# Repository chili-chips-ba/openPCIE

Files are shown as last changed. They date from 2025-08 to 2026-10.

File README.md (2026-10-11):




Computing is about communicating. Some would also say about networking. Digital independence tags along on the wave of _"Recommendations and Roadmap for European Sovereignty in open source HW, SW and RISC-V Technologies (2021)"_, calling for the development of critical open source IP blocks, such as **`PCIE Root Complex (RC)`**. This is the first step in that direction. And, if you are looking for an opensource, soft PCIE EndPoint (EP) core, please check our [other](https://github.com/chili-chips-ba/openCologne-PCIE) repo.

<p align="center" width="100%">
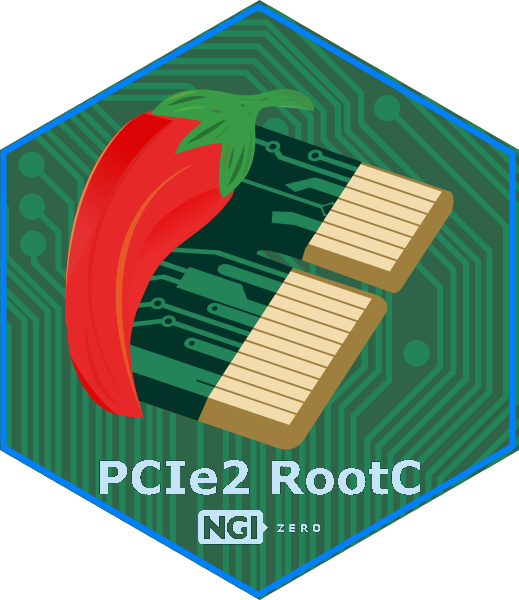
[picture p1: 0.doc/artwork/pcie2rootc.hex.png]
openPCIE Root Complex project logo
  
</p>

This project looks to open Artix7 PCIE Gen2 RC IP blocks for use outside of proprietary tool flows. While still reliant on Xilinx Series7 Hard Macros (HMs), it will surround them with open-source soft logic for PIO accesses — The **`RTL`** and, even more importantly, the layered **`software Driver with Demo App`**. 

All that with **`full HW/SW opensource co-sim`**. Augmented with a rock-solid **`openBackplane`** in the basement of our hardware solution, the geek community will thus get all it takes for building their own, end-to-end _openCompute_ systems.

> The project‘s immediate goal is to empower the makers with ability to drive PCIE-based peripherals from their own soft RISC-V SOCs.

Given that the PCIE End-Point (EP) with DMA is already available in opensource, the opensource PCIE peripherals do exist for Artix7. Except that they are always, without exception, controlled by the proprietary RC on the motherboard side, typically in the form of RaspberryPi ASIC, or x86 PC. This project intends to change that status quo.

Our long-term goal is to set the stage for the development of full opensource PCIE stack, gradually phasing out Xilinx HMs from the solution. That’s a long, ambitious track, esp. when it comes to mixed-signal SerDes and high-quality PLLs. We therefore anticipate a series of follow on projects that would build on the foundations we hereby set.

This first phase is about implementing an open source PCIE Root Complex (RC) for Artix7 FPGA, utilizing Xilinx Series7 PCIE HM and GTP IP blocks, along with their low-jitter PLL.

#### References
- [PCIE Primer](http://www.anita-simulators.org.uk/wyvernsemi/articles/pci_express.pdf) by Simon Southwell ✔

--------------------

# Project Status

#### `PART 1. Mini PCIE Backplane PCB`

Almost all consumer PCIE installations have the RC chip soldered down on the motherboard, typically embodied in the CPU or "North Bridge" ASIC, where PCIE connectors are used solely for the EP cards. Similarly, all FPGA boards on the market are designed for EP applications. As such, they expect clock, reset and a few other signals from the infrastructure. It is only the professional and military-grade electronics that may have both RC and EP functions on add-on cards, with a backplane or mid-plane connecting them (see VPX chassis, or VITA 46.4).

This dev activity is about creating the minimal PCIE infrastructure necessary for using a plethora of ready-made FPGA EP cards as a Root Complex. This infrastructure takes the physical form of a mini backplane that provides the necessary PCIE context similarly to what a typical motherboard would give, but without a soldered-down RC chip that would be conflicting with our own FPGA RC node.

Such approach is less work and less risk than to design our own PCIE motherboard, with a large FPGA on it. But, it is also a task that we did not appreciate from the get-go. In a bit of a surprise, half-way through planning, we've realized that a suitable, ready-made backplane was not available on the market. This initial disappointment then turned into excitement knowing that this new outcome would make the project even more attractive / more valuable for the community... esp. when **[Envox.eu](https://www.envox.eu)** has agreed to step in and help. They will take on the PCIE backplane PCB development activity.

 - [x] ✔ Create requirements document.
 - [x] ✔ Select components. Schematic and PCB layout design.
 - [x] ✔ Review and iterate design to ensure robust operation at 5 GT/s (PCIE Gen2), using openEMS for simulation of high-speed traces.
 - [x] ✔ Manufacture prototype. Debug and bringup, using AMD-proprietary on-chip IBERT IP core to assess Signal Integrity.
 - [x] ✔ Produce second batch that includes all improvements. Distribute it, and release design files with full documentation.

#### `PART 2. Project setup and preparatory activities`
 - [x] ✔ Procure FPGA development boards and PCIE accessories.
 - [x] ✔ Put together a prototype system. Bring it up using proprietary RTL IP, proprietary SW Driver, TestApp and Vivado toolchain.
 
#### `PART 3. Initial HW/SW implementation`
 - [x] ✔ HW development of opensource RTL that mimics the functionality of PCIE RC proprietary solution.
 - [x] ✔ SW development of opensource driver for the PCIE RC HW function. It runs bare-metal on the RISC-V SOC, without Linux - see [SW Architecture](#sw-architecture).
 - [x] ✔ Design SOC based on RISC-V CPU with PCIE RC as its main peripheral.

#### `PART 4. HW/SW co-simulation using full PCIE EP model`

This dev activity is significantly beefed up compared to our original plan, which was to use a much simpler PCIE EP BFM, and non-SOC sim framework. While that would have reduced the time and effort spent on the sim, prompted by NLnet astute questions, we're happy to announce that **[wyvernSemi](https://github.com/wyvernSemi/pcievhost)** is now also onboard!

Their VProc can be used not only to faithfully model the RISC-V CPU and SW interactions with HW, but it also comes with an implementation of the PCIE model. The PCIE model has some EP capabilities with a configurable configuration space, which can be paired in sim with our RC RTL design. Moreover, the existence of both RC and EP models paves the way for future plug-and-play, pick-and-choose opensource sims of the entire PCIE subsystem.

With the full end-to-end simulation thus in place, we hope that the need for hardware debugging, using ChipScope, expensive test equipment and PCIE protocol analyzers would be alleviated.

 - [x] ✔ Extension of the existing PCIE RC model for some additional configurability of the EP capabilities.
 - [x] ✔ Testbench development and build up. Execution and debug of sim testcases.
 - [x] ✔ Documentation of EP model, TB and sim environment, with objectives to make it all simple enough to pickup, adapt and deploy in other projects.
 
#### `PART 5. Integration, testing and iterative design refinements`
 - [x] ✔ One-by-one replace proprietary design elements of the PART 2 prototype system with our opensource versions (except for Vivado and TestApp). Test it along the way, fixing problems as they occur.
 
#### `PART 6. Prepare Demo and port it to openXC7`

 - [x] ✔ Develop our opensource PIO TestApp software and representative Demo.
 - [x] ✔ Build design with _openXC7_, reporting issues and working with developers to fix them, possibly also trying _ScalePNR_ flow.

Given that PCIE is an advanced, high-speed design, in the light of _nextpnr-xilinx_ and openXC7 shortcomings when it comes to timing constraints and timing closure, we expect to run into showstoppers, and have therefore planned to experiment with WIP _ScalePNR_. In turned out that, with some corrections, the _nextpnr-xilinx_ was good enough -- The bitstream built with it brings the link up at **Gen2** speeds on hardware, the same as Vivado does. Getting there took six fixes - one latent bug in our RTL and five workarounds for openXC7 defects - all documented in [4.build/hw_build.openXC7](4.build/hw_build.openXC7/README.md), along with the issues we filed against openXC7.

The design has also been ported to, and tested with [_openXC7_ 1.0.0 edition](https://lnkd.in/p/gsDArjSt), which was a major step forward and essentially what "ScalePNR" idea eventually had evolved into. It brought to the forefront Yosys0.69 with integrated **Slang, nextpnr-himbaechel** (instead of _nextpnr-xilinx_) and _fpga-as_. With that, the earlier SV2V standalone preparatory step for our SystemVerilog design sources proved to be unnecessary, which greatly simplifies the build.

--------------------

# HW Architecture

The project relies on a modular hardware ecosystem that combines our custom-designed openPCIE Backplane with SQRL Acorn CLE-215+ FPGA modules and various PCIE adapters to create a flexible testing platform.

<p align="center">
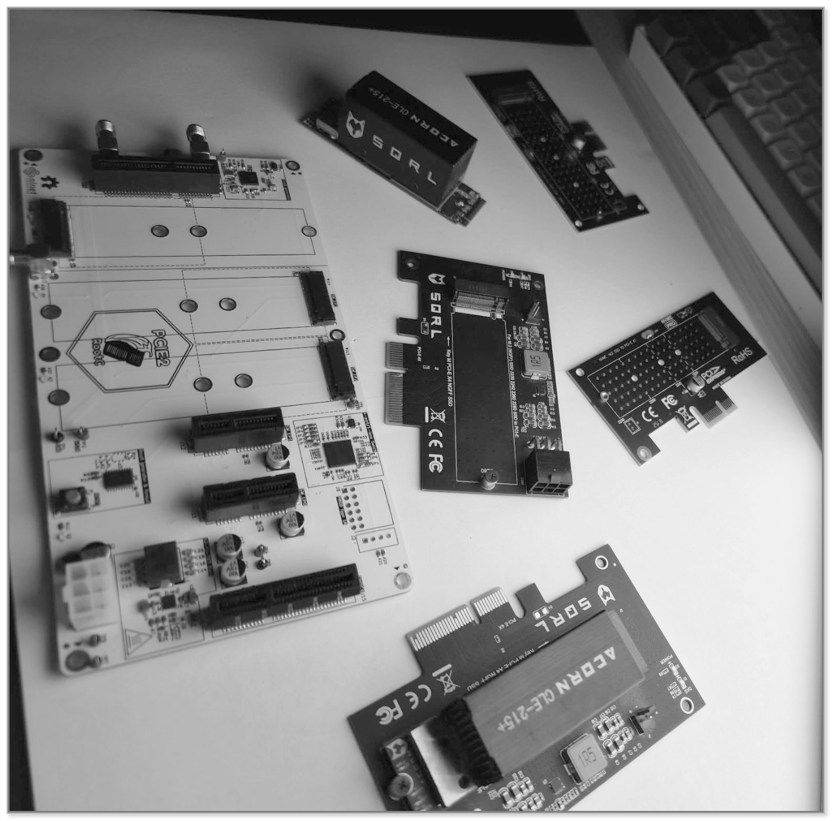
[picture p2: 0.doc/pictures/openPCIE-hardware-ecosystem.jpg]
openPCIE hardware ecosystem
 
</p>

#### References:
- [Basic PCIE EP for LiteFury](https://github.com/hdlguy/litefury_pcie)
- [Regymm PCIE](https://github.com/regymm/pcie_7x)
- [LiteX PCIE EP](https://github.com/enjoy-digital/litepcie)
- [PCIE EP DMA - Wupper](https://gitlab.nikhef.nl/franss/wupper)
- [Xilinx UG477 - 7Series Integrated Block PCIe](https://docs.xilinx.com/v/u/en-US/ug477_7Series_IntBlock_PCIe)
- [Xilinx DS821 - 7series_PCIE Datasheet](https://docs.xilinx.com/v/u/en-US/ds821_7series_pcie)
- [Xapp1052 - BusMaster DMA for EP](https://docs.xilinx.com/v/u/en-US/xapp1052)

## FPGA hardware platform

#### References:
- [Acorn-CLE215+ QuickStart](https://github.com/SMB784/SQRL_quickstart)
- [NiteFury](https://github.com/RHSResearchLLC/NiteFury-and-LiteFury/tree/master)
- [fpgas.online-test-designs](https://github.com/fpgas-online/fpgas.online-test-designs/tree/main/designs/pcie-enumeration) PCIE ENUMERATION by RPI, for Acorn-CLE215+ EP
  
The hardware platform for this project is the **SQRL Acorn CLE-215+**, a versatile FPGA development board. Although originally designed as a crypto-accelerator, its powerful Artix-7 FPGA and modular design make it an excellent choice for general-purpose PCIE development.

The system consists of two main components:

*  **M.2 FPGA Module (Acorn CLE-215+):** This is the core of the system, a compact board in an M.2 form factor. It houses the **Xilinx Artix-7 XC7A200T FPGA** and is designed to be plugged into a standard M.2 M-key slot.

<table align="center" style="border: none; border-collapse: collapse;">
  <tr style="border: none;">
    <td align="center" style="border: none;">
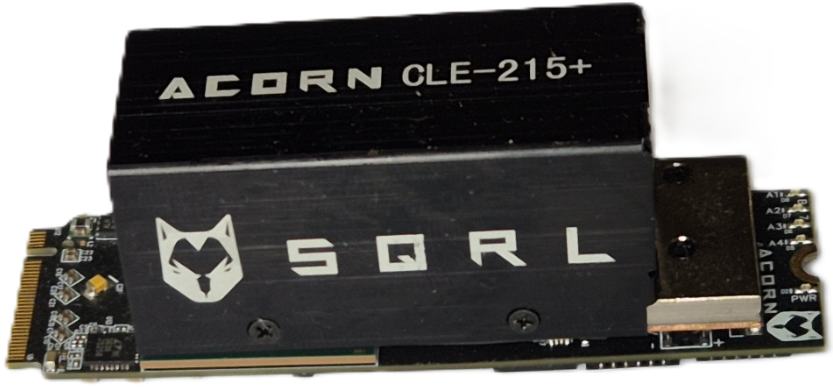
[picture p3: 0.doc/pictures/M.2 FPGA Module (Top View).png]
M.2 FPGA module, top view
      
    </td>
    <td align="center" style="border: none;">
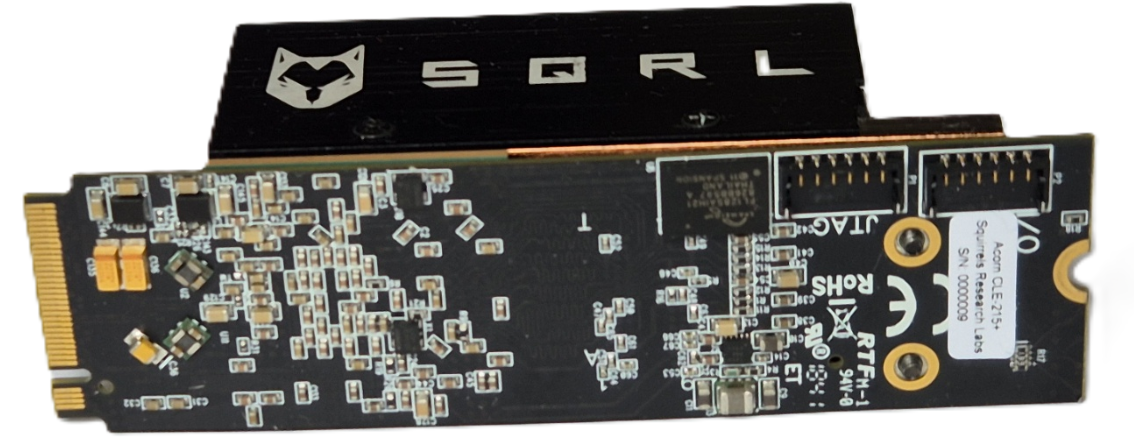
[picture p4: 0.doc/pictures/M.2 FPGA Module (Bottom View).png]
M.2 FPGA module, bottom view
      
    </td>
  </tr>
  <tr style="border: none;">
    <td align="center" style="border: none;"><b>M.2 FPGA Module (Top View)</b></td>
    <td align="center" style="border: none;"><b>M.2 FPGA Module (Bottom View)</b></td>
  </tr>
</table>

*  **PCIE Adapter Board (Acorn Baseboard Mini):** A carrier board that holds the M.2 FPGA module. Its primary function is to adapt the M.2 interface to a standard **PCIE x4 edge connector**, allowing the entire assembly to be installed and tested in a regular PC motherboard slot.

<table align="center" style="border: none; border-collapse: collapse;">
  <tr style="border: none;">
    <td align="center" style="border: none;">
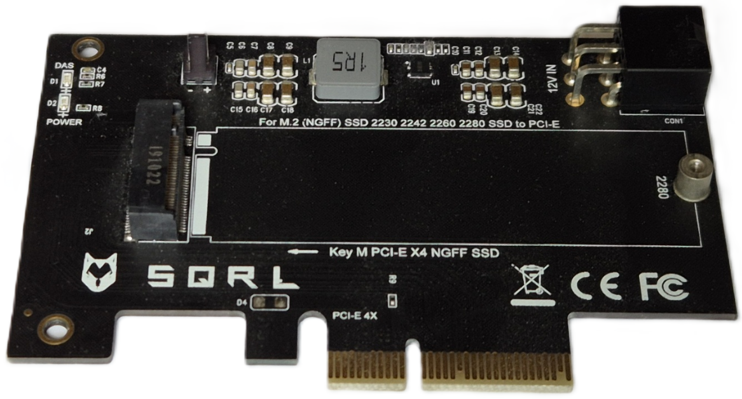
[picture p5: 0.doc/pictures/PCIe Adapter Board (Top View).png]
PCIE adapter board, top view
      
    </td>
    <td align="center" style="border: none;">
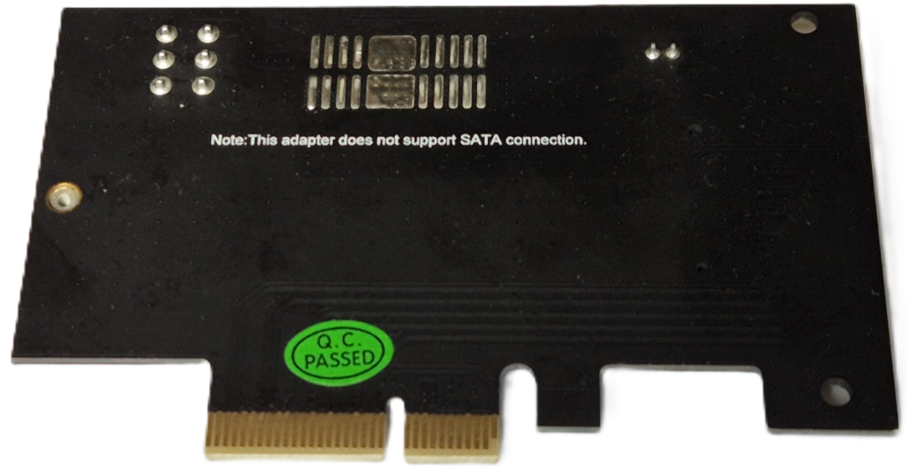
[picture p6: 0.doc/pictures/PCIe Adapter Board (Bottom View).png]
PCIE adapter board, bottom view
      
    </td>
  </tr>
  <tr style="border: none;">
    <td align="center" style="border: none;"><b>PCIE Adapter Board (Top View)</b></td>
    <td align="center" style="border: none;"><b>PCIE Adapter Board (Bottom View)</b></td>
  </tr>
</table>

<p align="center">
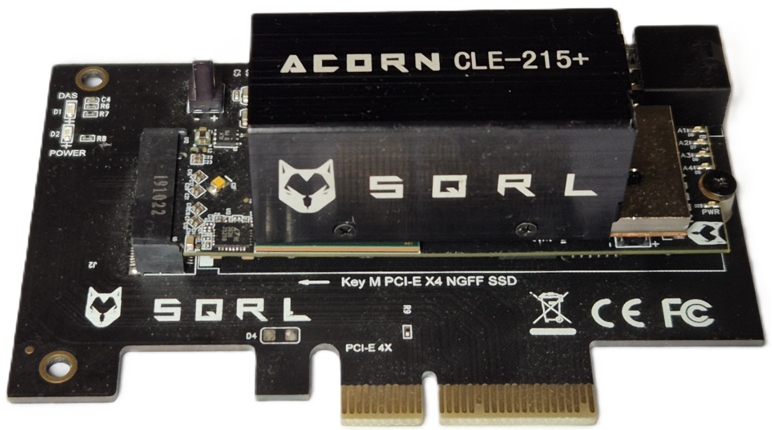
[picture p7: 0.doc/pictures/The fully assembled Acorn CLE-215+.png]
Fully assembled Acorn CLE-215+
  
  <br>
  <b>The fully assembled Acorn CLE-215+ development board, ready for use in a PCIE slot.</b>
</p>

It is important to note that the Acorn CLE-215+ is functionally identical to the more widely known NiteFury board, with the primary difference being the amount of onboard memory. The Acorn model features 1 GB of DDR3 RAM, while the standard NiteFury has 512 MB. Therefore, the [NiteFury schematic](https://github.com/chili-chips-ba/openPCIE/blob/main/0.doc/Reference-SCH/Schematic.FPGA-NiteFury.pdf) serves as a direct and accurate reference for the board's hardware layout.

The central component of the SQRL Acorn CLE-215+ system is the **Xilinx Artix-7 XC7A200T-FBG484** chip. This FPGA is crucial for implementing the PCIE Root Complex - and, on the other card, the Endpoint - possessing a range of features that make it highly suitable for this purpose.

The key specifications are summarized below:

<div align="center">
<table>
<thead>
<tr>
<th>Specification</th>
<th>Value</th>
</tr>
</thead>
<tbody>
<tr>
<td>Family</td>
<td>Xilinx Artix-7</td>
</tr>
<tr>
<td>Speed Grade</td>
<td>-3</td>
</tr>
<tr>
<td>Logic Cells (LUT4-Equivalent)¹</td>
<td>215,360</td>
</tr>
<tr>
<td>LUT6</td>
<td>134,600</td>
</tr>
<tr>
<td>Flip-Flops</td>
<td>269,200</td>
</tr>
<tr>
<td>Block RAM</td>
<td>13 Mbit</td>
</tr>
<tr>
<td>DSP Slices</td>
<td>740</td>
</tr>
<tr>
<td>GTP Transceivers</td>
<td>4 (up to 6.6 Gbit/s)</td>
</tr>
<tr>
<td>DDR3 SDRAM (Board)</td>
<td>1 GB, 16-bit</td>
</tr>
<tr>
<td>QSPI Flash (Board)</td>
<td>32 MB</td>
</tr>
<tr>
<td>User LEDs</td>
<td>4</td>
</tr>
<tr>
<td>General Purpose IOs</td>
<td>4</td>
</tr>
<tr>
<td>LVDS Pairs</td>
<td>4</td>
</tr>
</tbody>
</table>
<p><small>¹ The 'Logic Cells' count is a Xilinx metric derived from the physical 6-input LUTs to provide an estimated equivalent in simpler 4-input LUTs for comparison purposes. The number of physical LUTs and other resources are the exact counts for the XC7A200T chip.</small></p>
</div>

### FPGA Board Setup

Properly programming and operating the Artix-7 FPGA on the SQRL board required two key hardware modifications.

#### 1. Custom JTAG Cable

The JTAG connector on the Acorn CLE-215+ is non-standard and not directly compatible with the standard 14-pin connector on the Xilinx Platform Cable. A custom adapter cable is therefore required.

<table align="center" style="border: none; border-collapse: collapse; width="60%">
  <tr style="border: none;">
    <td align="center" style="border: none;" width="60%">
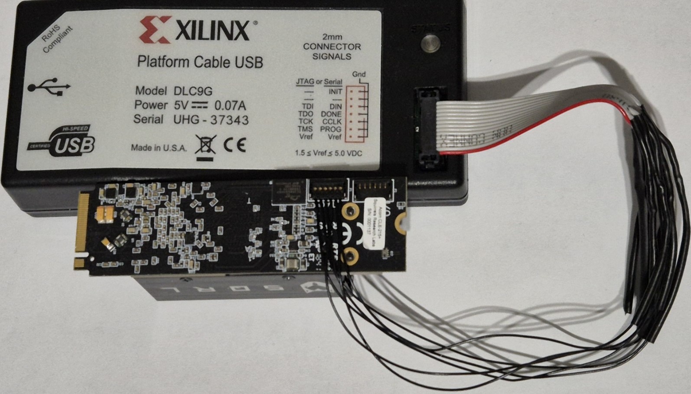
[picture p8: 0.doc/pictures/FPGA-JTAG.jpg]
FPGA JTAG connection
      
    </td>
    <td align="center" style="border: none;" width="30%">
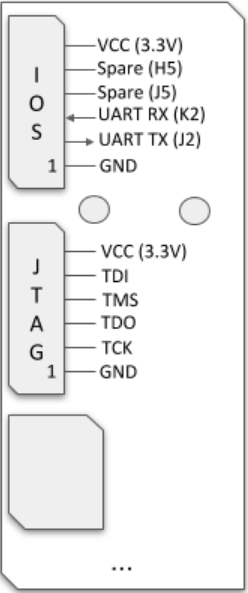
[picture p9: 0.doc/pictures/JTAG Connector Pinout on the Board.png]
JTAG connector pinout on the board
      
    </td>
  </tr>
  <tr style="border: none;">
    <td align="center" style="border: none;"><b>Custom JTAG Cable connecting the Xilinx Programmer to the board</b></td>
    <td align="center" style="border: none;"><b>JTAG Connector Pinout on the Board</b></td>
  </tr>
</table>

The connector on the board is a **Molex Pico-Lock 1.50mm pitch male header**. This is not a standard 2.54mm or 2.00mm header, so standard DuPont-style cables will not fit.

To simplify making the cable, we highly recommend purchasing a pre-assembled cable with the correct female connector.

*   **Recommended Part:** **[Molex 0369200603 on Digi-Key](https://www.digikey.com/en/products/detail/molex/0369200603/10233020)**

This cable has the correct female connector on both ends. The easiest method is to **cut the cable in half**, which gives you two connector cables with open ends. You can then splice one of these cable ends onto the wires of your Xilinx programmer cable, matching the signals according to the following wiring diagram.

<p align="center">
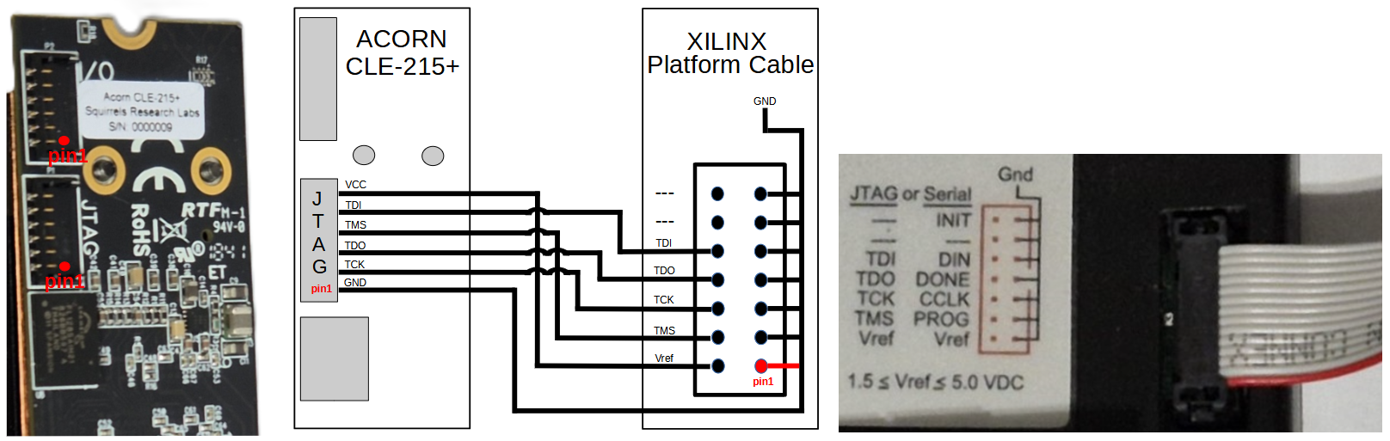
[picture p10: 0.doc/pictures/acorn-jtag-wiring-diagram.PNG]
Acorn JTAG wiring diagram
  
  <br><em>JTAG Connection Guide: Physical Pinout and Wiring Diagram.</em>
</p>

#### 2. External 12V Power Supply

The board cannot be programmed or operated solely from the PCIE/M.2 slot power. It requires an external 12V supply to function correctly, especially when complex designs and high-speed transceivers are active. Power is provided via a standard 6-pin PCIE power connector from an ATX power supply.

<p align="center">
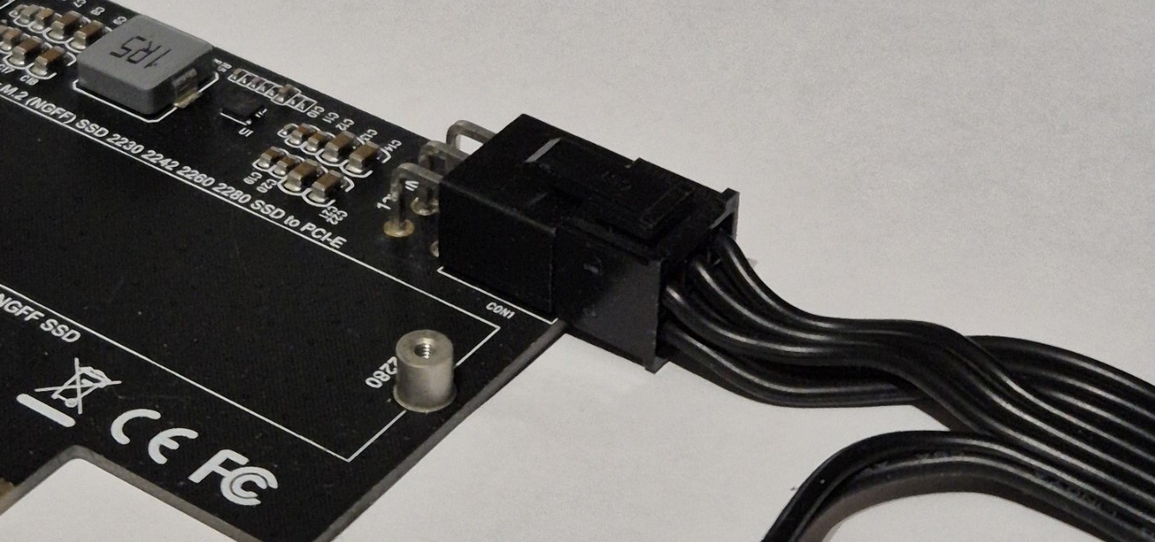
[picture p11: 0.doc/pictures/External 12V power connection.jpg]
External 12 V power connection
  
  <br><em>External 12V power connection.</em>
</p>

#### 3. Final Assembly

The complete system, including the custom cabling, is mounted in a test PC chassis for verification.

<p align="center">
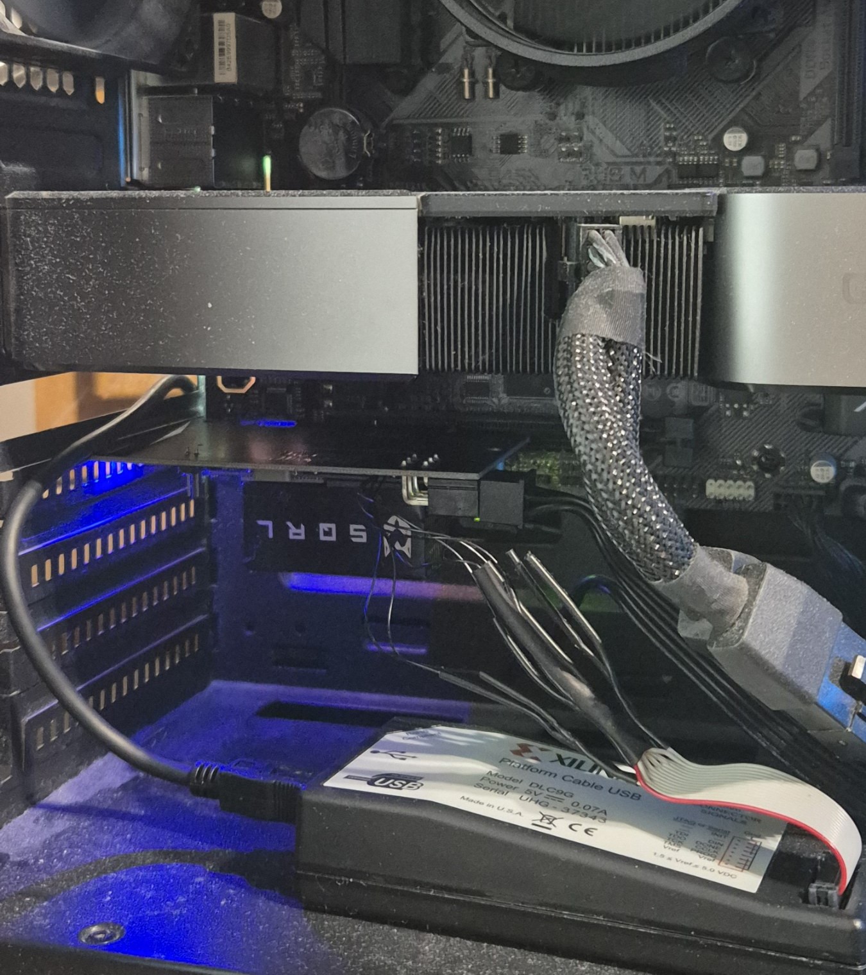
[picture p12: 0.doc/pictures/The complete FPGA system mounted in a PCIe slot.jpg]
Complete FPGA system mounted in a PCIE slot
  
  <br><em>The complete FPGA system mounted in a PCIE slot.</em>
</p>

#### 4. Connection Verification

After the hardware was prepared, the connection was verified using the **Vivado Hardware Manager**. As shown below, the tool successfully detected the JTAG programmer and identified the `xc7a200t_0` FPGA chip. This confirms that the physical connections are correct and the board is ready for programming.

<p align="center">
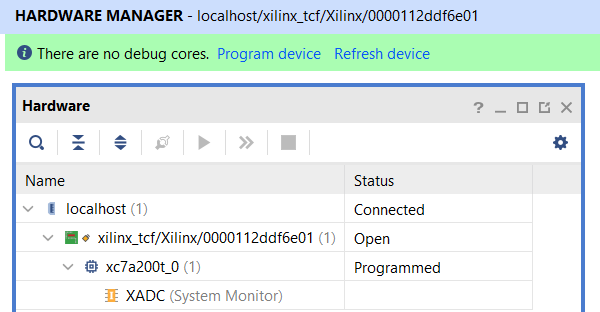
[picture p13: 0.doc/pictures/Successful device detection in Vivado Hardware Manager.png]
Successful device detection in Vivado Hardware Manager
  
  <br><em>Successful device detection in Vivado Hardware Manager.</em>
</p>

--------------------
### openBackplane PCB

<p align="center" width="100%">
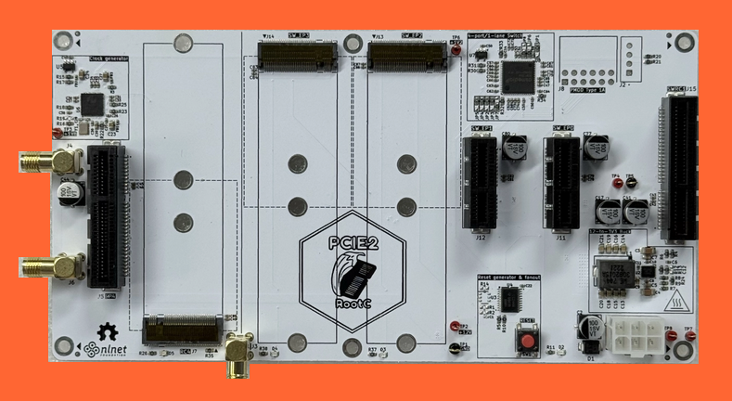
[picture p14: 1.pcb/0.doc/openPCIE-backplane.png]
openPCIE backplane
    
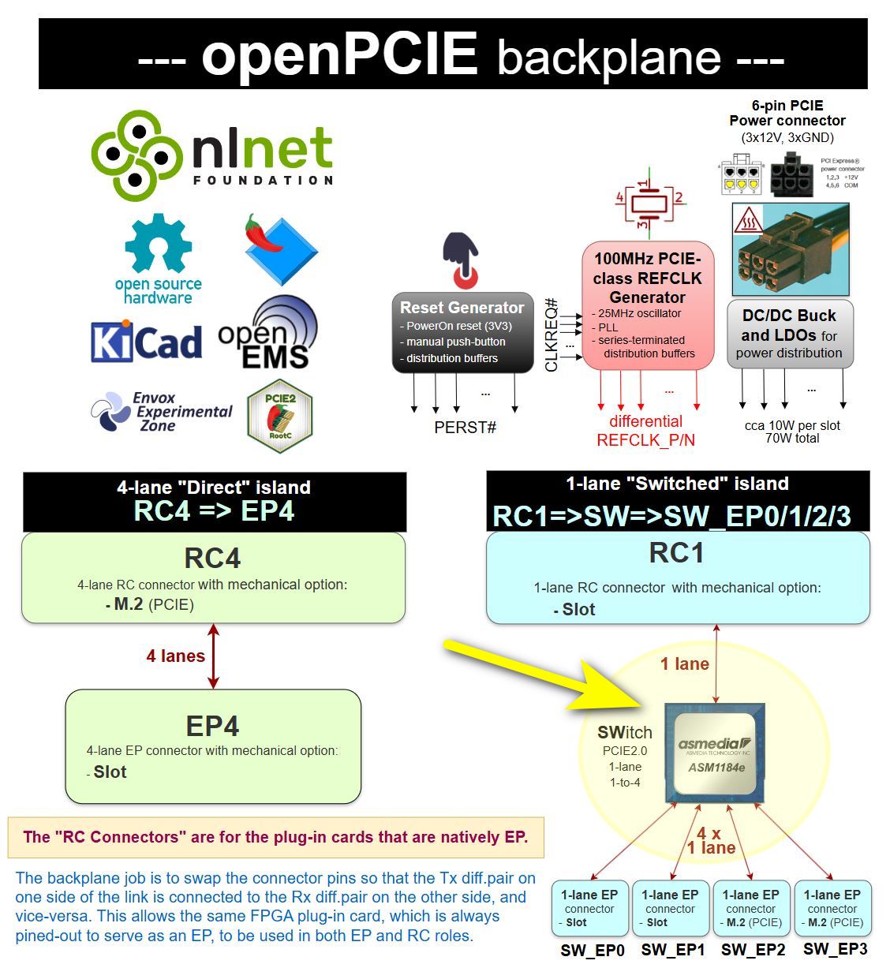
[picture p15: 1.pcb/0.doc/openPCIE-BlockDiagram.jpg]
openPCIE backplane block diagram
    
</p>

Please, refer to [1.pcb](1.pcb) for additional detail.

--------------------

# TB/Sim Architecture

## Simulation Test Bench

The [openPCIE test bench](5.sim/README.md) aims to have a flexible approach to simulation which allows a common test environment to be used whilst selecting between alternative CPU components, one of which uses the [_VProc_ virtual processor](https://github.com/wyvernSemi/vproc) co-simulation element. This allows simulations to be fully HDL, with the picorv32 RISC-V RTL core that goes into the bitstream, or to co-simulate software using the virtual processor, with a significant speed up in simulation times. The test bench has the following features:

* A [_VProc_](https://github.com/wyvernSemi/vproc) virtual processor based [`soc_cpu.VPROC.picorv32`](5.sim/models/README.md#soc_cpuvprocpicorv32) component
  * [Selectable](5.sim/README.md#the-three-cpu-options) between this or the RTL picorv32, with `make CPU=rtl|vproc|iss`
  * Can run natively compiled test code
  * Can run the application compiled natively with the [auto-generated co-sim HAL](4.build/README.md#csr-hal-compilation)
  * Can run RISC-V compiled code using the [rv32 RISC-V ISS model](5.sim/models/rv32/README.md)
  * All three have been [built and measured](5.sim/README.md#what-they-cost); each reaches the same result over the same PCIE link
* The [_pcieVHost VIP_](https://github.com/wyvernSemi/pcievhost) is used to drive the logic's PCIE link
* Uses a C [sparse memory model](https://github.com/wyvernSemi/mem_model)
  * An [HDL component](5.sim/models/cosim/README.md) instantiated in logic gives logic access to this memory
  * An API is provided to _VProc_ running code for direct access from the _pcieVHost_ software, which implements this sparse memory C model.

The figure below shows an overview block diagram of the test bench HDL.

<p align="center">
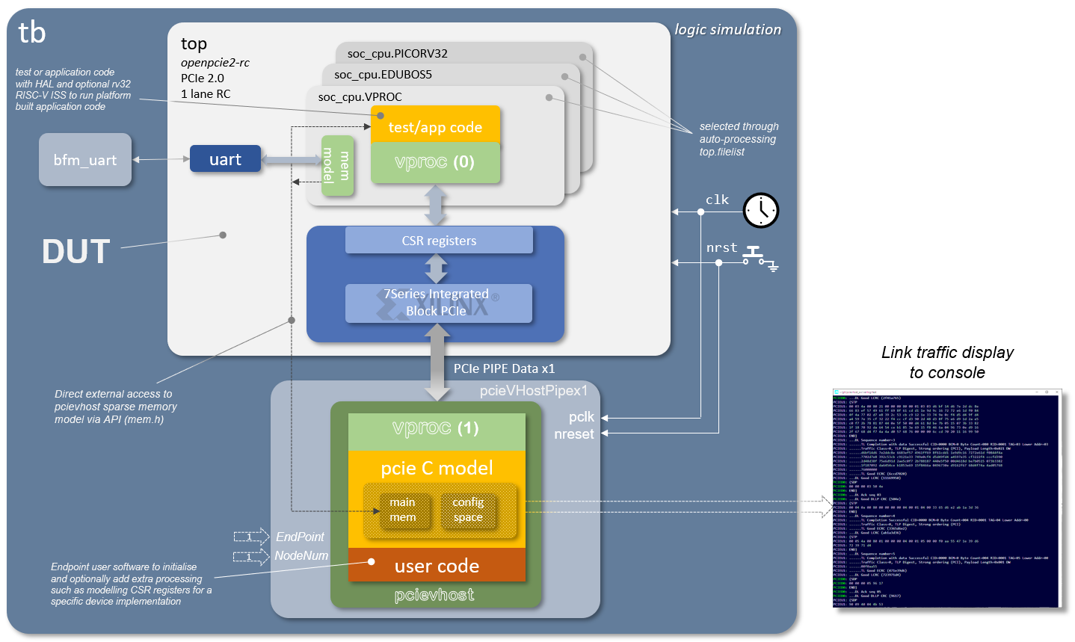
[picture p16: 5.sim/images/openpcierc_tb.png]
openPCIE Root Complex test bench structure

</p>

More details on the architecture and usage of the openPCIE test bench can be found in the [README.md](5.sim/README.md) in the `5.sim` directory.

The co-simulation can also be followed at TLP level in the [WaveCrux](https://wavecrux.app) waveform viewer, with an [open-source PCIE TLP decoder plugin](5.sim/tools/wavecrux-pcie-tlp/README.md) and a ready-made session -- here the firmware sizing BAR0 by readback and placing it at `0x80000000` ([more](5.sim/README.md#viewing-the-tlps-in-wavecrux)):

<p align="center">
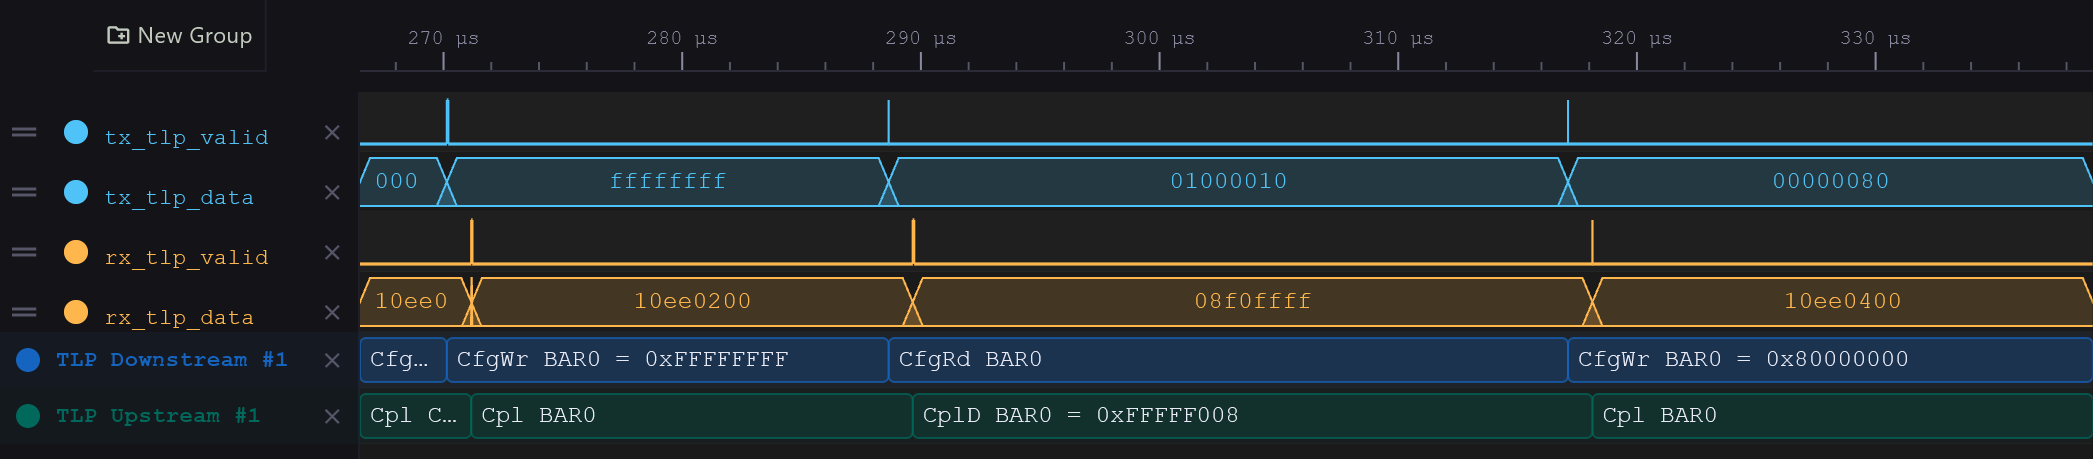
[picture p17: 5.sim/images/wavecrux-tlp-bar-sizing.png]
WaveCrux TLP view: firmware sizing BAR0

</p>

One level down, Ferrite's [PCIe PIPE and Data Link Layer decoders](https://github.com/Ferrite-Engineering/wavecrux-decoders) show the same link on the wire: link training, flow-control credits, and every TLP with its sequence number and Ack ([more](5.sim/README.md#viewing-the-pipe-in-wavecrux)). With all three layers in one view, you can also see how long a TLP spends inside the hard macro: about 0.4 µs each way ([more](5.sim/README.md#how-long-a-tlp-spends-in-the-hard-macro)).

## Co-simulation HAL

The openPCIE control and status register hardware abstraction layer (HAL) software is [auto-generated](4.build/README.md#csr-hal-compilation), as is the CSR RTL, using [`peakrdl`](https://peakrdl-cheader.readthedocs.io/en/latest/). A single SystemRDL specification, [`4.build/csr_build/csr.rdl`](4.build/csr_build/csr.rdl), describes the TLP transmit/receive window the RISC-V firmware drives, and everything else is derived from it: the register block RTL (`csr.sv`, `csr_pkg.sv`), which [`soc_csr.sv`](2.rtl/0.common.opensource/src/soc_csr.sv) bridges to the picorv32 memory bus, and the software header. For co-simulation purposes an additional layer is auto-generated from the same SystemRDL specification using [`systemrdl-compiler`](https://systemrdl-compiler.readthedocs.io/en/stable/) that accompanies the `peakrdl` tools. This produces two header files that define a common API to the application layer for both the RISC-V platform and the *VProc* based co-simulation verification environment. The details of the HAL generation can be found in the [README.md](./4.build/README.md#csr-hal-compilation) in the `4.build/` directory.

The hand-written register block that came first is kept alongside it, behind `` `ifdef SOC_CSR_LEGACY `` in `riscv_pcie_soc.sv`, and every build flow can pick either one. The two describe the same map down to the byte offset.

More details of the test bench, the _pcievhost_ component and its usage can be found in the [5.sim/README.md](5.sim/README.md) file.
  
#### References
- [pcieVHost](https://github.com/wyvernSemi/pcievhost/blob/master/doc/pcieVHost.pdf)
- [WaveCrux](https://wavecrux.app) waveform viewer, [decoder plugin interface](https://github.com/Ferrite-Engineering/wavecrux/blob/main/include/wavecrux_decoder.h)
- [wavecrux-decoders](https://github.com/Ferrite-Engineering/wavecrux-decoders): Ferrite's open-source PCIE PIPE and Data Link Layer decoders for WaveCrux

--------------------

# SW Architecture

The software stack is designed to run **bare-metal** on the soft RISC-V SoC embedded within the FPGA. In a standard PC, the Operating System (Linux/Windows) manages PCIE enumeration automatically in the background, hiding the complexity from the developer. In this project, our **open-source driver** takes full control, manually performing every step of the enumeration process to act as the PCIE Host.

The architecture follows a layered approach:

1.  **Application Layer (The "User" Logic)**: 
    - The final stage of the program that executes the high-level task.
    - It performs **Memory Write** operations to send a data payload to the Endpoint and uses **Memory Read** to verify the integrity of the data path.

2.  **PCIE Driver (Enumeration & Setup)**:
    - Responsible for the **initialization sequence** required to perform enumeration and establish a functional connection (link).
    - It manually performs device discovery, sizes the BARs by readback, assigns aligned memory addresses, checks the completion status of every request, and configures the **Command Register** to enable the device for communication.
      
3.  **HAL (Hardware Abstraction Layer)**:
    - Low-level helper functions that interact with the hardware by reading and writing data to **specific memory addresses**.

> **Note:** This structure allows developers to treat PCIE devices just like any other local peripheral, abstracting away the complexities of the physical link.

--------------------

# Implementation Workflow

The openPCIE implementation workflow is organized into several stages, covering the complete process from setting up the development environment to verifying the design on physical hardware.

## Prerequisites

Before building the project, install and configure the required development tools. These include an FPGA toolchain such as **AMD Vivado** or **openXC7**, a bare-metal **RISC-V cross-compilation toolchain**, Python, and the project-specific dependencies listed in the corresponding directories.

## Simulation (Hardware/Software Co-Simulation)

Before deploying the design to physical hardware, run the available simulation environment to verify the interaction between the PCIE hardware design and the software components.

The co-simulation flow is used to test essential operations such as device initialization, register access, PCIE link behavior, and data exchange between the Root Complex (RC) and Endpoint (EP). This stage helps identify hardware and software integration issues before synthesis and hardware deployment.

## Software Build

Compile the bare-metal RISC-V driver and test application using the configured cross-compilation toolchain.

The software is responsible for initializing the required hardware components, configuring the PCIE communication flow, and transferring test payloads between the RC and EP. The generated executable can be used during simulation or deployed together with the FPGA design for hardware verification.

## Hardware Synthesis and Bitstream Generation

The FPGA design can be synthesized and implemented using either the commercial **AMD Vivado** toolchain or the open-source **openXC7** toolchain. Depending on the selected flow, the process includes design elaboration, synthesis, placement, routing, timing analysis, and final bitstream generation.

The resulting `.bit` file contains the complete hardware configuration for the selected FPGA board. The appropriate board-specific constraints, build configuration, and target design must be selected depending on whether the board operates as the Root Complex (RC) or Endpoint (EP).

Detailed build instructions for both the Vivado and openXC7 flows are provided in the corresponding project directories.

## Flashing and Deployment

Program the RC and EP FPGA boards with their corresponding bitstreams. After both designs have been loaded, start the software application and allow the boards to initialize the PCIE connection.

The deployed system can then be verified by checking the PCIE link-status indicators and comparing the transmitted payload with the data displayed or received on the Endpoint.

Detailed commands, configuration options, supported boards, and stage-specific instructions are provided in the corresponding project directories.

--------------------

# Debug, Bringup, Testing

### Hardware Infrastructure
- **PCB:** **openPCIE Backplane** (see [1.pcb](1.pcb/))  which provides slots for the RC, EP, and the Switch.
- **FPGA Boards:** Two **SQRL Acorn CLE-215+** (Artix-7) boards.
- **JTAG Programmers:** Two **Xilinx Platform Cable USB** units are used, each equipped with a **custom adapter cable**.
    
### The "Dual-PC" Debugging Approach 
We used a **two-PC** setup to streamline development:
-  **PC 1:** Connected to the **Root Complex (RC)** FPGA via JTAG.
-  **PC 2:** Connected to the **EndPoint (EP)** FPGA via JTAG.
   
**Why this setup?**
- **Speed and Efficiency:** This setup avoids the repetitive task of manually swapping the JTAG cable between boards and eliminates the time-consuming process of flashing onboard memory for every test iteration.
- **Simultaneous Debugging:** This allows us to run two instances of **Vivado Hardware Manager** (ILA - Integrated Logic Analyzer) at the same time. We can trigger on the RC and EP simultaneously to view the transaction from both sides of the link.

### Testing Procedure

To bring up the system and verify the PCIE link, follow these steps:

*   **Hardware Assembly:** Insert the FPGA cards into their designated slots on the **openPCIE Backplane** (RC and EP) and connect the external **12V power supply**.
*   **Bitstream Programming:** Program both FPGAs using Vivado Hardware Manager. **PC 1** is used to program the Root Complex, while **PC 2** programs the EndPoint.
*   **Manual Reset:** Once both devices are programmed, press the **manual reset button** on the backplane.
*   **Enumeration:** Upon releasing the reset button, the Root Complex initiates the **enumeration process** and establishes the link with the EndPoint.
*   **Re-Initialization:** Every subsequent press of the reset button triggers a full re-initialization of the PCIE connection, allowing for repeated testing and debugging without the need to re-program the FPGAs.

### Objective
The goal of this test is to verify that the Root Complex can successfully enumerate the link and perform both **Memory Write** and **Memory Read** transactions.
1. **Write:** The RC sends a data payload to the EP.
2. **Transfer:** The EP receives the TLP and writes it into its internal Block RAM (BRAM).
3. **Read:** The RC requests to read the data back from the EP memory.

---

# Functional Verification: 

### Verification Environment

Before diving into the results, here is the complete hardware validation setup used for the Direct (Point-to-Point) connection scenario. It features the **openPCIE Backplane** powered by an external 12V supply, populated with two **Acorn CLE-215+** FPGA modules (one configured as RC, the other as EP).

Dual **Xilinx Platform Cable USB** units are connected via custom adapters to allow simultaneous debugging and bitstream loading from two separate host workstations.

<p align="center">
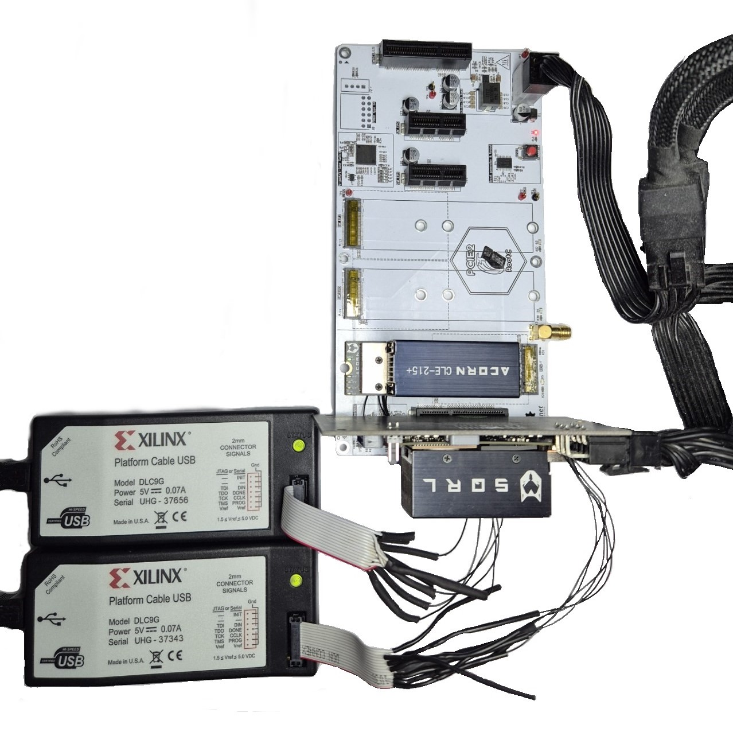
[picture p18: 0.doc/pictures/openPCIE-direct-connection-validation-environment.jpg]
Validation environment for the direct connection
  
  <br>
  <em>The complete hardware validation environment for the Direct connection test.</em>
</p>

### Verification Methods

**1. Visual Verification (LEDs)**
Visual feedback is provided via the **4 user LEDs** on both FPGA boards:
- **RC Board:** The LEDs indicate the **Link Status**, confirming that the physical connection is established and the devices are ready to communicate.
- **EP Board:** The LEDs display the data received by the EP.

**2. Internal Signal Monitoring (ILA)**
Using the Vivado Integrated Logic Analyzer (ILA) on both PCs enables detailed monitoring of internal signals to see exactly what data was sent and received, its precise timing, and the low-level transaction details.

### Verification Results

The implementation was verified on physical hardware by checking both PCIE link establishment and successful payload transfer between the Root Complex (RC) and Endpoint (EP).

On the RC board, LED **A3** indicates the PCIE link status. When this LED is illuminated, the PCIE link has been successfully established. As shown in the verification setup, LED A3 is active, confirming that the link between the RC and EP is up.

On the EP board, the LEDs display the received data payload. The RC transmitted the decimal value **6**, represented in binary as **`0110`**. The LED pattern on the EP matches this value, confirming that the payload was transferred and received correctly.

These results confirm that PCIE link initialization and RC-to-EP data transfer operate successfully on physical hardware.

<table align="center" style="border: none; border-collapse: collapse;">
  <tr style="border: none;">
    <td align="center" style="border: none;">
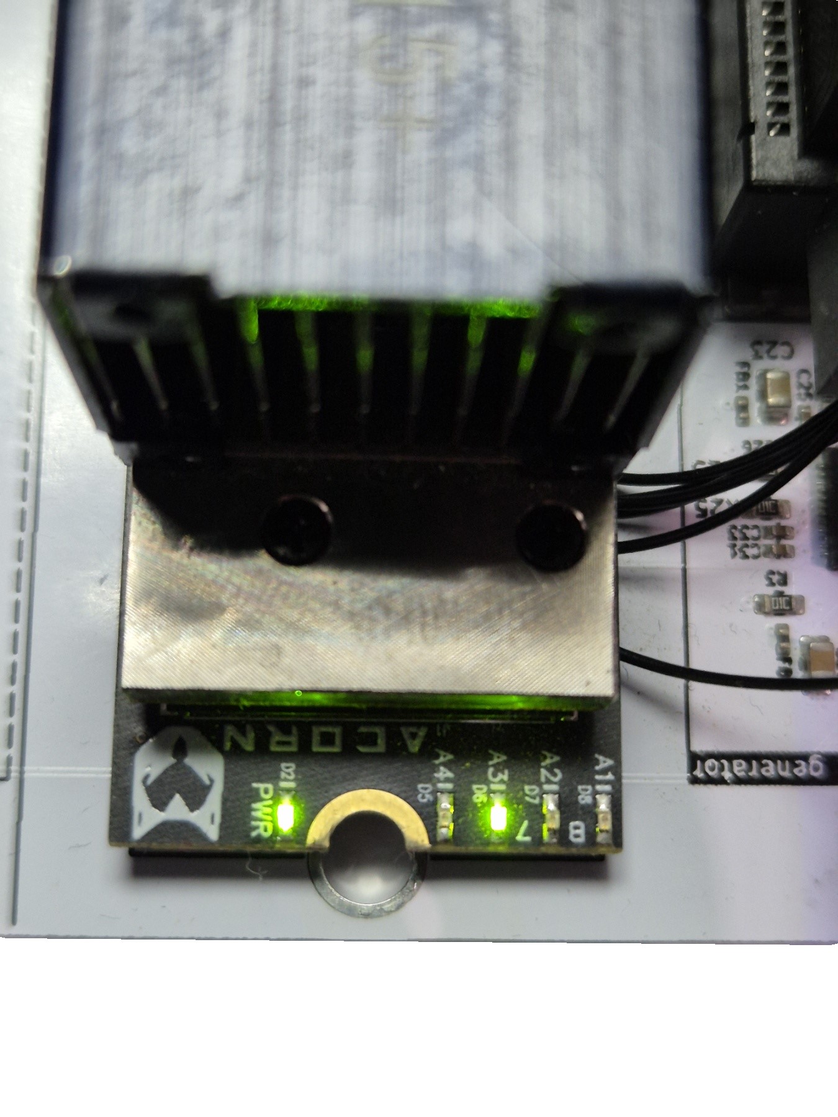
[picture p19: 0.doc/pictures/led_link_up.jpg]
LEDs showing link up
       
    </td>
    <td align="center" style="border: none;">
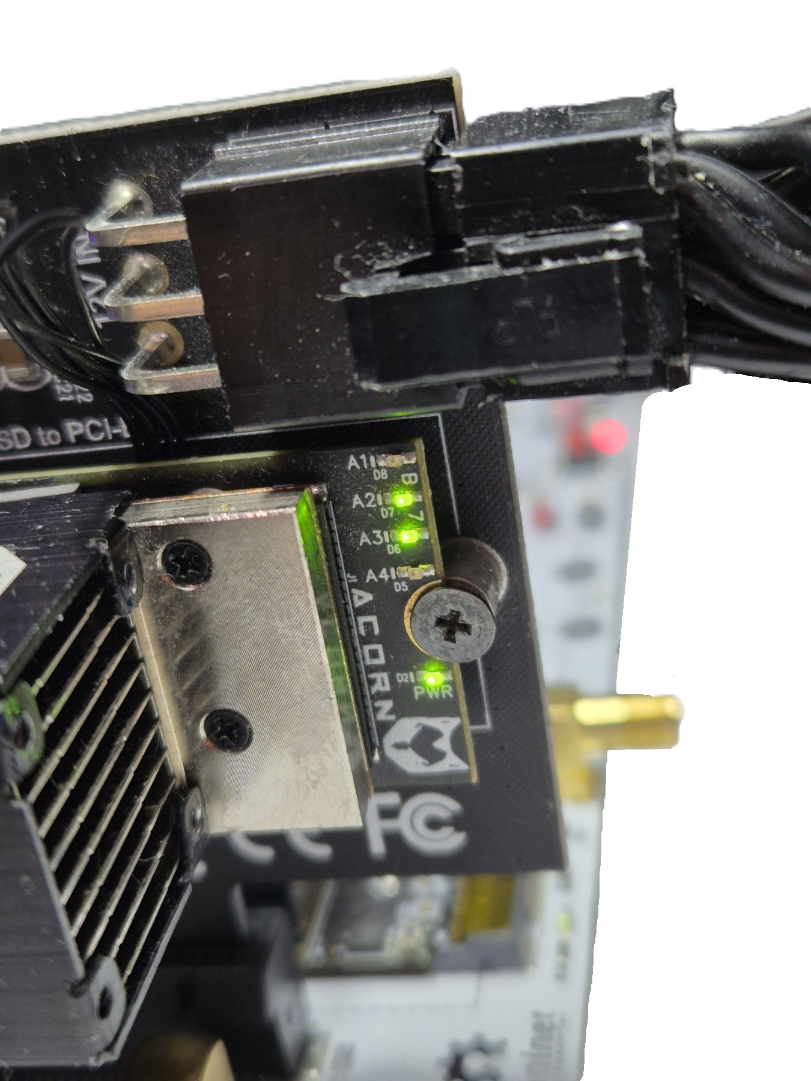
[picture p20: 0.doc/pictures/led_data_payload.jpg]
LEDs showing the data payload
       
    </td>
  </tr>
  <tr style="border: none;">
    <td align="center" style="border: none;"><b>RC-LED-Link-Up</b></td>
    <td align="center" style="border: none;"><b>EP-LED-Data-Payload</b></td>
  </tr>
</table>

#### References
- [PCIE Utils](https://mj.ucw.cz/sw/pciutils)
- [Debug PCIE issues using 'lspci' and 'setpci'](https://adaptivesupport.amd.com/s/article/1148199?language=en_US)
- Using [busybox (devmem)](0.doc/using-busybox-devmem-for-reg-access.txt) for register access 

--------------------

# PCIE Protocol Analyzer

#### References
- [PCIE Sniffing](https://ctf.re/pcie/experiment/linux/keysight/protocol-analyzer/2024/03/26/pcie-experiment-1)
- [Stark 75T Card](https://www.ebay.com/itm/396313189094?var=664969332633)
- [ngscopeclient](http://www.ngscopeclient.org/protocol-analysis)
- [PCI Leech](https://github.com/ufrisk/pcileech)
- [PCI Leech/ZDMA](https://github.com/ufrisk/pcileech-fpga/tree/master/ZDMA)
- [LiteX PCIE Screamer](https://github.com/enjoy-digital/pcie_screamer)
- [LiteX PCIE Analyzer](https://github.com/enjoy-digital/pcie_analyzer)
- [Wireshark PCIe Dissector](https://github.com/antmicro/wireshark-pcie-dissector)
- [PCIe Tool Hunt](https://scolton.blogspot.com/2023/05/pcie-deep-dive-part-1-tool-hunt.html)
- [PCIe network simulator](https://github.com/antmicro/warp-pipe)
- [An interesting PCIE tidbit: Peer-to-Peer communication](https://xilinx.github.io/XRT/2025.1/html/p2p.html). Also see [this](https://xillybus.com/tutorials/pci-express-tlp-pcie-primer-tutorial-guide-1)
- [NetTLP - An invasive method for intercepting PCIE TLPs](https://haeena.dev/nettlp)
- [PCIe on STM32MP257 with ngscopeclient](https://www.youtube.com/watch?v=qxdK3mjHNBM)
- [opensource PCIE Controller](https://www.mdpi.com/2076-3417/16/7/3409)

--------------------

### Academic Outreach
openPCIE has served as the basis for a number of Master's theses at the Faculty of Electrical Engineering, University of Sarajevo (ETF Sarajevo). Among them are the theses of Anes Vrce and [Aladin Brdar](https://www.linkedin.com/posts/abrdar1_proud-to-share-that-i-have-successfully-share-7512945056492904448-Ugtq/), the latter shown here presenting his work on the openPCIE platform, tapping into its hardware, software and simulation facets.

<p align="center">
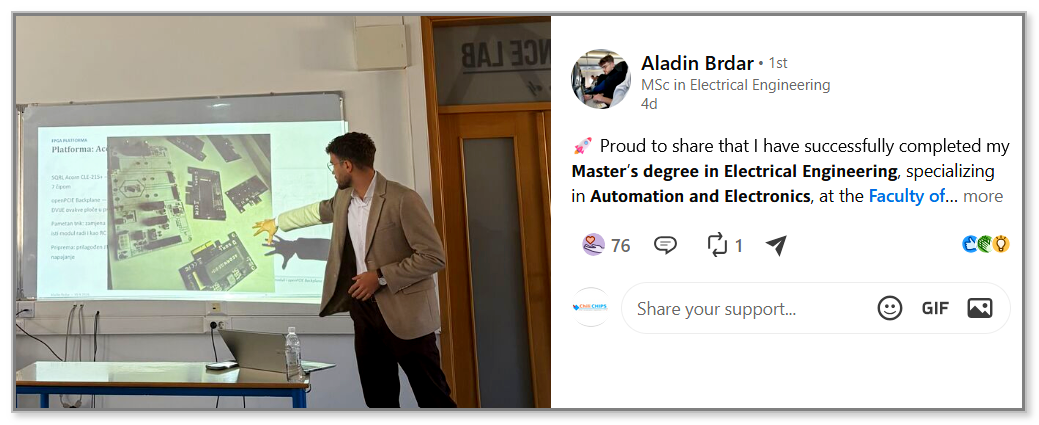
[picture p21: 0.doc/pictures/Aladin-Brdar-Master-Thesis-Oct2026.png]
Aladin Brdar presenting his work on the openPCIE platform at ETF Sarajevo
 
</p>

--------------------

### Acknowledgements
We are grateful to **NLnet Foundation** for their sponsorship of this development activity.

<p align="center">
   <a href="https://nlnet.nl/project/openPCIe2-RootComplex">NLnet logo</a>
   <a href="https://nlnet.nl/core">NGI Zero, Next Gen Internet</a>
</p>

This project was funded through the NGI0 Core Fund, a fund established by NLnet with financial support from the European Commission's Next Generation Internet programme, under the aegis of DG Communications Networks, Content and Technology under grant agreement No 101092990.

The **wyvernSemi**'s wisdom and contribution made a great deal of difference -- Thank you, we are honored to have you on the project.

<p align="center">
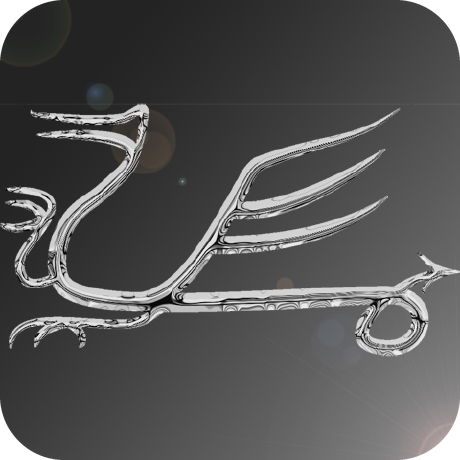
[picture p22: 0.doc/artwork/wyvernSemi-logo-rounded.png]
wyvernSemi-Logo
 
</p>

The **Envox**, our next-door buddy, is responsible for the birth of our backplane, which we like to call BB (not to be mistaken for their gorgeous blue beauty [BB3](https://www.envox.eu/eez-bb3))

<p align="center">
  <a href="https://www.envox.eu">EEZ / Envox logo</a>
</p>

### Crowd Supply Campaign
 - [Info Page](https://www.chili-chips.xyz/openpcie-backplane-put-your-fpga-in-control), [Intro Video](https://www.canva.com/design/DAHXSTcjxEc/odZj_VbgU20EEeZ1zuJlJA/watch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)
 - [Hackster](https://www.hackster.io/chili-chips-ba/openpcie-backplane-76fdb0)
 - [Elecrow](https://www.hackster.io/ElecrowOfficial/projects)

<p align="center">
  <a href="https://www.crowdsupply.com">Crowd Supply logo</a>
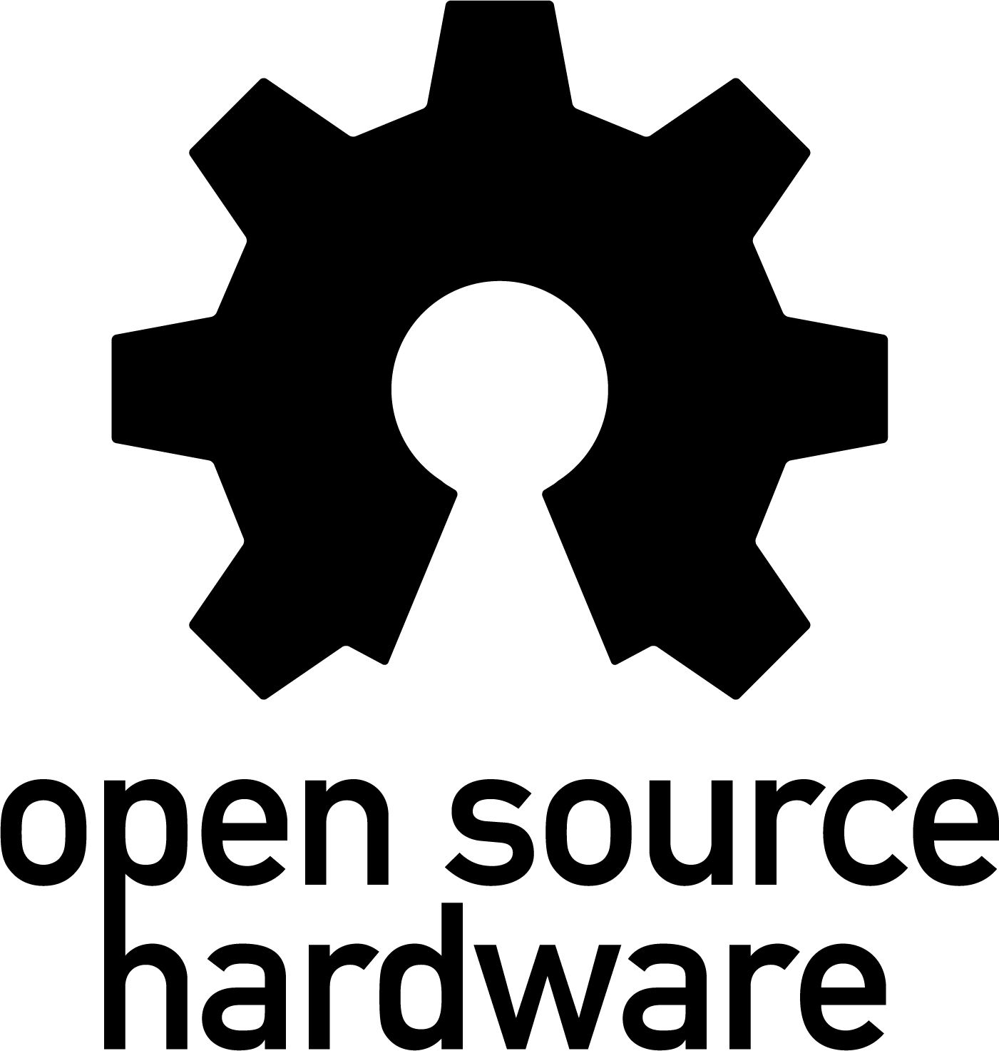
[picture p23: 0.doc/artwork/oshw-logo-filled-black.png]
Open Source Hardware logo
  
</p>  

<p align="center">
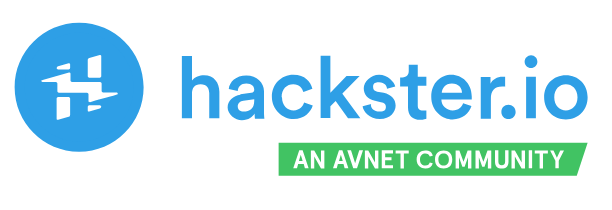
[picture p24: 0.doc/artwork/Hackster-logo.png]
Hackster logo
  
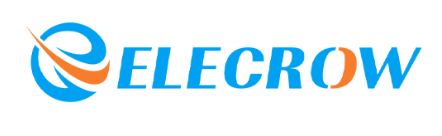
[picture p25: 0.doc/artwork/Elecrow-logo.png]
Elecrow logo
  
  <a href="https://www.kickstarter.com">Kickstarter logo</a>
</p> 

<p align="center">
  <a href="https://www.symbioticeda.com">Symbiotic EDA logo</a>
  <a href="https://github.com/openXC7">openXC7 logo</a>
</p>   

<p align="center">
  <a href="https://www.kicad.org">KiCad logo</a>
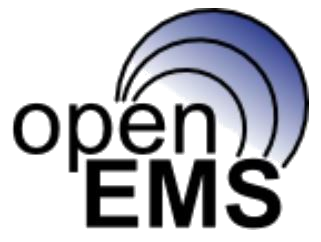
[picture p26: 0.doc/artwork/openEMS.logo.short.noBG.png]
openEMS logo
  
</p>

<p align="center">
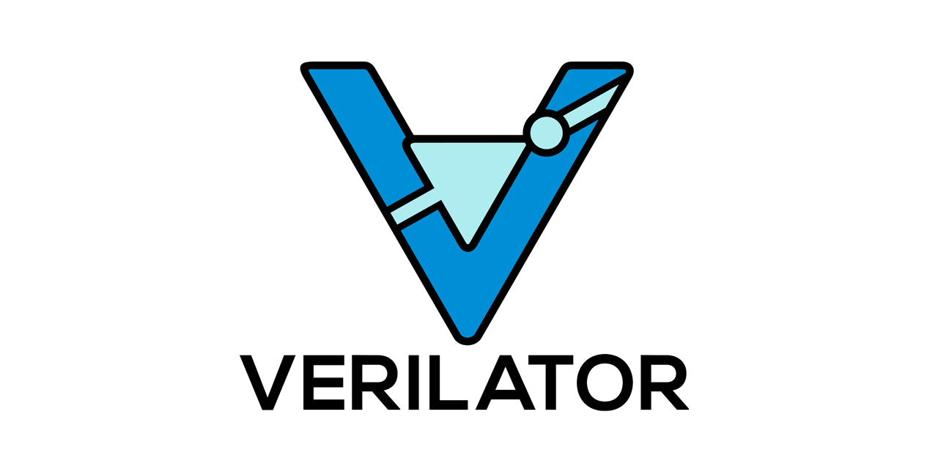
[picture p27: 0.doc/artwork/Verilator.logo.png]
Verilator logo
  
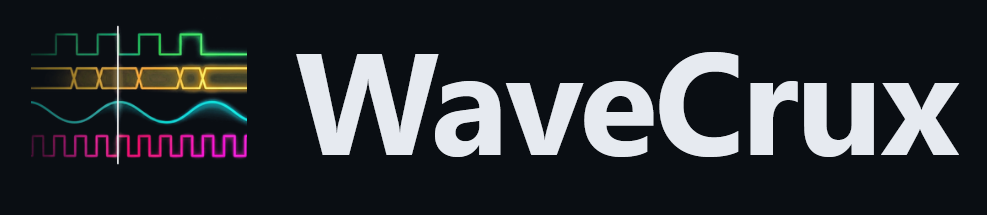
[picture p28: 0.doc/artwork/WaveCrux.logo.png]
WaveCrux logo
  
</p>

### Public posts:
- [2026-10-10](https://www.linkedin.com/feed/update/urn:li:activity:7509048253993242624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)
- [2026-10-05](https://lnkd.in/p/gVDkcKni)
- [2026-09-15](https://www.linkedin.com/posts/chili-chips_opensource-pcie-activity-7505034443674251264-eed-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)
- [2026-06-23](https://www.linkedin.com/posts/andrew-e-wilson_its-fun-bringing-all-the-fpga-vendors-together-share-7475267075234607104-j50-)
- [2026-01-26](https://www.linkedin.com/posts/chili-chips_fpga-pcie-riscv-activity-7421756737285734400-Lzlv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)
- [2025-12-19](https://www.linkedin.com/posts/chili-chips_opensource-fpga-gatemate-activity-7407180369269223424-laCE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)
- [2025-08-17](https://www.linkedin.com/pulse/pcie-model-c-simon-southwell-m2fve/?trackingId=CA4nW3if5DVRR%2BXN%2FIkQoQ%3D%3D)
- [2025-07-22](https://www.linkedin.com/posts/simon-southwell-7684482_pcie-vhdl-nvc-activity-7354160318052220929-K0Ku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)
- [2025-04-03](https://www.linkedin.com/feed/update/urn:li:activity:7313386031125303296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)

--------------------
#### End of Document

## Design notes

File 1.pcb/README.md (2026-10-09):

# openPCIE Backplane PCB

The board is designed for flexible PCIE system development and testing, featuring two distinct logical *islands*:  
- **(1-to-1) 4-lane Direct connection**
- **(1-to-4) 1-lane Switched connection**.

<p align="center" width="100%">
    openPCIE backplane block diagram
</p>

####  Key Features

- Modular Design:
  - Two independent “islands” for different PCIE topologies.  
- Flexible Connectivity:
  - Supports standard PCIE Slots and M.2 (M-key, PCIE) connectors.  
- Power, Clock and Reset generation:
  - Single 6-pin PCIE power connector supplies the entire board (up to 70 W total).  
  - Integrated 100 MHz REFCLK generator and reset (PERST#) distribution circuits.  
- Innovative RC Connector Design:
  - Allows natively EndPoint cards to function as a RootComplex without hardware modification.

Designed with **KiCad 10.0.6**, from schematic entry to layout. For the full schematic PDF, click [here](openpci2-backplane/openpci2-backplane.pdf).

### Production Files

The ready-to-order package (BOM with MPNs, interactive BOM, pick-and-place, Gerbers + drill, Gerber PDF, STEP model) is in [openpci2-backplane/production](openpci2-backplane/production). All symbols, footprints and 3D models come from the in-repo [KiCad-library](KiCad-library), so nothing needs to be installed besides KiCad. To regenerate everything with [KiBot](https://github.com/INTI-CMNB/KiBot):

```bash
cd openpci2-backplane
kibot -c openpci2-backplane.kibot.yaml -d production
```

### Common Resources

#### Power Delivery
- Powered by a standard **6-pin PCIE power connector** (3 × **+12V**, 3 × **GND**).  
- The **+12V** input goes straight to the four PCIE slots. A 30 A **DC-DC** buck (TPS54KC23) makes **+3.3V** for the slots, the M.2 connectors and the board; a second, small buck makes the ASM1184e switch's core supply, and an **LDO** makes the **+1.8V** for the clock generator.  
- Total power budget: **~70W**, with a guideline of **10W per slot**.

#### Clock Distribution
- On-board **100MHz PCIE-approved REFCLK Generator** provides the reference clock.
- The clock is distributed to all slots via differential buffers (**REFCLK+ / REFCLK-**).
- The **REFCLK** is only distributed to a slot (both RC and EP) after a device has been inserted and asserts the **CLKREQ#** signal (by driving it to logic low). This feature ensures that clocks are only active when and where needed, thus reducing the power and EMI.

#### Reset Logic
The system-wide PERST# reset signal is distributed to all slots and can be triggered by two sources:

- **Automatic**: Triggers a reset whenever a supply voltage is outside its specified range.
- **Manual**: A push-button for user-initiated resets.

##  Functional Blocks

### 4-lane “Direct” Island (RC4 ⇔ EP4)

Provides a direct, point-to-point, 4-lane PCIE link between two connectors.

**RC4 (Root Complex)**  
- 4-lane connector intended for a card acting as the Root Complex.  
- Mechanical option: *M.2 (M-key, PCIE)*.

**EP4 (Endpoint)**  
- 4-lane connector for a standard Endpoint card.  
- Mechanical option: *Standard PCIE slot*.

---
### 1-lane “Switched” Island (RC1 ⇔ SW ⇔ SW_EP0/1/2/3)

Uses a PCIE switch to branch a single upstream lane into four downstream lanes.

**RC1 (Root Complex)**  
- 1-lane connector for the upstream Root Complex card.  
- Mechanical option: *Standard PCIE Slot*.

**PCIE Switch**  
- Device: **Asmedia ASM1184e** (PCIE 2.0 switch).  
- Configuration: **1 × Upstream → 4 × Downstream** (1-to-4).

**SW_EP0 – SW_EP3 (Endpoints)**  
- Four 1-lane connectors for downstream Endpoint cards.  
- Mechanical options: *Standard PCIE Slot* or *M.2 (M-key, PCIE)*.

#### Note on “RC Connectors”

A key design feature of this backplane is the implementation of the **RC (Root Complex)** connectors.

Most FPGA development boards or other plug-in cards are natively designed with an **Endpoint (EP) pinout**.  
The backplane swaps the connector pins on the RC slots so that:

- The **Transmit (Tx)** differential pairs from the plug-in card connect to the **Receive (Rx)** pairs on the opposite side, and  
- The **Receive (Rx)** pairs connect to the **Transmit (Tx)** pairs on the other side.

This pin-swapping allows the same physical FPGA plug-in card—always pinned as an Endpoint—to operate in either **EP** or **RC** role.

---
## PCB Views

<p align="center" width="100%">
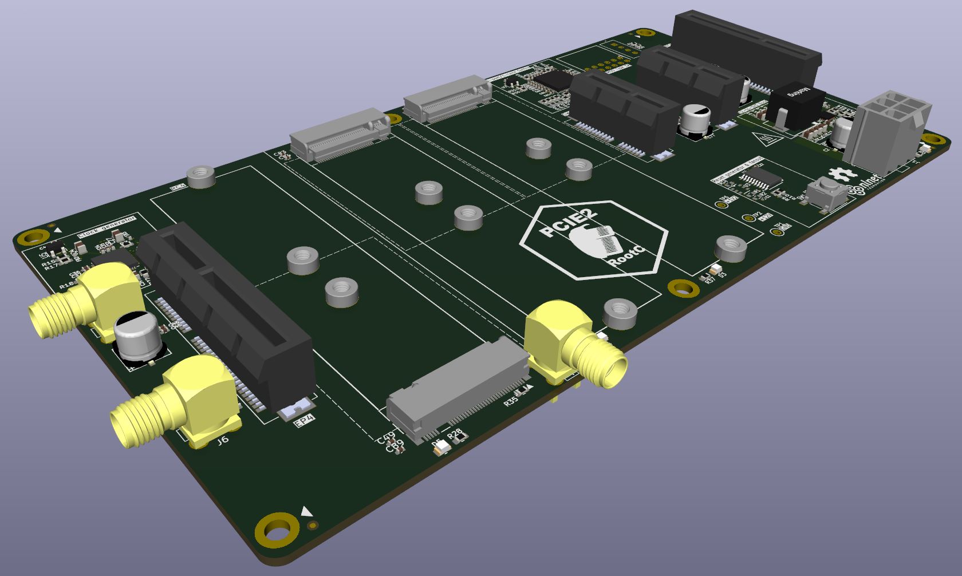
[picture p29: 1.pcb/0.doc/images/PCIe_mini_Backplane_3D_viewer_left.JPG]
Backplane 3D view, from the left
    
</p>

<p align="center" width="100%">
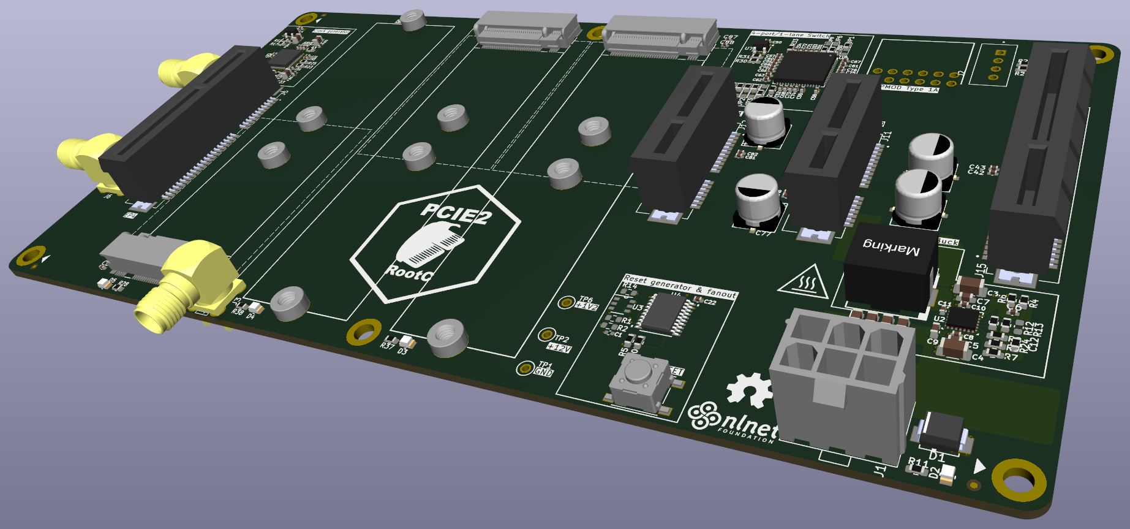
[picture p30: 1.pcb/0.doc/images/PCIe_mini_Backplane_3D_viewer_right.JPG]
Backplane 3D view, from the right
    
</p>

<p align="center" width="100%">
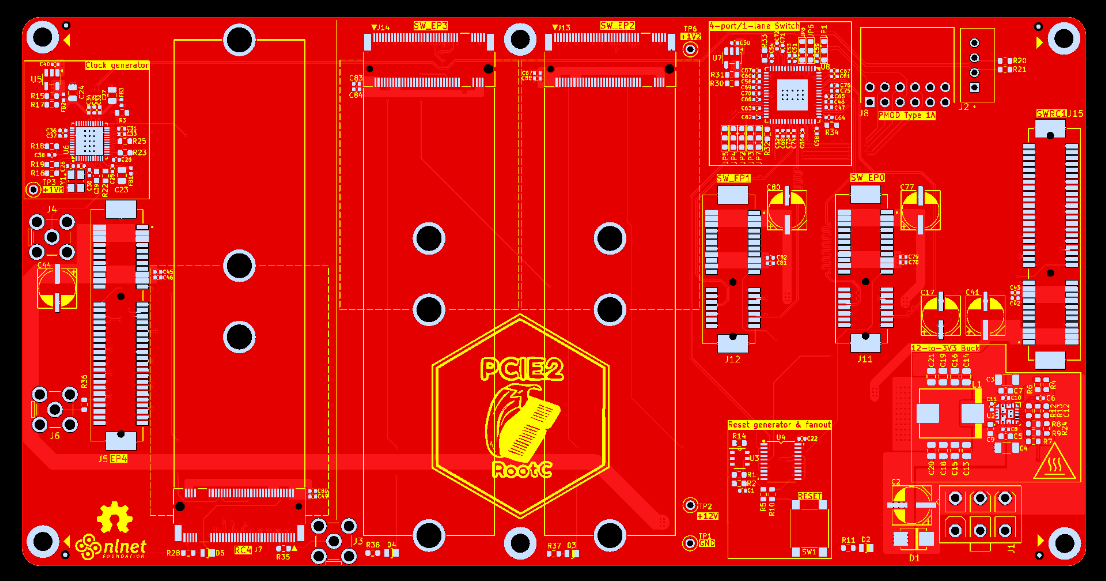
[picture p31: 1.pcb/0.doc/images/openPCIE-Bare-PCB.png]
Bare backplane PCB
    
</p>

Impedance-controlled traces:

<p align="center" width="100%">
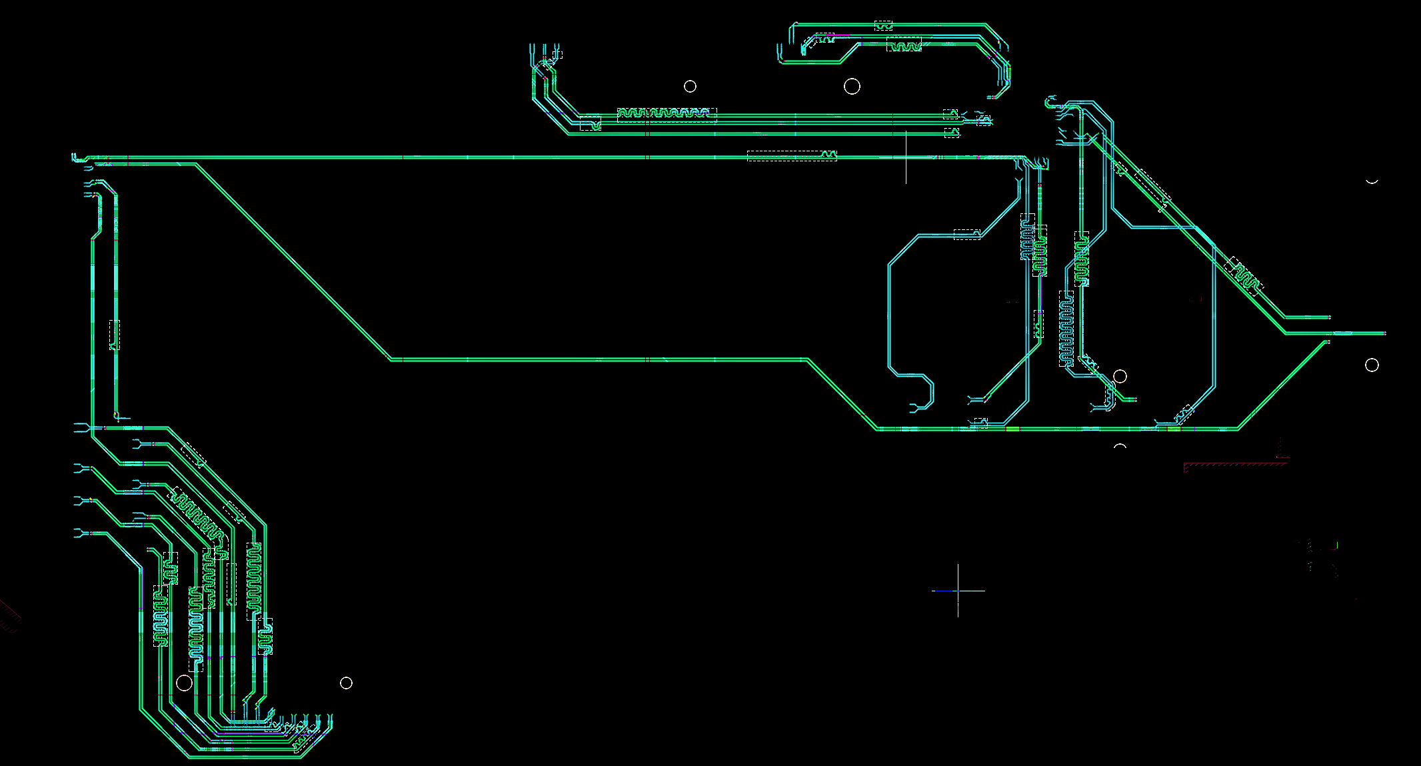
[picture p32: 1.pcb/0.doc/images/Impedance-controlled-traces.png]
Impedance-controlled traces on the backplane
    
</p>

---
## Usage scenarios

### Usecase 1: Direct FPGA_RC to FPGA_EP (Gen2 x1)

<p align="center" width="100%">
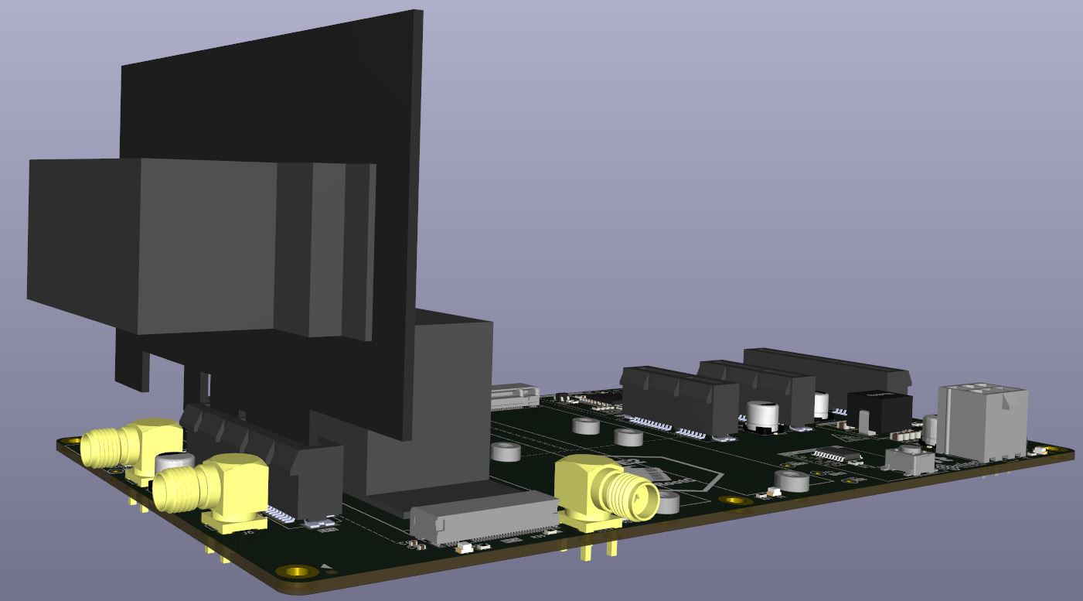
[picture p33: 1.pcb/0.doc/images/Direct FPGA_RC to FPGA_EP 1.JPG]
Direct FPGA RC to FPGA EP setup, view 1
    
</p>

<p align="center" width="100%">
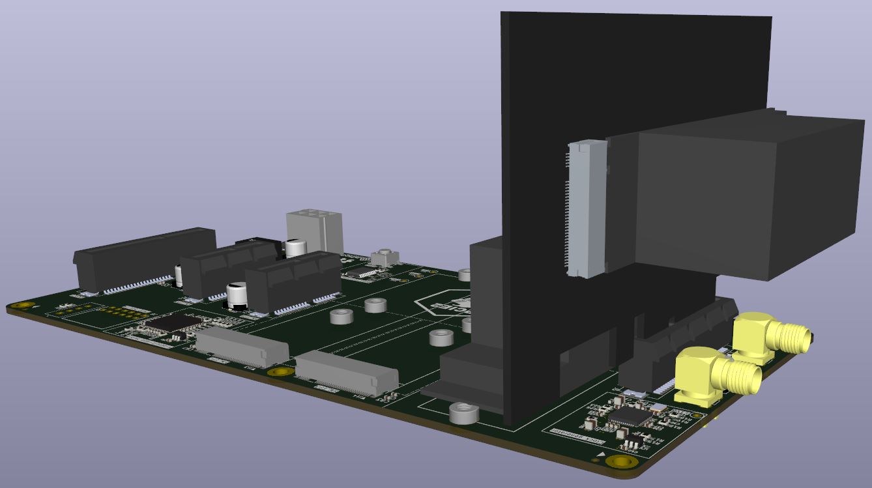
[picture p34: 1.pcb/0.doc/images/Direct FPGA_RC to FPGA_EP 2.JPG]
Direct FPGA RC to FPGA EP setup, view 2
    
</p>

<table align="center" style="border: none; border-collapse: collapse;">
  <tr style="border: none;">
    <td align="center" style="border: none;">
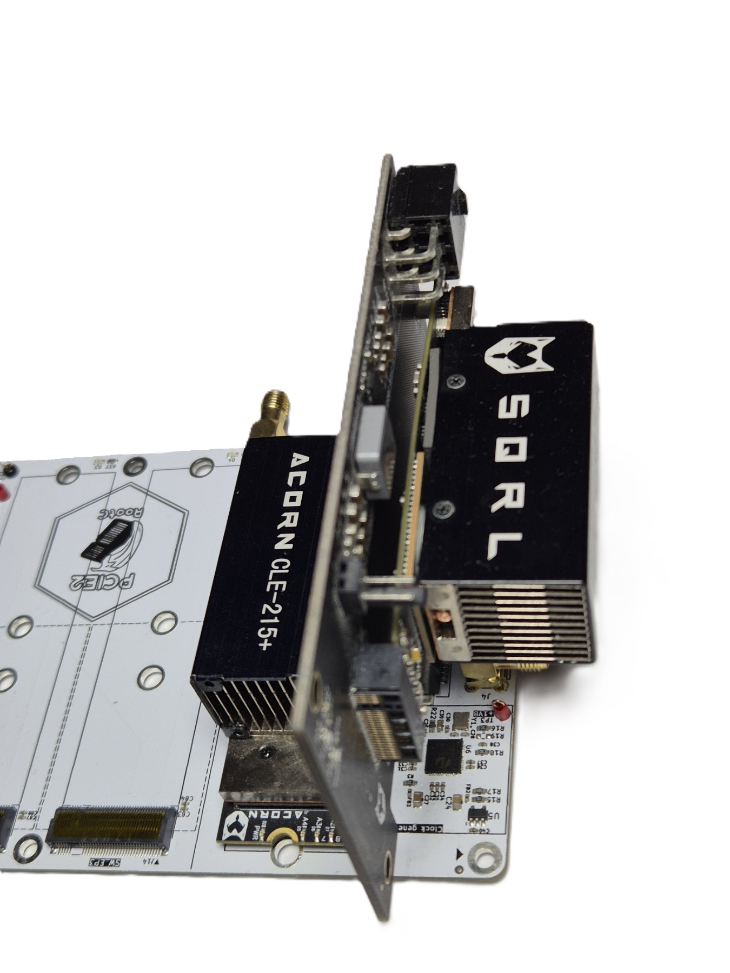
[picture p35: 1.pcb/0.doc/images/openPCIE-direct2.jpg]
Direct connection on the backplane, view 2
      
    </td>
    <td align="center" style="border: none;">
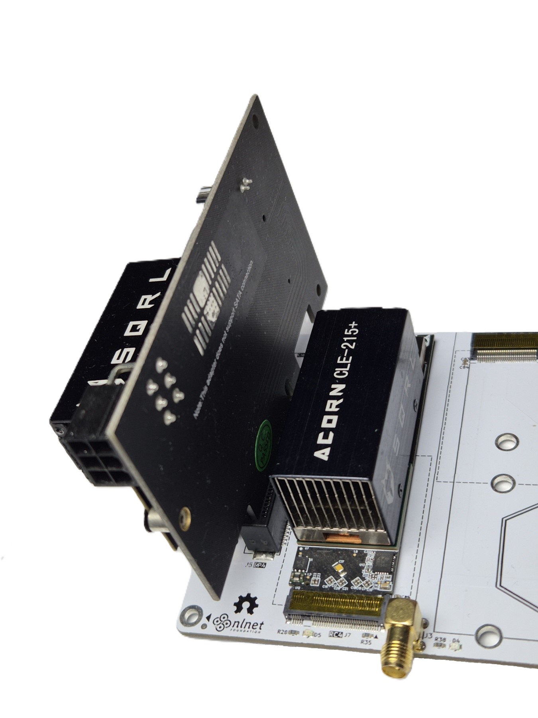
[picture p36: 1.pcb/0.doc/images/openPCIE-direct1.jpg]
Direct connection on the backplane, view 1
      
    </td>
  </tr>
</table>

This scenario is the bread-and-butter, the meat of this project. That's what it is about. Our Artix-7 RootComplex has been tested in this setup and trains a **Gen2 x1** link to the EndPoint.

> **Note:** As a bonus, the direct connection has also been tested in **Gen2 x4** mode, using all four lanes of the RC4 ⇔ EP4 island, with both the opensource and the AMD RC designs. The checked-in designs stay at **x1**, the committed deliverable.

This same scenario is also envisioned for testing the interoperability of our [openCologne-PCIE](https://github.com/chili-chips-ba/openCologne-PCIE) EndPoint with Xilinx Artix-7 RootComplex.

### Usecase 2: Switched FPGA_RC to FPGA_EP (Gen2 x1)

<p align="center" width="100%">
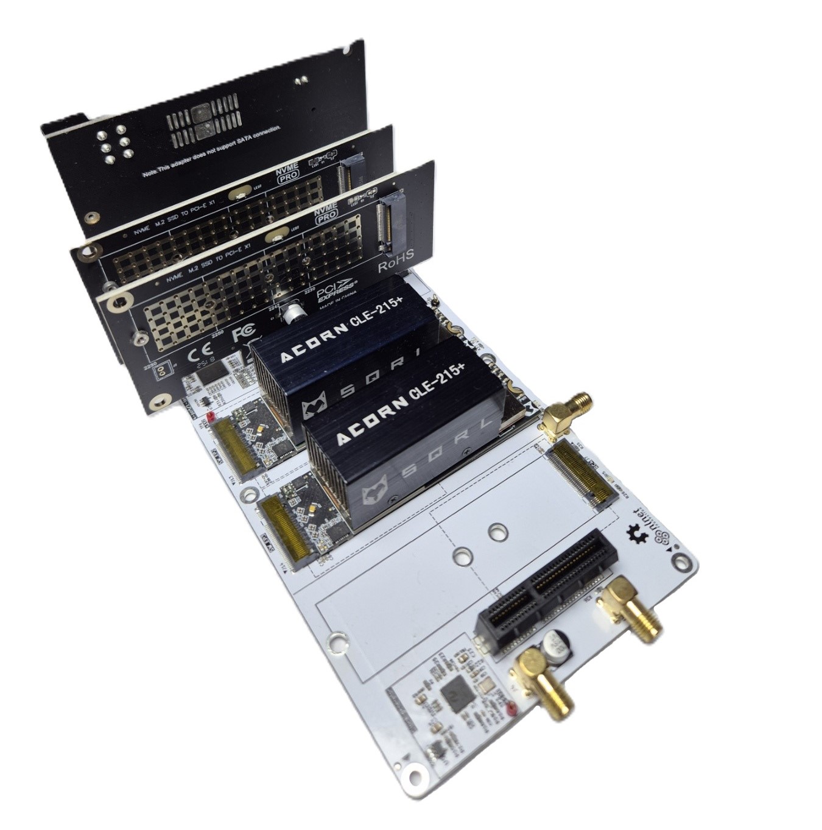
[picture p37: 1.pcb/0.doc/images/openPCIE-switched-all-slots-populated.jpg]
Switched island with all slots populated
    
</p>

<table align="center" style="border: none; border-collapse: collapse;">
  <tr style="border: none;">
    <td align="center" style="border: none;">
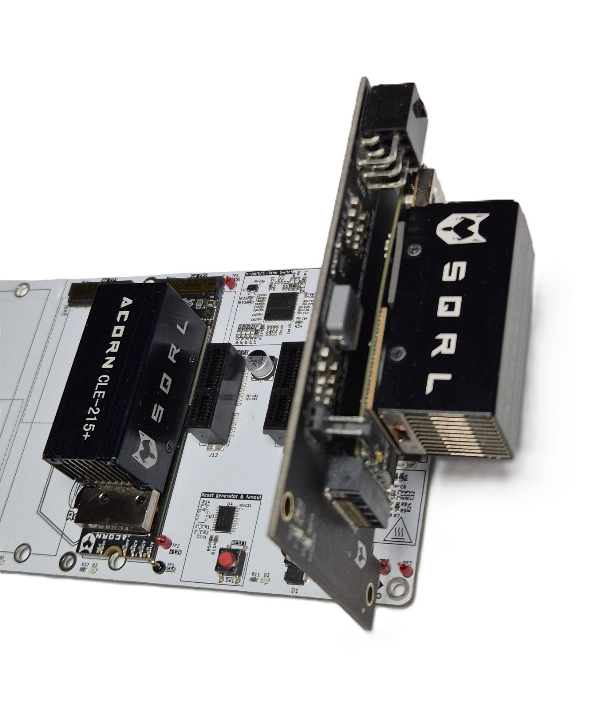
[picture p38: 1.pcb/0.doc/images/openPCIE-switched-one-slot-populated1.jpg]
Switched island with one slot populated, view 1
      
    </td>
    <td align="center" style="border: none;">
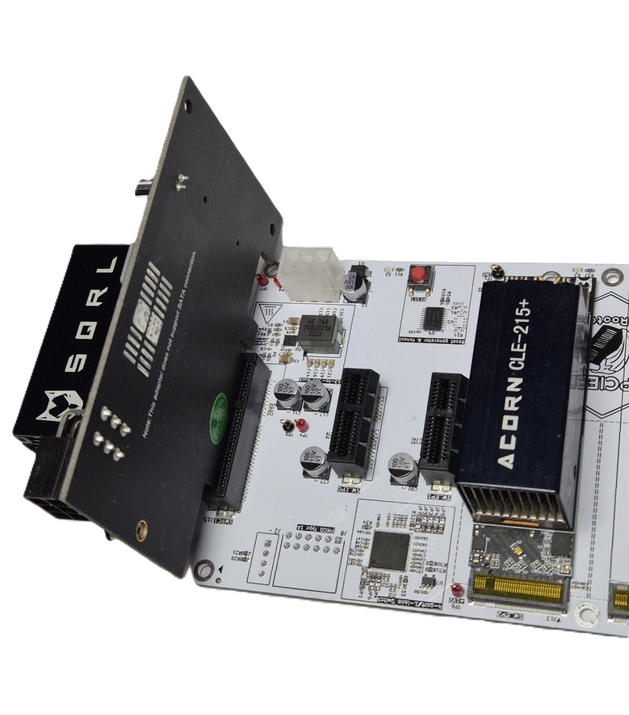
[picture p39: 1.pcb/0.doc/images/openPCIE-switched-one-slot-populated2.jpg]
Switched island with one slot populated, view 2
      
    </td>
  </tr>
</table>

The RootComplex has also been tested with EndPoints behind the on-board ASM1184e PCIE Switch, over a **Gen2 x1** link. This was a bonus deliverable, beyond the original plan - see [RC-switched](../2.rtl/3.Bonus--RC-switched.opensource) for the design.

### Usecase 3: PCIE Expansion or Extension
By using our _"PCIE Jumper Cable"_, the backplane can be connected to a standard PC serving as a RootComplex, such as for the expansion of its I/O Slot capacity, or for the extension of its physical reach. We also intend to use it for [openCologne-PCIE](https://github.com/chili-chips-ba/openCologne-PCIE) EndPoint validation, specifically to assess and compare the strength of GateMate SerDes to others, Xilinx Artix-7 and off-the-shelf ASICs in particular.

<p align="center" width="100%">
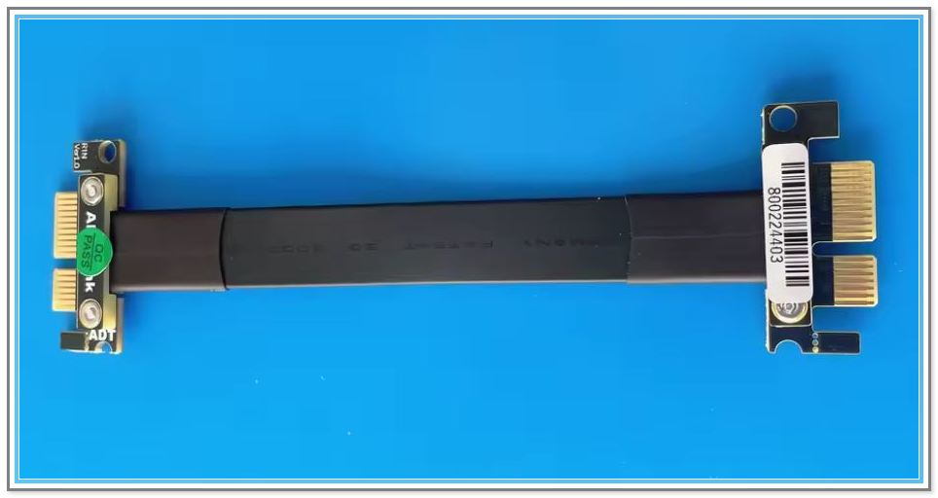
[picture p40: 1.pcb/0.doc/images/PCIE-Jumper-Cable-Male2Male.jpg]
PCIE male-to-male jumper cable
    
</p>

## PCIE Layout Considerations

The _characteristic impedance_ of the differential pairs on our backplane is `100ohm+/-10% for both data and clock signals`. They are all routed as `microstrips`, i.e. with reference to Ground/Power plane from only one side. The P-to-N skew is matched to no more than **5 mils**.

The number of vias or other impedance discontinuities on the path of `5Gbps signal wires` and `100MHz reference clocks` is minimized. We use Through-Hole (TH) slot connectors for mechanical stability and better routability. The M.2 and RPi connectors are Surface-Mount Devices (SMD). All components are on the top side of the board. We did not use the _'striplines'_, which is when the high-speed traces are sandwiched between two reference planes (ground or power), as they require vias and are typically used in setups with 6 or more layers. We used the _'microstrips'_: routed on the side where the connectors are, a differential pair connects without any via. Routed on the opposite side, it needs two vias per line, one at each end. 9 of the 31 pairs run on the connector side, the other 22 on the opposite side (see also [The P and N Swaps](#the-p-and-n-swaps)). 

The size of our vias is the standard **0.3mm**. The blind, buried, partial or any other advanced via technologies are not used. That makes for a less expensive PCB and final product, but it also stresses the need to be cautious about placing vias on the diff pairs. Such vias go through all layers, they are longer. They are also not with the smallest possible diameter, therefore overall bulkier and more of a disturbance.

<p align="center" width="100%">
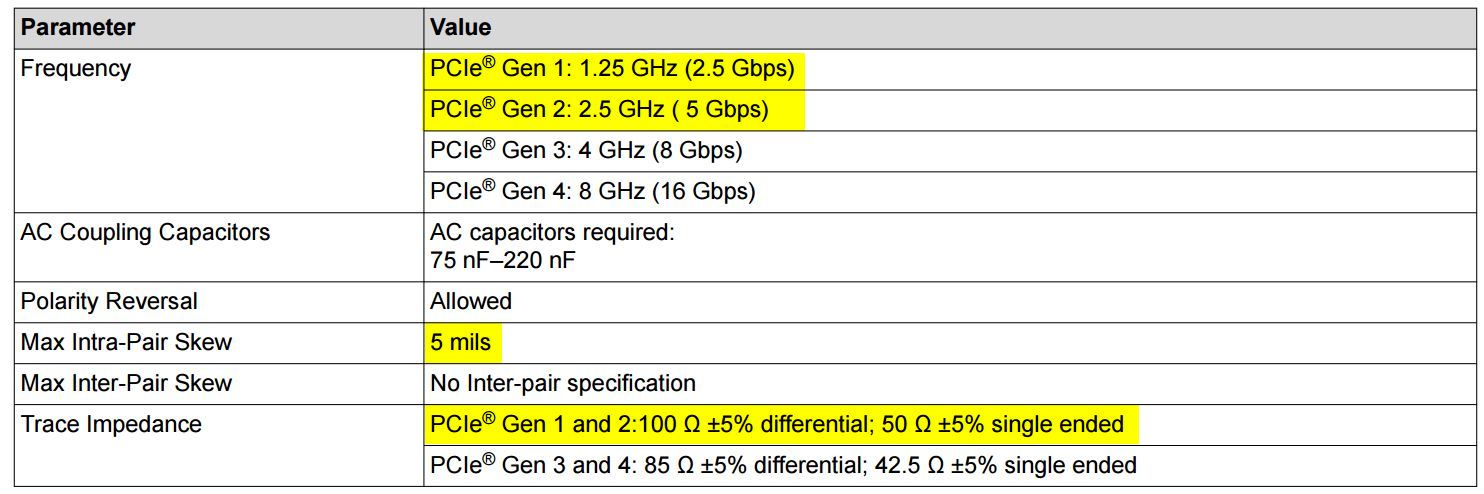
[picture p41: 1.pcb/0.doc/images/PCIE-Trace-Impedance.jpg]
PCIE trace impedance
    
</p>

Our stackup is **4-layer**:

- `Top` - Microstrip for diff pairs and ordinary lines 
- `L2` - Ground plane
- `L3` - 3.3V Power plane
- `Bottom` - Microstrip for diff pairs and ordinary lines 

<p align="center" width="100%">
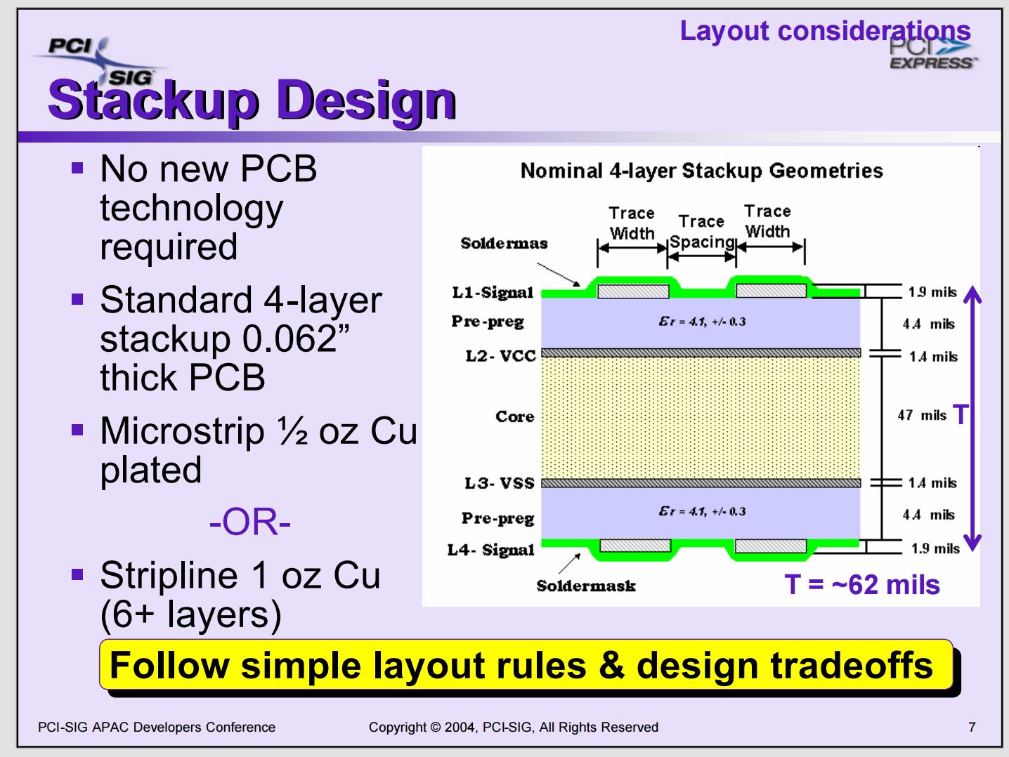
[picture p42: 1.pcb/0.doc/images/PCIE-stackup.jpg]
4-layer PCB stackup
    
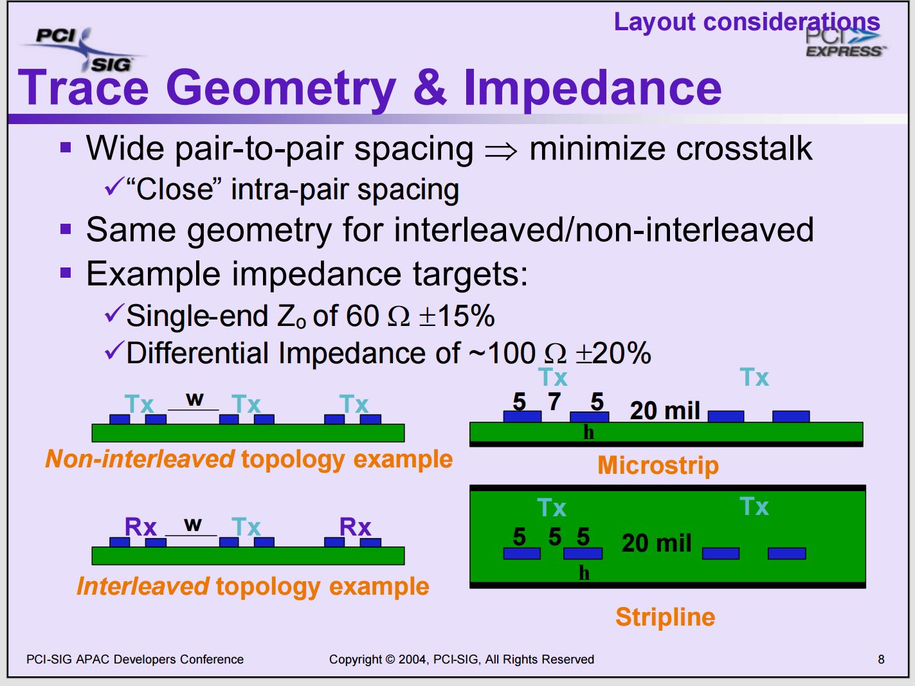
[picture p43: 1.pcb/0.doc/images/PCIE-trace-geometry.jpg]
Differential trace geometry
    
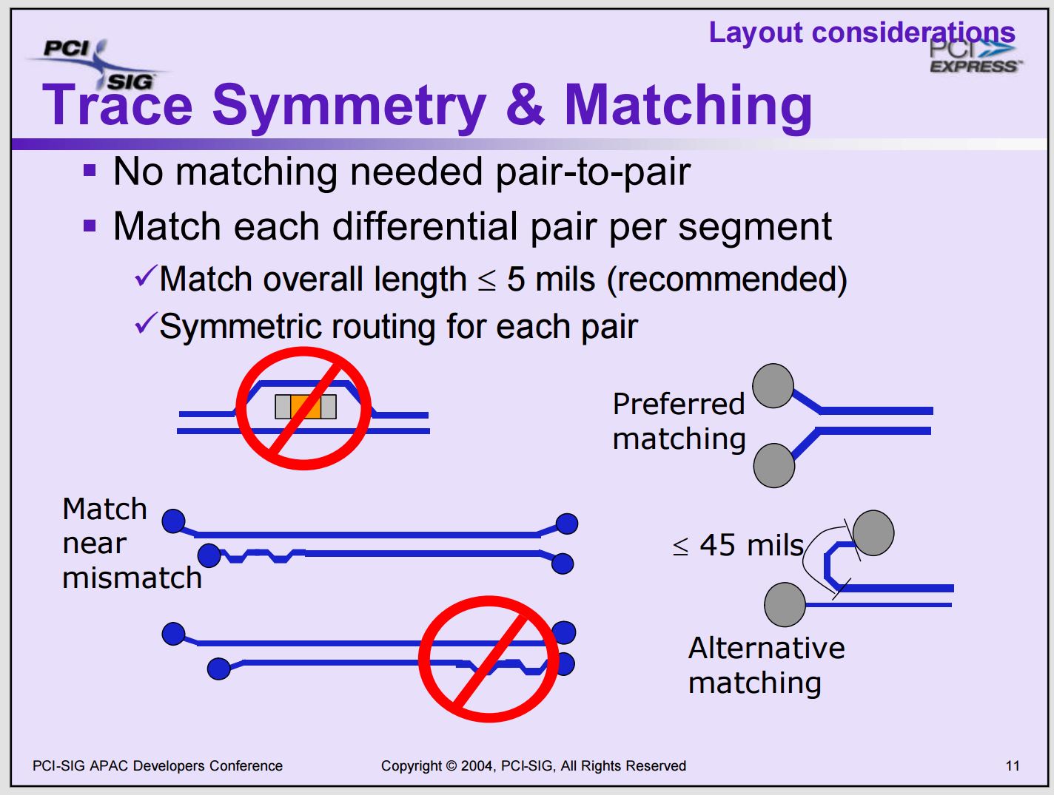
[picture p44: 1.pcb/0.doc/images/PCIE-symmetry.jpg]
Differential pair symmetry
    
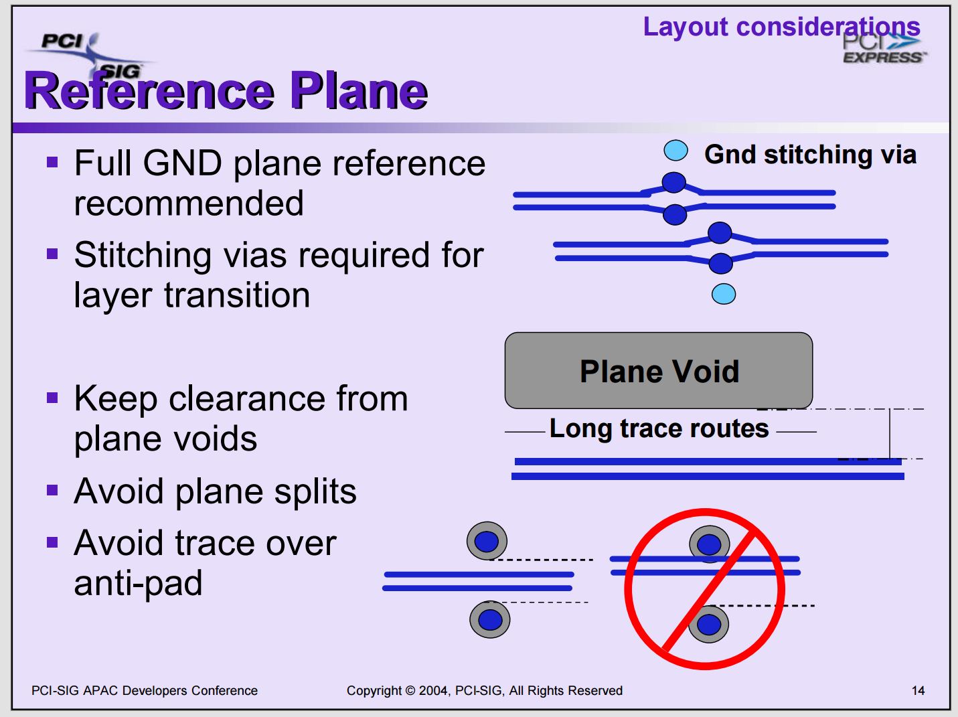
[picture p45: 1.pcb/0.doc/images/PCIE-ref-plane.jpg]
Reference plane under the traces
    
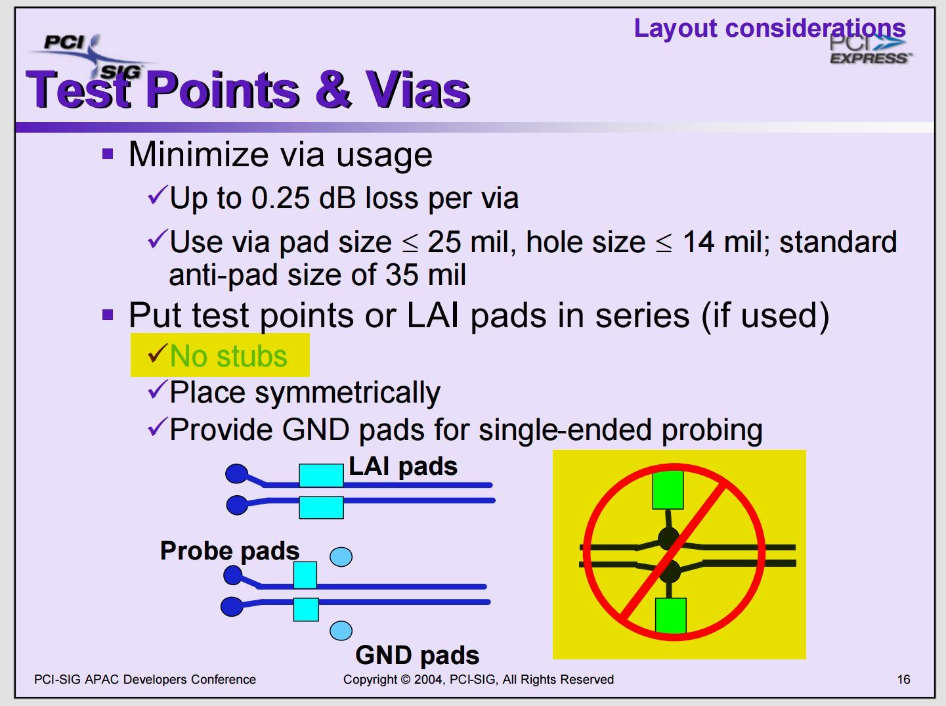
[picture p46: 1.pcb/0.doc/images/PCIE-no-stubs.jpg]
Routing without stubs
    
</p>

Check [this](0.doc/PCIE-Layout-Guidelines.SIG.pdf) link for additional physical and routing considerations.

Since we have a unique feature with multiple connectors on the same line, special care is given to minimize the "stubs" at both the start and end of the transmission line. Here is an example of what not to do.

<p align="center" width="100%">
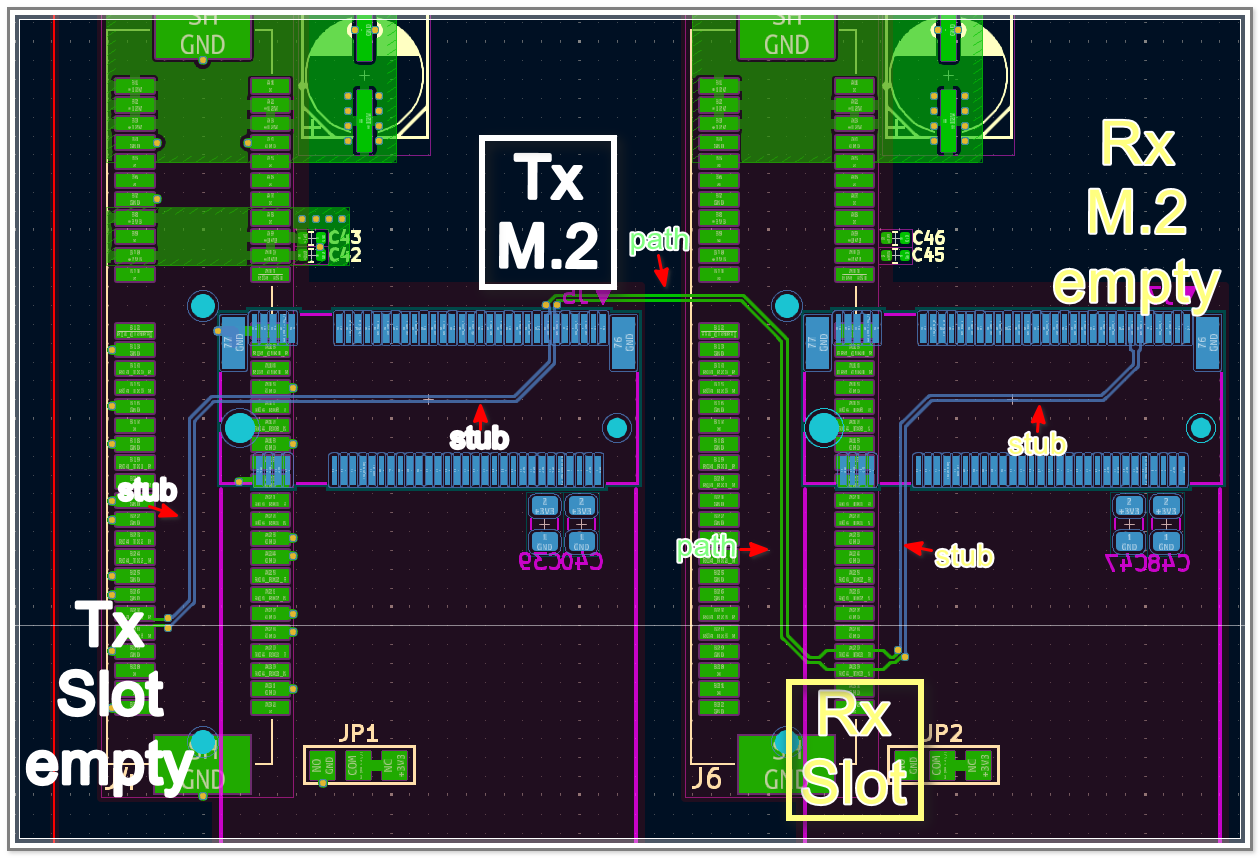
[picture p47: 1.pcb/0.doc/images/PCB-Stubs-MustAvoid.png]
Example of stubs to avoid
    
</p>

## The P and N Swaps

While the PCIE requirements stipulate that, in order to simplify the PCB layout, the electronics should be capable of internally swapping the P and N leads of differential pairs, we did not want to take chances, and have taken extra steps not to depend on the plug-in electronics -- All Ps are routed to the Ps, and all Ns to the Ns, even if that called for a via. 

<p align="center" width="100%">
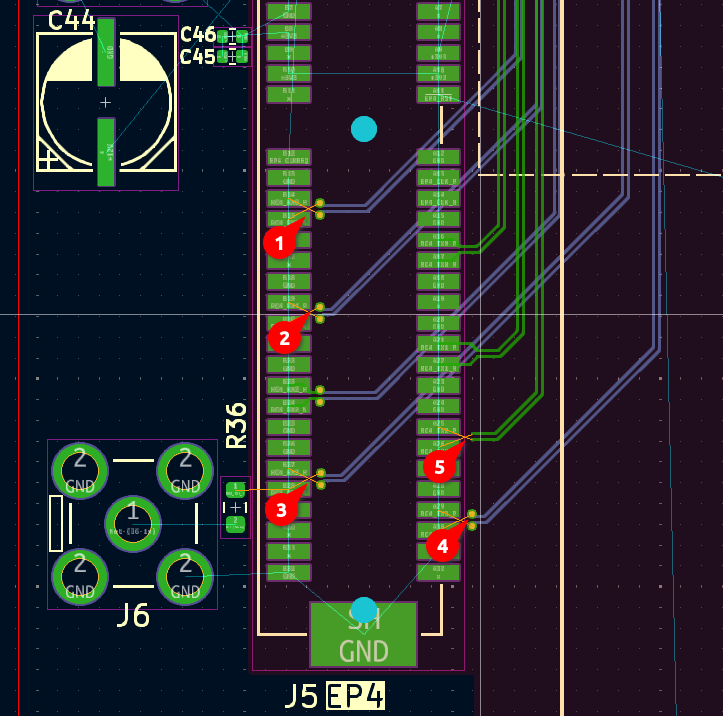
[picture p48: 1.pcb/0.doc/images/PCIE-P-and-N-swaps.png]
P and N routing without swaps
    
</p>

## PCIE Connection Model: Generators → Transport → Consumers

All signal generators should be placed as close as possible to each other. Likewise, all signal consumers should be grouped very close together. The goal is to minimize the stubs, both at the beginning of the transmission path (on the generator side) and at the end (on the consumer side).

In the example above, when the M.2 connector acts as the signal generator and the Slot is the consumer, very long stubs appear on both ends. Since the active signal also propagates into these unterminated stubs, part of it gets reflected back with a noticeable delay proportional to the stub length. This reflected wave interferes with the original signal at the Slot receiver when that signal should be stable. Similarly, the reflection from the M.2 stub disturbs the transmitter at the M.2 side, which then shows up again at the Slot and superimposes with the first and second waves.

The key is to eliminate or minimize the second, third, and subsequent `reflected waves`, keeping only the primary, `incident wave` that carries the valid data.

## Signal Integrity (SI) Sims
Signal integrity was validated with [openEMS](https://docs.openems.de) electro-magnetic simulations of the high-speed traces.

The following videos demonstrate signal reflections on a transmission line in two different cases:

- **Transmission line with stub** – see video below

https://github.com/user-attachments/assets/f051aea8-5269-4e07-8074-357f93c2e468

- **Transmission line without stub** – see video below

https://github.com/user-attachments/assets/b43a36d0-c9cd-4929-85f8-a3717680f151
  
The following four wiring topologies are examined in openEMS Electro-Magnetic Simulations (EMS):
- `Bad` **Long stubs**. For understanding of _Incident_ and _Reflected_ waves
- `One-2-One` **Point-to-Point**. This is the standard and simplest, i.e. the baseline case
- `One-2-Two` **Point-to-Multipoint**. Unique for high-speed
- `Three-2-One` **Multipoint-to-Point**. Unique for high-speed

Since we feature multiple mechanical connectors ("Slot", M.2, RPi5 FPC) on the same diff lines, we have very unusual, probably **unique topologies** to deal with. All representative combinations are analyzed and presented.

### EMS topology 0: Bad (just for learning, not for using)
- long stubs on both sides. We can use the analysis of the Rx and Tx SMA connectors for this case to show why it is better to place them at the end of their line, close to the Rx input termination.
  
### EMS topology 1: One-2-One (standard)
- SWRC3_CLK_P/N 100MHz clock diff pair
  
### EMS topology 2: One-2-Two (unique)
- Pick the longest 5Gbps diff pairs from the SW => SW_EP0/1/2/3 set
    
### EMS topology 3: Three-2-One (unique)
- Pick one of the RC1 => SW 5Gbps diff pairs. We have RPi5 FFC, Slot and M.2 here.

## SI Lab Measurements
TODO

<p align="center" width="100%">
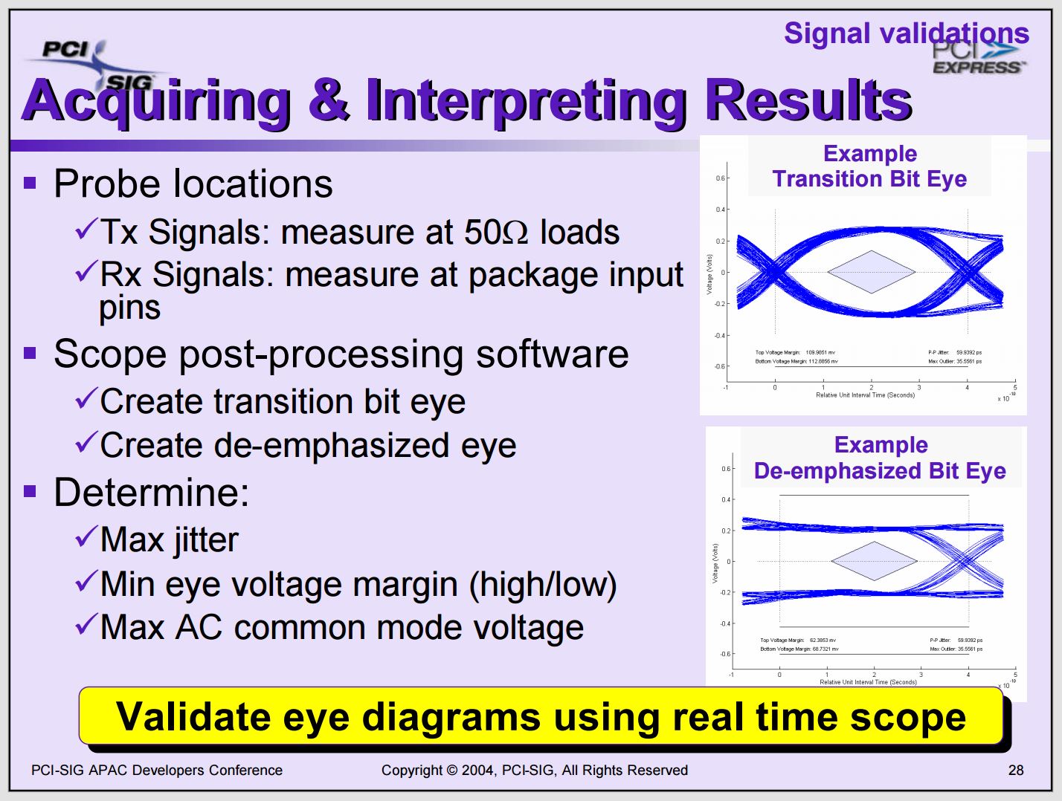
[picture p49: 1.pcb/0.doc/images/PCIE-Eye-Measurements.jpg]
PCIE eye measurements
    
</p>

## 30 Amp DC/DC Buck Layout Considerations

The layout of the PCIE backplane is not only about the 5Gbps differential pairs. The backplane also hosts a powerful 12V-to-3.3V DC/DC. Given its 30 Amps(!) current capacity, the buck layout calls for special attention. While we have followed the TI recommendations to the letter, the question was also raised about the stability of the `long Remote Sense` wires:
   1) Will they incentivize the buck to oscillate?
   2) Is the far-off Remote Sense really needed?

The argument is that the digital logic can tolerate +/-10% voltage inaccuracy. Remote Sense, while allowing fine voltage tracking at the very load point, creates a long loop that opens the Pandora box of potential closed-loop instability. The digital logic is more sensitive to transients than to the absolute voltage levels. The argument goes that the design should therefore focus on providing fast dynamic response rather than the static accuracy. 

<p align="center" width="100%">
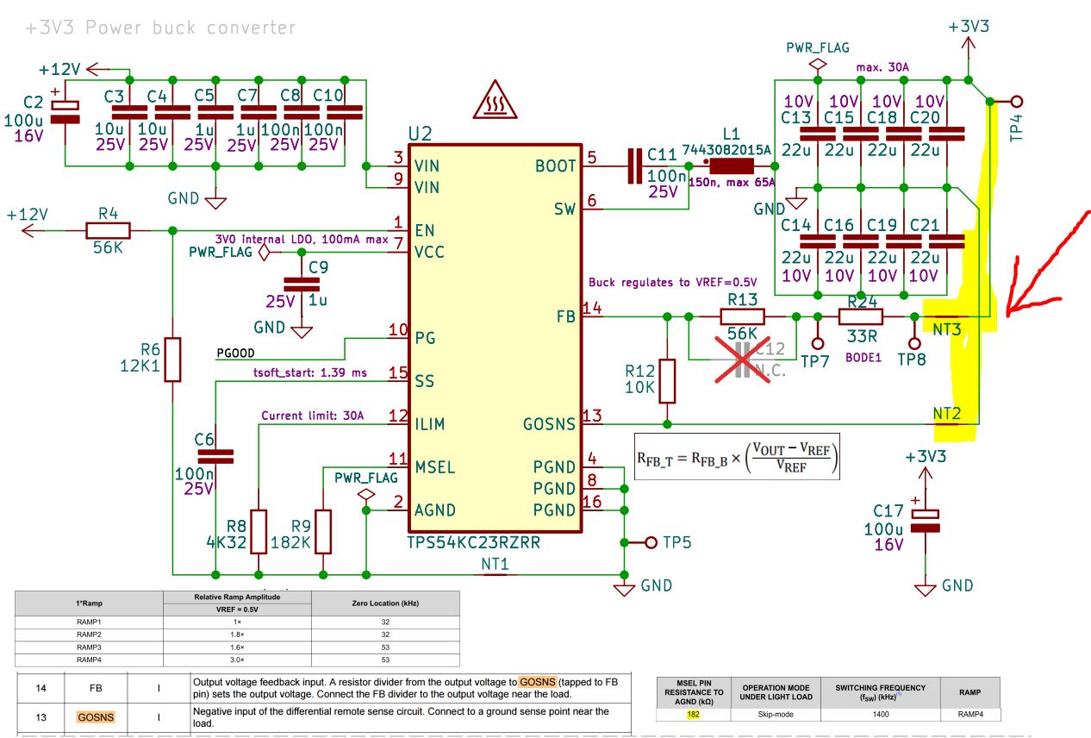
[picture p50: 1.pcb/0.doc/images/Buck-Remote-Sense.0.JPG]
DC/DC buck remote sense, part 1
    
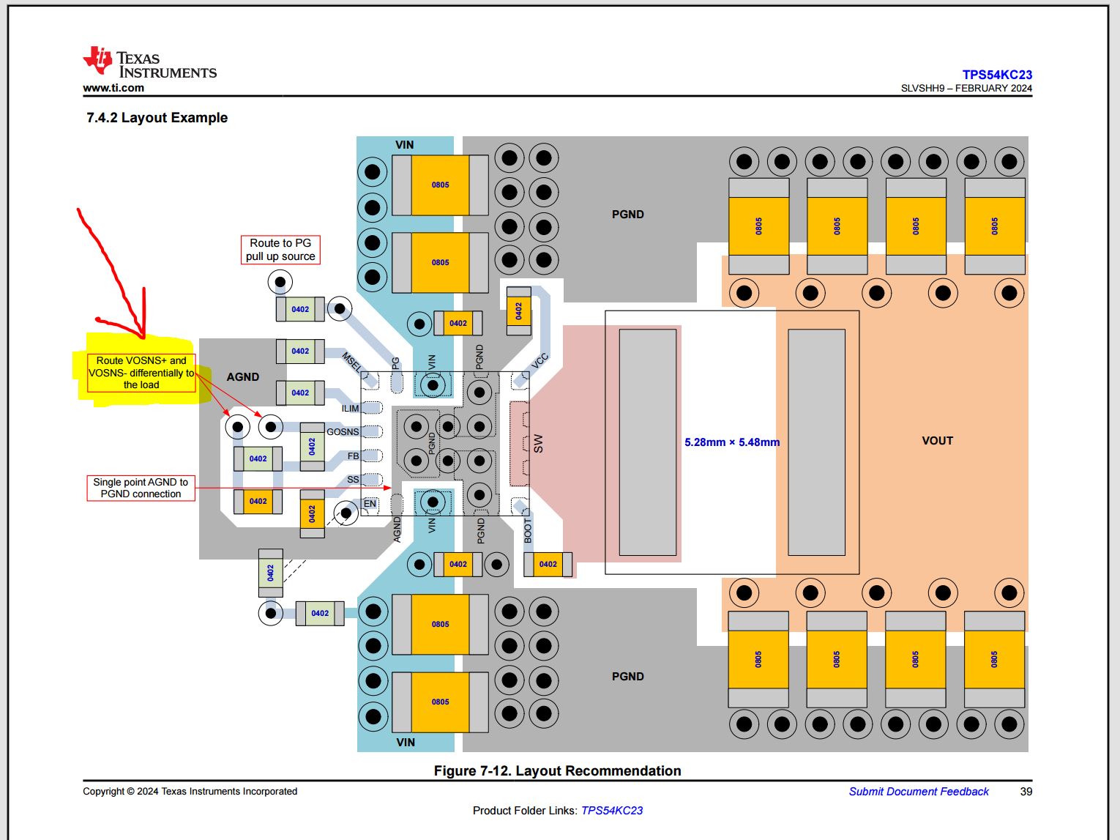
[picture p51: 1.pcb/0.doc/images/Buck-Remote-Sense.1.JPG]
DC/DC buck remote sense, part 2
    
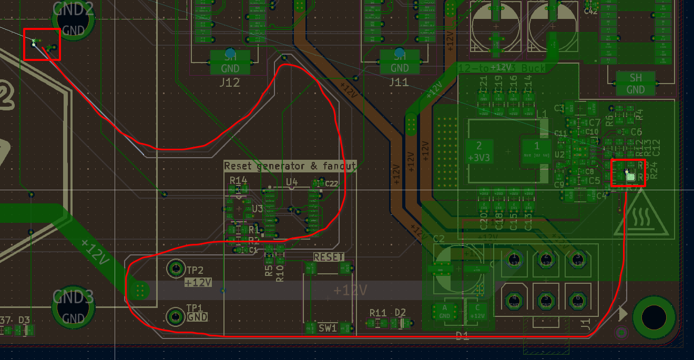
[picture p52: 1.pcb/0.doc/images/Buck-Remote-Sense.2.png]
DC/DC buck remote sense, part 3
    
</p>

Check [here](https://e2e.ti.com/support/power-management-group/power-management/f/power-management-forum/1588097/tps54kc23-tps54kc23-remote-sense-stability-or-not) to see what the TI experts had to say on this question.

# First Functional Check

When the backplane comes out of the reflow oven with all components soldered, and before loading it with boards for the full functional testing, we first must check the basic power, reset and clock generation circuits. See our PCBA Functional Test Procedure documents for the complete detail on how to go about it: [RevB](0.doc/PCBA_Functional_Test_Procedure_RevB.pdf) for the current board, and the [earlier revision](0.doc/PCBA_Functional_Test_Procedure.pdf).

# Crowd Supply Campaign
 - [Web Page](https://www.chili-chips.xyz/openpcie-backplane-put-your-fpga-in-control)

-----

### References:
**[1] PCIE Card Electro-Mechanical (CEM) Specification, Rev4.0** - available from [PCI-SIG](https://pcisig.com/specifications)

**[2] RPi5 PCIE Connector Enigma**
- [Reverse Engineering RPi5 PCIE](https://github.com/m1geo/Pi5_PCIe)
- [4-port PCIE/Gen3 Hub for RPi5. Based on ASM2806. FPC must be rotated](https://github.com/will127534/PCIe3_Hub)

**[3] PCIE Extenders**
- [PCIE "Slot" to 4-port "Slot" with ASM1184e, by Waveshare](https://www.waveshare.com/pcie-packet-switch-4p.htm)
- [RPi5 PCIe FPC to "Slot", by 52Pi](https://52pi.com/collections/all-products/products/p02-pcie-slot-for-rpi5)
- [RPi5 4-port FPC HAT with ASM1184e, by 52Pi](https://wiki.52pi.com/index.php?title=EP-0233)
- [RPi5 4-port FPC HAT with ASM1184e, by Waveshare](https://www.waveshare.com/pcie-to-4-ch-pcie-hat.htm)

**[4] ASMedia ASM1184e 1-to-4 single-lane PCIE/Gen2 Switch**
- [Product Brief](https://www.asmedia.com.tw/product/556yQ9dSX7gP9Tuf/b7FyQBCxz2URbzg0)
- [Technical Notes](https://crimier.github.io/posts/ASM118x)
- [Design Example: CM4 M2 (NVME) NAS](https://github.com/will127534/CM4-Nvme-NAS)

**[5] [Component datasheets](1.datasheets)**

**[6] [PCB Layout Guidelines](0.doc/PCIE-Layout-Guidelines.SIG.pdf). The [USB3](0.doc/High-Speed-PCB-Guidelines-for-USB3.slla414a.pdf) rules are also fully applicable**

**[7] Open-source SI Sim tools**
- [openEMS](https://docs.openems.de)
- [AntMicro EMS Sim](https://antmicro.com/blog/2025/07/recent-improvements-to-antmicros-signal-integrity-simulation-flow)

**[8] [Saturn PCB Tools](https://saturnpcb.com/saturn-pcb-toolkit)**

**[9] [JLC DFM Tool](https://jlcdfm.com)**

**[10] [JLC Impedance Calculator Tool](https://jlcpcb.com/pcb-impedance-calculator)**

**[11] [DCDC-How-To-Measure-Loop-Stability](0.doc/How-To-Measure-Loop-Stability.snva364a.pdf)**

**[12] DCDC-How-To-Implement-Remote-Sense: [Part1](0.doc/How-To-Implement-Remote-Sense.ssztam1.pdf), [Part2](0.doc/How-To-Implement-Remote-Sense.2.slyt467.pdf)**

**[13] [PMOD Interface Spec](0.doc/PMOD-interface-spec.V1_2_0.pdf)**

**[14] Auto-routers: [Haas](https://github.com/drandyhaas/KiCadRoutingTools), [Ortho](https://bbenchoff.github.io/pages/OrthoRoute.html), [JITX (proprietary)](https://www.jitx.com)**

**[15] [KiCanvas](https://kicanvas.org)**: Browser-based, interactive viewer for KiCAD schematics and boards

**[16] [VMH_Flow_4_PCB](https://github.com/EngGhaith/VMH_Flow_4_PCB)**: the openEMS workflow for IHP SG13G2, applied to PCBs

------
#### End of Document

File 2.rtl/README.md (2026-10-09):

# RTL Implementation: Opensource designs

This directory contains the **opensource** FPGA designs for the project - those
that wrap the Artix-7 hard macros with open logic instead of using the proprietary
Vivado IP generator.

The AMD/Vivado-IP counterparts live in a separate tree,
[`2.amd-rtl-with-Vivado-build`](../2.amd-rtl-with-Vivado-build). Each opensource
design here has an `.amd` sibling there that was built and proven first, and which
serves as the reference the opensource variant is measured against.

### Directory Structure

- **`0.common.opensource`**
  The RTL both Root Complex designs are built from - one top (`RC_opensource`),
  the RISC-V SoC, the CSR wrapper, the opensource PCIE stack - plus the shared
  constraints and the Vivado project script. The two RC folders below hold only
  what really differs: the GT lane their x1 link uses (a one-line XDC) and a short
  wrapper that runs the shared script for them. The firmware differs too; it
  lives in [`3.sw`](../3.sw).

- **`1.EP.opensource`**
  Opensource PCIE EndPoints, used as the link partner when testing our Root
  Complex. Rather than duplicating them here, this directory points to the
  existing upstream projects - LiteFury PCIE EP, regymm's pcie_7x and LitePCIe -
  any of which can be built on the side and paired with our RC. The
  [`1.EP.amd`](../2.amd-rtl-with-Vivado-build/1.EP.amd) replica is also available
  for the same purpose.

- **`2.RC-direct.opensource`** — **implemented and working**
  
  A Root Complex design for **Direct (Point-to-Point)** connection, and the core
  of the project. It includes the full stack: the opensource PCIE logic around the
  `PCIE_2_1` and `GTPE2_CHANNEL` hard macros, a RISC-V SoC, and the software
  running on it.

  Verified on hardware: **PCIE Gen2 x1, link up and trained** in a direct RC-to-EP
  configuration. As a bonus, **Gen2 x4** has also been tested on hardware; x1
  remains the checked-in default. It builds both with Vivado and with a
  [fully opensource toolchain](../4.build/hw_build.openXC7) - sv2v, yosys,
  nextpnr-xilinx and prjxray, with no proprietary tool in the chain.

- **`3.Bonus--RC-switched.opensource`** — **implemented and working**
  
  A Root Complex design for a **Switched** topology (RC ⇔ Switch ⇔ EP).

  Verified on hardware through a standard PCIE switch (ASM1184e).

---

### Common CSR

Both Root Complex designs take their register block from the **same** SystemRDL
specification, [`4.build/csr_build/csr.rdl`](../4.build/csr_build/csr.rdl).
`peakrdl` turns it into the register RTL (`csr_pkg.sv`, `csr.sv`) and into the
software headers, and the shared
[`soc_csr.sv`](0.common.opensource/src/soc_csr.sv) bridges that block to the
picorv32 memory interface. Regenerate with `make -f MakefileCSR` in
[`4.build`](../4.build); the details are in
[`4.build/README.md`](../4.build/README.md#csr-hal-compilation).

The hand-written register block that came first is still there, inside
`riscv_pcie_soc.sv` behind `` `ifdef SOC_CSR_LEGACY ``. Which one is built is set
once, in [`4.build/config.mk`](../4.build/config.mk), and read by every build
step - Vivado, openXC7 and the firmware - so the hardware and the software are
never built different ways. The two are functionally identical, down to the byte
offsets.

---

### Common Physical Constraints (XDC)

The **XDC file** is critical for mapping the logical PCIE signals to the specific physical pins on the `Acorn CLE-215+` board and the `openPCIE Backplane`. The following key elements are mandatory in all designs:

1.  **Clock Request (CRITICAL):**
    The backplane's clock generator will **NOT** output the 100 MHz reference clock unless the `CLKREQ#` pin (Pin **G1**) is actively driven **LOW**. If this is missing from the constraints, the FPGA will receive no clock, and the link will never establish.

2.  **Reference Clock & Reset:**
    - **REFCLK:** Configured for **100 MHz** via the differential pair (Pins **F6/E6**).
    - **PERST#:** The system reset (Pin **J1**) is active low.
3.  **Transceiver (GTP) Placement:**
    Defining `PACKAGE_PIN` constraints for RX/TX pairs alone is **insufficient**. The logical lane **must be explicitly locked** to the corresponding physical **GTP Channel Primitive** (e.g., `GTPE2_CHANNEL_X0Y...`). Without this, the design will not route correctly.

    The `LOC` alone is also **sufficient**: GT pads are dedicated, so each `GTPE2_CHANNEL` site fixes its own four RX/TX pins. The Vivado XDC files in this project therefore carry no `PACKAGE_PIN` constraints on the GT ports. (The openXC7 flow is the opposite case - nextpnr needs the pins and cannot take the `LOC`; see [`4.build/hw_build.openXC7`](../4.build/hw_build.openXC7/README.md#gt-channel).)

    **Procedure to identify the correct channel:**
    1.  **Schematic Check:** Consult the [NiteFury](https://github.com/RHSResearchLLC/NiteFury-and-LiteFury/tree/master) schematic to map the physical M.2 or PCIE connector pins to the specific FPGA **Package Pins**.
    2.  **Vivado Device View:** Open the **Device Window** in Vivado, locate those specific RX/TX package pins, and identify the **GTP Channel Primitive** associated with them.

    <div align="center">

    | Board Lane | RX pins (P / N) | TX pins (P / N) | GT Location | GTP channel in bank 216 (openXC7 numbering) | Used by |
    | :--- | :--- | :--- | :--- | :--- | :--- |
    | Lane 0 | B10 / A10 | B6 / A6 | X0Y6 | 2 | RC-switched |
    | Lane 1 | B8 / A8 | B4 / A4 | X0Y4 | 0 | |
    | Lane 2 | D11 / C11 | D5 / C5 | X0Y5 | 1 | RC-direct, EP |
    | Lane 3 | D9 / C9 | D7 / C7 | X0Y7 | 3 | |

    </div>

    Pin names are from AMD's package file [`xc7a200t-fbg484-package.txt`](../0.doc/xilinx/xc7a200t-fbg484-package.txt) ([source](https://www.xilinx.com/support/packagefiles/a7packages/xc7a200tfbg484pkg.txt)) (`MGTPRXP<n>_216` etc.). The checked-in designs are all x1: the four rows are the alternative physical positions for the single logical lane `[0]`.
    
> **Note:** The AMD XDC files in [`2.amd-rtl-with-Vivado-build`](../2.amd-rtl-with-Vivado-build) include a `LOC` block for all 4 positions; the one intended for the active topology is **uncommented**, the others stay **commented**. The opensource designs carry only the active `LOC`, as the one line of their variant XDC; all their other constraints are shared, in [`0.common.opensource/xdc`](0.common.opensource/xdc). Neither has GT pin constraints.
    
4.  **Visual Debug (LEDs):**
    Internal status signals—such as `user_lnk_up` or received data payloads—are mapped to the 4 onboard **User LEDs** (Pins **G3, H3, G4, H4**) to provide immediate visual feedback during testing.

----------
#### End-of-Document

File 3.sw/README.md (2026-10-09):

# RISC-V Bare-Metal PCIE Driver

This directory contains the C source code, startup assembly, and linker scripts required to build the **open-source driver** for the RISC-V Root Complex. This driver performs enumeration and memory transactions to act as the PCIE Host for the system.

## File Structure

What both Root Complex variants share is in [`common/`](common); each variant
folder holds only its own `main.c`:

| Directory | Contents |
| :--- | :--- |
| [`common/`](common) | `pcie.c` / `pcie.h`, `start.S`, `sections.lds` - used by both |
| [`RC-direct/`](RC-direct) | `main.c` for one Endpoint, straight RC-to-EP link |
| [`RC-switched/`](RC-switched) | `main.c` for the ASM1184e switch with up to 4 Endpoints behind it - see the [RC-switched README](../2.rtl/3.Bonus--RC-switched.opensource/README.md#2-firmware-the-bring-up-sequence) |

Both are built in [`4.build/sw_build`](../4.build/sw_build) (`make`, or `make VARIANT=switched`). The API and register map below are common to both; the enumeration sequence described further down is that of `RC-direct`.

*   **`common/pcie.c`, `common/pcie.h`**: the HAL and driver layer - register access, TLP send and Completion wait (with Completion Status and CRS retry), the configuration read/write helpers and BAR sizing.
*   **`main.c`**: the variant's application:
    *   **Enumeration:** device discovery, BAR placement, and the Command Register that enables the device. `RC-switched` also programs the switch's bus numbers and memory windows.
    *   **App:** a test that performs a Memory Write and Memory Read to the Endpoint and verifies the data integrity.
*   **`common/start.S`**: The assembly startup code. It initializes the Stack Pointer and jumps to the `main()` C function.
*   **`common/sections.lds`**: The Linker script. It maps the code and data to the FPGA's Block RAM (BRAM), starting at address `0x00000000` with a size of 8KB.

---

## **API Reference**

The driver exposes four high-level functions for interacting with the PCIE Endpoint. These functions abstract away the TLP packet construction and handshake logic.

### **1. Configuration Read**
**Reads a 32-bit value from the device's Configuration Space. Used primarily during enumeration to read Device IDs and Status registers.**

<div align="center">

| **Function Prototype** |
| :---: |
| `uint32_t pcie_cfg_read(uint32_t bus, uint32_t dev, uint32_t func, uint32_t reg, uint32_t *val);` |

</div>

*   **Parameters:**
    *   **bus, dev, func:** Target device topology (usually 1, 0, 0 for a direct connection).
    *   **reg:** The register offset (e.g., 0x00 for Vendor ID).
    *   **val:** **Receives the raw (byte-swapped) register value - written only on success.**
*   **Returns:** **The Completion Status: `CPL_STAT_SC` (0), `_UR` (1), `_CRS` (2, after 100 retries), `_CA` (4), or `CPL_TIMEOUT` (8).**
>*   **Example:** 
    > `if (pcie_cfg_read(1, 0, 0, 0x00, &id) == CPL_STAT_SC) ...`
*   **Note:** `main()` uses the wrappers `cfg_read32()` / `cfg_write32()`, which add the `bswap32()` and, for writes, stop with `0xBAD00002` on failure.

### **2. Configuration Write**
**Writes a 32-bit value to the Configuration Space. Used to configure BARs, enable Bus Mastering, and set Command registers.**

<div align="center">
  
| **Function Prototype** |
| :---: |
| `uint32_t pcie_cfg_write(uint32_t bus, uint32_t dev, uint32_t func, uint32_t reg, uint32_t val);` |

</div>

*   **Parameters:**
    *   **bus, dev, func:** Target device topology.
    *   **reg:** The register offset.
    *   **val:** **The 32-bit data to write.**
*   **Returns:** **The Completion Status, as for `pcie_cfg_read()`. A write answered with CRS is re-issued, like a read.**
>*   **Example:** 
   > `status = pcie_cfg_write(1, 0, 0, 0x10, 0xFFFFFFFF);`

### **3. Memory Write (32-bit)**
**Performs a Memory Write transaction to the mapped Base Address Register (BAR) space.**

<div align="center">
  
| **Function Prototype** |
| :---: |
| `void pcie_mem_write(uint32_t addr, uint32_t val);` |

</div>

*   **Parameters:**
    *   **addr:** **Target memory address (must be 4-byte aligned).**
    *   **val:** **The 32-bit data payload.**
*   **Note:** **This is a Posted Transaction, meaning the function sends the packet and returns immediately without waiting for a completion.**
>*   **Example:** 
   > `pcie_mem_write(0x80000000, 0x00000006);`

### **4. Memory Read (32-bit)**
**Performs a Memory Read transaction from the mapped BAR space.**

<div align="center">

| **Function Prototype** |
| :---: |
| `uint32_t pcie_mem_read(uint32_t addr, uint32_t *val);` |

</div>

*   **Parameters:**
    *   **addr:** **Target memory address.**
    *   **val:** **Receives the 32-bit data read from the Endpoint - written only on success.**
*   **Returns:** **The Completion Status, as for `pcie_cfg_read()`. All three non-posted calls share `pcie_request()`.**
>*   **Example:** 
    > `if (pcie_mem_read(0x80000000, &data) == CPL_STAT_SC) ...`

---

## Hardware Abstraction Layer (HAL)

The driver interacts with the custom PCIE Bridge RTL via **Memory Mapped I/O (MMIO)**. The C code writes to specific memory addresses that the hardware interprets as control registers.

### Register Map
The following addresses map directly to the RTL bridge inputs/outputs. With the default `CSR = peakrdl` (set in [`4.build/config.mk`](../4.build/config.mk)) `common/pcie.h` takes them from the generated `openpcie_regs.h`; with `CSR=legacy` it uses the same values hard-coded. Either way the map is the same - see [4.build/README.md](../4.build/README.md#the-register-map).

<div align="center">

| Register Name | Address | R/W | Description |
| :--- | :--- | :--- | :--- |
| `PCIE_TX_HEADER0` | `0x30000000` | W | TLP Header DW0 (Type, Fmt, Length). |
| `PCIE_TX_HEADER1` | `0x30000004` | W | TLP Header DW1 (Requester ID, Tag, Byte Enables). |
| `PCIE_TX_HEADER2` | `0x30000008` | W | TLP Header DW2 (Target Address or Bus/Dev/Func). |
| `PCIE_TX_DATA` | `0x3000000C` | W | **Write:** Data Payload. |
| `PCIE_RX_STATUS` | `0x30000010` | R | Completion Status (`0`=Success, `1`=UR, `2`=CRS, `4`=CA). |
| `PCIE_RX_DATA` | `0x30000014` | R | Data received from Memory Read Completions. |
| `PCIE_RX_HEADER_INFO`| `0x30000018` | R | **Completion Info:** Requester ID, Tag and Lower Address, for matching. |
| `PCIE_ERR_STATUS` | `0x3000001C` | R | **Error Status:** the hard macro's `cfg_status`, plus a flag for a received fatal-error Message. |
| `PCIE_PHY_STATUS` | `0x30000020` | R | Tx FSM state and the number of free hard-macro Tx buffers - polled before every send. |

</div>

---

## Driver Logic & Features

### 1. Robust TLP Transmission
Every non-posted request (config read, config write, memory read) goes through `pcie_request()`, which checks the **Completion Status** (SC / UR / CRS / CA) or reports a timeout, and passes read data back separately - so a genuine `0xFFFFFFFF` read is never mistaken for an error. A request answered with **CRS (Configuration Retry Status)** - read or write - is re-issued with a fresh tag up to 100 times. Any config request that fails after the device has been found stops the firmware with `0xBAD00002`.

### 2. Enumeration Sequence (in `main`)
The firmware performs a standard PCIE Bring-up sequence:
1.  **Wait:** Delays execution to allow the Physical Link to stabilize.
2.  **Discovery:** Reads the `Device ID` from Bus 1.
3.  **BAR Sizing:** With memory decoding off, writes `0xFFFFFFFF` to each of the six BARs and reads it back. `0` = BAR not implemented; bit 0 = I/O BAR (left unassigned, this RC has no I/O space); bits `[2:1] = 10` = 64-bit BAR, the next BAR is its upper half. Size = `~(readback & ~0xF) + 1`.
4.  **Assignment:** Places each memory BAR, aligned to its size, in the window `0x80000000 - 0xFFFFFFFF` (`RC-switched`: the 1 MB window of the endpoint's switch port). BAR0 lands at the window base - `0x80000000` for the AMD EP's 2 KB BAR0. A BAR that does not fit is parked out of the way (64-bit above 4 GB, 32-bit at 0); if that is BAR0, the firmware stops with `0xBAD00003`.
5.  **Enable:** Sets the **Bus Master** and **Memory Space** bits in the Command Register.

Configuration payloads travel big-endian on this RC (byte 0 of the register in bits `[31:24]`), so all config data goes through `bswap32()` and the values in the source read the way the spec prints them.

### 3. Self-Test & Debug Codes
The driver reports its execution status by writing specific "Magic Numbers" to the `PCIE_TX_DATA` register. These values serve as debug markers that can be monitored via the **Vivado ILA**.

<div align="center">

| Magic Number | Meaning |
| :--- | :--- |
| **`0x0000FACE`** | **PASS:** Data `0x6` was written and successfully read back. |
| **`0x0000DEAD`** | **FAIL:** Readback data did not match the written value, or the memory read was not completed with SC. |
| **`0xBAD00000`** | **ERROR:** Device ID read failed (Link down or device not found). In `RC-switched`: the switch upstream port did not answer. |
| **`0xBAD00001`** | **ERROR** (`RC-switched` only): the switch is up, but no Endpoint was found behind it. |
| **`0xBAD00002`** | **ERROR:** A config request to a device that had answered failed (UR, CA, timeout, or CRS after 100 retries). |
| **`0xBAD00003`** | **ERROR:** The Endpoint's BAR0 is not implemented, is an I/O BAR, or does not fit the window. |

</div>

----------------
#### End-of-Document

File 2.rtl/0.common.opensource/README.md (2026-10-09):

# Opensource RC: shared RTL

The two opensource Root Complex designs,
[RC-direct](../2.RC-direct.opensource) and
[RC-switched](../3.Bonus--RC-switched.opensource), are built from the very same
RTL. It lives here, once.

```
src/
  RC_opensource.sv              top level: refclk buffer, PCIE bridge, SOC, LEDs
  riscv_pcie_soc.sv             picorv32 SOC, drives the AXI-Stream TLP interface
  soc_csr.sv                    wrapper for the PeakRDL-generated CSR block
  picorv32.CHILI.sv             the RISC-V core (Chili.CHIPS-improved picorv32)
  pcie/                         the opensource PCIE stack
xdc/
  RC.sv.x1g2.AcornCLE-215P.xdc  constraints, all but the GT lane (source of truth)
RC.opensource.tcl               the Vivado project script behind both wrappers
```

What stays in each variant's own folder is only what really differs:

| | RC-direct | RC-switched |
|---|---|---|
| GT lane (one-line XDC) | `GTPE2_CHANNEL_X0Y5` | `GTPE2_CHANNEL_X0Y6` |
| Vivado project | `RC-direct.opensource.tcl` -> `xbuild.Vivado-v2024.2/` | `RC-switched.opensource.tcl` -> `xbuild.Vivado-v2024.2/` |
| Firmware | [`3.sw/RC-direct`](../../3.sw/RC-direct) | [`3.sw/RC-switched`](../../3.sw/RC-switched) |

`riscv_pcie_soc.sv` picks Type 0 or Type 1 for every Configuration TLP from the
target bus number - Type 1 beyond bus 1, as a switch needs. The RC-direct
firmware addresses its endpoint on bus 1, so for it every request stays Type 0.

The PCIE stack is described file by file in the
[RC-direct README](../2.RC-direct.opensource/README.md#the-pcie-stack-by-layer),
the switch handling in the
[RC-switched README](../3.Bonus--RC-switched.opensource/README.md#what-differs-from-rc-direct).
The same sources also feed the [openXC7 build](../../4.build/hw_build.openXC7)
and the [co-simulation](../../5.sim).

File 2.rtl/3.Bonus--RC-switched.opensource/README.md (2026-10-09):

# Opensource RC-switched core (bonus)

This is an opensource variant of what was first tested with the
[AMD-proprietary RC-switched IP stack](../../2.amd-rtl-with-Vivado-build/3.Bonus--RC-switched.amd).
It is an extra / bonus deliverable, above and beyond our original plans.

- [x] ✔️ Hardware FSM replaced with an opensource RISC-V based SOC
- [x] ✔️ PCIE IP core replaced with opensource RTL
- [x] ✔️ Builds with a **fully opensource toolchain**
- [x] ✔️ Enumerates an ASM1184e switch and the endpoints behind it
- [x] ✔️ SOC uses PeakRDL for CSR generation, from the same `csr.rdl` as RC-direct

The objectives of this dev track were to:
 - first design an opensource _RC-switched_ core, based on the already tested
   and familiarized with proprietary core
 - then validate and showcase its operation in a Switched PCIE context,
   repeating the test procedure used for the AMD solution.

With both this indirect/switched and [RC-direct](../2.RC-direct.opensource)
use-cases tried and proven, we have a nicely rounded set of opensource cores
and examples -- a solid foundation for the makers to build their future
applications upon...

---

## Status

| | |
|---|---|
| Target device | `xc7a200tfbg484-3`, Acorn CLE-215P |
| Switch | ASM1184e, 1 upstream + 4 downstream ports |
| Link | PCIE Gen2 x1 |
| Vivado build | works |
| Opensource build | works - see [`4.build/hw_build.openXC7`](../../4.build/hw_build.openXC7) |

Link width and speed come from a single place,
[`link_pkg.sv`](../0.common.opensource/src/pcie/link_pkg.sv) -- shared with
[RC-direct](../2.RC-direct.opensource), so a change applies to both:

```systemverilog
localparam int PCIE_LANES = 1;   // 1, 2, 4 or 8
localparam int PCIE_GEN   = 2;   // 1 = Gen1, 2 = Gen2
```

The corresponding hardware setup is
[here](../../1.pcb#usecase-2-switched-fpga_rc-to-fpga_ep-gen2-x1). Note that the
ASM1184e on the RevA backplane is fed by an undersized LDO - see slide 17 of the
[presentation](../../1.pcb/0.doc). RevB replaces it with a DC/DC buck.

---

## What differs from RC-direct

In the RTL: nothing. RC-direct and RC-switched are built from the very same
sources in [`0.common.opensource`](../0.common.opensource) - one top
(`RC_opensource`), one SOC, one PCIE stack. A switch changes nothing at
the physical or link layer; the root port still trains a plain Gen2 x1 link, and
what it talks to on the far end happens to be a switch upstream port instead of
an endpoint. Everything that changes is one level up, in how Configuration TLPs
are addressed - which the shared SOC handles for both, and the firmware drives.

### 1. RTL: Type 0 / Type 1 selection (`riscv_pcie_soc.sv`)

In a direct connection the endpoint always sits on bus 1, so every Configuration
request is a **Type 0** one. Behind a switch the requests have to cross virtual
PCI-to-PCI bridges, and those only forward **Type 1** requests.

The AMD design solves this inside `cgator_pkt_generator.v`:

```verilog
wire [7:0] pkt_bus_num;
wire [4:0] pkt_dev_num;
assign cfg_type_code = (pkt_bus_num > 8'd1) ? 5'b00101 : 5'b00100;
```

`pkt_bus_num` / `pkt_dev_num` had to be introduced there because in the AMD
stack the packet generator builds the header itself and the target was
hardcoded; the controller now feeds it the bus and device number of every single
transaction out of the configuration ROM.

Here the SOC bridge in `riscv_pcie_soc.sv` **is** the packet generator, and the
device number already travels in the address dword the firmware wrote. So only
the bus number is picked back out of the header, and only the Type bit is
overridden:

```systemverilog
assign pkt_bus_num       = tx_header2[31:24];
assign pkt_is_cfg        = (tx_header0[28:25] == 4'b0010);
assign tx_header0_routed = pkt_is_cfg
                         ? {tx_header0[31:25], (pkt_bus_num > 8'd1), tx_header0[23:0]}
                         : tx_header0;
```

`Fmt`/`Type` sits in `tx_header0[31:24]`; `[28:25] == 4'b0010` marks a
Configuration request and bit `[24]` is the Type 0 / Type 1 selector. Memory and
Completion TLPs pass through untouched.

This logic is in the shared SOC, so RC-direct carries it too. There it never
acts: the direct firmware addresses its endpoint on bus 1, which is a Type 0
request either way. What does differ between the two projects:

* The GT lane. This folder's XDC holds one line, locking the transceiver to
  `GTPE2_CHANNEL_X0Y6` (RC-direct: `X0Y5`); all other constraints are shared -
  see the lane table in [`2.rtl/README.md`](../README.md#common-physical-constraints-xdc).
* The firmware, below.

### 2. Firmware: the bring-up sequence

The AMD design drives the sequence from a 46-entry ROM
(`cgator_cfg_rom.data`). Here it is plain C, in
[`3.sw/RC-switched/main.c`](../../3.sw/RC-switched/main.c) on top of the PCIE
request layer both firmwares share ([`3.sw/common`](../../3.sw/common)), and it walks the same
steps in the same order, producing the same bus map:

```
bus 0 .............. Root Complex
 |
bus 1  dev 0 ....... ASM1184e upstream port      (pri 1, sec 2, sub 6)
 |
bus 2  dev 1 ....... downstream port 1 --> bus 3, window 0x10000000
       dev 3 ....... downstream port 2 --> bus 4, window 0x10100000
       dev 5 ....... downstream port 3 --> bus 5, window 0x10200000
       dev 7 ....... downstream port 4 --> bus 6, window 0x10300000
 |
bus 3..6  dev 0 .... the endpoint cards, BAR0 at the window base
```

* **Step 1 - switch upstream port.** Bus numbers (primary 1, secondary 2,
  subordinate 6), one memory window `0x10000000 - 0x103FFFFF` covering
  everything behind the switch, then Memory Space + Bus Master.
* **Step 2 - the four downstream ports** on the internal bus 2. Each is a
  virtual bridge, gets its own secondary bus and its own 1 MB slice of the
  upstream window.
* **Step 3 - the endpoints**, device 0 on buses 3..6. Every BAR is sized
  (write all ones, read back, decode the 32/64-bit type) and placed, aligned to
  its size, inside the 1 MB window its port forwards - put it anywhere else and
  the port drops every memory request aimed at it. BAR0 therefore lands at the
  window base. A BAR0 larger than the window is reported, not squeezed in; any
  other BAR that does not fit is parked out of the way (64-bit above 4 GB,
  32-bit at 0).
* **Step 4 - self test.** Memory write and readback through the switch for each
  populated slot, then `0x0000FACE` / `0x0000DEAD` to `PCIE_TX_DATA`, as in the
  direct build.

Two things worth knowing when comparing the C against the AMD ROM dump:

* Configuration payloads travel **big-endian** - byte 0 of the register ends up
  in bits `[31:24]` of the data dword. Both firmwares make the swap explicit in
  `bswap32()`, so the register values are written the way the spec prints them
  (BAR `0x10000000`, not `0x00000010`).
* The ROM writes `0x103F` into a memory-limit field where this firmware writes
  `0x1030`. Bits `[3:0]` of the Memory Limit register are read-only, so the two
  land the same value in the switch.

Unlike the ROM, the firmware **probes each slot** before configuring it and
skips the empty ones, so a partially populated backplane is fine. It reports

| Marker | Meaning |
|---|---|
| `0x0000FACE` | every endpoint that was found passed its readback |
| `0x0000DEAD` | an endpoint failed its readback |
| `0xBAD00000` | the switch upstream port did not answer at all |
| `0xBAD00001` | the switch is up, but no endpoint was found behind it |
| `0xBAD00002` | a config request to a device that had answered failed (UR, CA, timeout, or CRS after 100 retries) |
| `0xBAD00003` | an endpoint's BAR0 is not implemented, is I/O, or is larger than its 1 MB port window |

Every request's Completion Status is checked; config reads **and** writes
answered with CRS are re-issued up to 100 times.

---

## Structure

```
2.rtl/0.common.opensource/        shared by both root complexes
  src/
    RC_opensource.sv              top level: refclk buffer, PCIE bridge, SOC, LEDs
    riscv_pcie_soc.sv             picorv32 SOC + the Type 0/Type 1 routing above
    soc_csr.sv                    wrapper for the PeakRDL-generated CSR block
    picorv32.CHILI.sv             the RISC-V core (Chili.CHIPS-improved picorv32)
    pcie/                         the opensource PCIE stack
  xdc/
    RC.sv.x1g2.AcornCLE-215P.xdc  constraints, all but the GT lane (source of truth)
  RC.opensource.tcl               the Vivado project script behind both wrappers

2.rtl/3.Bonus--RC-switched.opensource/   this folder
  xdc/
    RC-switched.sv.x1g2.AcornCLE-215P.xdc  GT lane: GTPE2_CHANNEL_X0Y6
  RC-switched.opensource.tcl      regenerates the Vivado project from scratch
```

For a file-by-file walk through the PCIE stack, see the
[RC-direct README](../2.RC-direct.opensource/README.md), which applies here
unchanged.

### The CSR

The register window the firmware drives (`0x3000_0000` in the SOC address map)
is **generated**, not hand-written. The source of truth is a SystemRDL file,
[`4.build/csr_build/csr.rdl`](../../4.build/csr_build/csr.rdl), out of which
`peakrdl` produces the register block RTL (`csr_pkg.sv`, `csr.sv`) and the
software headers (`csr.h`, `csr_hw.h`, `csr_cosim.h`) in
`4.build/csr_build/generated-files/`. `soc_csr.sv` is the only hand-written
piece: it bridges the picorv32 native memory interface to the "passthrough" CPU
interface of the generated block.

Regenerate after every edit of `csr.rdl`:

```bash
cd ../../4.build && make -f MakefileCSR
```

The original hand-written register block is still in `riscv_pcie_soc.sv`, behind
`` `ifdef SOC_CSR_LEGACY ``. Which one gets built is set once, in
[`4.build/config.mk`](../../4.build/config.mk), and read by every build step, so
hardware and software are never built different ways. Override it for a single
run with `make CSR=legacy` (openXC7 or firmware) or `set ::use_legacy_csr 1`
before sourcing the tcl (Vivado).

The two are functionally identical, down to the byte offsets. Nothing about the
CSR differs between this variant and RC-direct - the same `csr.rdl` feeds both.
Details: [`4.build/README.md`](../../4.build/README.md#csr-hal-compilation).

---

## Building

Build the firmware first - `firmware.hex` is a hard dependency of both flows,
and it has to be the **switched** one:

```sh
cd 4.build/sw_build
make VARIANT=switched
```

No `make clean` is needed to switch variants - every `make` there rebuilds the
firmware from scratch (about a second).

### Vivado

```tcl
source RC-switched.opensource.tcl
```

The generated project lands in `xbuild.Vivado-v2024.2/`.

### Opensource

```sh
cd 4.build/hw_build.openXC7
make VARIANT=switched
```

Output goes to `build_artifacts.switched/top.bit`, kept separate from the direct
build. See [`4.build/hw_build.openXC7`](../../4.build/hw_build.openXC7) for the
toolchain requirements - in particular, the nextpnr-xilinx version is critical.

----
End-of-Document

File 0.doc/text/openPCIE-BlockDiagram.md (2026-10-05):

<!-- Generated text version of `1.pcb/0.doc/openPCIE-BlockDiagram.drawio` (draw.io text labels) so the website assistant can read it. Do not edit by hand; regenerate from the source. -->

# openPCIE backplane block diagram (text labels)

The diagram itself is graphical; these are its text labels, page by page.

## PCIE-topology

- General PCIE topology
- PCIEx1 pinout

## openPCIE2

- --- openPCIE backplane ---
- July 27, 2025
- RC44-lane RC connector with mechanical option: / - M.2 (PCIE)
- 4-lane "Direct" island / RC4 => EP4
- EP44-lane EP connector with mechanical option: / - Slot
- 4 lanes
- The "RC Connectors" are for the plug-in cards that are natively EP.
- 1-lane "Switched" islandRC1=>SW=>SW_EP0/1/2/3
- RC11-lane RC connector with mechanical option: - Slot
- The backplane job is to swap the connector pins so that the Tx diff.pair on one side of the link is connected to the Rx diff.pair on the other side, and vice-versa. This allows the same FPGA plug-in card, which is always pined-out to serve as an EP, to be used in both EP and RC roles.
- 1 lane
- SWitch / PCIE2.1 / 1-lane / 1-to-4
- 4 x / 1 lane
- 1-lane EPconnector / - Slot
- 1-lane EPconnector / - M.2 (PCIE)
- SW_EP0
- SW_EP1
- SW_EP2
- SW_EP3
- cca 10W per slot70W total
- differential REFCLK_P/N
- 6-pin PCIE Power connector(3x12V, 3xGND)
- DC/DC Buck and LDOs for power distribution
- ...
- Reset Generator / - PowerOn reset (3V3) / - manual push-button / - distribution buffers
- PERST#
- 100MHz PCIE-class REFCLK Generator / - 25MHz oscillator / - PLL / - series-terminated / distribution buffers
- CLKREQ#

## openPCIE3-AsMedia

Note: discovery-stage option for a follow-up Gen3 board. A 20-lane ASMedia-based design was considered, but a 24-lane Diodes Incorporated PCIe Gen3 switch was found more suitable and was selected for the planned openPCIE Gen3 extension card (four Gen3 x4 downlinks, two Gen3 x4 OCuLink ports).

- --- openPCIE3 backplane ---
- cca 10W per slot70W total
- differential REFCLK_P/N
- 6-pin PCIE Power connector(3x12V, 3xGND)
- DC/DC Buck and LDOs for power distribution
- ...
- Reset Generator / - PowerOn reset (3V3) / - manual push-button / - distribution buffers
- PERST#
- 100MHz PCIE-class REFCLK Generator / - 25MHz oscillator / - PLL / - series-terminated / distribution buffers
- CLKREQ#
- Dec.22, 2025
- - x4 / 42P -
- RC1
- 4-lane
- SWitch / PCIE3.1 / 24-lane / 12-port
- 4 x 4-lane
- 4-lane EPconnector / - Slot
- 4-lane EPconnector / - M.2 (PCIE)
- SW_EP0
- SW_EP1
- SW_EP2
- SW_EP3
- RC2
- OCuLink SFF-8612 (female/board side) / - x8 / 80Pin -

## openPCIE3-Diodes

- --- openPCIE3 backplane ---
- Feb.27, 2026
- - x4 / 42P -
- PC1-EPEP pinout / Oculink provides REFCLK and RESET
- 4-lane
- SWitch / PCIE3.1 / 24-lane / 12-port
- 4 x 4-lane
- 4-lane EPconnector / - Slot
- 4-lane EPconnector / - M.2 (PCIE)
- SW_EP0
- SW_EP1
- SW_EP2
- SW_EP3
- PC2-EPEP pinout / Oculink provides REFCLK and RESET
- OCuLink SFF-8612 (female/board side) / - x8 / 80Pin -
- PI7C9X3G / 1224GPB
- cca 10W per slot70W total
- 6-pin PCIE Power connector(3x12V, 3xGND)
- DC/DC Buck and LDOs for power distribution
- ...

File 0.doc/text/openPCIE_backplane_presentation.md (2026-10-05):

<!-- Generated text version of `1.pcb/0.doc/OpenPCIE backplane presentation.pptx` (slide text; images omitted) so the website assistant can read it. Do not edit by hand; regenerate from the source. -->

# openPCIE backplane presentation

Prototype bring-up story: topology, layout, manufacturing, factory tests, the CLKREQ# problem, the switch overheating fix and next steps.

## Slide 1
- Openpcie
- backplane

## Slide 2
- Functionality and   Topology
- Two Logical Islands:
- 4-lane "Direct" connection
- 1-lane "Switched" connection
- Supports standard PCIe Slots and M.2 connectors
- Single 6-pin PCIe power connector
- Integrated 100 MHz clock and reset distribution
- Same FPGA plug-in card can act as EndPoint (EP) or Root Complex (RC)

## Slide 3
- KiCad PCB Layout
- Designed in KiCad
- 4-Layer Stackup:
- Top: Microstrip for diff pairs
- L2: Ground plane
- L3: 3.3V Power plane
- Bottom: Microstrip for diff pairs
- Careful routing to minimize stubs and skew

## Slide 4
- 3D View
- 3D visualization of the openPCIE backplane

## Slide 5
- Manufacturing and Testing Preparation
- PCB manufacturing by Elecrow (5 prototypes)
- Created a PCBA Functional Test Procedure
- Testing basic power, reset, and clock generation

## Slide 6
- Factory Test Results
- Factory tests passed successfully
- Clock (25MHz, 100MHz ) and voltages (1.8V, 12V, 3.3V, 1.2V) verified

## Slide 7
- Boards Arrival
- Prototypes arrived in Sarajevo
- Ready for hardware validation

## Slide 8
- Starting the Tests (Direct Connection)
- Phase 1: Testing the Direct Connection (RC to EP)
- Inserting the FPGA cards

## Slide 9
- The CLKREQ Problem
- The Problem: CLKREQ# signal
- Clock generator requires CLKREQ to be pulled to GND
- Assumption: most M.2 to PCIe adapters route this signal to the M.2 connector, allowing the FPGA to pull it to Ground.

## Slide 10
- History of CLKREQ
- CLKREQ# was introduced in Revision 4 of the PCIe electromechanical specification in late 2018
- Previously, pin B12 was marked as "Reserved"
- Older adapters do not connect this pin

## Slide 11
- Temporary Fix
- First Attempt: put a simple wire between CLKREQ and Ground.
- Issue: Created an inductive loop/antenna near tx0
- Resulted in an unstable link on Lane 0

## Slide 12
- Better Solution: Solder bridge between CLKREQ and GND
- Clock is only active when needed
- Pin layout is perfect for a simple solder bridge:
- The Ground pin is right next to the CLKREQ pin
- The CLKREQ is the last pin on the left side of the connector
- The Permanent Fix

## Slide 13
- Verification Environment
- Dual-PC Setup:
- PC 1: Connected to RC FPGA via JTAG
- PC 2: Connected to EP FPGA via JTAG
- Speed and Efficiency: No manual swapping of JTAG cables and no time-consuming flashing
- Simultaneous Debugging: Run two Vivado Logic Analyzers at the same time

## Slide 14
- Test Objective and Results
- Objective: Verify Link Enumeration, Memory Write, and Memory Read
- Write: RC sends a data payload (Decimal 6) to EP
- Transfer: EP writes it into internal Block RAM
- Read: RC reads the data back
- Result: Successful link (LED is ON) and data matches (0110 binary)

## Slide 15
- Switch Testing
- Moving from Direct connection to the PCIe Switch
- Inserting boards into the 1-to-4 Switch topology

## Slide 16
- The Switch Overheating Problem
- New Problem: One area of the board board was getting extremely hot.
- Switch was too hot to touch; link was highly unstable
- Temporary fix: Added a heatsink and fan
- Investigation: Thermal camera revealed the real issue (1.2V LDO)

## Slide 17
- Thermal Camera Analysis
- Thermal camera shows LDO at 90°C
- Switch pulls up to 2 Watts
- LDO cannot handle this power dissipation, so it was overheating.

## Slide 18
- Ordered a DC-DC Step-Down Power Module
- Input: 2.5-6V | Output: 1.2V Voltage Regulator
- Manual installation for testing
- Testing the Buck Converter

## Slide 19
- Manual Board Modification
- Lifted the LDO leg to disconnect it
- Wired the new DC-DC Buck converter to the board

## Slide 20
- Temperature Results
- Temperature dropped to ~45°C
- Stable communication restored
- Second batch: LDO will be replaced by a Buck converter

## Slide 21
- Fully Populated Switch
- Fully populated PCIe switch setup

## Slide 22
- Improvements for the Second Batch
- Updates for the next PCB revision:
- Open-end PCIe slots (allows x4 cards in x1 slots)
- Add power switch for the main 12V supply line
- Replace LDO with DC-DC Buck converter
- Add CLKREQ shunt on the backplane
- Other minor improvements

## Slide 23
- Thank you for your attention!

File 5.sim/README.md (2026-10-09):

# openPCIE Simulation Top Level Test Bench

## Table of Contents

* [Introduction](#introduction)
* [Test Bench Structure](#test-bench-structure)
  * [The PIPE PHY model](#the-pipe-phy-model)
  * [Endpoint feature limitations](#endpoint-feature-limitations)
  * [Prerequisites on Windows](#prerequisites-on-windows)
  * [What the simulation does](#what-the-simulation-does)
  * [Building and running](#building-and-running)
  * [Viewing the TLPs in WaveCrux](#viewing-the-tlps-in-wavecrux)
  * [Viewing the PIPE in WaveCrux](#viewing-the-pipe-in-wavecrux)
  * [How long a TLP spends in the hard macro](#how-long-a-tlp-spends-in-the-hard-macro)
* [The three CPU options](#the-three-cpu-options)
  * [What they cost](#what-they-cost)
* [Auto-selection of soc_cpu Component](#auto-selection-of-soc_cpu-component)
* [_VProc_ Software](#vproc-software)
  * [Other Software Use Cases](#other-software-use-cases)
    * [Natively Compiled Application](#natively-compiled-application)
    * [RISC-V Compiled Application](#risc-v-compiled-application)
* [Building and Running Code](#building-and-running-code)
  * [Configuring ISS timing model](#configuring-iss-timing-model)
  * [Running ISS code](#running-iss-code)
    * [The openPCIE configuration](#the-openpcie-configuration)
* [PicoRV32 RTL-Only Simulation](#picorv32-rtl-only-simulation)
* [Debugging Code](#debugging-code)
  * [Natively Compiled Code](#natively-compiled-code)
  * [ISS Software](#iss-software)
* [The mem_model Co-Simulation Sparse Memory Model](#the-mem_model-co-simulation-sparse-memory-model)
* [Driving the PCIE Link](#driving-the-pcie-link)
* [Co-simulation HAL](#co-simulation-hal)
  * [Using the HAL](#using-the-hal)
  * [Other Co-simulation considerations](#other-co-simulation-considerations)
* [References](#references)

## Introduction

The *openPCIE* top level test bench is based around the [*pcievhost*](https://github.com/wyvernSemi/pcievhost) PCIE 2.0 verification co-simulation IP in order to drive the DUT's PCIE link. This is a C model for generating PCIE 1.1 and 2.0 traffic data connected to the logic simulation using the [*VProc*](https://github.com/wyvernSemi/vproc) virtual processor co-simulation element. _VProc_ allows a user program to be compiled natively on the host machine and 'run' on an instantiated HDL component in a logic simulation, including running the PCIE C model. _VProc_ has a generic memory mapped master bus for generating read and write transactions and a Bus Functional Model (BFM) wrapper encapsulates the _VProc_ component and effectively memory maps the PCIE ports into the address space, allowing software to drive and read these ports and interface with the PCIE C model. Although originally designed as a root complex model, the _pcievhost_ component has <ins>some</ins> endpoint features, enabled by setting a parameter. The endpoint features are [limited](#endpoint-feature-limitations) and were originally designed just as a target for the main root complex model to be tested.

The diagram below is a block diagram of the top level test bench showing the main features.

<p align=center>
openPCIE Root Complex test bench structure
</p>

The DUT PCIE link is connected to the _pcievhost_, instantiated in a wrapper x1 PIPE link (`pcieVHostPipex1.v`) configured as an endpoint, and running some user code  to generate PCIE traffic as required, though it will automatically respond to transactions requiring a completion. The model is capable of displaying link traffic on both the up- and downstream links to the console, configurable via a `ContDisps.hex` file. To drive the DUT's memory mapped slave bus, a _VProc_ component is used with a BFM wrapper for the specific bus protocol used for the device&mdash;in this case PCIE. A program can then be run on the virtual processor to access the device's memory mapped registers etc. and update the TX link signals and read from the RX link signals.

The user software to run on the virtual processor is the means to configure the model, such as setting the config space register settings, doing the required link initialisation, and any further modelling of a specific Endpoint implementation. That software is [`usercode/VUserMain1.cpp`](usercode/VUserMain1.cpp): it builds a Type 0 configuration space with PCIE, MSI and Power Management capabilities, and calls `initFc()` to bring up flow control. What it does not model is device behaviour behind the BARs - see [Endpoint feature limitations](#endpoint-feature-limitations).

## Test Bench Structure

The test bench drives the **real** Root Complex RTL. `tb.sv` instantiates
`RC_opensource` out of `2.rtl/0.common.opensource` -- the same top level that
goes into both bitstreams, RC-direct and RC-switched -- and the whole design
comes along with it:

```
tb.sv
 |
 +- RC_opensource                                   2.rtl/0.common.opensource/src/
      |
      +- host_bridge                                real RTL
      |    +- clk_synth       MMCM                  real RTL
      |    +- txn_engine                            real RTL
      |    |    `- silicon_core -> PCIE_2_1         Xilinx hard macro (secureip)
      |    `- serdes_front    <-- REPLACED -->      5.sim/models/serdes_front.PIPE.sv
      |                                                +- PIPE PHY model
      |                                                `- pcieVHostPipex1 (endpoint,
      |                                                   VProc node 1, VUserMain1.cpp)
      `- riscv_pcie_soc                             real RTL
           +- picorv32                              real RTL, runs firmware.hex
           `- soc_csr -> csr                        PeakRDL-generated CSR
```

Exactly **one** RTL file is swapped for the simulation, and one file is copied in:

| Item | Why |
|---|---|
| `serdes_front.sv` becomes `models/serdes_front.PIPE.sv` | the 7-series GTP transceiver turns PIPE symbols into a 5 GT/s serial stream; _pcievhost_ models the link at PIPE symbol level, so the transceiver has to come out |
| `firmware.hex` copied into `5.sim/` | `riscv_pcie_soc.sv` reads it with `$readmemh` and a bare file name |

Everything else -- the hard macro, the transaction layer, the CPU, the CSR and
the firmware -- is what goes into the FPGA. The swap needs no `ifdef` in the
design: the module name and port list match, so the simulation file list
(`tb.prj`) simply picks the other file. (The CPU swap for `CPU=vproc` /
`CPU=iss` is different - that one *is* an `` `ifdef SOC_CPU_VPROC `` in
`riscv_pcie_soc.sv`, see [The three CPU options](#the-three-cpu-options).)

Three simulation-only parameters ARE selected with defines, all set only in
`5.sim/Makefile` and never by either synthesis flow:

| Define | Effect | Why |
|---|---|---|
| `SIM_FAST_TRAIN` | `PL_FAST_TRAIN = "TRUE"` on the hard macro (`silicon_core.sv`) | shortens the LTSSM training timers. This is a simulation feature of the macro -- with the real 12/24 ms timers link training is longer than any practical run |
| `SIM_GEN1_ONLY` | `PCIE_GEN = 1` (`link_pkg.sv`) | the endpoint VIP advertises Gen1 and its LTSSM helper cannot follow a Gen1 to Gen2 retrain |
| `SIM_PIPE_CODING` | `DISABLE_SCRAMBLING = "TRUE"` on the hard macro (`silicon_core.sv`) | matches how the endpoint VIP is configured over PIPE |

### The PIPE PHY model

`models/serdes_front.PIPE.sv` stands in for the transceiver and carries the link
partner on its far side. It provides the three things the `PCIE_2_1` LTSSM needs
from a PHY:

* **PHYSTATUS pulses** on exit from PIPE reset, on every power-state change and
  on every rate change
* **Receiver detection** -- a PHYSTATUS pulse together with `RXSTATUS = 3'b011`
  in response to `TXDETECTRX`, which is what lets the LTSSM leave Detect
* **RXVALID / RXELECIDLE**, asserted from the first K character the partner
  sends, standing in for a squelch detector

It also generates the clocks. `TXOUTCLK` is a behavioural 100 MHz oscillator and
everything downstream is the real `clk_synth` MMCM, so the design sees its normal
clock topology: PCLK at 125 MHz (Gen1) or 250 MHz (Gen2), USERCLK1/2 at 62.5 MHz.
**The 100 MHz matters**: `clk_synth` is parameterised with `CLKIN1_PERIOD = 10 ns`
and `CLKFBOUT_MULT_F = 10`, so any other input frequency scales every clock in
the design, and the PIPE then over- or under-samples the link partner. Feeding it
125 MHz, for instance, makes PCLK 156.25 MHz and duplicates one symbol in five.

Two trace facilities are built in, both behind defines:

```
make USRSIMOPTS="--define PIPE_OS_TRACE"    # ordered sets, both directions, with link/lane numbers
make USRSIMOPTS="--define PIPE_RAW_DUMP"    # raw PIPE symbols
```

The LTSSM state is printed on every transition without any define, and `tb.sv`
reports `phy_lnk_up`, `trn_lnk_up`, `user_lnk_up` and `user_reset` as they change.

### Endpoint feature limitations

_pcievhost_ was written as a root complex model, and its endpoint side is a
parameter on top of that -- `EndPoint = 1`, set where the model is instantiated
in `models/serdes_front.PIPE.sv`. It is enough to train a link and answer
Configuration and Memory requests, which is exactly what testing a root complex
needs, but it is not a device model. What it does and does not give you:

**What it provides**

* A configuration space, built by [`usercode/VUserMain1.cpp`](usercode/VUserMain1.cpp)
  through `writeConfigSpace()` / `writeConfigSpaceMask()`: a Type 0 header
  (vendor `0x14fc`, device `0x0002`), and PCIE, MSI and Power Management
  capability structures. The mask calls are what make the read-only bits behave
  as read-only.
* Automatic completions for Configuration and Memory requests, with Memory
  traffic landing in the
  [sparse memory model](#the-mem_model-co-simulation-sparse-memory-model).
* A full LTSSM, flow control initialisation and DLLP handling.

**What it does not**

* **No device behaviour behind the BARs.** A memory write is stored and a read
  returns it; nothing interprets the data, so there is no DMA, no interrupt
  generation and no application logic to test against.
* **No error injection.** Malformed TLPs, completion timeouts, retries and CRS
  storms have to be provoked by editing the model, not by configuration.
* **One lane.** The wrapper used here is `pcieVHostPipex1`, x1 with a 16-bit
  PIPE datapath. Wider links need a different wrapper.
* **The endpoint LTSSM paths were the least exercised part of the model**, since
  its usual job is to be the root complex. Three of them turned out to be wrong
  when driven by real silicon rather than by another copy of the same VIP. The
  fixes are in `models/pcievhost/ltssm/ltssm.c`, with the original kept beside
  it as `ltssm.c.orig`.

For a link partner with real device behaviour the alternative is an RTL
endpoint, which the project points at in
[`2.rtl/1.EP.opensource`](../2.rtl/1.EP.opensource). That costs the decoded
protocol logging and the controllability this model gives, so the two are
complementary rather than interchangeable.

### Prerequisites on Windows

Do this once, before anything below will work. The commands to actually build
and run are further down, in [Building and running](#building-and-running).

**1. Use the right shell.** The C/C++ side needs a MinGW toolchain and the HDL
side needs Vivado's `xsim`. Both work, but **only from a properly launched MSYS2
MinGW64 shell** -- `C:\msys64\mingw64.exe`, or `msys2_shell.cmd -mingw64`.

> `cmd.exe` and PowerShell have no `make` and no `gcc`. Git Bash has neither
> either. And Vivado's `xvlog`, `xelab` and `xsim` launchers go through
> `/usr/bin/cmd`, which needs the environment that shell sets up -- started from
> a foreign shell they fail **silently**, with a non-zero exit and no output at
> all. If a build seems to do nothing, this is why.

Paths in that shell are POSIX: `C:\Users\you\openPCIE` is `/c/Users/you/openPCIE`.

**2. Add one MSYS2 package:**

```bash
pacman -S mingw-w64-x86_64-dlfcn        # VProc.h includes <dlfcn.h>
```

**3. Put the tools on PATH.** A stock MinGW64 shell has `gcc`, `make` and
`python3`, but **not** Vivado, the RISC-V compiler or `peakrdl` -- those are
installed outside MSYS2 and have to be added. Adjust the paths to your install:

```bash
export PATH=$PATH:/c/Xilinx/Vivado/2025.1/bin
export PATH=$PATH:/c/rv/xpack-riscv-none-elf-gcc-15.2.0-1/bin
export PATH=$PATH:/c/Users/you/AppData/Local/Programs/Python/Python312/Scripts
```

Append those three lines to `~/.bashrc` and they are set for every new shell.
Check with:

```bash
command -v make gcc riscv-none-elf-gcc xvlog
```

All four must print a path. (`peakrdl` is only needed if you edit `csr.rdl` --
see [4.build/README.md](../4.build/README.md#csr-hal-compilation).)

The make file separately puts `TMP`, `TEMP` and `TMPDIR` back, because GNU make
on MSYS2 hands its recipes a shell with all three unset and gcc then tries to
write its temporaries into `C:\WINDOWS\`.

### What the simulation does

A full run takes the design from power-up to a verified memory transaction, with
no hardware involved (this run used `RUN_US=3000`; the default is 2000):

```
                   0  TB     run length 3000 us
              353000  LTSSM  0xxx -> 0x00 DETECT_QUIET
             1000000  TB     PERST# released
             3113000  LTSSM  0x00 -> 0x02 POLLING_ACTIVE
             3353000  LTSSM  0x02 -> 0x04 POLLING_CONFIGURATION
             4585000  LTSSM  0x04 -> 0x05 CONFIG_LINKWIDTH_START
            70217000  LTSSM  0x05 -> 0x26      <- link number assigned
            71161000  LTSSM  0x2a -> 0x2b      <- lane number assigned
            72065000  LTSSM  0x2c -> 0x11      <- Configuration complete
            73609001  TB     phy_lnk_up   = 1  <- physical layer up
            73689000  TB     user_reset   = 0
            74033000  LTSSM  0x15 -> 0x16 L0  (linkup)
            74825001  TB     trn_lnk_up   = 1  <- data link layer up, flow control done
            74841000  TB     ===> PCIe LINK UP -- SOC released from reset
           653961000  TB     ===> FIRMWARE RESULT 0x0000face  (PASS)

 openpcie2-rc co-simulation summary
  PCIe link up ............ YES
  LTSSM final state ....... 0x16
  cfg_status .............. 0x0000
  TLPs sent by firmware ... 22
  Payload written to EP ... 0x00000006  (Memory Write TLP)
  Payload read back ....... 0x00000006  (match)
  FIRMWARE RESULT ......... PASS (0x0000face)
```

The last three lines are the actual result. `0x0000FACE` is only the verdict the
firmware reports; the two above it are the dword that really crossed the link --
written to the endpoint at `0x8000_0000` by a Memory Write TLP, then fetched
back by a Memory Read and its completion.

In between, the real firmware enumerates the endpoint model exactly as it does
on the board. The endpoint's own decode of the traffic:

```
RC -> EP   Config read  type 0  Reg=00   ID                    TAG=00
EP -> RC   Completion with data              Device 0002, Vendor 14FC
RC -> EP   Config write type 0  Reg=01   Command = 0           memory decode off
RC -> EP   Config write type 0  Reg=04   BAR0 = 0xFFFFFFFF     size it ...
RC -> EP   Config read  type 0  Reg=04   BAR0
EP -> RC   Completion with data              0xFFFFF008            4 KB, 32-bit, prefetchable
RC -> EP   Config write type 0  Reg=04   BAR0 = 0x80000000     ... and place it
           ... the same for BAR1 (1 KB -> 0x80001000), BAR2/3 (64-bit, 8 GB:
           parked above 4 GB), BAR4/5 (read back 0: not implemented) ...
RC -> EP   Config write type 0  Reg=01   Command = 6           memory space + bus master
RC -> EP   Mem write req  Addr=80000000  data 0x00000006
RC -> EP   Mem read  req  Addr=80000000  TAG=14
EP -> RC   Completion with data              0x00000006            TAG=14
```

Every request goes through the same completion check: the firmware reads the
Completion Status of each one and re-issues a request answered with CRS. 21 of
the 22 TLPs are enumeration and test; the 22nd is the result marker itself --
writing it to `tx.data` re-launches the last header, a second Memory Read.

The same traffic, decoded at TLP level in a waveform viewer, is in
[Viewing the TLPs in WaveCrux](#viewing-the-tlps-in-wavecrux).

And the CSR side of the same sequence, as the firmware sees it:

```
CSR RD [0x20] = 0000001e     status.phy -- Tx FSM idle, 30 buffers free
CSR WR [0x00] = 04000001     tx.header0 -- CfgRd0, length 1
CSR WR [0x04] = 10ee000f     tx.header1 -- requester 0x10EE, tag 0, BE 0xF
CSR WR [0x08] = 01000000     tx.header2 -- bus 1, device 0, function 0, register 0
CSR WR [0x0c] = 00000000     tx.data    -- the write strobe starts the transfer
CSR RD [0x18] = ...          rx.header_info -- polled until the completion lands
...
CSR WR [0x0c] = 0000face     the pass marker
```

### Building and running

On Windows, work through [Prerequisites](#prerequisites-on-windows) first -- the
right shell and the `PATH` settings. Everything below assumes an MSYS2 MinGW64
shell with the tools on `PATH`; from `cmd.exe` the first line fails with
`'make' is not recognized`.

```
cd 4.build/sw_build && make SIM=1   # firmware with the short start-up delay
cd ../../5.sim
make                                # VProc.so + xvlog + xelab
make run                            # -> the summary above
make gui                            # same, with waveforms
```

`SIM=1` matters: `main()` opens with `wait_cycles(100000)`, which waits for the
link to train. On hardware that costs nothing; in simulation, compiled without
optimisation, it is about 80 ms of simulated time before the firmware does
anything at all. `SIM=1` shortens it to 200 iterations and the whole run fits in
3 ms. Without it the simulation still works, it just needs `make run RUN_US=100000`
and a great deal of patience.

Useful switches:

```
make run RUN_US=10000                        # longer run; read at time 0 from run_us.cfg
make USRSIMOPTS="--define CPU_TRACE"         # CPU bus activity and every CSR access
make USRSIMOPTS="--define PIPE_OS_TRACE"     # ordered sets both ways, with link/lane numbers
make USRSIMOPTS="--define PIPE_RAW_DUMP"     # raw PIPE symbols
```

The LTSSM state, the link status bits and the firmware's result marker are
always printed, with no define needed.

### Viewing the TLPs in WaveCrux

xsim's own waveform database is the `.wdb` that `make gui` opens. For a view at
*TLP level* -- every packet named, every completion paired with the request it
answers -- the run can also write a VCD for [WaveCrux](https://wavecrux.app),
together with a decoder plugin and a ready-made session:

```
make run USRSIMOPTS="--define DUMP_VCD"     # -> 5.sim/tb.vcd (about 15 MB, not tracked)
```

Then, once per machine, in WaveCrux (1.0.1 or later): **Settings -> Extensions -> Decoder
Plugins**, accept the safety notice, **Add directory...**
`5.sim/tools/wavecrux-pcie-tlp` and **Reload plugins**. After that, open
[`tb.TLP.wavecrux`](tb.TLP.wavecrux) (File -> Open, or `wavecrux_pro tb.TLP.wavecrux`): it
loads `tb.vcd` from the same directory with both decoders bound. The plugin --
source, Windows binary, parameters -- is described in
[tools/wavecrux-pcie-tlp](tools/wavecrux-pcie-tlp/README.md).

In each picture the two decoder rows are the TLP stream in either direction:
**TLP Downstream** is Root Complex -> Endpoint (`tx_`), **TLP Upstream** is
Endpoint -> Root Complex (`rx_`). Above them are the raw streams they decode,
one DW per clock.

**BAR0 sizing.** The firmware writes all ones to BAR0, reads it back --
`0xFFFFF008`, a 4 KB, 32-bit, prefetchable BAR -- and places it at `0x80000000`:

<p align="center">
WaveCrux TLP view: firmware sizing BAR0
</p>

**A 64-bit BAR that does not fit.** BAR2 has already read back `0x0000000C`
(64-bit, prefetchable). The upper half, BAR3, reads back `0xFFFFFFFE`: 8 GB.
That cannot be placed below 4 GB, and this Root Complex only sends 32-bit
addresses, so the firmware parks it at `0x2_0000_0000` instead of squeezing it
in:

<p align="center">
WaveCrux TLP view: a 64-bit BAR that does not fit
</p>

**The self-test.** Memory Space and Bus Master enabled, then a posted Memory
Write of `6` to `0x80000000` and a Memory Read whose completion brings the same
`6` back -- the `PASS (0x0000face)` of the summary above:

<p align="center">
WaveCrux TLP view: memory write and read-back self-test
</p>

What makes this possible in the test bench:

* [`models/tlp_dw_monitor.sv`](models/tlp_dw_monitor.sv) re-times the SOC's
  64-bit AXI-Stream into one DW per clock with SOP/EOP flags, one instance per
  direction, onto a [`tlp_dw_if`](models/tlp_dw_if.sv).
* [`models/tlp_wavecrux_view.sv`](models/tlp_wavecrux_view.sv) presents both
  directions as `tb.tlp_view.tx_*` and `rx_*`, named after the decoder's
  inputs, so WaveCrux's auto-bind finds them; its prefix drop-down picks `tx_`
  or `rx_`.

The session stores the decoder bindings as positions in the VCD, which are the
same for every run of this test bench. Should a different simulator version
order the dump differently, the decoder rows come up empty: remove them and add
them again with **Ctrl+Shift+D** -- auto-bind fills in all nine inputs.

### Viewing the PIPE in WaveCrux

The same `tb.vcd` also carries the 16-bit PIPE between the Root Complex's
PCIE_2_1 hard macro and the pcieVHost endpoint, one level below the TLPs:
the symbols as they go on the wire, before 8b/10b. All signals are under
`tb.dut.pcie_inst.serdes_front_i.u_pcie_ep`:

| Signal | Direction |
|---|---|
| `pclk` | PIPE clock, one 16-bit word (two symbols) per rising edge |
| `RxData` / `RxDataK` | Root Complex -> Endpoint |
| `TxData` / `TxDataK` | Endpoint -> Root Complex |

These are the inputs of Ferrite's
[PCIe PIPE and Data Link Layer decoders](https://github.com/Ferrite-Engineering/wavecrux-decoders)
(Apache-2.0). Get the plugin from their
[release page](https://github.com/Ferrite-Engineering/wavecrux-decoders/releases/tag/pcie-v0.1.0)
(Windows: `wcx-pcie-0.1.0-windows-x64.zip`), unzip it to a folder of its own and add
that folder under **Settings -> Extensions -> Decoder Plugins**, as above. Then open
[`tb.PIPE-DLL.wavecrux`](tb.PIPE-DLL.wavecrux) (File -> Open, or
`wavecrux_pro tb.PIPE-DLL.wavecrux`): it loads `tb.vcd` from the same directory,
with the PIPE rows and all four decoders below bound, at the view of the third
picture. It is separate from `tb.TLP.wavecrux`, which needs only our own TLP plugin.

To set it up by hand instead, add
**PCIe PIPE (16-bit)** and **PCIe Data Link Layer (16-bit)** with **Ctrl+Shift+D**,
once per direction: prefix `Rx`, then `Tx`, each time **Apply confirmed only**.
Take the 16-bit variants: each decoder comes in 8, 16, 32 and 64 bits, and only
the one matching the bus binds. Leave `scrambling` at `auto`: the simulation
link runs unscrambled, and the decoder locks to that by itself.
`serdes_front_i.rx_active` can be bound to `rxvalid` by hand on the `Tx`
instances (it gates what the Root Complex receives).

In the pictures, the four signal rows under the LTSSM state are the PIPE:
`RxData`/`RxDataK` in blue (Root Complex -> Endpoint) and `TxData`/`TxDataK` in
orange (Endpoint -> Root Complex). Below them are the four decoder rows, in
this order: PIPE `Rx`, PIPE `Tx`, Data Link Layer `Rx`, Data Link Layer `Tx`.

**Link training.** Both sides have been sending TS2s with PAD for link and lane
number (Polling). Now in Configuration, the Root Complex proposes link 0 in
TS1s (`link=0 lane=PAD`), the Endpoint echoes it, then lane 0 is
proposed and echoed (`link=0 lane=0`). TS2s with both numbers close
Configuration. Each side also advertises how many FTS ordered sets it needs to
leave L0s: 255 for the Root Complex, 4 for the Endpoint. The Data Link Layer rows
stay empty: no DLLP is sent before the link is up. The Root Complex's LTSSM
reaches L0 at 74 µs, just after this view:

<p align="center">
WaveCrux PIPE view: link training
</p>

**Flow-control initialisation.** As soon as the link is up, each side advertises its
receive buffer credits, in header (`H`) and data (`D`) units, for Posted (`P`),
Non-Posted (`NP`) and Completion (`Cpl`) traffic: first in InitFC1 DLLPs, then
in InitFC2 to confirm. No TLP can be sent until this has finished. This 100 ns
view catches the two sides one step apart:
- The Endpoint is already sending InitFC2 (bottom row): 32 posted headers with
  1008 data credits, and 32 non-posted headers.
- The Root Complex is still sending InitFC1 (row above it): 32 posted headers
  with 437 data credits.

`H=0 D=0` means infinite: both ends advertise infinite Completion credits. The
spec requires that of an Endpoint, and of a Root Complex without peer-to-peer
traffic between its ports. Each DLLP is framed SDP (`5c`) ... END (`fd`)
on the PIPE, both K symbols:

<p align="center">
WaveCrux PIPE view: flow-control initialisation
</p>

**The first TLP on the wire.** At 225 µs the firmware's first Configuration
Read leaves the Root Complex as `TLP seq=0 CfgRd0`, framed STP ... END. The
Endpoint answers with its Completion, `TLP seq=0 CplD`: seq 0 again, because
each direction numbers its own TLPs. It then sends `Ack seq=0` for the
Configuration Read, so the Root Complex can drop it from its replay buffer. It
also sends `UpdateFC-NP` to return the non-posted credit that the read used.
The Root Complex acknowledges the Completion in turn, with its own `Ack seq=0`
at 225.95 µs, just outside this view:

<p align="center">
WaveCrux PIPE view: first TLP and its Ack
</p>

**The Data Link Layer: its traffic is shown, its internals are not.** On this
Root Complex, the Data Link Layer lives inside the 7-series PCIE_2_1 hard macro.
Nothing inside it reaches the VCD:

* the replay buffer, which holds each TLP until it is acknowledged
* the sequence counters (next to send, next expected)
* the Ack/Nak latency and replay timers
* the flow-control credit counters

What the Data Link Layer *puts on the wire* does reach the VCD, because it
crosses the PIPE. That is what Ferrite's Data Link Layer decoder
(`ferrite.pcie_dll_w16`) reads. From the PIPE symbols alone it names:

* every DLLP: `Ack seq=0`, `Nak`, `InitFC1-P` / `InitFC2-NP` / `UpdateFC-Cpl`
  with their header and data credits, and the PM DLLPs, each with its CRC-16
  checked
* every TLP with its sequence number and LCRC check, the TLP type (`CfgRd0`,
  `CplD`, `MWr32`, ...), Length, TC, TD and EP
* replays, sequence-number errors and nullified TLPs

So the pictures above show the Data Link Layer protocol between the two ends:
which TLP got which sequence number, when it was acknowledged, and how many
credits each side granted. They do not show how the hard macro arrived at those
decisions. For that, see an open-source Data Link Layer in RTL, where every
internal signal can be dumped: the sibling project's
[openCologne-PCIE `2.rtl/4.dll`](https://github.com/chili-chips-ba/openCologne-PCIE/tree/main/2.rtl/4.dll).
Its wave snapshots are coming soon.

### How long a TLP spends in the hard macro

With all three layers in one view, you can follow a single request through the
Root Complex and see how long the PCIE_2_1 hard macro takes to pass it on.
Open [`tb.TLP-DLL-PIPE.wavecrux`](tb.TLP-DLL-PIPE.wavecrux) (it needs both
plugins). It shows the TLP view of the SOC's AXI-Stream at the top, the PIPE
below it, and the TLP, PIPE and Data Link Layer decoders at the bottom.

Here is the firmware's first Configuration Read and its Completion. The markers
on the time axis show where the TLP crosses from one layer to the next:

<p align="center">
WaveCrux view of one request through the hard macro, markers a to d
</p>

| Marker | What happens |
|---|---|
| **a** | The CPU's request leaves the SOC on the AXI-Stream |
| **b** | About 0.4 µs later, it appears on the PIPE, on its way to the Endpoint |
| **c** | The Endpoint's Completion has fully arrived on the PIPE |
| **d** | About 0.4 µs later, the Completion reaches the SOC |

The Endpoint model answers almost at once, so nearly all of the 1 µs round trip
is spent inside the hard macro, about 0.4 µs each way. On the way back, the
clock starts only once the whole TLP has arrived (marker **c**): the hard macro
holds each TLP until its LCRC has checked out, and only then hands it to the
SOC.

The same holds for every TLP in the run, give or take one clock. Two things
to keep in mind when comparing with real hardware:

* The simulation link runs at Gen1 (see `SIM_GEN1_ONLY` above). At Gen2 the
  link itself is twice as fast.
* The PIPE PHY model is ideal. On the board, the GTP transceiver adds its own
  latency on both sides of the link.

## The three CPU options

The SOC's CPU socket takes three different occupants, selected with `CPU=` on
the make command line. The DUT is otherwise identical in all three -- the same
CSR, the same PCIE stack, the same top level -- so the same test is being run
each time, only the thing issuing the bus accesses changes.

| `CPU=` | What sits on VProc node 0 | Executes |
|---|---|---|
| `rtl` (default) | nothing -- the real `picorv32` core | `firmware.hex`, the same image that goes into the bitstream |
| `vproc` | VProc | [`usercode/VUserMain0.cpp`](usercode/VUserMain0.cpp), compiled for the host |
| `iss` | VProc + the [rv32](models/rv32) instruction set simulator | `firmware.elf`, interpreted -- real RISC-V instructions, no RTL core |

```sh
cd ../4.build/sw_build && make SIM=1   # firmware.hex AND firmware.elf
cd ../../5.sim
make run                  # CPU=rtl, the default
make run CPU=vproc
make run CPU=iss
```

The swap happens in [`riscv_pcie_soc.sv`](../2.rtl/0.common.opensource/src/riscv_pcie_soc.sv)
behind `` `ifdef SOC_CPU_VPROC ``, which the makefile passes to `xvlog` for the
two VProc builds. The replacement module is
[`models/soc_cpu.VPROC.picorv32.sv`](models/soc_cpu.VPROC.picorv32.sv): VProc
dressed up as a picorv32, driving the core's *native* memory interface.

> Note the difference from the inherited `models/soc_cpu.VPROC.sv`, which is
> kept for reference. That one speaks the `soc_if` bus interface of the sibling
> Chili.CHIPS SOC infrastructure. This design has no `soc_if` -- it instantiates
> picorv32 directly -- so it needed its own wrapper.

The native C++ model reaches the CSR through `csr_cosim.h`, which PeakRDL
generates from the same [`csr.rdl`](../4.build/csr_build/csr.rdl) that produces
the register RTL and the firmware's `csr.h`. Hardware, firmware and the
co-simulation CPU model therefore cannot drift apart. The ISS is configured in
[`vusermain.cfg`](vusermain.cfg), where `-x`/`-X` place the CSR window on the
simulated bus and leave code and data in the ISS's own memory, and `-V PICORV32`
selects the matching instruction timing model.

### What they cost

Measured on a Ryzen 7 5800H (8 cores / 16 threads) **on mains power**, Vivado
xsim 2024.2, all three producing the identical result -- link up, LTSSM `0x16`,
9 TLPs, `PASS (0x0000face)`. These figures were taken with the earlier firmware,
before BAR sizing by readback; with the current one (22 TLPs, Vivado xsim
2025.1) the result appears at 654.0 µs (`rtl`), 145.6 µs (`vproc`) and
805.1 µs (`iss`):

| | `CPU=rtl` | `CPU=vproc` | `CPU=iss` |
|---|---|---|---|
| Build from clean | 51 s | 49 s | 55 s |
| Result appears at | 302.4 µs | 99.0 µs | 311.7 µs |
| Run to that result | 28 s | **13 s** | 28 s |
| Run a fixed 400 µs | 33 s | 33 s | 33 s |

Each figure is the median of three clean repetitions; the spread is under 2 s.
Mains power is not a footnote: on battery, with the CPU clocked down from
3.2 GHz to 1.9 GHz, the same 400 µs run takes 83 s instead of 33 s. Measure with
the charger in, or the numbers are meaningless.

Two things fall out of that last row. The wall-clock cost of a given amount of
*simulated* time is the same whichever CPU is used, because the CPU is not what
the simulator spends its time on -- the `PCIE_2_1` hard macro model and the PCIE
stack around it are. Swapping the core out buys nothing by itself.

What `CPU=vproc` does buy is *less simulated time to cover*: 99 µs instead of
302 µs, because the native program does not pay the firmware's start-up delay
and polls the CSR without burning instructions between reads. That is where its
2x comes from, and it is why it is the one to reach for when iterating on the
PCIE logic rather than on the firmware.

`CPU=iss` lands within 3% of the RTL core's timing (311.7 µs against 302.4 µs),
which is the `-V PICORV32` timing model doing its job. It is the useful middle
ground: the real firmware binary, real RISC-V instructions, and a debuggable
native process -- `-g` in `vusermain.cfg` opens a gdb port -- without the RTL
core in the way.

## Auto-selection of soc_cpu Component

> Historical note. This describes the arrangement in the sibling
> Chili.CHIPS SOC infrastructure, where the CPU was selected by filtering a file list. Here the choice
> is the `CPU=` switch above, and the file list is [`tb.prj`](tb.prj).

The SOC top level component has the required RTL files listed in <tt>2.rtl/top.filelist</tt>. This includes files for the `soc_cpu`, under the directory <tt>ip.cpu</tt>. The simulation build make file ([see below](#building-and-running-code)) will process the <tt>top.filelist</tt> file to generate a new local copy, having removed all references to the files under the <tt>ip.cpu</tt> directory. Since the VProc <tt>soc_cpu</tt> component is a verification model, the <tt>soc_cpu.VPROC.sv</tt> HDL file is placed in <tt>5.sim/models</tt> whilst the the HDL files for _VProc_ and _mem_model_ are in `5.sim/models/cosim`. These are referenced within the make file, along with the other test models that are used in the test bench. Thus the VProc device is selected for the simulation as the CPU component.

## VProc Software

The VProc software consists of DPI-C code for communication and synchronisation with the simulation, for _VProc_. On top of this are the APIs for _VProc_ for use by the running code. In the case of _VProc_ there is a low level C API) or, if preferred, a C++ API. In _openPCIE_, the _VProc_ <tt>soc_cpu</tt> is node 0, and so the entry point for user software is <tt>VUserMain0</tt>, in place of a normal C or C++ <tt>main</tt>.

The _VProc_ software is compiled into libraries located in `5.sim/models/cosim/lib`, with the headers in `5.sim/models/cosim/include` (see [here](models/cosim/README.md) for more details). The C++ API is defined in a class <tt>VProc</tt> (defined in <tt>VProcClass.h</tt>), and a constructor creates an API object, defining the node for which it is connected:

```c++
VProc (const uint32_t node);
```

For the C++ VProc API there are two basic word access methods:

```c++
    int  write (const unsigned   addr, const unsigned    data, const int delta=0);
    int  read  (const unsigned   addr,       unsigned   *data, const int delta=0);
```

For these methods, the address argument is agnostic to being a byte address or a word address, but for the _openPCIE_ implementation these are **byte addresses**. The `delta` argument is unused in _openPCIE_, and should be left at its default value, with just the `address` and `data` arguments used in the call to these methods. Along with these basic methods is a method to advance simulation time without doing a read or write transaction.

```c++
int  tick (const unsigned ticks);
```
This method's units of the <tt>ticks</tt> argument are in clock cycles, as per the clock that the _VProc_ HDL is connected to. A basic _VProc_ program, then, is shown below:

```c++
#include "VProcClass.h"
extern "C" {
#include "mem.h"
}

static const int node    = 0;

extern "C" void VUserMain0(void)
{
    // Create VProc access object for this node
    VProc* vp0 = new VProc(node);

    // Wait a bit
    vp0->tick(100);

    uint32_t addr  = 0x10001000;
    uint32_t wdata = 0x900dc0de;

    vp0->write(addr, wdata);
    VPrint("Written   0x%08x  to  addr 0x%08x\n", wdata, addr);

    vp0->tick(3);

    uint32_t rdata;
    vp0->read(addr, &rdata);

    if (rdata == wdata)
    {
        VPrint("Read back 0x%08x from addr 0x%08x\n", rdata, addr);
    }
    else
    {   VPrint("***ERROR: data mis-match at addr = 0x%08x. Got 0x%08x, expected 0x%08x\n", addr, rdata, wdata);
    }

    // Sleep forever
    while(true)
        vp0->tick(GO_TO_SLEEP);
}
```
The above code is a slightly abbreviated version of the code in <tt>5.sim/usercode</tt>. Note that the <tt>VUserMain0</tt> function must have C linkage as the _VProc_ software that calls it is in C (as all the programming logic interfaces, including DPI-C, are C). The API also has a set of other methods for finer access control which are listed below, and more details can be found in the [_VProc_ manual](https://github.com/wyvernSemi/vproc/blob/master/doc/VProc.pdf).

```c++
    int  writeByte    (const unsigned   byteaddr, const unsigned    data, const int delta=0);
    int  writeHword   (const unsigned   byteaddr, const unsigned    data, const int delta=0);
    int  writeWord    (const unsigned   byteaddr, const unsigned    data, const int delta=0);
    int  readByte     (const unsigned   byteaddr,       unsigned   *data, const int delta=0);
    int  readHword    (const unsigned   byteaddr,       unsigned   *data, const int delta=0);
    int  readWord     (const unsigned   byteaddr,       unsigned   *data, const int delta=0);

```
The other methods in this class are not, at this point, used by _openPCIE_. These methods can now be used to write test code to drive the CPU bus of the <tt>soc_cpu</tt> component (here picorv32's native memory interface), and is the basic method to write test code software.

As well as the _VProc_ API, the user software can have direct access to the sparse memory model API (which is part of the _pcievhost_ model) by including <tt>mem.h</tt>, which are a set of C methods (and <tt>mem.h</tt> must be included as <tt>extern "C"</tt> in C++ code). The functions relevant to _openPCIE_ are shown below:

```c++
void     WriteRamByte  (const uint64_t addr, const uint32_t data, const uint32_t node);
void     WriteRamHWord (const uint64_t addr, const uint32_t data, const int little_endian, const uint32_t node);
void     WriteRamWord  (const uint64_t addr, const uint32_t data, const int little_endian, const uint32_t node);
uint32_t ReadRamByte   (const uint64_t addr, const uint32_t node);
uint32_t ReadRamHWord  (const uint64_t addr, const int little_endian, const uint32_t node);
uint32_t ReadRamWord   (const uint64_t addr, const int little_endian, const uint32_t node);
```

Note that, as C functions, there are no default parameters and the <tt>little_endian</tt> and <tt>node</tt> arguments must be passed in, even though they are constant. The <tt>little_endian</tt> argument is non-zero for little endian and zero for big endian. The <tt>node</tt> argument is **not** the same as for _VProc_, but allows multiple separate memory spaces to be modelled, just as for _VProc_ multiple virtual processor instantiations. For _openPCIE_, this is always 0. All instantiated <tt>mem_model</tt> components in the HDL have (through the DPI) access to the same memory space model as the API, and so data can be exchanged from the simulation and the running code, such as the RISC-V programs.

Compiling co-designed application code, either compiled for the native host machine, or to run on the <tt>rv32</tt> RISC-V ISS will need further layers on top of these APIs, which will be virtualised away by that point ([see the sections below](#co-simulation-hal)). The diagram below summarises the software layers that make up a program running on the _VProc_ HDL component. The "native test code" use case, shown at the top left, is for the case just described above  that use the APIs directly, though they can optionally use the HAL.

<p align="center">
Software layers on the VProc soc_cpu
</p>

### Other Software Use Cases

#### Natively Compiled Application

As well as the native test code case seen in the previous section, the _openPCIE_ application can be compiled natively for the host machine, including the hardware access layer (HAL), generated from SystemRDL. The HAL software output from this is processed to generate a version that makes accesses to the _VProc_ and PCIE memory model APIs in place of accesses with pointers to and from memory (see the [Co-simulation HAL](#co-simulation-hal) section below). The rest of the application software has these details hidden away in the HAL and sees the same API as presented by the auto-generated code. The <tt>main</tt> entry point is also swapped for <tt>VUserMain0</tt>.

This is exactly the `CPU=vproc` build. In _openPCIE_ the transactions leave the CPU model on picorv32's native memory interface rather than on an <tt>soc_if</tt> port, since that is what this SOC instantiates -- see [The three CPU options](#the-three-cpu-options). The generated co-simulation HAL is `csr_cosim.h`, and [`usercode/VUserMain0.cpp`](usercode/VUserMain0.cpp) is the application on top of it.
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

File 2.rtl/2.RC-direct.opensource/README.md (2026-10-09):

# Opensource RC-direct core

This is an opensource variant of what was first tested with the
[AMD-proprietary RC-direct IP stack](../../2.amd-rtl-with-Vivado-build/2.RC-direct.amd).

- [x] ✔️ Hardware FSM replaced with an opensource RISC-V based SOC
- [x] ✔️ PCIE IP core replaced with opensource RTL
- [x] ✔️ Builds and runs with a **fully opensource toolchain** - link up at Gen2
- [x] ✔️ Upgrade the current simple SOC to a version that uses PeakRDL for CSR generation

Together with our [openPCIE backplane](../../1.pcb) and Simon's unique
[end-to-end PCIE sim](../../5.sim) setup, this is **`one of the three pillars`**,
i.e. primary deliverables of this project.

The objectives of this dev track were to:
 - first design the opensource RC-direct core
 - then validate and showcase its operation in a direct RC-to-EP configuration.

Both are done. With the [RC-switched](../3.Bonus--RC-switched.opensource) use-case
as well, we have a nicely rounded set of opensource cores and examples -- a solid
foundation for the makers to build their future applications upon...

---

## Status

| | |
|---|---|
| Target device | `xc7a200tfbg484-3`, Acorn CLE-215P |
| Link | **PCIE Gen2 x1, up and trained** (verified RC-to-EP on hardware) - the default, and the committed deliverable |
| Bonus | **Gen2 x4** also tested on hardware, on the backplane's RC4 ⇔ EP4 island; not the checked-in default |
| Vivado build | works |
| Opensource build | works - see [`4.build/hw_build.openXC7`](../../4.build/hw_build.openXC7) |

Link width and speed come from a single place,
[`link_pkg.sv`](../0.common.opensource/src/pcie/link_pkg.sv) -- shared with
[RC-switched](../3.Bonus--RC-switched.opensource), so a change applies to both:

```systemverilog
localparam int PCIE_LANES = 1;   // 1, 2, 4 or 8
localparam int PCIE_GEN   = 2;   // 1 = Gen1, 2 = Gen2
```

---

## Structure

RC-direct and [RC-switched](../3.Bonus--RC-switched.opensource) are built from
the very same RTL, kept once in [`0.common.opensource`](../0.common.opensource).
They differ only in the GT lane the x1 link uses and in the firmware they run.

```
2.rtl/0.common.opensource/        shared by both root complexes
  src/
    RC_opensource.sv              top level: refclk buffer, PCIE bridge, SOC, LEDs
    riscv_pcie_soc.sv             picorv32 SOC, drives the AXI-Stream TLP interface
    soc_csr.sv                    wrapper for the PeakRDL-generated CSR block
    picorv32.CHILI.sv             the RISC-V core (Chili.CHIPS-improved picorv32)
    pcie/                         the opensource PCIE stack
  xdc/
    RC.sv.x1g2.AcornCLE-215P.xdc  constraints, all but the GT lane (source of truth)
  RC.opensource.tcl               the Vivado project script behind both wrappers

2.rtl/2.RC-direct.opensource/     this folder
  xdc/
    RC-direct.sv.x1g2.AcornCLE-215P.xdc   GT lane: GTPE2_CHANNEL_X0Y5
  RC-direct.opensource.tcl        regenerates the Vivado project from scratch
```

### The PCIE stack, by layer

The `PCIE_2_1` hard block is silicon and is instantiated directly. Everything
around it - what AMD ships as encrypted IP - is opensource RTL here.

| Layer | Files | Role |
|---|---|---|
| Transaction | `txn_engine.sv`, `silicon_core.sv` | `PCIE_2_1` instance and its TLP-side plumbing |
| Buffering | `buffer_bank.sv`, `buffer_tile.sv` | RX/TX packet buffers (BRAM) |
| Streaming | `stream_bridge.sv`, `stream_tx_path.sv`, `stream_rx_path.sv`, `stream_tx_gate.sv` | AXI-Stream TLP interface towards the SOC |
| Bridge | `host_bridge.sv` | ties the transaction and PHY sides together |
| PHY control | `serdes_front.sv`, `serdes_ctrl.sv` | PIPE-level control, reset and rate sequencing |
| Bring-up FSMs | `init_ctrl.sv`, `pll_init_ctrl.sv`, `phase_align.sv`, `wake_timer.sv`, `lane_keeper.sv` | GT reset sequence, QPLL sequence, TX/RX phase alignment |
| Transceiver | `lane_xcvr.sv`, `pll_bank.sv` | `GTPE2_CHANNEL` and `GTPE2_COMMON` instances |
| Clocking | `clk_synth.sv` | MMCM: 125 / 250 / 62.5 MHz from the 100 MHz refclk |
| Tuning | `chan_retune.sv`, `pll_retune.sv`, `speed_ctrl.sv`, `margin_tuner.sv`, `eios_squelch.sv` | DRP-based retuning on rate change, equalisation, electrical-idle detection |
| Interfaces | `link_pkg.sv`, `stream_if.sv`, `phy_lanes_if.sv` | package and SystemVerilog interfaces |
| Debug | `signal_probe.sv` | status/debug vector taps |
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

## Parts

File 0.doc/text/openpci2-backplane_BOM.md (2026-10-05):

<!-- Generated text version of `1.pcb/openpci2-backplane/openpci2-backplane.kicad_sch` (kicad-cli BOM export) so the website assistant can read it. Do not edit by hand; regenerate from the source. -->

# openPCIE2 Backplane bill of materials (from the KiCad schematic)

Generated with `kicad-cli sch export bom` from `1.pcb/openpci2-backplane/openpci2-backplane.kicad_sch` (KiCad 10.0.6). It reflects the current schematic; the older BOM PDF predates the 1.2 V buck converter change.

| Qty | Value | References | Footprint | Fitted |
|---|---|---|---|---|
| 6 | 100u | C2, C17, C41, C44, C77, C80 | CAPAE660X610N | yes |
| 2 | 10u | C3, C4 | C_1206_3216Metric | yes |
| 4 | 1u | C5, C7, C9, C39 | C_0603_1608Metric | yes |
| 51 | 100n | C6, C8, C10, C11, C22, C25, C26, C30, C31, C32, C33, C34, C35, C36, C37, C40, C43, C46, C47, C48, C51, C52, C53, C54, C55, C56, C57, C58, C59, C60, C61, C62, C63, C64, C65, C66, C67, C68, C69, C70, C71, C72, C73, C74, C75, C76, C79, C82, C84, C88, C89 | C_0402_1005Metric | yes |
| 13 | 22u | C13, C14, C15, C16, C18, C19, C20, C21, C23, C24, C27, C50, C85 | C_0805_2012Metric | yes |
| 2 | 8p | C28, C29 | C_0402_1005Metric | yes |
| 8 | 10n | C38, C42, C45, C49, C78, C81, C83, C87 | C_0402_1005Metric | yes |
| 1 | ??? | D1 | DIOM4336X265N | yes |
| 1 | LTST-C170KRKT | D2 | LED_LTST-C170KGKT_LTO-L | yes |
| 3 | LTST-C170KGKT | D3, D4, D5 | LED_LTST-C170KGKT_LTO-L | yes |
| 3 | 220R | FB1, FB2, FB3 | L_0402_1005Metric | yes |
| 12 | MountingHole | H1, H2, H3, H4, H5, H6, H7, H8, H9, H10, H11, H12 | Mounting_hole 3.2_5.5mm_NO_NET | yes |
| 1 | Conn_02x03_Top_Bottom | J1 | MINIFIT_5566-06A | yes |
| 3 | BWSMA-KWE-Z001 | J3, J4, J6 | BWSMA-KWE-Z001 | yes |
| 2 | X3113WVS-64-9TV01 | J5, J15 | 10061913-111PLF | yes |
| 3 | AS0BC21-S30BM-7H | J7, J13, J14 | 1-2199230-6 with holes (80 mm) | yes |
| 2 | X1618WVS-36-9TV30 | J11, J12 | 10061913-110PLF | yes |
| 5 | 10K | JP1, JP2, JP3, JP4, JP5 | JP3 shorted with 0R (0603) | yes |
| 3 | 2K2 | JP6, JP7, JP8 | JP3 shorted with 0R (0603) 2-3 | yes |
| 3 | 0K | JP12, JP13, JP14 | JP3 shorted with 0R (0603) 2-3 | yes |
| 1 | 7443082015A | L1 | WE-HCM_1088A | yes |
| 1 | L | L3 | L_1008_2520Metric | yes |
| 10 | 10K | R3, R7, R12, R16, R18, R23, R25, R26, R27, R29 | R_0603_1608Metric | yes |
| 2 | 56K | R4, R13 | R_0603_1608Metric | yes |
| 2 | 0R | R5, R10 | R_0603_1608Metric | yes |
| 3 | 12K1 | R6, R33, R34 | R_0603_1608Metric | yes |
| 1 | 4K32 | R8 | R_0603_1608Metric | yes |
| 1 | 182K | R9 | R_0603_1608Metric | yes |
| 4 | 220R | R11, R28, R37, R38 | R_0603_1608Metric | yes |
| 1 | 75K | R15 | R_0603_1608Metric | yes |
| 1 | 33K | R17 | R_0603_1608Metric | yes |
| 3 | 2K2 | R20, R21, R32 | R_0603_1608Metric | yes |
| 4 | 33R | R22, R24, R35, R36 | R_0603_1608Metric | yes |
| 1 | SW_Push | SW1 | PTS645 | yes |
| 6 | Test | TP1, TP2, TP3, TP4, TP5, TP6 | Testhole 24_50mils | yes |
| 1 | TPS54KC23RZRR | U2 | RZR0016A-MFG | yes |
| 1 | SN74LVC244APWR | U4 | PW20-L | yes |
| 1 | TLV75801PDBVR | U5 | DBV5 | yes |
| 1 | PI6CG18801ZLIEX | U6 | QFN40P600X600X90-49N | yes |
| 1 | RY3420 | U7 | RY3420 | yes |
| 1 | ASM1184E | U8 | QFN-64-1EP_9x9mm_P0.5mm_EP5.2x5.2mm | yes |
| 1 | Crystal_GND24 | Y1 | XTAL_TSX-3225_25.0000MF20X-AJ3 | yes |

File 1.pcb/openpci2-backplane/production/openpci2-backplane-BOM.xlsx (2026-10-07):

openPCIE2 Backplane rev RevB — BOM generated 2026-10-06
Item | Qty | Designators | Value | MPN | Footprint | DNP
1 | 6 | C2,C17,C41,C44,C77,C80 | 100u | EEE-1CA101WAP | CAPAE660X610N
2 | 2 | C3,C4 | 10u | CL31A106KAHNNNE | C_1206_3216Metric
3 | 4 | C5,C7,C9,C39 | 1u | C1608X5R1E105K080AC | C_0603_1608Metric
4 | 51 | C6,C8,C10,C11,C22,C25,C26,C30,C31,C32,C33,C34,C35,C36,C37,C40,C43,C46,C47,C48,C51,C52,C53,C54,C55,C56,C57,C58,C59,C60,C61,C62,C63,C64,C65,C66,C67,C68,C69,C70,C71,C72,C73,C74,C75,C76,C79,C82,C84,C88,C89 | 100n | CL05A104KA5NNNC | C_0402_1005Metric
5 | 13 | C13,C14,C15,C16,C18,C19,C20,C21,C23,C24,C27,C50,C85 | 22u | CL21A226KPCLRNC | C_0805_2012Metric
6 | 2 | C28,C29 | 8p | GRM1555C1H8R0BA01D | C_0402_1005Metric
7 | 8 | C38,C42,C45,C49,C78,C81,C83,C87 | 10n | GRM155R71C103KA01D | C_0402_1005Metric
8 | 1 | D1 | SMBJ12A | SMBJ12A | DIOM4336X265N
9 | 1 | D2 | LTST-C170KRKT | LTST-C170KRKT | LED_LTST-C170KGKT_LTO-L
10 | 3 | D3,D4,D5 | LTST-C170KGKT | LTST-C170KGKT | LED_LTST-C170KGKT_LTO-L
11 | 3 | FB1,FB2,FB3 | 220R | BLM15AG221SN1D | L_0402_1005Metric
12 | 6 | H1,H2,H3,H4,H5,H6 | Nylon Standoff M3x11 | HP-11M3*11 | Mounting_hole 3.2_5.5mm_NO_NET
13 | 1 | J1 | DLL-5566-6A | DLL-5566-6A | MINIFIT_5566-06A
14 | 3 | J3,J4,J6 | BWSMA-KWE-Z001 | BWSMA-KWE-Z001 | BWSMA-KWE-Z001
15 | 2 | J5,J15 | X3113WVS-64-9TV01 | X3113WVS-64-9TV01 | 10061913-111PLF
16 | 3 | J7,J13,J14 | AS0BC21-S30BM-7H | AS0BC21-S30BM-7H | 1-2199230-6 with holes (80 mm)
17 | 2 | J11,J12 | X1618WVS-36-9TV30 | X1618WVS-36-9TV30 | 10061913-110PLF
18 | 5 | JP1,JP2,JP3,JP4,JP5 | 10K | RC0603FR-1310KL | JP3 shorted with 0R (0603)
19 | 3 | JP6,JP7,JP8 | 2K2 | RC0603FR-072K2L | JP3 shorted with 0R (0603) 2-3
20 | 3 | JP12,JP13,JP14 | 0K | RC0603JR-070RL | JP3 shorted with 0R (0603) 2-3
21 | 1 | L1 | 7443082015A | 7443082015A | WE-HCM_1088A
22 | 1 | L3 | 2u2 | DFE252012P-2R2M=P2 | L_1008_2520Metric
23 | 10 | R3,R7,R12,R16,R18,R23,R25,R26,R27,R29 | 10K | RC0603FR-1310KL | R_0603_1608Metric
24 | 2 | R4,R13 | 56K | RT0603DRD0756KL | R_0603_1608Metric
25 | 2 | R5,R10 | 0R | RC0603JR-070RL | R_0603_1608Metric
26 | 3 | R6,R33,R34 | 12K1 | RC0603FR-1312K1L | R_0603_1608Metric
27 | 1 | R8 | 4K32 | RT0603FRE074K32L | R_0603_1608Metric
28 | 1 | R9 | 182K | ERJ-3EKF1823V | R_0603_1608Metric
29 | 4 | R11,R28,R37,R38 | 220R | RC0603JR-07220RL | R_0603_1608Metric
30 | 1 | R15 | 75K | RC0603FR-0775KL | R_0603_1608Metric
31 | 1 | R17 | 33K | RMCF0603FT33K0 | R_0603_1608Metric
32 | 3 | R20,R21,R32 | 2K2 | RC0603FR-072K2L | R_0603_1608Metric
33 | 4 | R22,R24,R35,R36 | 33R | RMCF0603FT33R0 | R_0603_1608Metric
34 | 1 | SW1 | PTS645SK50SMTR92 LFS | PTS645SK50SMTR92 LFS | PTS645
35 | 2 | TP1,TP5 | Test | 5001 | 5000
36 | 4 | TP2,TP3,TP4,TP6 | Test | 5000 | 5000
37 | 1 | U2 | TPS54KC23RZRR | TPS54KC23RZRR | RZR0016A-MFG
38 | 1 | U4 | SN74LVC244APWR | SN74LVC244APWR | PW20-L
39 | 1 | U5 | TLV75801PDBVR | TLV75801PDBVR | SOT-23-5
40 | 1 | U6 | PI6CG18801ZLIEX | PI6CG18801ZLIEX | QFN40P600X600X90-49N
41 | 1 | U7 | RY3420 | RY3420 | RY3420
42 | 1 | U8 | ASM1184E | ASM1184E | QFN-64-1EP_9x9mm_P0.5mm_EP5.2x5.2mm
43 | 1 | Y1 | ECS-250-8-33B2-CTN-TR3 | ECS-250-8-33B2-CTN-TR3 | XTAL_TSX-3225_25.0000MF20X-AJ3
 | 170 | total placements

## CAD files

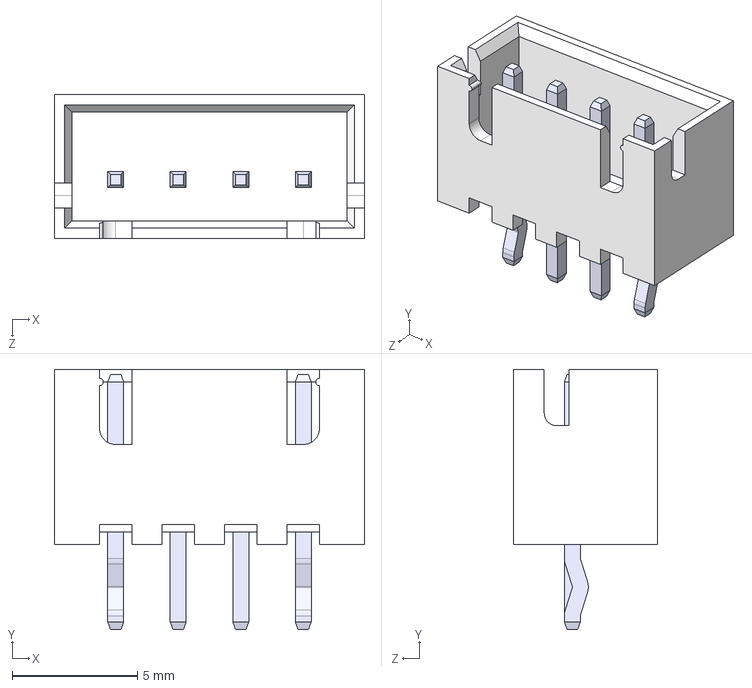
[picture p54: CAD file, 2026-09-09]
1.pcb/KiCad-library/av_lib/3dmodels/B4B-XH-A.step
12.4 x 10.4 x 5.75 mm

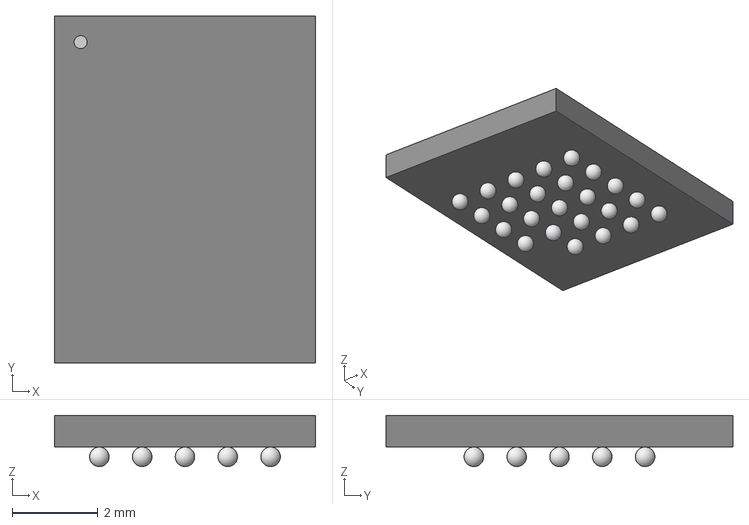
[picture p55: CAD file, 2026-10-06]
1.pcb/KiCad-library/EEZ-Kicad-libraries/3dmodels/APS256XXN-OBR-BG_APY.step
6.10 x 8.10 x 1.20 mm

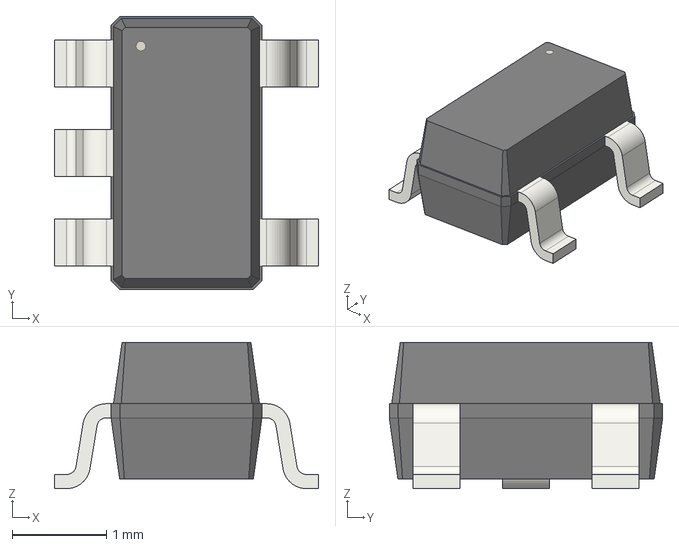
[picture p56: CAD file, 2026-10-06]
1.pcb/KiCad-library/kicad-stock-lib/3dmodels/SOT-23-5.step
2.80 x 2.90 x 1.55 mm

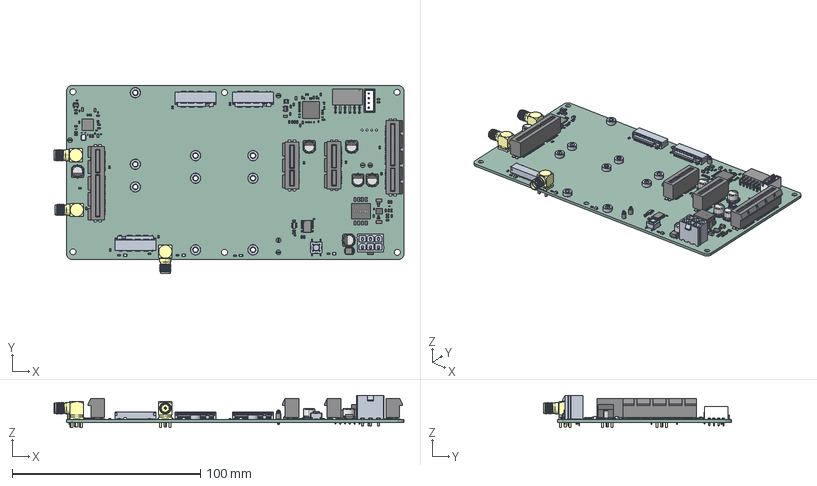
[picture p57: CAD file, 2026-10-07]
1.pcb/openpci2-backplane/production/openpci2-backplane.step
185.7 x 99.8 x 17.1 mm
132136_SW0001 x 3
C_0402_1005Metric x 62
LTST-C170TGKT x 4
EEEFK0J101AL x 6
C_0603_1608Metric x 5
R_0603_1608Metric x 47
C_0805_2012Metric x 13
C_1206_3216Metric x 2
C-1-2199230-6 x 3
NUT x 9
SM6T27A
SOT-23-5 x 2
1269AS-H-3R3M#
74430820xxA
10061913-101CLF x 2
L_0402_1005Metric x 3
BLUENRG-248
LeadsArray x 2
TSX-3225 50.0000MF25V-W
BODY-TSSOP
LEAD-TSSOP x 20
PIN1
10061913-100RLF x 2
BxB-XH-A_04
RZR0016A_FRAME
RZR0016A_MOLD
QFN_64_1EP_9x9mm_P05mm_EP47x47mm
openpci2-backplane_PCB

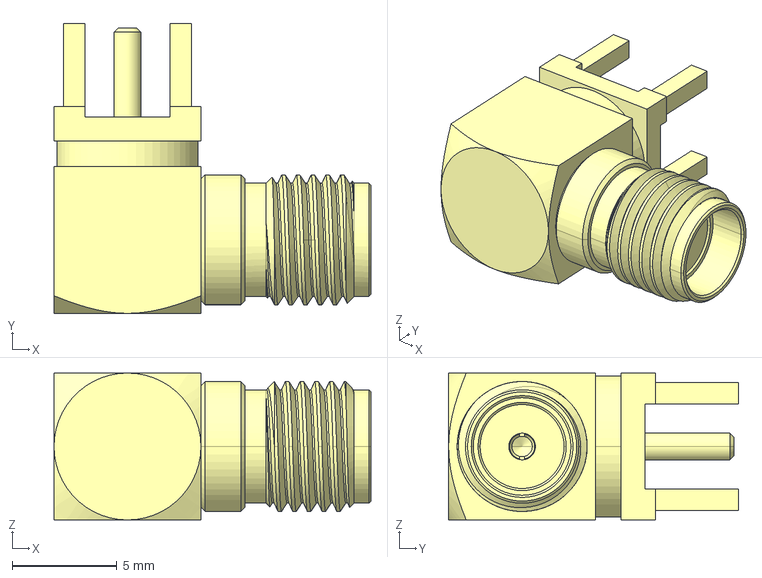
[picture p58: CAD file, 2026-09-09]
1.pcb/KiCad-library/av_lib/3dmodels/BWSMA-KWE-Z001.step
15.1 x 13.8 x 7.00 mm

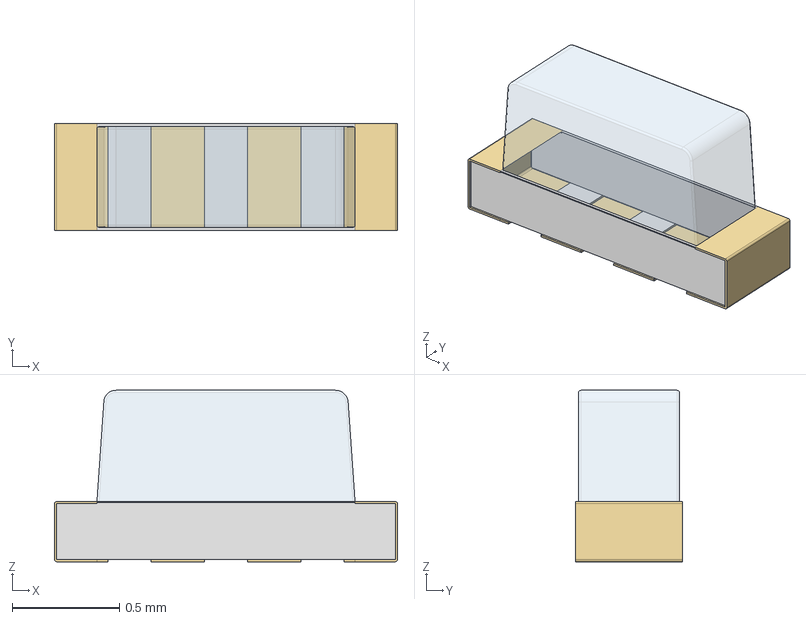
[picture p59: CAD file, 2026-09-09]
1.pcb/KiCad-library/chili-chips-lib/3dmodels/IN-S63TBS5R5G5B.stp
1.60 x 0.5 x 0.8 mm

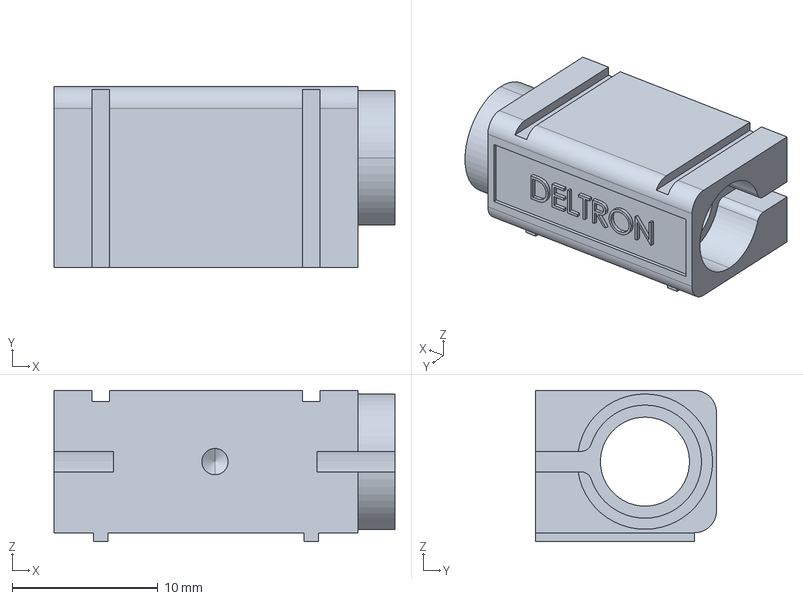
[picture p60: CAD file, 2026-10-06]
1.pcb/KiCad-library/EEZ-Kicad-libraries/3dmodels/571-0100.step
23.4 x 12.4 x 10.3 mm

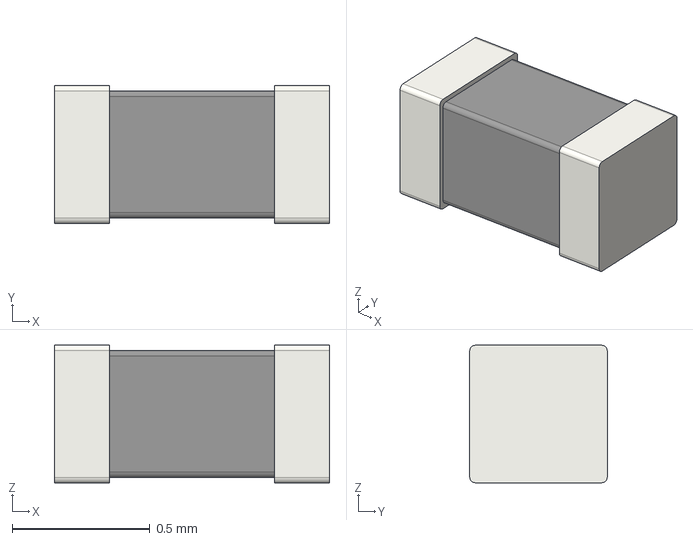
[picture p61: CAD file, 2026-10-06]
1.pcb/KiCad-library/kicad-stock-lib/3dmodels/L_0402_1005Metric.step
1.00 x 0.5 x 0.5 mm

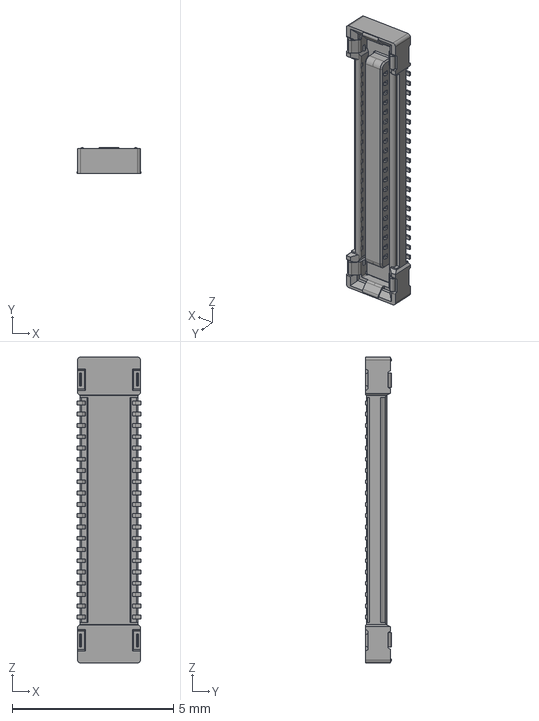
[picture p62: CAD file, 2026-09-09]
1.pcb/KiCad-library/chili-chips-lib/3dmodels/BM23PF0.8-40DS-0.35V_51_.step
1.98 x 0.8 x 9.50 mm

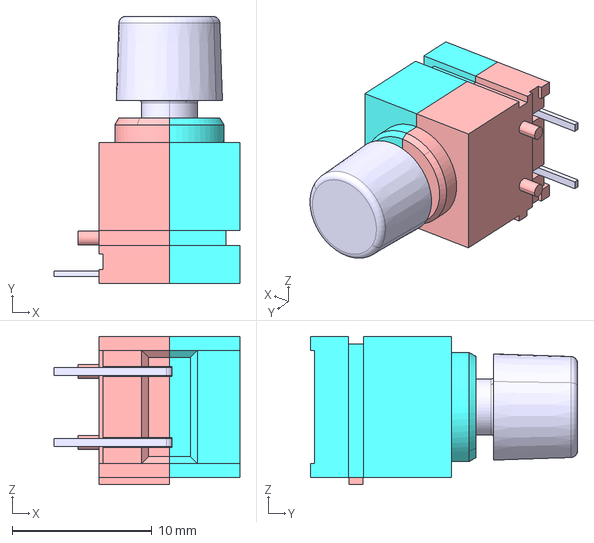
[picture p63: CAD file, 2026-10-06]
1.pcb/KiCad-library/EEZ-Kicad-libraries/3dmodels/1852_6232.stp
13.3 x 19.1 x 10.6 mm

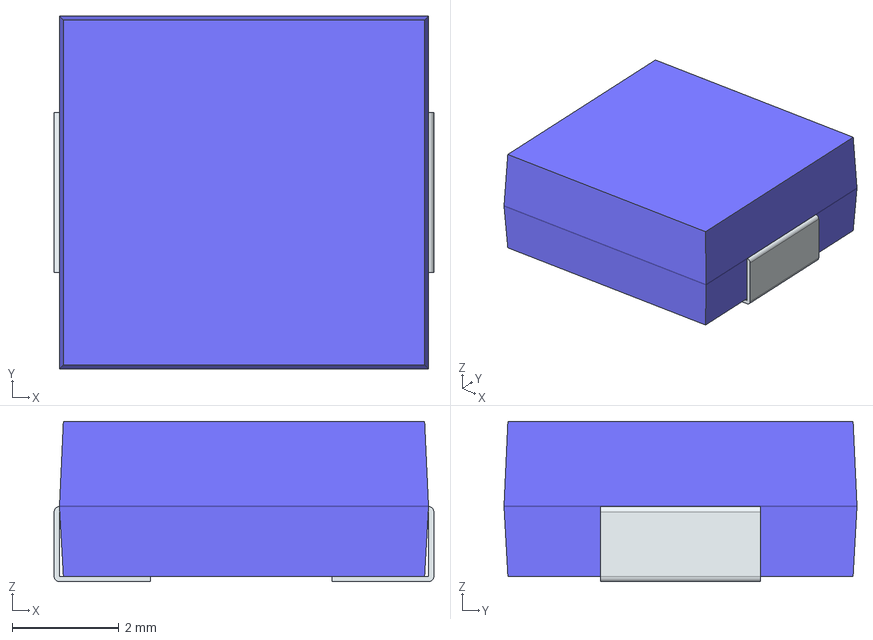
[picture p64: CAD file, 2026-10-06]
1.pcb/KiCad-library/EEZ-Kicad-libraries/3dmodels/SRP6030WA-8R2M.stp
7.10 x 6.60 x 3.00 mm
FilletPin1
FilletPin2

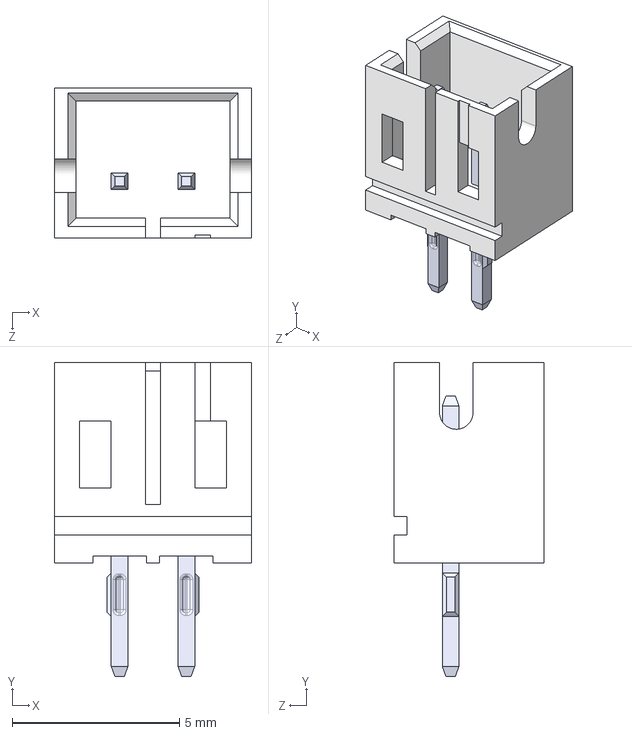
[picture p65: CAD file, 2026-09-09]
1.pcb/KiCad-library/chili-chips-lib/3dmodels/B2B-PH-K-S-GW--3DModel-STEP-56544.STEP
5.90 x 9.40 x 4.50 mm

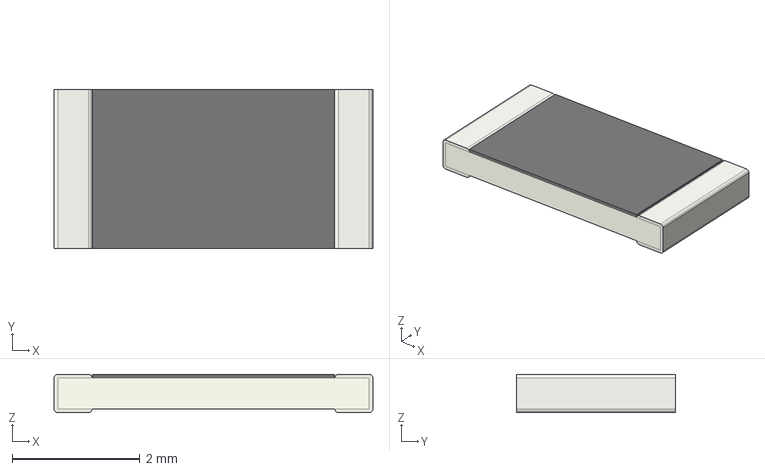
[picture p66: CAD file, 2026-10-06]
1.pcb/KiCad-library/EEZ-Kicad-libraries/3dmodels/R_2010_5025Metric.step
5.00 x 2.50 x 0.6 mm

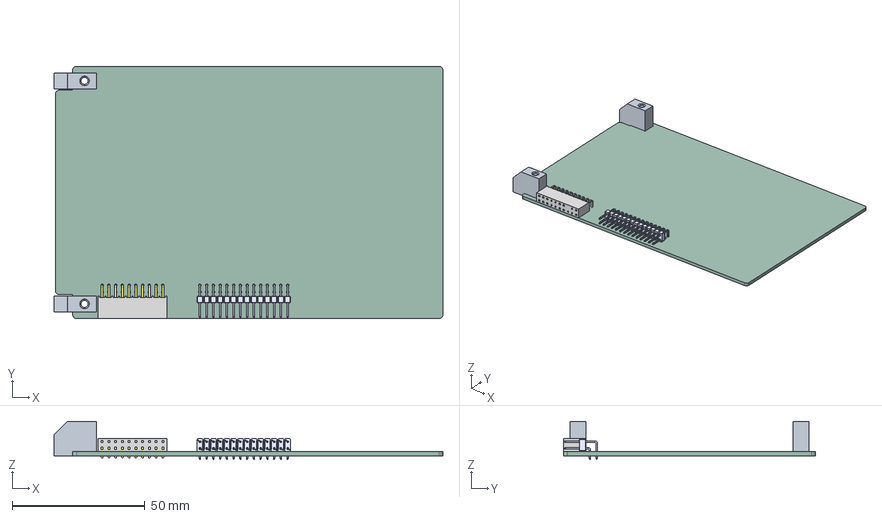
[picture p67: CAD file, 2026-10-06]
1.pcb/KiCad-library/EEZ-Kicad-libraries/3dmodels/EEZ DIB v1.2 module.step
146.5 x 95.1 x 14.4 mm
77317-104-28LF
SSW-110-02-T-D-RA
DIB module_PCB

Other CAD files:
1.pcb/KiCad-library/chili-chips-lib/3dmodels/WLCSP9_1P2X1P2_ONS.step
1.pcb/KiCad-library/EEZ-Kicad-libraries/3dmodels/FUSE_20x5mm.step
1.pcb/KiCad-library/chili-chips-lib/3dmodels/SOD882_NEX.step
1.pcb/KiCad-library/EEZ-Kicad-libraries/3dmodels/PW0024A.stp
1.pcb/KiCad-library/EEZ-Kicad-libraries/3dmodels/0353130360.stp
1.pcb/KiCad-library/EEZ-Kicad-libraries/3dmodels/0472720024.stp
1.pcb/KiCad-library/EEZ-Kicad-libraries/3dmodels/0862-1J1T-43-F.step
1.pcb/KiCad-library/EEZ-Kicad-libraries/3dmodels/1-1571986-1.step
1.pcb/KiCad-library/EEZ-Kicad-libraries/3dmodels/1-726388-2--3DModel-STEP-1.STEP
1.pcb/KiCad-library/EEZ-Kicad-libraries/3dmodels/10164227-1004A1RLF--3DModel-STEP-533217.STEP
1.pcb/KiCad-library/EEZ-Kicad-libraries/3dmodels/10164228-1001A1RLF.stp
1.pcb/KiCad-library/EEZ-Kicad-libraries/3dmodels/125CDMCCDS-330MC.stp
1.pcb/KiCad-library/EEZ-Kicad-libraries/3dmodels/1565918-4.stp
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

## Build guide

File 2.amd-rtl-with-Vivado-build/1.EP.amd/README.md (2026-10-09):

# PCIE EndPoint (EP) - AMD IP Implementation

This project implements a **Programmed I/O (PIO)** PCIE Endpoint using the proprietary **Xilinx 7-Series Integrated Block for PCI Express**. It serves as the "Target" device for verification, allowing the Root Complex (RC) to perform Memory Read and Memory Write transactions.

## IP Core Configuration

The following table summarizes the key parameters configured in the Vivado IP Generator for this design:

<div align="center">

| Parameter | Value | Description |
| :--- | :--- | :--- |
| **Device Port Type** | **Endpoint** | Acts as a peripheral device. |
| **Link Speed** | **Gen2 (5.0 GT/s)** | Backwards compatible with Gen1. |
| **Lane Width** | **x1** | Configured for single-lane operation. |
| **User Interface** | **AXI4-Stream** | 64-bit width running at 62.5 MHz. |
| **Vendor ID** | **`0x10EE`** | Xilinx, Inc. |
| **Device ID** | **`0x7021`** | 7-Series Integrated Block for PCIE. |
| **Class Code** | **`0x058000`** | Memory Controller. |
| **BAR0** | **2 KB** | 32-bit Memory-Mapped I/O space. |
| **Ref Clock** | **100 MHz** | Provided by the openBackplane. |

</div>

---

## Design Architecture

The structure follows the standard Xilinx PIO example design with modifications for the specific hardware platform.

### 1. IP Core Support Layer (`pcie_7x_0_support.v`)
This wrapper manages the interface between the FPGA fabric and the dedicated PCIE Hard block.
*   **PCIE Hard Macro:** Handles the Transaction Layer (TLP), Data Link Layer, and Physical Layer (SerDes/GTP).
*   **PIPE Clock Module (`pcie_7x_0_pipe_clock.v`):** Manages the FPGA's MMCM/PLL. It generates the `user_clk` and handles the **dynamic frequency switching** required when the link trains up from Gen1 (125 MHz internal clock) to Gen2 (250 MHz internal clock).

### 2. App Wrapper (`pcie_app_7x.v`)
*   Manages the AXI-Stream interface and instantiates the PIO engine.
  
### 3. PIO Engine (`PIO_EP.v`)
*   **RX Engine:** Decodes incoming TLPs (MemWr, MemRd).
*   **TX Engine:** Generates Completion TLPs (CplD) to return data to the Host during read requests.
*   **Memory Access:** The actual storage logic where data is read from or written to, utilizing internal Block RAM as the device memory.

---

### Visual Status
*   **led_data_payload:** These LEDs display the lower 4 bits of the received data payload to visually confirm successful Memory Write transactions.

----
#### End-of-Document

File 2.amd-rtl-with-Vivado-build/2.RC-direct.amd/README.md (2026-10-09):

# Root Complex (Direct Connection) - AMD IP Implementation

This project implements a PCIE Root Complex (RC) for a direct point-to-point connection using the proprietary Xilinx 7-Series Integrated Block for PCI Express. It is designed as a standalone hardware tester that automatically configures and verifies a connected Endpoint.

Unlike the open-source version, this implementation does not use a RISC-V CPU. Instead, it utilizes Xilinx's **Configurator** and **PIO Master** modules to manage the PCIE link and perform automated hardware testing.

## IP Core Configuration

The following table summarizes the key parameters configured in the Vivado IP Generator for this Root Port design:

<div align="center">

| Parameter | Value | Description |
| :--- | :--- | :--- |
| **Device Port Type** | **Root Port** | Acts as the PCIE Host. |
| **Link Speed** | **Gen2 (5.0 GT/s)** | High-speed data rate. |
| **Lane Width** | **x1** | The default, and the committed deliverable. As a bonus, **x4** (Gen2) has also been tested on hardware. |
| **User Interface** | **AXI4-Stream** | 64-bit width @ 62.5 MHz. |
| **Vendor ID** | **`0x10EE`** | Xilinx, Inc. |
| **Device ID** | **`0x7121`** | 7-Series Root Port ID. |
| **Class Code** | **`0x060000`** | Bridge Device / Host Bridge. |
| **BAR0** | **2 KB** | Internal memory space for the Root Port. |
| **Ref Clock** | **100 MHz** | Provided by the openBackplane. |

</div>

---

## Design Architecture

The design is structured hierarchically to automate the PCIE enumeration and testing process:

### 1. Top Module (`RC_direct_amd.v`)
* Manages the AXI-Stream interface and instantiates the **Configurator** and **PIO Master** modules.

### 2. IP Core Support Layer (`pcie_7x_0_support.v`)
This wrapper manages the interface between the FPGA fabric and the dedicated PCIE Hard block.
*   **PCIE Hard Macro:** Handles the Transaction Layer (TLP), Data Link Layer, and Physical Layer (SerDes/GTP).
*   **PIPE Clock Module (`pcie_7x_0_pipe_clock.v`):** Manages the FPGA's MMCM/PLL. It generates the `user_clk` and handles the **dynamic frequency switching** required when the link trains up from Gen1 (125 MHz internal clock) to Gen2 (250 MHz internal clock).

### 3. Configurator Layer (`cgator.v`)
Responsible for the initialization sequence required to perform enumeration and establish a functional connection (link).
*   **Controller:** Logic that reads a sequence of configuration commands from a binary ROM file (`cgator_cfg_rom.data`).
*   **Enumeration:** Automatically performs device discovery, probes BAR sizes, assigns memory addresses, and configures the Command Register to enable the device for communication.

### 4. PIO Master (`pio_master.v`)
An automated test engine that triggers immediately after enumeration finishes.
*   **Test Sequence:** Uses the `pio_master_controller` to send a **Memory Write**, followed by a **Memory Read** to verify the write.
*   **Verification:** The `pio_master_checker.v` compares the returned data with the original payload to confirm link integrity.

---

### Fully Automated Bring-up
*  No software or CPU intervention is required. Upon releasing the system reset button on the `openPCIE Backplane`, the hardware logic automatically trains the link and configures the Endpoint.

### Visual Status
*   **`led_link_up`:** This LED is connected directly to the PCIE core status signal. It lights up as soon as the physical link is established and the devices are ready to communicate.

---

## Usage Note
Since this design is strictly RTL-based, the test parameters are hard-coded. To change the target address or the data value used in the test, you must:
1.  Modify the **`cgator_cfg_rom.data`** file for enumeration changes.
2.  Update the `localparam` values in **`pio_master_controller.v`** for test data changes.

For a more flexible, software-driven approach with a RISC-V processor, refer to the [RC-direct.opensource](../../2.rtl/2.RC-direct.opensource/) implementation.

----
#### End-of-Document

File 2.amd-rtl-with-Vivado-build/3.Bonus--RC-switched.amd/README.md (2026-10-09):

# Root Complex (Switched Connection) - AMD IP Implementation

This is a bonus deliverable, above and beyond our original plan. 

[Here](https://github.com/chili-chips-ba/openPCIE/tree/main/1.pcb#usecase-2-switched-fpga_rc-to-fpga_ep-gen2-x1) is the corresponding hardware setup. 

In order to make it work, we had to get to the root of what looked like ASM1184e overheating problem, see slide 17 of [presentation](https://github.com/chili-chips-ba/openPCIE/blob/main/1.pcb/0.doc/OpenPCIE%20backplane%20presentation.pptx). This turned out to be an undersized LDO, which the RevB openPCIE backplane replaces with a DC/DC buck.

Once that was taken out of the way, the test procedure was very similar to what was done to validate the [direct](../2.RC-direct.amd) topology.

----

## Key RTL Differences (Direct vs. Switched Topology)

There are two major modifications that need to be made to handle the Switched topology:

### 1. Dynamic Bus and Device Routing
In a direct connection, the Endpoint is always located at a fixed address (typically Bus 1, Device 0). Therefore, in previous AMD implementation, this target address was hardcoded.

In a switched environment, the switch introduces multiple virtual PCI-to-PCI bridges. To communicate with devices behind the switch, the Root Port must dynamically route packets. To support this, the following signals were introduced to the Packet Generator:
* `wire [7:0] pkt_bus_num;`
* `wire [4:0] pkt_dev_num;`

Instead of assuming the target is always Bus 1, the Controller now extracts the exact Bus and Device number for every single transaction directly from the configuration ROM and passes it to the Packet Generator. This also allows the hardware to automatically differentiate between **Type 0** (local) and **Type 1** (cross-bridge) Configuration TLPs.

### 2. Configuration ROM Updates (`cgator_cfg_rom.data`)
Because the routing is now dynamic, the binary format of the configuration ROM had to be updated. The upper bits of the header line (previously unused) now strictly define the `[Bus 8-bit]` and `[Device 5-bit]` target for that specific transaction.

Furthermore, the initialization sequence itself is vastly different. Instead of just configuring one Endpoint, the ROM file now executes a 3-step bring-up process:

* **STEP 1: Switch Upstream Port (Bus 1, Dev 0)** 
  Configures the primary entry point of the switch, assigning the overall memory limits and subordinate bus ranges.
* **STEP 2: Switch Downstream Ports (Internal Bus 2)** 
  Iterates through the internal downstream ports of the switch (e.g., Dev 1, 3, 5, 7). Each port acts as a virtual bridge and is assigned a dedicated Secondary Bus number (Buses 3, 4, 5, and 6) and a specific Memory Base/Limit window.
* **STEP 3: Endpoint Configuration (Buses 3-6)** 
  Finally, the actual Endpoints (cards plugged into the slots) are addressed using their newly assigned bus numbers. Their BARs are configured to fit exactly within the memory windows defined in Step 2.

------

#### End-of-Document

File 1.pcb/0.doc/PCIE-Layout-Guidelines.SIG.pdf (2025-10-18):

Copyright © 2004, PCI-SIG, All Rights Reserved | 1

## Board Design Guidelines for PCI Express™ Architecture

## Zale Schoenborn Co-Chair, PCI Express Electrical WG

PCI-SIG APAC Developers Conference | Copyright © 2004, PCI-SIG, All Rights Reserved | 2

## Agenda

ß Background
ß Layout considerations
ß System board requirements ß Add-in card designs
ß Signal validations
ß Summary

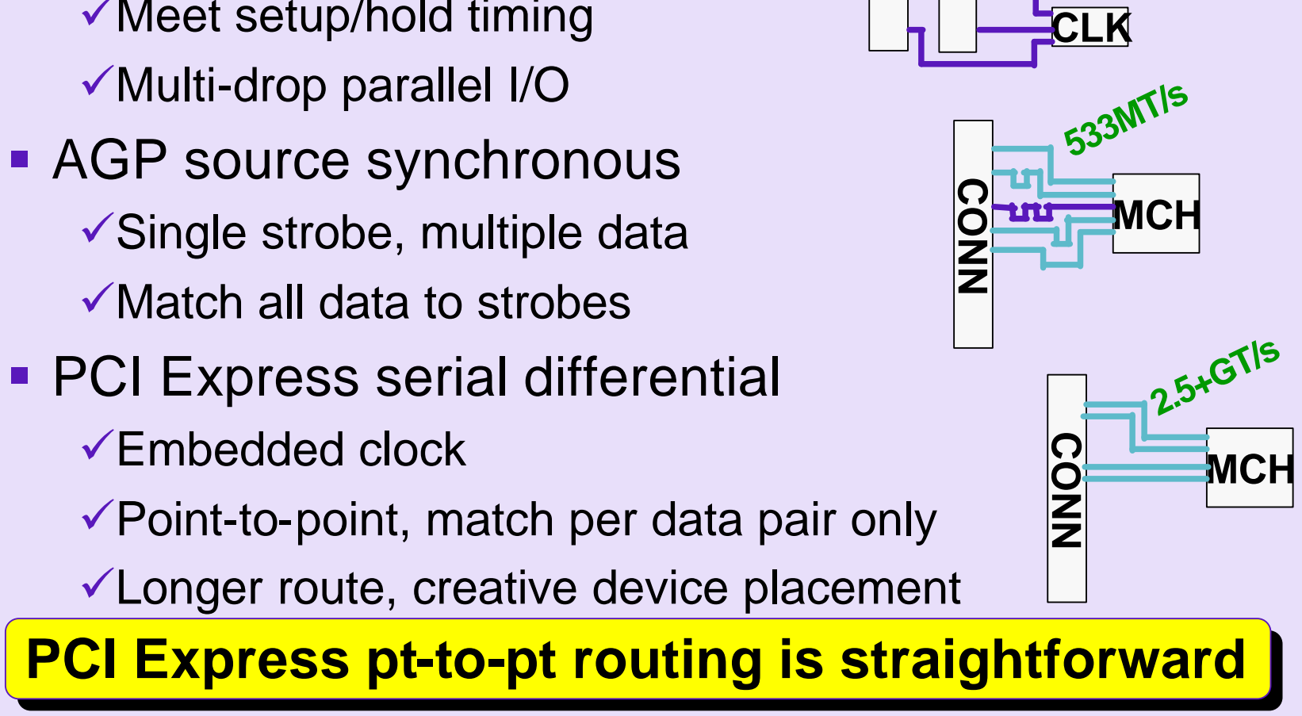
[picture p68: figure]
¸Multi-drop parallel I/O ß AGP source synchronous Şingle strobe, multiple data ¸Match all data to strobes ß PCI Express serial differential Ȩmbedded clock; Ļonger route, creative device placementCONN; MCH; CONN; CLK 533MT/s; PCI Express pt--; toto--pt routing is straightforward

PCI-SIG APAC Developers Conference | Copyright © 2004, PCI-SIG, All Rights Reserved | 3

## Bus Topology Evolution

ß PCI common clock
¸Meet setup/hold timing

¸Point-to-point, match per data pair only

CONN
MCH

CONN

133MT/s

Background

Serial Differential | Ḑiff pairs

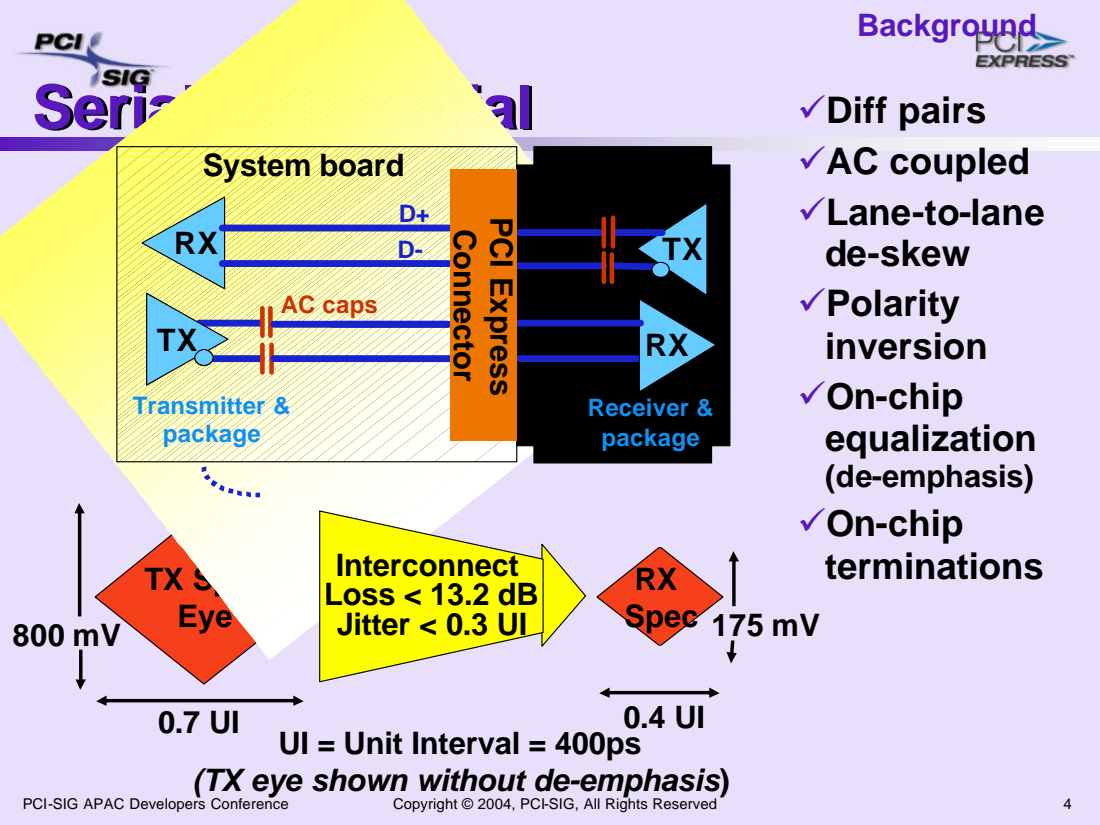
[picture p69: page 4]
PCI-SIG APAC Developers Conference; Copyright © 2004, PCI-SIG, All Rights Reserved; TX Spec Eye; RX Spec; System board; AC caps; Transmitter & package; Receiver & package; Interconnect Loss < 13.2 dB

Background
Jitter < 0.3 UI PCI Express Connector

Add-in card

¸AC coupled
Ļane-to-lane
de-skew
¸Polarity
inversion
¸On-chip
equalization
(de-emphasis)
terminations

(TX eye shown without de-emphasis)

UI = Unit Interval = 400ps

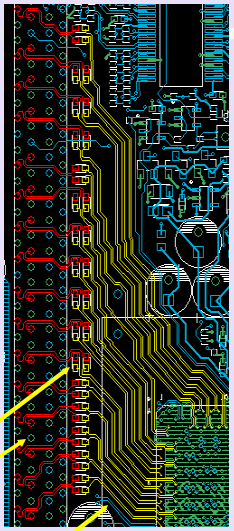
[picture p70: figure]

PCI-SIG APAC Developers Conference | Copyright © 2004, PCI-SIG, All Rights Reserved | 5

ß Trace length matching between pairs is not required
Ȩmbedded clock simplifies
routing rules
ß Longer motherboard traces
¸12+ inches possible
ß TX pairs usually route on top layer ¸AC coupling caps on TX traces on system board

Background

PCI Express x16 Connector
Trace Serpentines Not Required

AC Coupling Caps

## PCI Express Routing

## Interconnect Budget

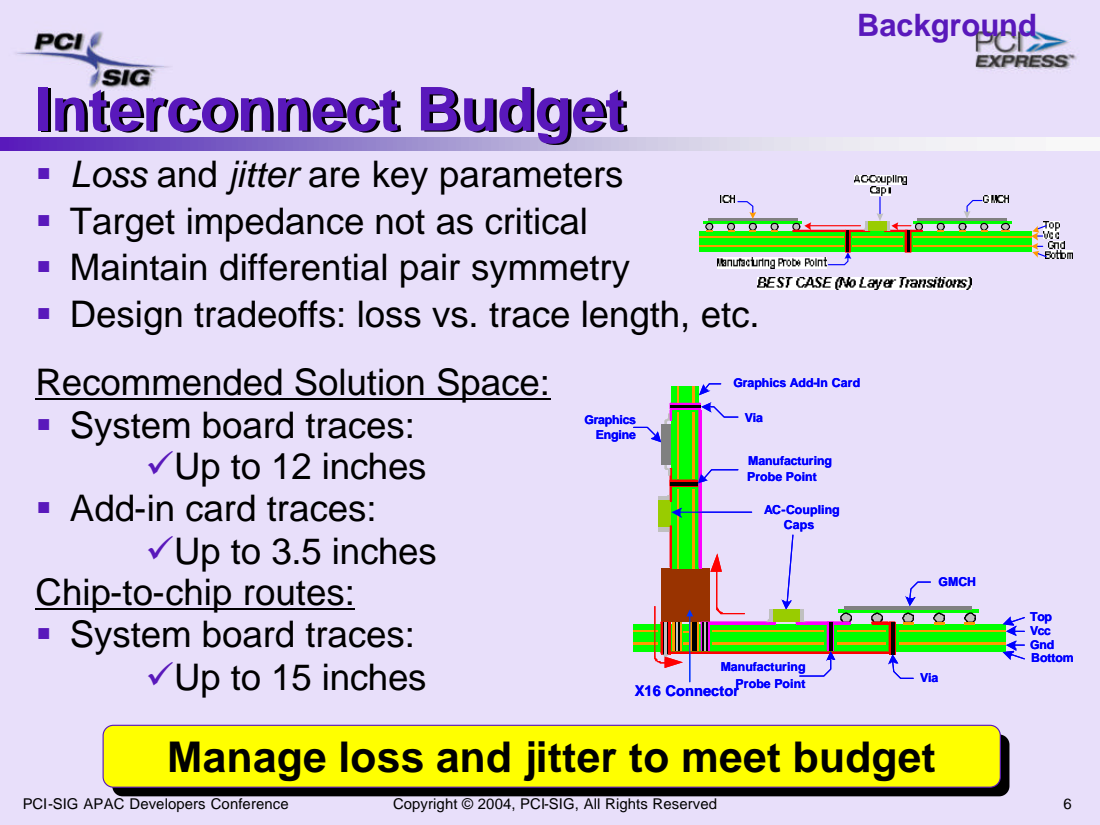
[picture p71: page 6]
PCI-SIG APAC Developers Conference; Copyright © 2004, PCI-SIG, All Rights Reserved; Background; AC-Coupling Caps; GMCH; Via; Manufacturing; Vcc Gnd; Top; Bottom; Graphics Engine; Manufacturing Probe Point

ß Loss and jitter are key parameters
ß Target impedance not as critical
ß Maintain differential pair symmetry
ß Design tradeoffs: loss vs. trace length, etc.
Recommended Solution Space:
ß System board traces:
¸Up to 12 inches
ß Add-in card traces:
¸Up to 3.5 inches
Chip-to-chip routes:
¸Up to 15 inches
Manage loss and jitter to meet budget

Graphics Add-In Card

Probe Point X16 Connector

## Stackup Design

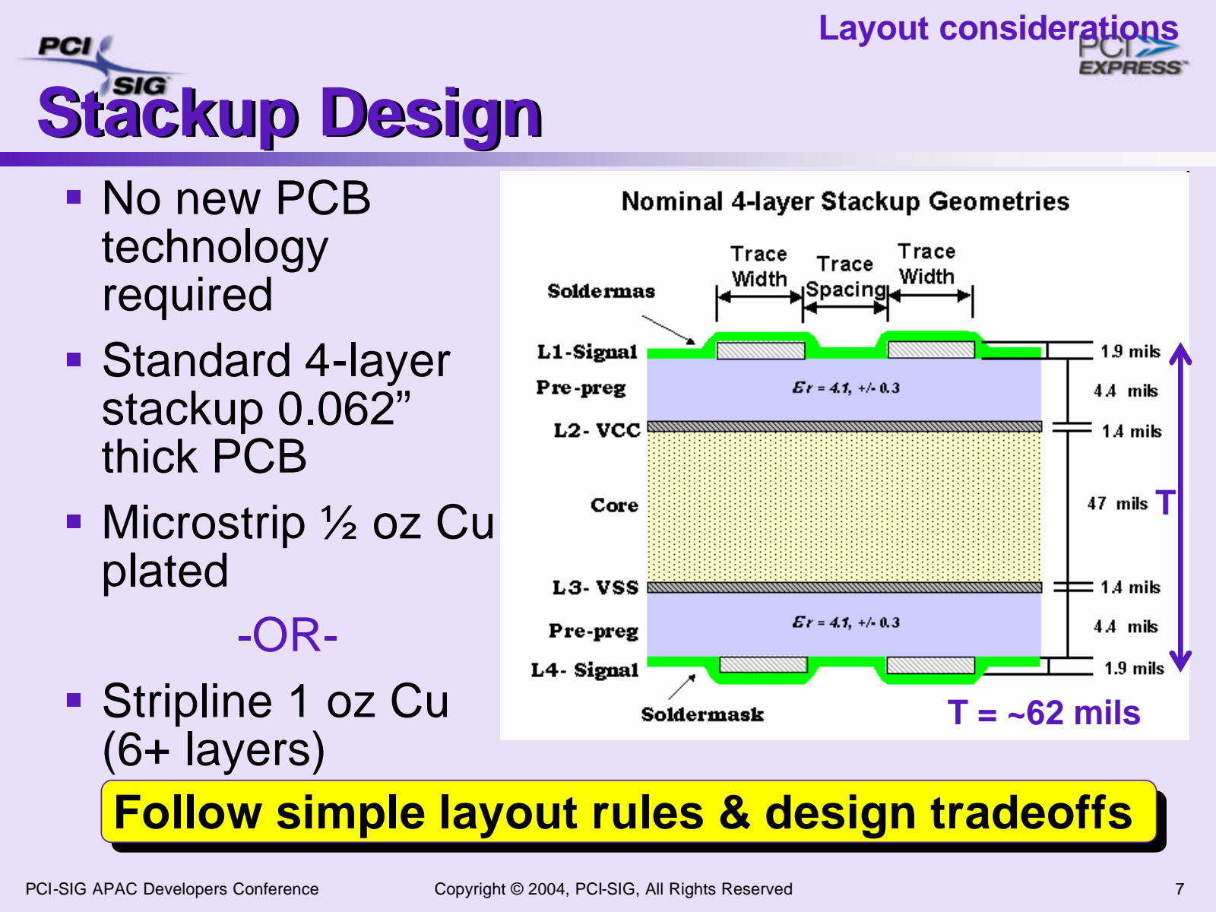
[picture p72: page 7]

PCI-SIG APAC Developers Conference | Copyright © 2004, PCI-SIG, All Rights Reserved | 7

ß No new PCB
technology
required
ß Standard 4-layer
stackup 0.062”
thick PCB
ß Microstrip ½ oz Cu
plated
-OR-ß Stripline 1 oz Cu
(6+ layers)
Follow simple layout rules & design tradeoffs

Layout considerations

T = ~62 mils

T

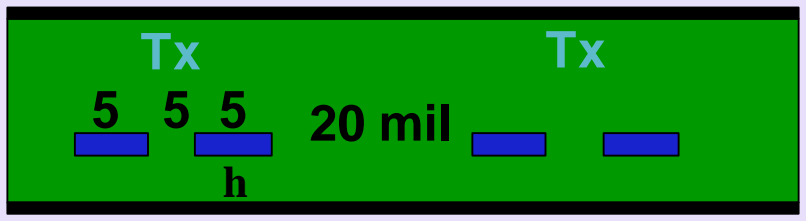
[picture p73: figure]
5 5 5 20 mil

PCI-SIG APAC Developers Conference | Copyright © 2004, PCI-SIG, All Rights Reserved | 8

ß Wide pair-to-pair spacing ⇒ minimize crosstalk ¸“Close” intra-pair spacing
ß Same geometry for interleaved/non-interleaved ß Example impedance targets:
Şingle-end Zo of 60 Ω ±15%
Ḑifferential Impedance of ~100 Ω ±20%

## Trace Geometry & Impedance

Layout considerations

Non-interleaved topology example

Interleaved topology example

Rx | Tx | Rx
Tx | Tx | Tx
h

### 20 mil 5 7 5

Microstrip

Stripline

Tx

Tx

w

w

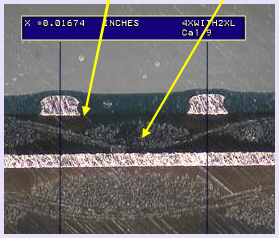
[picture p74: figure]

PCI-SIG APAC Developers Conference | Copyright © 2004, PCI-SIG, All Rights Reserved | 9

## FR4 Loss Considerations

ß Stackup: FR4 material
Ņarrow traces ⇒ loss ↑
Çopper roughness ⇒ loss ↑ Ḑielectrics with more resin material ⇒ loss ↑
ß Non-homogeneous dielectrics

Ļocalized Zo variation due to material weave ⇒ loss ↑
ß Wide differential impedance variation on μstrip traces Ȩtching and plating process ⇒

Resin Material

Glass Material

FR4 cross-section

Layout considerations

loss ↑

## Trace Length

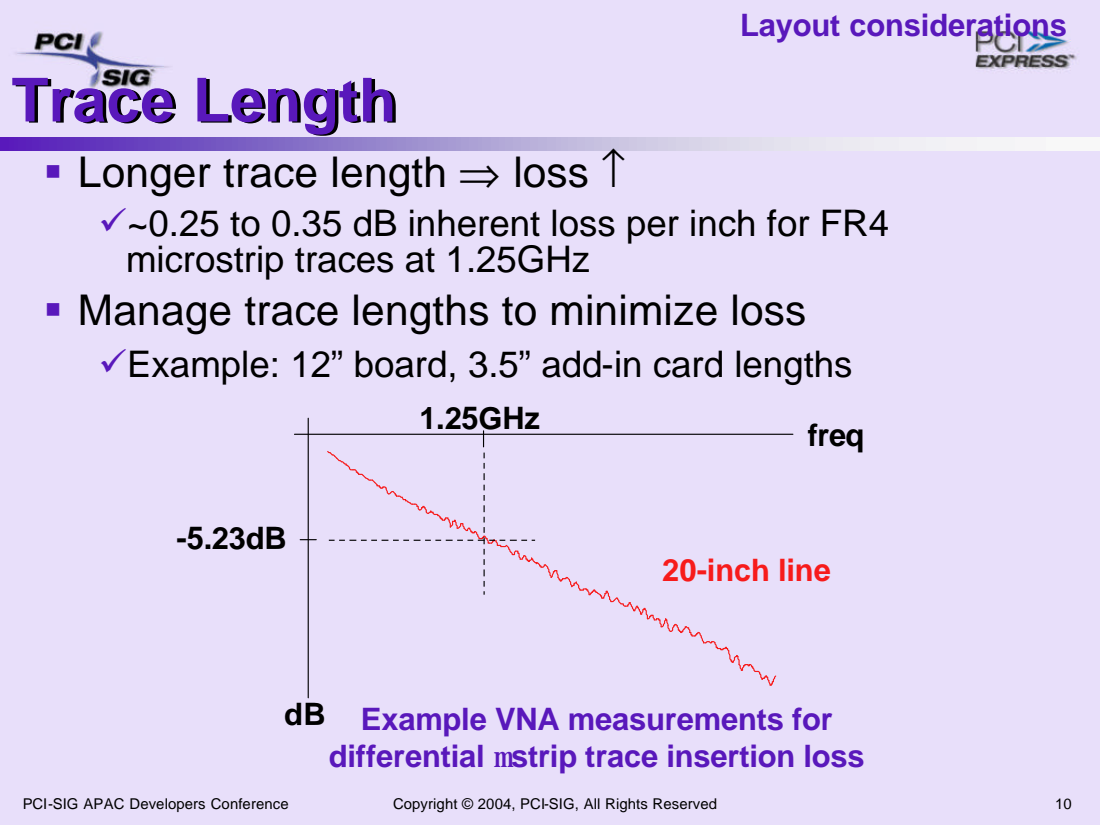
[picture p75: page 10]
PCI-SIG APAC Developers Conference; Copyright © 2004, PCI-SIG, All Rights Reserved; 1.25GHz; 20-inch line; freq; Layout considerations

ß Longer trace length ⇒ loss ↑
¸~0.25 to 0.35 dB inherent loss per inch for FR4
microstrip traces at 1.25GHz
ß Manage trace lengths to minimize loss
Ȩxample: 12” board, 3.5” add-in card lengths

Example VNA measurements for
differential mstrip trace insertion loss

## Trace Symmetry & Matching

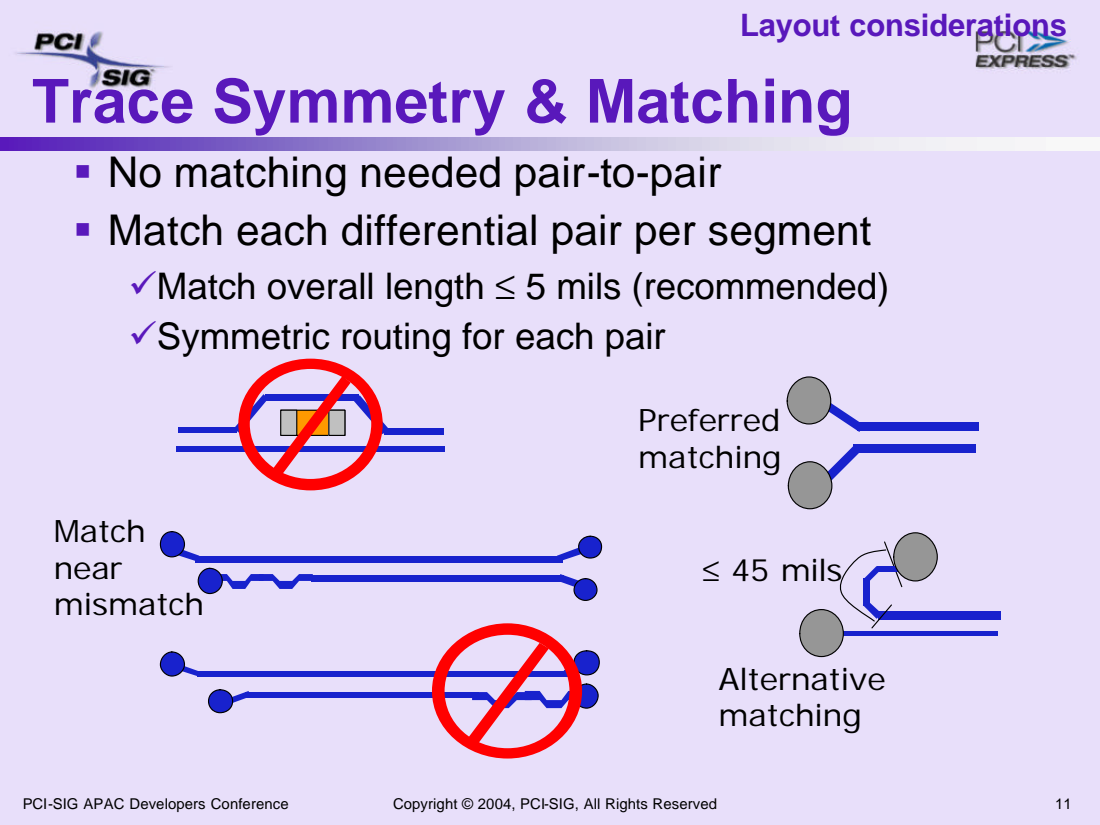
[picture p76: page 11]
PCI-SIG APAC Developers Conference; Copyright © 2004, PCI-SIG, All Rights Reserved; Layout considerations; Match near mismatch; Preferred matching; Alternative matching; ≤ 45 mils

ß No matching needed pair-to-pair
ß Match each differential pair per segment
¸Match overall length ≤ 5 mils (recommended)
Şymmetric routing for each pair

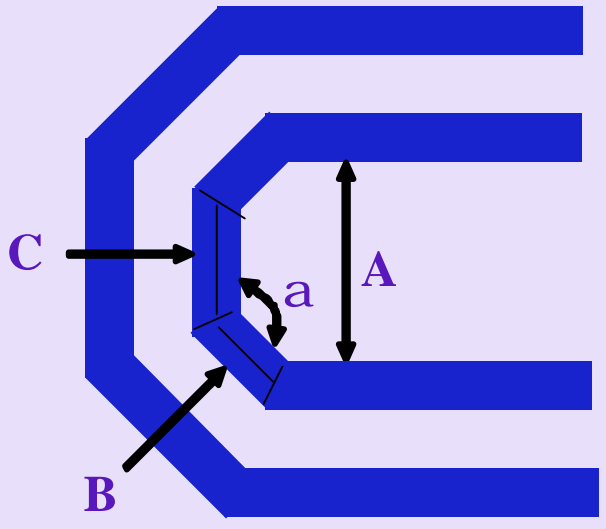
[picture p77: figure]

PCI-SIG APAC Developers Conference | Copyright © 2004, PCI-SIG, All Rights Reserved | 12

ß Avoid tight bends
Ņo 90° bends; impact to loss and jitter budgets
ß Keep angles >= 135° (a)
ß Maintain adequate air gap ¸ A >= 4x the trace width
ß Lengths of B, C >= 1.5x the width of the trace

ß Serpentines length is at least 3w for jog

## Bends and Small Serpentines

Layout considerations

S S1 < 2 S >3w

w

## Package Pin Field Breakout

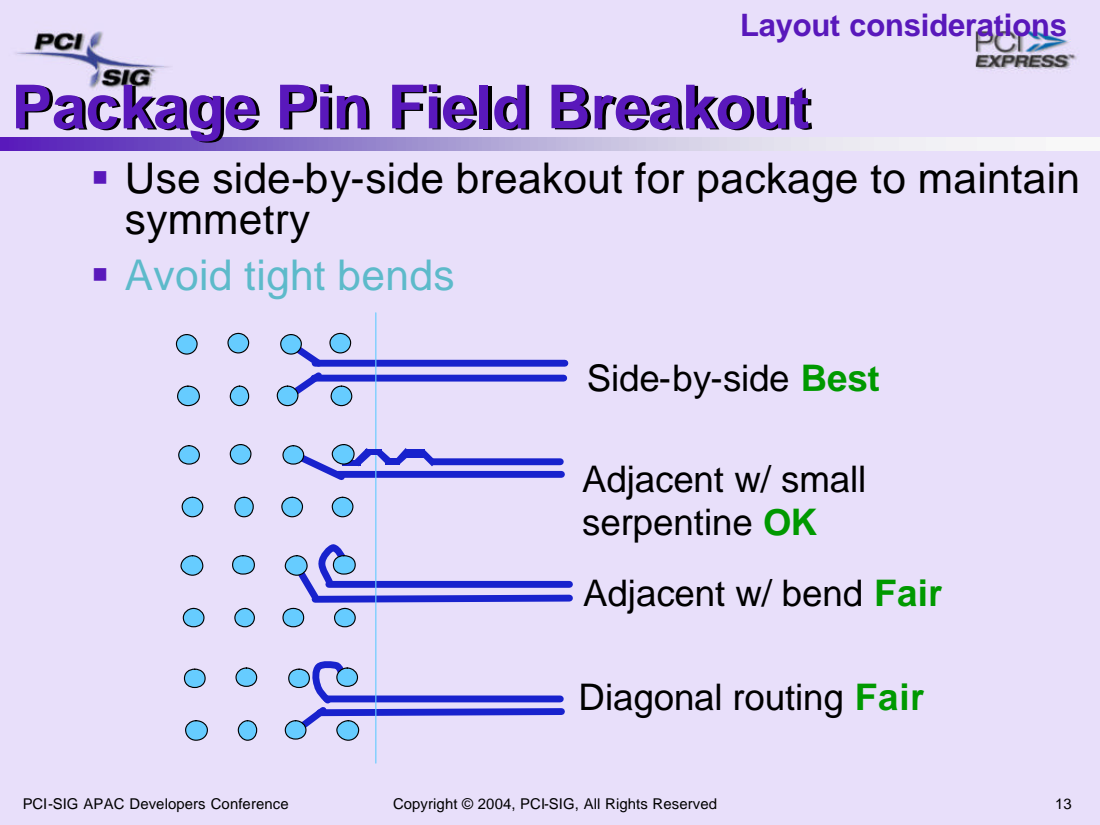
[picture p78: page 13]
PCI-SIG APAC Developers Conference; Copyright © 2004, PCI-SIG, All Rights Reserved; Layout considerations

ß Use side-by-side breakout for package to maintain
symmetry
ß Avoid tight bends

Side-by-side Best

Adjacent w/ small
serpentine OK
Adjacent w/ bend Fair

Diagonal routing Fair

## Reference Plane

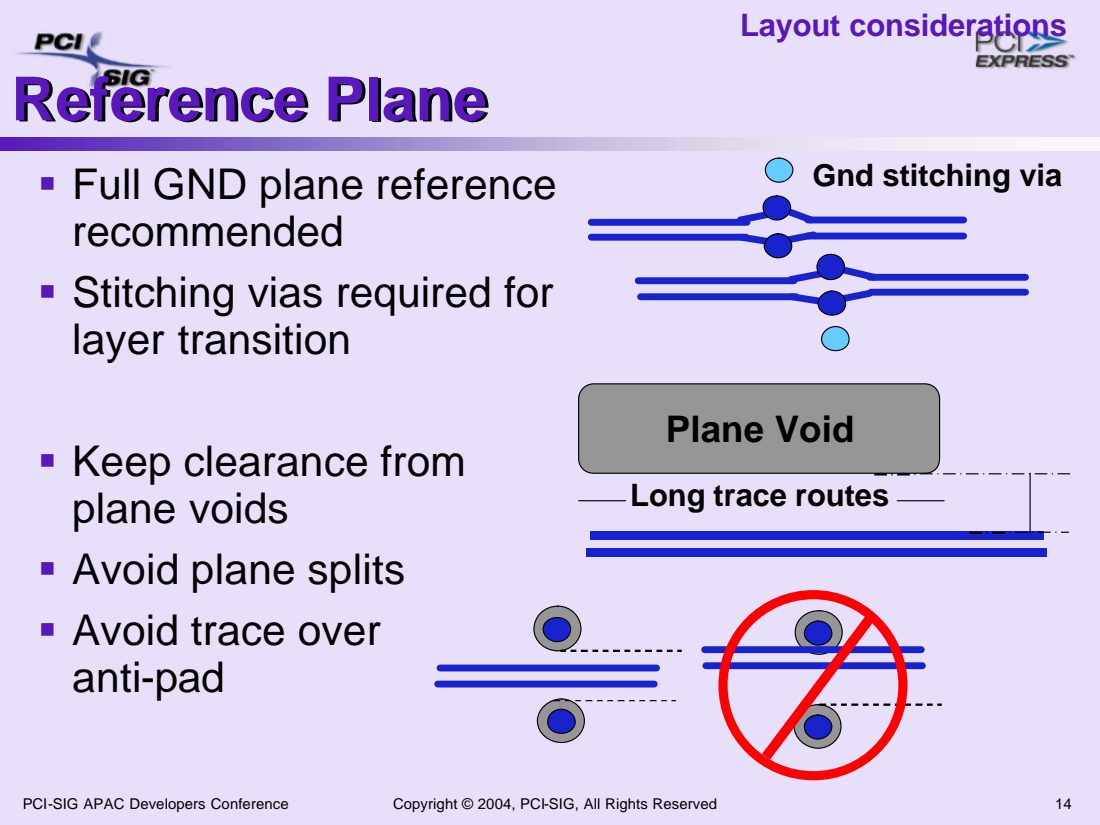
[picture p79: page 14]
PCI-SIG APAC Developers Conference; Copyright © 2004, PCI-SIG, All Rights Reserved; Layout considerations; Plane Void

ß Full GND plane reference
recommended
ß Stitching vias required for
layer transition

Gnd stitching via

ß Keep clearance from
plane voids
ß Avoid plane splits
ß Avoid trace over
anti-pad

Long trace routes

PCI-SIG APAC Developers Conference | Copyright © 2004, PCI-SIG, All Rights Reserved | 15

## AC Coupling Caps

ß Size: 0402 best, 0603 ok ß No 0805 size or C-packs
ß Symmetric placement best

ß Cap size: 0.1uF best
ß Same sizes for both D+/D-ß Cap location:
¸Along Tx pairs on system board ¸Along Tx pairs on add-in card

Layout considerations

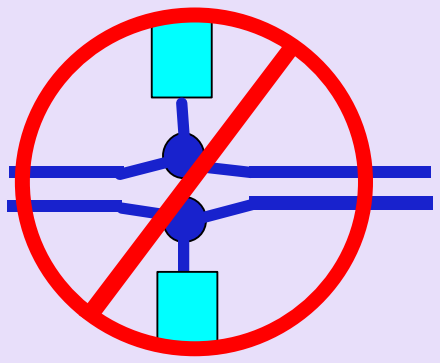
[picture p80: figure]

PCI-SIG APAC Developers Conference | Copyright © 2004, PCI-SIG, All Rights Reserved | 16

## Test Points & Vias

ß Minimize via usage
¸Up to 0.25 dB loss per via
¸Use via pad size ≤ 25 mil, hole size ≤ 14 mil; standard anti-pad size of 35 mil
ß Put test points or LAI pads in series (if used) Ņo stubs
¸Place symmetrically
¸Provide GND pads for single-ended probing
LAI pads

GND pads

Probe pads

Layout considerations

## Reference Clock

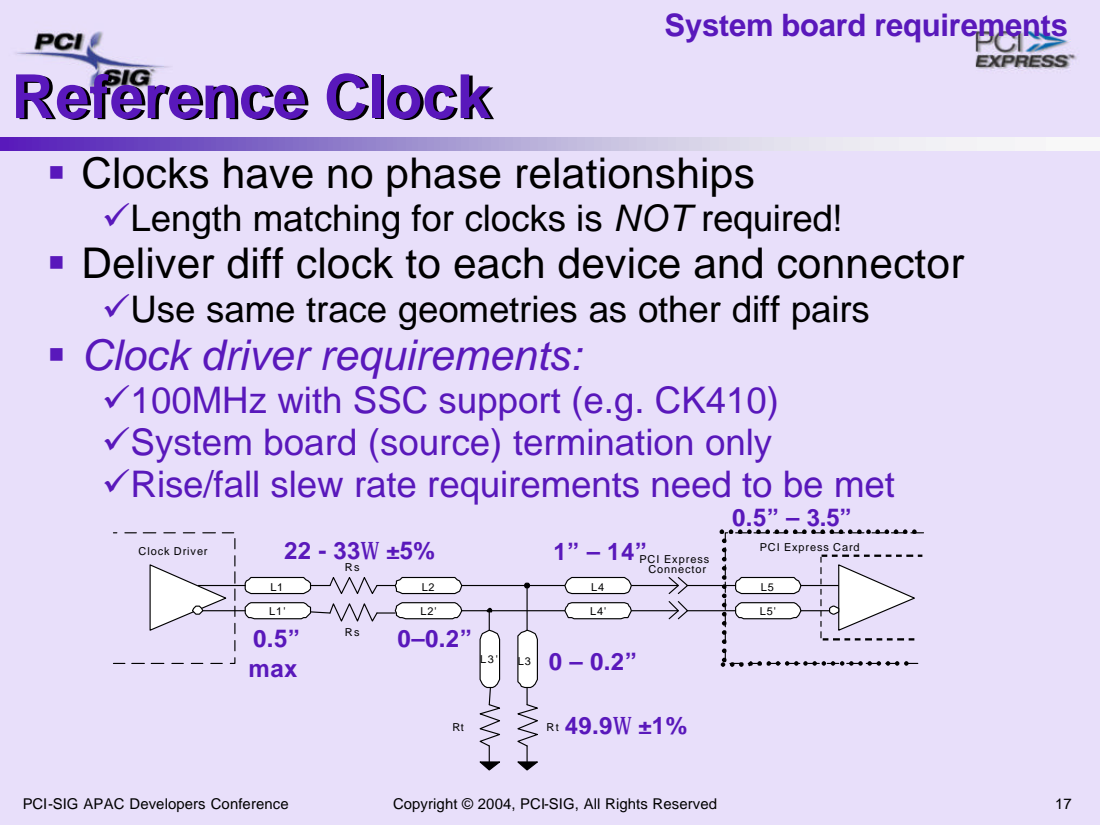
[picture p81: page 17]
PCI-SIG APAC Developers Conference; Copyright © 2004, PCI-SIG, All Rights Reserved; PCI Express Connector; Clock Driver; PCI Express Card; 0.5” max

System board requirements

ß Clocks have no phase relationships
Ļength matching for clocks is NOT required!
ß Deliver diff clock to each device and connector
¸Use same trace geometries as other diff pairs
ß Clock driver requirements:
¸100MHz with SSC support (e.g. CK410)
Şystem board (source) termination only
Ŗise/fall slew rate requirements need to be met

## Connector Layout

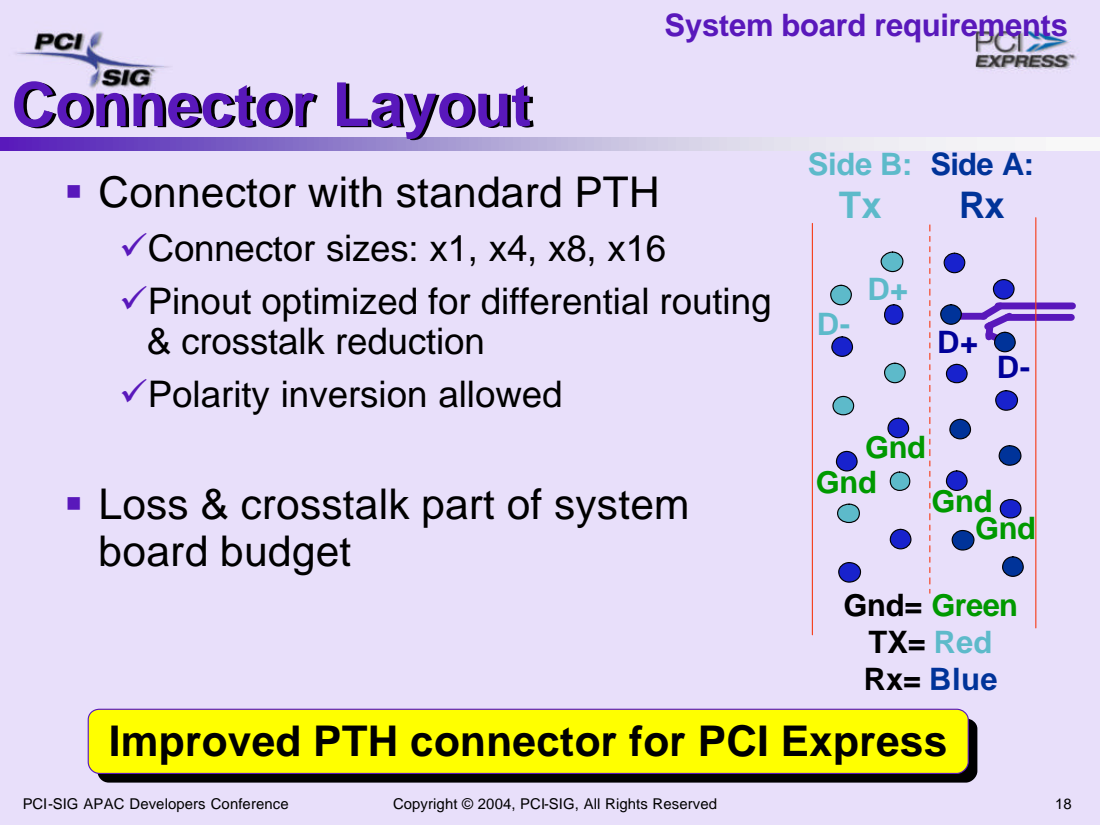
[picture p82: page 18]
PCI-SIG APAC Developers Conference; Copyright © 2004, PCI-SIG, All Rights Reserved; Side B: Tx; Side A: Rx; Gnd; Gnd= Green TX= Red Rx= Blue; Gnd Gnd

System board requirements

ß Connector with standard PTH
Çonnector sizes: x1, x4, x8, x16
¸Pinout optimized for differential routing
& crosstalk reduction
¸Polarity inversion allowed

ß Loss & crosstalk part of system
board budget

Improved PTH connector for PCI Express

PCI-SIG APAC Developers Conference | Copyright © 2004, PCI-SIG, All Rights Reserved | 19

## Power Rails

ß Increased current capability for x16 connector ¸Additional +12V pin; 1.1 Amp per pin capability
ß Helpful grouping of power supply pins Ȩases power delivery routing
ß ATX power supply connector
¸ 2x12 (recommended)
Power Rail | x16 Connector Spec
+3.3V Voltage Tolerance Current | ± 9% (max) 3.0 A (max)
+12V Voltage Tolerance Current | ± 8% (max) 5.5A (max)
+3.3Vaux Voltage Tolerance Current: Wake Non-Wake | ± 9% (max) 375 mA (max) 20 mA (max)

System board requirements

Update

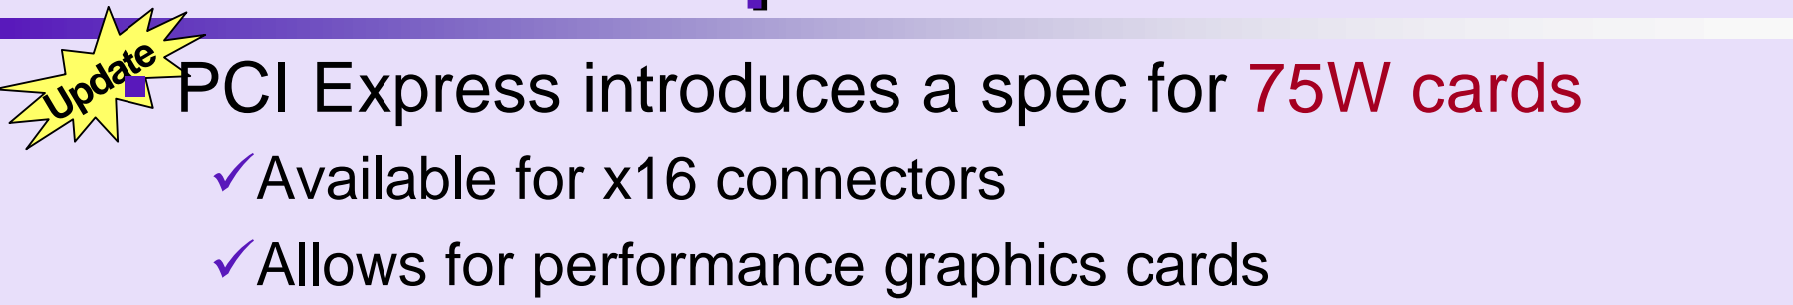
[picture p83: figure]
Update; ¸Available for x16 connectors ¸Allows for performance graphics cards

PCI-SIG APAC Developers Conference | Copyright © 2004, PCI-SIG, All Rights Reserved | 20

## Power Consumption

ß PCI Express introduces a spec for 75W cards

¸75W can be fully drawn thru x16 connector Ņote: ≤ 25W at initial power-up
(75W after configuration as a high power device) ß Up to 25W allowed for x1,x4,x8 cards

System board requirements

Connector Size ‡ Power Consumption Allowances
| X1 | x4/x8 | x16
Standard height | 10 W¹ (max) 25 W (max) | 25 W (max) | 25 W¹ (max) 75 W (max)
Low profile card | 10 W (max) | 10 W (max) | 25 W (max)
1. Max at initial power-up only.

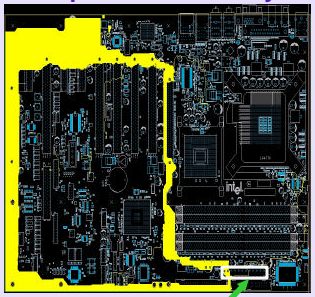
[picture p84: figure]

PCI-SIG APAC Developers Conference | Copyright © 2004, PCI-SIG, All Rights Reserved | 21

ß Ensure +3.3V & +12V tolerances at add-in card ß Max of 2%~3% MB +12V voltage drop (e.g. 360mV) Ţypical power supply = ± 5% drop
¸Balance trace width vs. length
Ȩxample: 100 mils min trace width,
= 12” length for +12V with 1oz Cu ß Proper power decoupling
¸Max current slew rate of 0.1A/μs Şuppress high freq coupling noise Ţune capacitor type/location
to board needs

## Power Delivery - 75W Support

System board requirements

Example uATX +12V layout

2x12 Power Supply Connector

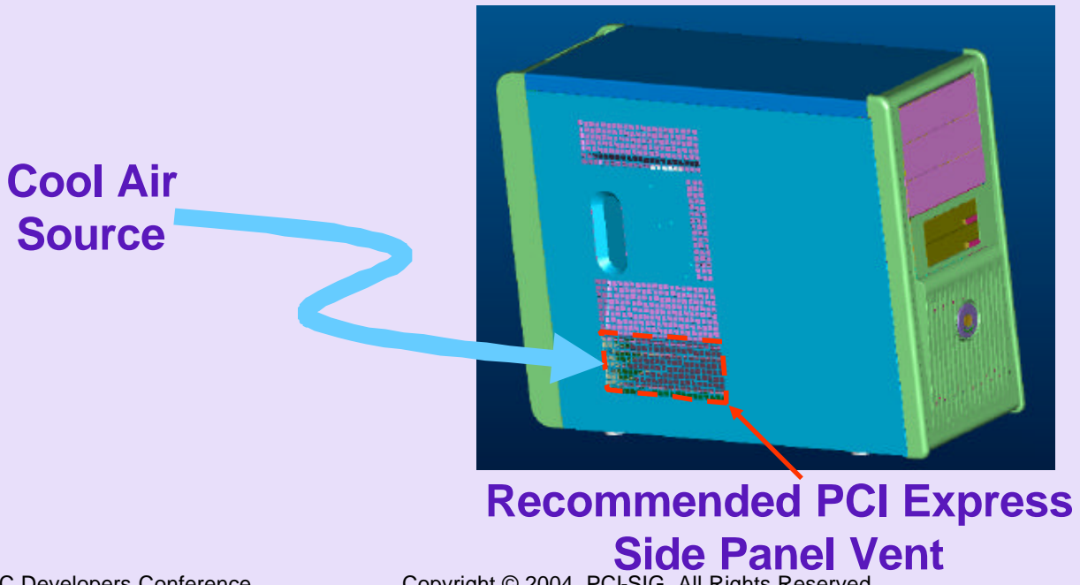
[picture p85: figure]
Recommended PCI Express Side Panel Vent; Cool Air Source

PCI-SIG APAC Developers Conference | Copyright © 2004, PCI-SIG, All Rights Reserved | 22

ß Platforms need to deliver cool air to x16 slot
¸Use side panel vents, ducting
¸75W card recommendation: ≤ 55oC air temp at graphics card fan intake
¸Use larger fans for better acoustics

## Thermal & Acoustic Management

System board requirements

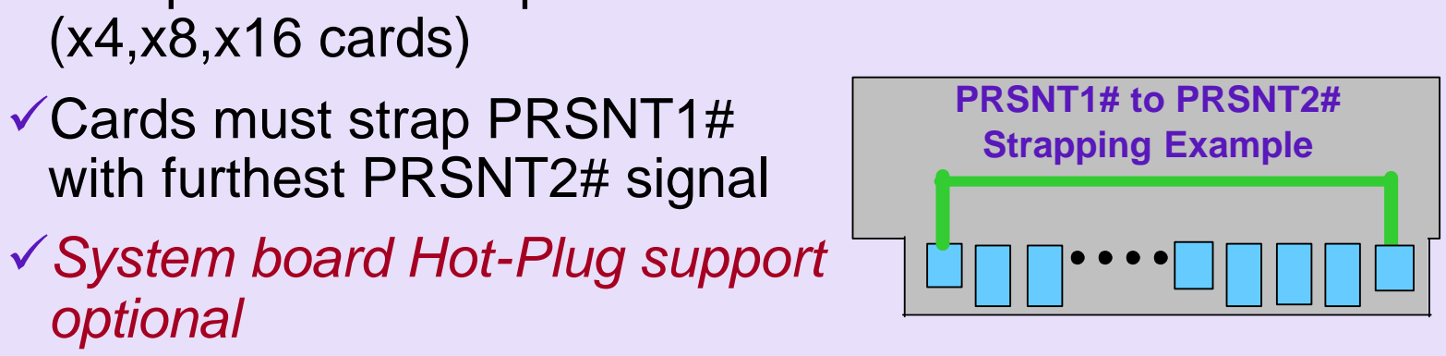
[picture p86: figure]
(x4,x8,x16 cards) Çards must strap PRSNT1# with furthest PRSNT2# signal Şystem board Hot-Plug support optional; PRSNT1# to PRSNT2# Strapping Example

PCI-SIG APAC Developers Conference | Copyright © 2004, PCI-SIG, All Rights Reserved | 23

## Card Edge Fingers

ß Remove ref plane under edge

Add-in card requirements

## Card Retention

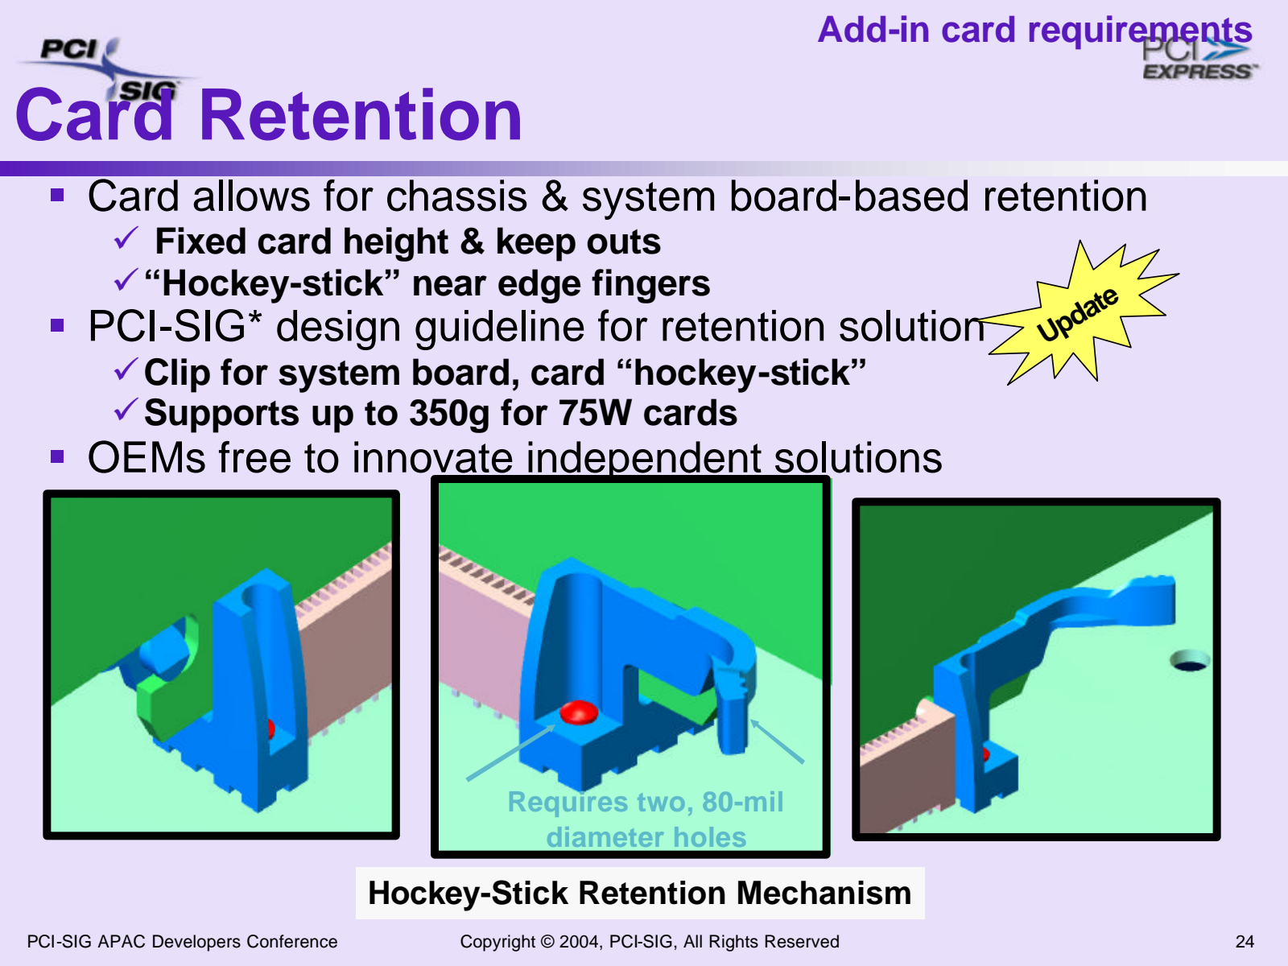
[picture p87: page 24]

PCI-SIG APAC Developers Conference | Copyright © 2004, PCI-SIG, All Rights Reserved | 24

ß Card allows for chassis & system board-based retention
¸ Fixed card height & keep outs
¸“Hockey-stick” near edge fingers
ß PCI-SIG* design guideline for retention solution
Çlip for system board, card “hockey-stick” Şupports up to 350g for 75W cards
ß OEMs free to innovate independent solutions

Update

Add-in card requirements

Hockey-Stick Retention Mechanism

Requires two, 80-mil
diameter holes

## Card Physical Dimensions

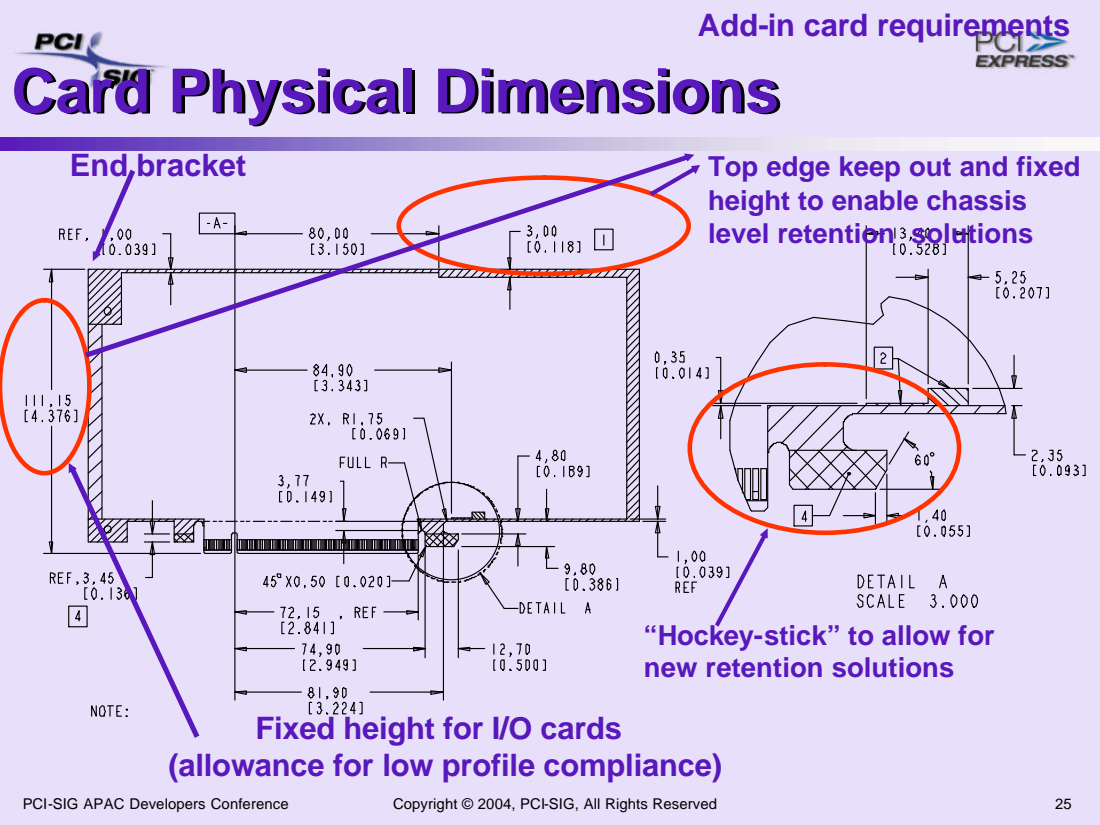
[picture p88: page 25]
PCI-SIG APAC Developers Conference; Copyright © 2004, PCI-SIG, All Rights Reserved; level retention; solutions; End bracket

Add-in card requirements

Top edge keep out and fixed
height to enable chassis

“Hockey-stick” to allow for
new retention solutions

Fixed height for I/O cards
(allowance for low profile compliance)

## Gfx Thermal & Acoustic

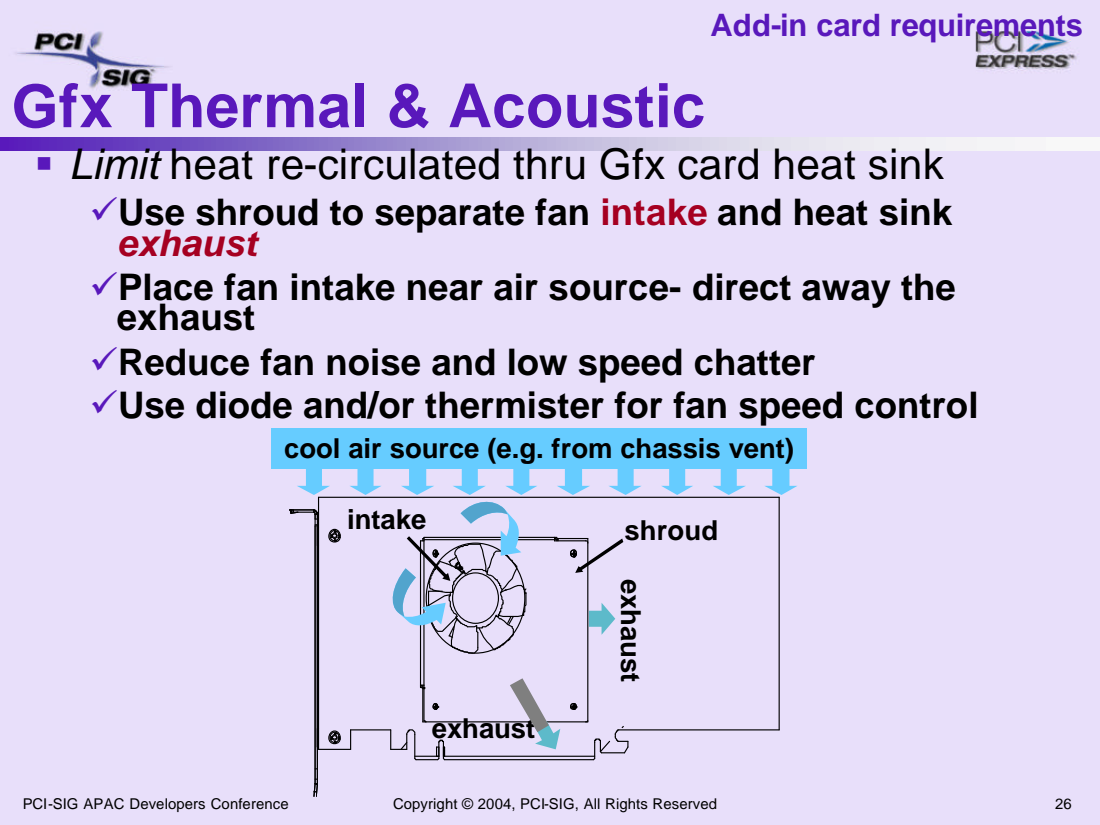
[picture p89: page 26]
PCI-SIG APAC Developers Conference; Copyright © 2004, PCI-SIG, All Rights Reserved; exhaust; intake; shroud

Add-in card requirements

ß Limit heat re-circulated thru Gfx card heat sink
¸Use shroud to separate fan intake and heat sink
exhaust
¸Place fan intake near air source- direct away the
Ŗeduce fan noise and low speed chatter
¸Use diode and/or thermister for fan speed control

cool air source (e.g. from chassis vent)

PCI-SIG APAC Developers Conference | Copyright © 2004, PCI-SIG, All Rights Reserved | 27

## Lab Signal Measurements

ß PCI Express devices generate compliance pattern per spec
ß Use compliance boards for signal validation
¸ Compliance Base Board (CBB) for add-in card measurements
¸ Compliance Load Board (CLB) for system board measurements
ß Measure eye diagrams with real time scope
¸ 6+ GHz analog bandwidth
¸ 20+ Gs sampling bandwidth
¸ Scope vendor should have eye diagram signal analysis SW tool

Signal validations

PCI Express connector

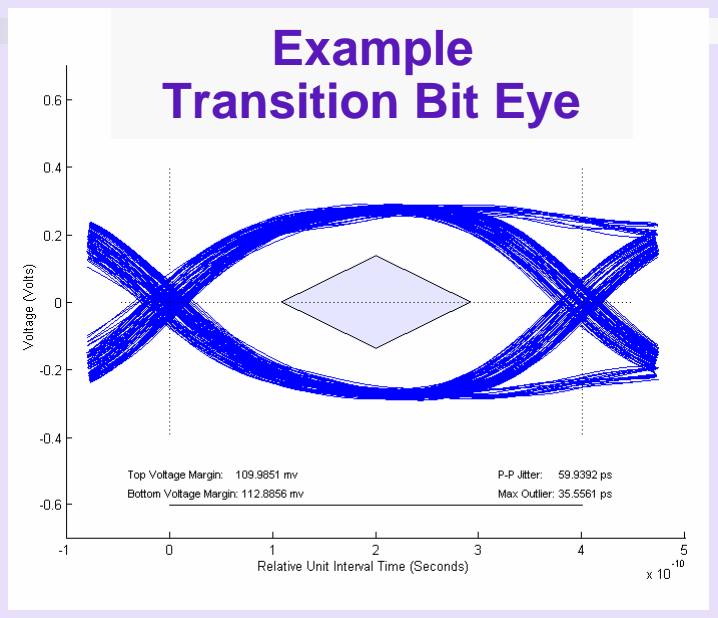
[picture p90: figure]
Example Transition Bit Eye
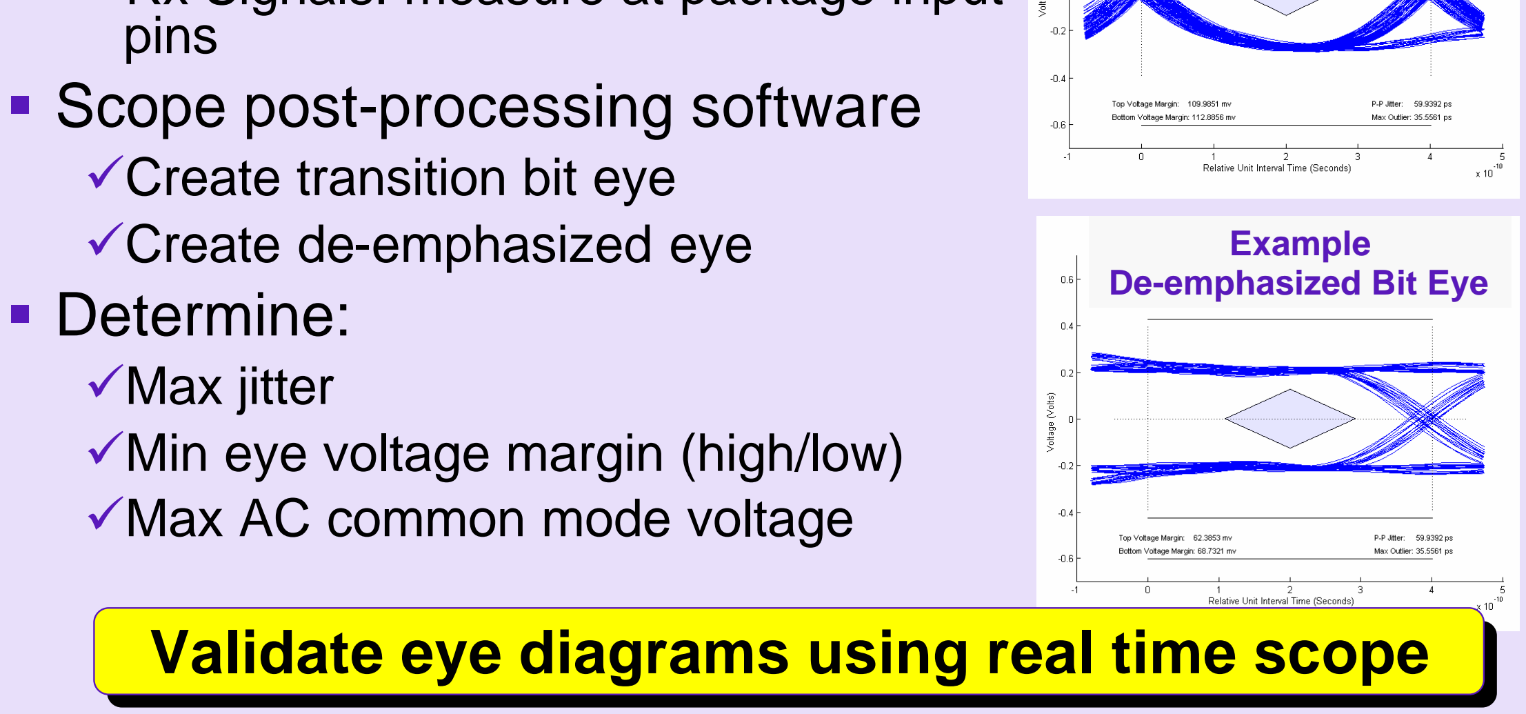
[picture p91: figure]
pins ß Scope post-processing software Çreate transition bit eye Çreate de-emphasized eye ß Determine: ¸Max jitter ¸Min eye voltage margin (high/low) ¸Max AC common mode voltage; Example De-emphasized Bit Eye

PCI-SIG APAC Developers Conference | Copyright © 2004, PCI-SIG, All Rights Reserved | 28

## Acquiring & Interpreting Results

ß Probe locations
Ţx Signals: measure at 50Ω loads
Ŗx Signals: measure at package input

Signal validations

Validate eye diagrams using real time scope

PCI-SIG APAC Developers Conference | Copyright © 2004, PCI-SIG, All Rights Reserved | 29

## Summary

ß PCI Express point-to-point layout is straightforward
ß Manage loss and jitter from PCB to meet interconnect budget
ß Follow basic layout rules and design tradeoffs to implement typical topologies
ß Improved connector & add-in card features -support for 75 Watt cards
ß Validate compliance eye diagrams using compliance boards and real time scope

Summary

PCI-SIG APAC Developers Conference | Copyright © 2004, PCI-SIG, All Rights Reserved | 30

## Collateral

ß For additional and updated information on PCI Express Architecture, visit
http://www.pcisig.com

PCI-SIG APAC Developers Conference | Copyright © 2004, PCI-SIG, All Rights Reserved | 31

## Thank you for attending the 2004 PCI-SIG Asia-Pacific

Developers Conference.

## For more information please go to www.pcisig.com

PCI-SIG APAC Developers Conference | Copyright © 2004, PCI-SIG, All Rights Reserved | 32

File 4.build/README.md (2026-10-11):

# _openPCIE_ Build

The build process for the _openPCIE_ project consists of three steps:
- Compilation of the control and status registers (CSR) from their RDL
  specification into RTL for the hardware design and a hardware abstraction
  layer (HAL) for the software application
- Compilation of the software application for the RISC-V hardware target
- Compilation of SystemVerilog designs into a bitstream for the hardware target

Each step has its own `Makefile`; the SW and HW steps also have their own
directory and `README.md`. Run them in order - the software can pick up the
generated HAL, and the hardware build embeds the firmware image into the
bitstream.

| Step | Makefile / Directory | Produces |
|---|---|---|
| 1. CSR | [`MakefileCSR`](./MakefileCSR) | `csr_build/generated-files/` - `csr.sv`, `csr_pkg.sv`, `csr.h`, `csr_hw.h`, `csr_cosim.h` |
| 2. SW | [`sw_build`](./sw_build) | `firmware.elf`, `firmware.bin`, `firmware.hex` |
| 3. HW | [`hw_build.openXC7`](./hw_build.openXC7) | `build_artifacts/top.bit` |

## CSR HAL Compilation

The openPCIE CSR HAL is auto-generated, as is the CSR RTL, using `peakrdl`. For
co-simulation purposes an additional layer is auto-generated from the same
SystemRDL specification using `systemrdl-compiler` that accompanies the `peakrdl`
tools. This produces two header files that define a common API to the application
layer for both the RISC-V platform and the *VProc* based co-simulation
verification environment. The platform targetted header uses the `peakrdl
c-header` output directly and unmodified. The `peakrdl` output is produced using
the following command:

```
    peakrdl c-header csr_cosim.rdl -b ltoh -o csr.h
```

The `csr_cosim.rdl` is a filtered version of `4.build/csr_build/csr.rdl` that
removes buffer write commands that are not understood by `systemrdl-compiler` and
are not used for `c-header` generation. Other than that, the RDL is identical.

The wrapper HAL headers are generated with a Python script `sysrdl_cosim.py`
which has some command line options:

```
usage: sysrdl_cosim.py [-h] [-r RDLFILE] [-o OUTFILE] [-c] [-v VPNODE] [-d DELAY] [-C CLKPERIOD]

Process command line options.

options:
  -h, --help            show this help message and exit
  -r RDLFILE, --rdl_file RDLFILE
                        Specify the RDL file for processing
  -o OUTFILE, --output_file OUTFILE
                        Specify an ouput header file
  -c, --cosim           Generate cosim header
  -v VPNODE, --vp_node VPNODE
                        Specify VProc node number for soc_cpu (cosim only)
  -d DELAY, --delay_range DELAY
                        Specify maximum delay between transactions (cosim only)
  -C CLKPERIOD, --clk_period CLKPERIOD
                        Specify the VProc soc_cpu clock period in ps (cosim only)
```

The main options used are to specify the RDL file (`-r` or `--rdl_file`) and to
specify the output file (`-o` or `--output_file`). To select generation of the
co-simulation header the `-c` or `--cosim` option is used, otherwise the hardware
header is generated. By default the co-simulation header assumes it is running on
a *VProc* node numbered 0, matching the current openPCIE test bench. However,
this can be changed by using the `-v` or `--vp_node` option, should the need
arise. Code running on a *VProc* virtual processor runs infinitely fast with
respect to simulation time when not doing a read or write transaction to the
logic. In order to emulate processing time, after each read or write access, a
random delay is inserted to advance the simulation a number of ticks. The maximum
number of ticks can be specified using the `-d` or `--delay_range` option meaning
the delay can range from 0 to `DELAY` clock cycles. The default for this is 32
clock cycles. The `-v` and `-d` options have no affect if the `-c` option is not
used. Finally the *VProc* test bench `soc_cpu` module's clock period in
picoseconds can be specified for use in co-simulation abstraction of delay and
timing functions. It defaults to 16000, i.e. the 62.5 MHz `user_clk` that the
PCIE hard macro hands to `riscv_pcie_soc` in an x1 Gen2 link with a 64-bit
datapath.

To generate all the required HAL headers and RTL a make file is provided as
`4.build/MakefileCSR` to wrap up the script calls. Running this make file
(`make -f MakefileCSR`) produces the following files in
`4.build/csr_build/generated-files`:

  * `csr_cosim.rdl` : The intermediate filtered RDL specification
  * `csr.sv`        : The RTL for hardware target
  * `csr_pkg.sv`    : The structured RTL interface for hardware target
  * `csr.h`         : The `peakrdl c-header` output file used by the target header
  * `csr_hw.h`      : The C++ HAL for the hardware target, for C++ applications (the C firmware uses `csr.h`, see below)
  * `csr_cosim.h`   : The HAL for the *VProc* based openPCIE logic simulation test bench
  * `openpcie.md`   : The register map as markdown
  * `html/`         : The register map as a browsable HTML document

Those files are checked in, so an ordinary build never runs this step -- only an
edit of `csr_build/csr.rdl` calls for it. Regeneration is idempotent, so it never
shows up as a spurious diff.

`peakrdl` and the interpreter running `sysrdl_cosim.py` must be the same install.
On Windows they often are not, because MSYS2's own `python3` comes first on PATH
and lacks `systemrdl-compiler`. `make -f MakefileCSR tools` shows what was picked
up; override with:

```sh
make -f MakefileCSR PYTHON=/c/Users/you/AppData/Local/Programs/Python/Python312/python.exe
```

The `csr_hw.h` and `csr_cosim.h` files present the same API to the application
and can be appropriately selected at compile time using something like the
following:

```c
#ifdef VPROC
#include "csr_cosim.h"
#else
#include "csr_hw.h"
#endif
```

This has been done in the `openpcie_regs.h` header in the
`4.build/csr_build/generated-files/` directory, and including this header in the
application code makes available the register HAL.

Those two headers are C++ (one class per register). The bare-metal firmware in
[`3.sw`](../3.sw) is plain C, so `openpcie_regs.h` falls back to the `csr.h`
structs there, reached through the `CSR_REGS()` pointer:

```c
    PCIE_TX_HEADER0 = h0;                 // CSR_REG32(tx.header0)
    uint32_t hdr    = PCIE_RX_HEADER_INFO;
    uint8_t  tag    = RDL_FIELD(hdr, CSR__RX__HEADER_INFO__TAG);
```

`CSR_REG32()` takes the register's offset out of the generated struct with
`offsetof()` and then performs one aligned 32-bit access at that address. Do
**not** dereference through the struct itself: `peakrdl c-header` marks every
struct `__attribute__((packed))`, which tells the compiler the members may be
unaligned, and on a target with no unaligned load/store -- rv32i, for one -- a
single register access then compiles into four byte accesses:

```
    lbu a4,12(a5)   /   sb a4,12(a5)   /   lbu a4,13(a5)   ...
```

That is wrong for a CSR. It writes a register in four steps, and on this design
the write strobe of `tx.data` starts a TLP transfer, so the packet goes out
after the first byte with the other three not yet written. The compiler only
folds the byte accesses back into a word at `-O2` and above, and the firmware is
built without optimisation. It is also invisible on x86, where unaligned access
is free -- it took a run on the real ISA to see it.

### The register map

`csr.rdl` describes the TLP transmit/receive window that the picorv32 firmware
uses in place of the AMD-proprietary hardware FSM. It sits at `0x3000_0000` in
the SOC address map:

| Offset | Register | Access | Meaning |
|---|---|---|---|
| `0x00` | `tx.header0` | W | TLP header DW0 - Fmt/Type, TC, attributes, Length |
| `0x04` | `tx.header1` | W | TLP header DW1 - Requester ID, Tag, byte enables |
| `0x08` | `tx.header2` | W | TLP header DW2 - address, or Bus/Device/Function |
| `0x0C` | `tx.data` | W | Payload DWORD - **writing it starts the transfer** |
| `0x10` | `rx.status` | R | Completion Status of the last Completion TLP |
| `0x14` | `rx.data` | R | Payload DWORD of the last Completion TLP |
| `0x18` | `rx.header_info` | R | `requester_id`, `tag`, `lower_addr` |
| `0x1C` | `status.err` | R | `cfg_status` + fatal-error message flag |
| `0x20` | `status.phy` | R | Tx FSM state + free hard-macro Tx buffers |

The send trigger is the `swmod` strobe PeakRDL raises on `tx.data` - the same
"write the payload last" protocol the hand-written block used, only now it is
described in the RDL rather than in a case statement.

### Two interchangeable CSR implementations

The hand-written register block is **not** gone. It lives on inside
`riscv_pcie_soc.sv` behind `` `ifdef SOC_CSR_LEGACY `` as the reference
implementation, and every build flow can select it:

The choice is made once, in [`config.mk`](./config.mk), and every build step
reads it - the firmware, the openXC7 bitstream and the Vivado project:

```makefile
CSR ?= peakrdl        # or: legacy
```

so that hardware and software are never built different ways by accident. With
`legacy` nothing generated is used at all, and `make -f MakefileCSR` never has
to be run.

A single build can still override it without editing the file:

| Flow | Override |
|---|---|
| openXC7 | `make CSR=legacy` |
| Firmware | `make CSR=legacy` |
| Vivado tcl | `set ::use_legacy_csr 1` before sourcing the script |

Both describe the same map down to the byte offset, so any firmware runs on
either bitstream. That was checked by compiling `main.c` both ways with the
RISC-V toolchain and comparing the output: `firmware.bin` is byte-identical,
for both RC-direct and RC-switched.

The PeakRDL path is also the one exercised by the
[co-simulation](../5.sim), which runs the real firmware against a PCIE endpoint
model and ends with the memory read-back check passing.

## SW Compilation

Sources are in [`3.sw`](../3.sw): what both RC variants share in
[`common`](../3.sw/common) (`start.S`, `sections.lds`, the PCIE request layer
`pcie.c`/`.h`), and one `main.c` per variant in [`RC-direct`](../3.sw/RC-direct)
and [`RC-switched`](../3.sw/RC-switched). This step only builds them. A Makefile is
provided as `4.build/sw_build/Makefile`. Running `make` in that directory
produces the following files in `4.build/sw_build`:

  * `firmware.elf`  : The ELF file for the RISC-V hardware target
  * `firmware.bin`  : The raw binary image
  * `firmware.hex`  : The HEX programming file for the RISC-V hardware target

`firmware.hex` is the one the hardware build consumes - `riscv_pcie_soc.sv`
initialises its instruction memory with `$readmemh("firmware.hex", ram)`, so the
file is one 32-bit little-endian word per line, 8 hex digits, no `0x` prefix.

The toolchain is xPack GNU RISC-V Embedded GCC (`riscv-none-elf-` prefix), built
for `rv32i` only - picorv32 here is configured without the M and C extensions.

`make` builds the RC-direct firmware. For the switched topology:

```
make VARIANT=switched
```

Both variants write the same three output names, but every `make` rebuilds the
firmware (about a second), so no `make clean` is needed to switch.

By default (`CSR ?= peakrdl` in `config.mk`) the firmware takes its register map
from the headers generated in step 1; `make CSR=legacy` uses the addresses
hard-coded in `3.sw/common/pcie.h` instead - see
[Two interchangeable CSR implementations](#two-interchangeable-csr-implementations)
above.

> **Run this step on Windows** (`cmd` or PowerShell). The RISC-V toolchain and
> Python are Windows programs, whereas the openXC7 step below runs in WSL because
> yosys, nextpnr and prjxray are Linux tools.

See [`sw_build/README.md`](./sw_build/README.md) for details.

## HW Compilation

Two independent flows target the same device, `xc7a200tfbg484-3` on the Acorn
CLE-215P.

### Proprietary AMD flow

Hardware synthesis for the AMD project branch is supported through the Vivado GUI,
using the prepared project files in each of the corresponding design directories,
which are all located within `amd-rtl-with-Vivado-build`, e.g.
[2.RC-direct.amd/xbuild.Vivado-v2024.2](../2.amd-rtl-with-Vivado-build/2.RC-direct.amd/xbuild.Vivado-v2024.2).

The opensource RTL can also be built with Vivado, via the project-generation
scripts [`RC-direct.opensource.tcl`](../2.rtl/2.RC-direct.opensource/RC-direct.opensource.tcl)
and [`RC-switched.opensource.tcl`](../2.rtl/3.Bonus--RC-switched.opensource/RC-switched.opensource.tcl) -
two short wrappers around the shared
[`RC.opensource.tcl`](../2.rtl/0.common.opensource/RC.opensource.tcl).

### Opensource openXC7 flow

Descend to [`hw_build.openXC7`](./hw_build.openXC7) and follow the Makefile and
README in it. The chain is `sv2v` -> `yosys` -> `nextpnr-xilinx` -> `prjxray`, with
no proprietary tool anywhere in it:

```bash
cd hw_build.openXC7
make check-env         # verifies the tools, and warns on a wrong nextpnr version
make                   # -> build_artifacts/top.bit
make VARIANT=switched  # -> build_artifacts.switched/top.bit
```

The two variants keep separate output directories, so they never overwrite each
other. They do share `../sw_build/firmware.hex`, so build the matching firmware
first.

**Verified on hardware:** the resulting bitstream brings the PCIE link up at
**Gen2** against a second Artix-7 board acting as endpoint - the same state the
Vivado bitstream reaches from identical RTL.

Two things are worth knowing before the first build, both covered in detail in
[`hw_build.openXC7/README.md`](./hw_build.openXC7/README.md):

- **The nextpnr-xilinx version is critical.** Only commit `45a986b` works; the
  version from the official installer was too old and the later master had a
  router regression. That is the *pre-v1.0.0* openXC7 toolchain, which this project was
  validated with on hardware. openXC7 has since replaced it with a new one;
  `make TOOLCHAIN=new` builds with that (not yet tested on hardware), and
  `make TOOLCHAIN=new FRONTEND=slang` does so without sv2v - see
  [Pre-v1.0.0 and new openXC7 toolchain](./hw_build.openXC7/README.md#pre-v100-and-new-openxc7-toolchain)
  and [Native SV within Yosys, through Slang](./hw_build.openXC7/README.md#native-sv-within-yosys-through-slang).
- **nextpnr's GT attribute defaults do not match the Xilinx library.** Where the
  RTL omits an attribute, Vivado fills it from `unisim` while nextpnr substitutes
  its own default - almost always `0`. `lane_xcvr.sv` therefore sets 20 of them
  explicitly. This was the root cause of the design not working on hardware, and
  it is silent: no warning, and the bitstream builds cleanly.

-----------
#### End-of-Document

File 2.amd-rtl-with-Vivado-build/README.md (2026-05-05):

# AMD proprietary branch

This is a replica of the AMD-provided examples. They are handy for:
- [x] ✔️ familiarization with the problem, i.e. the establishment of a solid baseline, the **`ground truth`** that draws its authority from this proven, industrial-strength, big-name IP stack.

- [x] ✔️ creation of a robust set of test procedures that can be applied to the opensource variant that is to be developed.

- [x] ✔️ gathering the general knowledge of **WHAT IS NEEDED** and **WHAT TO EXPECT** in the course of developing the opensource stack.

------
#### End-of-Document

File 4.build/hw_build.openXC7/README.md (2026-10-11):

# opensource openXC7 build flow

Builds the opensource RC into an FPGA bitstream with **open-source tools only**, no Vivado. `make` builds [`RC-direct.opensource`](../../2.rtl/2.RC-direct.opensource); `make VARIANT=switched` builds [`RC-switched.opensource`](../../2.rtl/3.Bonus--RC-switched.opensource). Both come from the same RTL, [`2.rtl/0.common.opensource`](../../2.rtl/0.common.opensource) (top `RC_opensource`), and differ only in their firmware and GT pins (`openxc7.xdc` vs `openxc7.switched.xdc`, see [GT channel](#gt-channel)).

| Stage | Tool | Input -> Output |
|---|---|---|
| 1. SV conversion | `sv2v` | `.sv` -> `.v` |
| 2. Synthesis | `yosys` | `.v` -> `top.json` |
| 3. Place & route | `nextpnr-xilinx` | `.json` + chipdb + `.xdc` -> `top.fasm` |
| 4. FASM -> frames | `fasm2frames` (prjxray) | `.fasm` -> `top.frames` |
| 5. Bitstream | `xc7frames2bit` (prjxray) | `.frames` -> `top.bit` |

Target part is `xc7a200tfbg484-3` (Acorn CLE-215P), same as the Vivado build.

## Status: working on hardware

`make` produces `build_artifacts/top.bit`. On the board it brings the PCIE link **up at Gen2**, checked against a second Artix-7 board acting as endpoint:

```
user_lnk_up = 1
LTSSM       = 0x16
phy_lnk_up  = 1
rate        = Gen2
```

These are the same readings as with the Vivado bitstream built from the same RTL.

It took six fixes to get there: one latent bug in this design's RTL, and five workarounds for openXC7 defects. All are described below.

---

## ⚠ The nextpnr-xilinx version is critical

With the pre-v1.0.0 toolchain, the design builds **only** with nextpnr-xilinx at commit `45a986b` (`v0.8.2-79-g45a986b8`, 2026-04-18).

| Version | Result |
|---|---|
| nextpnr-xilinx 0.8.2 from the snap (Jun 2024 binary) | **too old** - its metadata lacks `site_type_PCIE_2_1.json`, so placement fails with `no Bels remaining of type 'PCIE_2_1'` |
| master `bab26c2` (Jul 2026) | **regression** - `router2` loops forever in `route_xilinx_const` (confirmed in gdb) |
| **`45a986b` (Apr 2026)** | **works** |

Yosys 0.38 from the snap is fine; no newer Yosys is needed.

### Building the right version

```bash
git clone https://github.com/openXC7/nextpnr-xilinx.git && cd nextpnr-xilinx
git checkout 45a986b
git submodule update --init --depth 1 \
    xilinx/external/prjxray-db xilinx/external/nextpnr-xilinx-meta
mkdir build && cd build
cmake .. -DARCH=xilinx -DCMAKE_BUILD_TYPE=Release -DBUILD_GUI=OFF \
         -DCMAKE_POLICY_VERSION_MINIMUM=3.5      # needed with cmake 4.x
make -j$(nproc)
install -Dm755 nextpnr-xilinx bbasm /usr/local/bin/
```

If the tree is not in `/opt/openxc7_extra/npnr_45a986b`, point the Makefile at it with `NEXTPNR_SRC=`.

**Do not mix versions.** `prjxray-db`, the site metadata and `constids.inc` must come from the same tree as the nextpnr binary. Mixed, they give wrong wire indices and failures that look like router bugs. The Makefile takes all four from `$(NEXTPNR_SRC)` for this reason.

---

## Pre-v1.0.0 and new openXC7 toolchain

**This project was built and validated on hardware with the pre-v1.0.0 openXC7 toolchain:**

| Tool | Version used |
|---|---|
| nextpnr | `nextpnr-xilinx` at commit `45a986b` (Apr 2026), built from source as above |
| Yosys | 0.38, from the openXC7 snap |
| Bitstream | prjxray `fasm2frames` + `xc7frames2bit`, from the openXC7 snap |
| SV conversion | `sv2v` |

openXC7 has moved on since: `nextpnr-xilinx` is archived, the `openxc7` snap is no longer published, and the one-line installer is gone. The **new** toolchain is built from source with [`toolchain-sources-builder.sh`](https://github.com/openXC7/toolchain-installer), or installed through Nix or Apio (see that page):

| Tool | New toolchain (openXC7 v1.0.0, as of Sept 2026) |
|---|---|
| nextpnr | [`openXC7/nextpnr`](https://github.com/openXC7/nextpnr), the *himbaechel* Xilinx engine |
| Yosys | v0.69 |
| Bitstream | `fpga-as`, replacing `fasm2frames` + `xc7frames2bit` |

The Makefile supports both: `TOOLCHAIN=old` (the default) and `TOOLCHAIN=new`. **Only the pre-v1.0.0 toolchain is validated on hardware.** With v1.0.0 both variants build and their configuration checks out, but none of its bitstreams has been on the board yet.

To reproduce the validated result, use the pre-v1.0.0 toolchain; `45a986b` can still be fetched from the archived repository (see [Building the right version](#building-the-right-version)). The rest of this page is about the pre-v1.0.0 toolchain unless it says otherwise.

### Building with the new toolchain

**1. Build the toolchain.** On Ubuntu, into a user-owned prefix, so that only the package install needs `sudo`:

```bash
git clone https://github.com/openXC7/toolchain-installer && cd toolchain-installer
INSTALL_PREFIX=$HOME/opt/openxc7 ./toolchain-sources-builder.sh all
```

The script first installs any missing Ubuntu packages (asking for the `sudo` password), then builds Yosys, nextpnr, prjxray and `fpga-as`. That took about 14 minutes here (Ubuntu 24.04 in WSL2, 16 threads).

**2. sv2v**, same as before - see [Prerequisites](#2-sv2v). We used v0.0.13.

**3. Build:**

```bash
source $HOME/opt/openxc7/export.sh
cd 4.build/hw_build.openXC7
make TOOLCHAIN=new check-env
make TOOLCHAIN=new                      # -> build_artifacts.new/top.bit
make TOOLCHAIN=new VARIANT=switched     # -> build_artifacts.switched.new/top.bit
```

The new toolchain has its own `chipdb.new/` (the database format differs) and its own output folders, so it never overwrites the validated `build_artifacts*/top.bit`. Its bitstreams are not kept in git.

**What changed in the flow:** two steps. The chipdb comes from the new engine's `xilinx_gen.py` instead of `bbaexport.py`, and `fpga-as` turns the FASM into a bitstream in one step instead of `fasm2frames` + `xc7frames2bit`. Synthesis and place and route are called as before; the new `nextpnr-xilinx` is a small script that passes the same options on to `nextpnr-himbaechel`.

**What we measured** (RC-direct unless noted):

| | Pre-v1.0.0 toolchain | New toolchain |
|---|---|---|
| Build time, chipdb cached | about 2 min | 2 min 13 s (RC-switched 2 min 21 s), 16 threads |
| First build, incl. chipdb | several minutes | 6 min |
| GT channel, link speed | channel 1, Gen2 | channel 1 (RC-switched: channel 2), Gen2 |
| Flip-flops after synthesis | 1770 (Yosys 0.38, RTL of 2026-08-19) | 1486 + 9 SRLs (Yosys 0.69, no `-nosrl`, RTL of 2026-10-08) - different RTL, not comparable |
| Pipe clock (`clk_oobclk`, 250 MHz) | misses 250 MHz - expected and verified harmless (see [Clocks](#clocks)) | 280 MHz (RC-switched 274 MHz), passes |
| On hardware | **link up at Gen2** | not tested yet |

nextpnr also warns "Overriding derived constraint of 250.0 MHz on net pcie_inst.clk_oobclk with user-specified constraint of 125.0 MHz". This is harmless: the warning prints its two values swapped, and the 250 MHz from `openxc7.xdc` is what gets applied ([#21](https://github.com/chili-chips-ba/openPCIE/issues/21)).

[openXC7 findings](#openxc7-findings) lists which openXC7 defects still apply to v1.0.0. The design-side fixes are in the RTL, so v1.0.0 builds get them too.

## Native SV within Yosys, through Slang

Open-source Yosys has long read only a subset of SystemVerilog. This design uses packages, interfaces with modports and packed structs, which Yosys's own Verilog front end does not take; hence sv2v. Full SystemVerilog in Yosys came only with the commercial Verific front end, sold by YosysHQ in its Tabby CAD Suite.

Since **Yosys 0.67**, open-source Yosys has its own SystemVerilog front end: `read_slang`, built on the [slang](https://github.com/MikePopoloski/slang) compiler through [sv-elab](https://github.com/povik/sv-elab), and included in every Yosys build. With v1.0.0 this design builds without sv2v:

```bash
source $HOME/opt/openxc7/export.sh
make TOOLCHAIN=new FRONTEND=slang                     # -> build_artifacts.slang/top.bit
make TOOLCHAIN=new FRONTEND=slang VARIANT=switched    # -> build_artifacts.switched.slang/top.bit
```

**Our SystemVerilog goes in unchanged.** `read_slang` takes all 34 SystemVerilog files (packages, interfaces, structs, the SystemVerilog picorv32) without a single language error. Synthesis takes about 10 seconds, the whole build 2 min 26 s (2 min 13 s with sv2v).

**The Xilinx primitives needed three workarounds**, for upstream gaps:

| Problem | Workaround |
|---|---|
| Every primitive must be declared with its parameters; Yosys's usual blackboxes carry none ([sv-elab#367](https://github.com/povik/sv-elab/pull/367)), and its `cells_sim.v` does not pass slang's checks ([yosys#6323](https://github.com/YosysHQ/yosys/issues/6323)). | [`gen_xilinx_bb.py`](gen_xilinx_bb.py) writes them for the 8 primitives used, from Yosys's own library; the Makefile runs it. |
| sv-elab cannot pass a `real` parameter to a primitive ([sv-elab#282](https://github.com/povik/sv-elab/issues/282)). | The MMCM's real-valued settings (all defaults) sit behind `` `ifndef SYN_YOSYS_BUG `` in `clk_synth.sv`; this flow defines it. |
| Yosys's default for `IBUFDS_GTE2.CLKSWING_CFG` is `"TRUE"` instead of `2'b11`; nextpnr rejects it ([yosys#6322](https://github.com/YosysHQ/yosys/issues/6322)). | `gen_xilinx_bb.py` writes `2'b11`. |

**Compared with the sv2v build**, the FASM differs only in 9 `GTPE2_CHANNEL` fields our RTL leaves unset: `read_slang` passes Xilinx's defaults, while sv2v leaves them to nextpnr's. So the slang build is the closer one to Vivado. Not tested on hardware yet.

---

## ⚠ nextpnr's GT attribute defaults do not match Xilinx's

**This is why the design did not work on hardware, and it is the most generally useful finding here.**

When an RTL parameter is omitted, Vivado takes its default from the `unisim` model. In the openXC7 flow the parameter is simply missing from the netlist, so nextpnr uses **its own** default, nearly always `0`, without a warning.

Comparing every `GTPE2_CHANNEL` attribute the RTL leaves unset against the `cells_xtra.v` default and the `*_or_default(...)` call in `xilinx/fasm.cc` gives a list of mismatches. The **20** that matter for this design:

| Attribute | Xilinx library | nextpnr | Consequence |
|---|---|---|---|
| `TX_CLKMUX_EN` | `1'b1` | `0` | **GT-internal TX clock mux off** |
| `RX_CLKMUX_EN` | `1'b1` | `0` | **GT-internal RX clock mux off** |
| `PMA_RSV` | `32'h00000333` | `0` | TX PMA analog config wrecked |
| `TXPI_PPMCLK_SEL` | `"TXUSRCLK2"` | `"TXUSRCLK"` | wrong TX phase-interpolator clock |
| `PD_TRANS_TIME_FROM_P2` | `12'h03C` | `0` | PCIE P-state transition timing |
| `PD_TRANS_TIME_TO_P2` | `8'h64` | `0` | same |
| `OUTREFCLK_SEL_INV` | `2'b11` | `0` | |
| `TRANS_TIME_RATE` | `8'h0E` | `0` | |
| `RXOOB_CFG` | `7'b0000110` | `0` | OOB detection |
| `RXLPM_HF_CFG` / `RXLPM_LF_CFG` | non-zero | `0` | RX equaliser |
| `RXBUFRESET_TIME`, `RXCDRFREQRESET_TIME`, `RXCDRPHRESET_TIME`, `RXISCANRESET_TIME`, `RXLPMRESET_TIME` | `5'b00001` / `7'b0001111` | `0` | reset pulse widths |
| `SATA_BURST_SEQ_LEN`, `SATA_BURST_VAL`, `SATA_EIDLE_VAL` | non-zero | `0` | |

Symptom: the GT came up (QPLL locked, every `resetdone` asserted), but TX phase alignment never started. `TXDLYSRESETDONE` never toggled, so the sync FSM sat in `TX_START` and the LTSSM never left `DETECT_QUIET`.

`lane_xcvr.sv` now sets all 20 explicitly, to the **library** values. The Vivado flow is unaffected; these are the values it was already using.

That is why [regymm/pcie_7x](https://github.com/regymm/pcie_7x) works on openXC7 with the same GTP and the same TX-buffer-bypass mode: it sets every attribute explicitly, so nextpnr has nothing to guess.

**Rule of thumb:** with this toolchain, set every hard-block attribute explicitly. Do not rely on library defaults.

---

## Design-side requirements

### `-nosrl` at synthesis

Required with the pre-v1.0.0 toolchain. `wake_timer`'s 96- and 128-bit shift registers otherwise become `SRLC32E` chains, and nextpnr fails on the cascade output:

```
ERROR: No wire found for port Q31 on source cell ... fpga_srl_0
```

v1.0.0 handles the cascade, so the Makefile passes `-nosrl` only with `TOOLCHAIN=old`.

| v1.0.0, RC-direct | with `-nosrl` | without |
|---|---|---|
| Flip-flops | 1702 | 1486 |
| SRL cells | 0 | 7 `SRLC32E`, 2 `SRL16E` |
| LUTs | 1761 | 1740 |
| `clk_oobclk` Fmax (250 MHz target) | 259 MHz | 280 MHz |

*(`-nocarry` and `--router router1` only worked around the broken master nextpnr; `45a986b` needs neither.)*

### `TXPI_SYNFREQ_PPM` forced to non-zero

`lane_xcvr.sv` sets `.TXPI_SYNFREQ_PPM(3'd1)`. Without it, nextpnr reads 0 and stops:

```
fasm.cc:3146  if (txpi_synfreq_ppm == 0) log_error("TXPI_SYNFREQ_PPM must not be zero!")
```

Yet 0 is Xilinx's default, and Xilinx's own PCIE IP leaves it there. We set 1 only to get past this check.

> ⚠ **This is a hack, and hacks like it are dangerous.** The value was picked to satisfy the tool, not the silicon, so our RTL departs here from Xilinx's default and from Xilinx's own PCIE IP, in the Vivado build too. It works on our board, but we have not verified what `TXPI_SYNFREQ_PPM = 1` does to the TX phase interpolator. Never change a hard-block attribute just to silence a tool error: fix the tool, or check the value against Xilinx's documentation first. We go back to 0 once nextpnr accepts it ([#27](https://github.com/chili-chips-ba/openPCIE/issues/27), upstream [nextpnr#88](https://github.com/openXC7/nextpnr/issues/88)).

### Unused GT refclk inputs left unconnected

`pll_bank.sv` used to tie seven unused refclk inputs (`GTGREFCLK0/1`, `GTREFCLK1`, `GTEASTREFCLK0/1`, `GTWESTREFCLK0/1`) to `1'd0`. Vivado accepts that common practice, but nextpnr rejects any constant on a refclk input (`pack_gt_xc7.cc:184`), so they are now left unconnected.

### `wake_timer` clocked from `clk_dclk`

`serdes_ctrl.sv` originally had:

```systemverilog
BUFG wake_refclk_bufg (.I (PIPE_CLK), .O (gt_cpllpdrefclk));
```

`PIPE_CLK` is `IBUFDS_GTE2.O`. Vivado routes this reference clock through the clock backbone into a BUFG, and it works. **nextpnr routes the net without an error, but the BUFG output does not toggle on the board.** A JTAG probe showed it: a counter on `gt_cpllpdrefclk` stayed at 0 on every read, while counters on `user_clk` and `clk_pclk` ran normally.

Consequence chain:

```
gt_cpllpdrefclk dead -> wake_timer never finishes counting
                     -> cpllpd and cpllrst stay asserted
                     -> PLL0PD=1, PLL0RESET=1  (QPLL powered down, not mistuned)
                     -> QPLL_lock=0 -> GT reset FSM stuck at ST_PLL_LOCK
                     -> LTSSM stuck in DETECT_QUIET forever
```

So no amount of QPLL *configuration* fixes could help: the PLL was switched off, not misconfigured.

Workaround: `assign gt_cpllpdrefclk = clk_dclk;`, the MMCM's 125 MHz output. It runs even while the QPLL is still down, because the MMCM is fed by `TXOUTCLK`, which follows the reference clock independently of PLL lock. `wake_timer` only times a startup period, so running it at 125 instead of 100 MHz changes that period by 20%, which does no harm.

### `ST_MMCM_LOCK` is a trap for GTP - latent RTL bug

Not an openXC7 issue. In `pll_init_ctrl.sv`:

```systemverilog
wire mmcm_cpll = mmcm_r2 && (&cplllock_r2);
ST_MMCM_LOCK : state_nx = mmcm_cpll ? ST_DRP_NOM_REQ : ST_MMCM_LOCK;
```

GTP has no per-channel CPLL, and `lane_xcvr.sv` ties `GT_CPLLLOCK = 1'b0`, so `mmcm_cpll` is always 0 and the state has **no exit**. The FSM lands there as soon as it sees the QPLL unlocked while out of reset.

The Vivado build escapes only because its wake path locks the QPLL before reset release: a race it happens to win, not a guarantee. Fixed at the source, in `serdes_ctrl.sv`, by feeding the QPLL lock into that input:

```systemverilog
.QRST_CPLLLOCK ({PCIE_LANES{&qpll_qplllock}}),
```

For GTP, "channel PLL locked" *is* the QPLL lock.

All RTL changes were re-validated in Vivado end to end: synthesis, implementation and bitstream, 0 errors, 0 critical warnings, link up at Gen2.

---

## Prerequisites

### 1. openXC7 toolchain

Provides `yosys` and the prjxray tools. This project used the openXC7 snap of the time (Yosys 0.38, prjxray `fasm2frames` / `xc7frames2bit`) with nextpnr `45a986b` built as above; the snap's own nextpnr did not work for this design. The snap and its installer are gone. See [Pre-v1.0.0 and new openXC7 toolchain](#pre-v100-and-new-openxc7-toolchain) for what replaces them, and [Building with the new toolchain](#building-with-the-new-toolchain) for how to use it.

### 2. sv2v

**Required with the pre-v1.0.0 toolchain.** Yosys 0.38 does not understand SystemVerilog packages, interfaces or packed structs, and this design uses all three (`link_pkg`, `stream_if`, `phy_lanes_if`).

With v1.0.0 it is optional: Yosys 0.69's Slang front end reads our sources as they are (see [Native SV within Yosys, through Slang](#native-sv-within-yosys-through-slang)). sv2v is still the more mature path, just no longer a must.

```bash
wget https://github.com/zachjs/sv2v/releases/latest/download/sv2v-Linux.zip
unzip sv2v-Linux.zip && install -Dm755 sv2v-Linux/sv2v /usr/local/bin/sv2v
```

### 3. firmware.hex

`riscv_pcie_soc.sv` loads its RAM with `$readmemh("firmware.hex", ram)`, so sw_build must run first. The Makefile expects `../sw_build/firmware.hex`.

### 4. The generated CSR

By default the SOC uses `soc_csr.sv`, which wraps the register block PeakRDL generates from `../csr_build/csr.rdl`. So two of the sv2v inputs come from `../csr_build/generated-files/`:

```bash
cd ..                     # 4.build/
make -f MakefileCSR       # -> csr_build/generated-files/{csr_pkg,csr}.sv
```

They are checked in, so this is only needed after editing `csr.rdl`.

The register block is chosen once, in [`4.build/config.mk`](../config.mk), and read by this build, the Vivado project and the firmware alike, so hardware and software always agree:

```makefile
CSR ?= peakrdl        # or: legacy
```

With `legacy`, no generated file is needed. To override it for a single build:

```bash
make CSR=legacy
```

That passes `-DSOC_CSR_LEGACY` to sv2v and drops `csr_pkg.sv`, `csr.sv` and `soc_csr.sv` from the file list. The two register blocks are functionally identical, down to the byte offsets, so the same firmware runs on either.

---

## Building

```bash
make check-env         # confirms tools present AND warns if nextpnr is the wrong version
make check-sources     # confirms every RTL file and firmware.hex is present
make                   # full build -> build_artifacts/top.bit
make VARIANT=switched  # full build -> build_artifacts.switched/top.bit
```

| Target | Purpose |
|---|---|
| `make convert` | only sv2v conversion + module extraction |
| `make CSR=legacy` | build the hand-written CSR instead of the PeakRDL one |
| `make TOOLCHAIN=new` | build with the new openXC7 toolchain, into `build_artifacts.new/` - see [Building with the new toolchain](#building-with-the-new-toolchain) |
| `make TOOLCHAIN=new FRONTEND=slang` | the same without sv2v, into `build_artifacts.slang/` - see [Native SV within Yosys, through Slang](#native-sv-within-yosys-through-slang) |
| `make info` | print resolved configuration |
| `make clean` | remove `build_artifacts/` and the local copy of `firmware.hex` |
| `make clean-converted` | remove `converted/` |
| `make clean-all` | all of the above, plus `chipdb/` |

`VARIANT=switched` gets its own `converted.switched/` and `build_artifacts.switched/`, and the clean targets act on those. So the two variants never overwrite each other or pick up each other's stale intermediates. `chipdb/` is shared, since it depends on the part, not the design. `../sw_build/firmware.hex` is **not** separated, so build the matching firmware first (`make VARIANT=switched` in `sw_build/`).

**Every `make` rebuilds the design from scratch**, sv2v to bitstream; only the chipdb is kept. Switching `CSR` changes the **file list** but no file, so a date-based make would keep the previous bitstream. File dates are unreliable anyway: a tree on a network share, or copied off one, can carry timestamps from the future. Always rebuilding avoids both, and no `make clean` is ever needed.

The first build generates the nextpnr chipdb for `xc7a200tfbg484-3` (317 MB, several minutes) and caches it in `chipdb/`. After that, a build takes about 2 minutes.

---

## Constraints

nextpnr's XDC parser accepts only `[get_ports]` and `[get_nets]` targets, so the full Vivado XDC cannot be used. `openxc7.xdc` (RC-direct) and `openxc7.switched.xdc` (RC-switched) are cut-down versions. The Vivado files, `2.rtl/0.common.opensource/xdc/` plus the one-line GT lane XDC in each variant's `xdc/`, remain the reference for the AMD flow.

### GT channel

The constraint that really matters, `LOC GTPE2_CHANNEL_X0Y5` (the channel the Acorn board is wired to), is set **indirectly**, through the package pins of the GT pads. In prjxray the `IPAD`, `OPAD` and `GTPE2_CHANNEL` sites share a tile and are hard-wired, so choosing the pins chooses the channel:

```tcl
set_property PACKAGE_PIN C5  [get_ports TXN]   ;# MGTPTXN1_216
set_property PACKAGE_PIN D5  [get_ports TXP]   ;# MGTPTXP1_216
set_property PACKAGE_PIN C11 [get_ports RXN]   ;# MGTPRXN1_216
set_property PACKAGE_PIN D11 [get_ports RXP]   ;# MGTPRXP1_216
```

This works here but **not** in Vivado, where it is the other way round: `LOC` on the channel decides the pads, and pin constraints alone do not move the lane.

Channel map for bank 216, from `prjxray-db/artix7/xc7a200tfbg484-3/package_pins.csv` (the `tile` column names the tile directly):

| Channel | Vivado LOC | RX pins | TX pins |
|---|---|---|---|
| 0 | `GTPE2_CHANNEL_X0Y4` | A8/B8 | A4/B4 |
| **1** | **`GTPE2_CHANNEL_X0Y5`** | **C11/D11** | **C5/D5** |
| 2 | `GTPE2_CHANNEL_X0Y6` | A10/B10 | A6/B6 |
| 3 | `GTPE2_CHANNEL_X0Y7` | C9/D9 | C7/D7 |

RC-switched uses channel **2** (`GTPE2_CHANNEL_X0Y6`, pins A10/B10 and A6/B6, in `openxc7.switched.xdc`), the same position its Vivado XDC locks. This table numbers channels as prjxray does; [`2.rtl/README.md`](../../2.rtl/README.md#common-physical-constraints-xdc) lists the same four positions by board lane.

Check after every build that the FASM contains `GTP_CHANNEL_1_MID_LEFT` (`GTP_CHANNEL_2_...` for RC-switched). The P&R step prints this for you:

```bash
grep -oE "GTP_CHANNEL[A-Z0-9_]*_X[0-9]+Y[0-9]+" build_artifacts/top.fasm | sort -u
```

**Gotcha:** at `PCIE_LANES=1` the netlist port is plain `TXN`, not `TXN[0]`. A constraint written as `[get_ports {TXN[0]}]` silently matches nothing.

### Clocks

`create_clock` on `[get_nets]` **is** supported (`xilinx/xdc.cc:169`). `create_generated_clock`, `set_false_path` and `set_clock_groups` are not.

This matters: an **unconstrained** clock gets nextpnr's default target of **12 MHz**, so that domain is never optimised and never reported as failing. Three of the four domains here were like that, and the pipe clock came out at 245 MHz against a 250 MHz requirement, without a word.

The target must be the **exact** net name nextpnr prints in its report (`pcie_inst.clk_oobclk`), not the RTL hierarchical name. Matching uses `getNetByAlias`, and on a miss the constraint is dropped **silently** (v1.0.0 now warns). That is why the five `create_clock` lines in regymm/pcie_7x do nothing there: they use Vivado-style `a/b/c` names, while the netlist has `a.b.c`.

---

## Shims

Vivado supplies these from its own libraries, which openXC7 lacks. Open replacements live here and do not affect the Vivado build:

| File | Replaces | Evidence it is faithful |
|---|---|---|
| `xpm_shim.v` | `xpm_cdc_single` (XPM) | 2-FF synchroniser, `ASYNC_REG` preserved |
| `unimacro_shim.v` | `BRAM_TDP_MACRO` (UNIMACRO) | yields **10 RAMB36E1**, same as Vivado |

## Synthesis compared with Vivado

| | Vivado | Yosys |
|---|---|---|
| RAMB36E1 | 10 | 10 |
| PCIE_2_1 / GTPE2_CHANNEL / GTPE2_COMMON | 1 / 1 / 1 | 1 / 1 / 1 |
| Registers | 1663 | 1491 |
| LUTs | 1675 | ~1586 |

Taken in July 2026, on the RTL of that time. The RTL has grown since, so these do not match the later counts in [Building with the new toolchain](#building-with-the-new-toolchain).

Bitstream size: Vivado 9 730 769 B, openXC7 9 730 777 B. The difference is header metadata.

---

## Debugging on the board without an ILA

openXC7 has no ILA, so the board is otherwise a black box. What made this bring-up possible was a `BSCANE2` shift register read over JTAG: a small module that Vivado can read with `scan_ir_hw_jtag` / `scan_dr_hw_jtag` while the openXC7 bitstream is loaded.

Three probes sat on separate JTAG user chains. `BSCANE2` connects straight to JTAG, so each probe can sit where its signals already are, and nothing has to be routed up the hierarchy.

| Chain | IR | Location | Contents |
|---|---|---|---|
| USER2 | `0x03` | top | `user_lnk_up`, `user_reset`, `cfg_status`, heartbeat |
| USER3 | `0x22` | `silicon_core` | **LTSSM state**, phy link, rate, width |
| USER4 | `0x23` | `serdes_ctrl` | GT reset FSM, QPLL lock, `resetdone`, TX sync FSM |

The probes have since been removed from the RTL. Two lessons for whoever needs them again:

- **`(* keep *)` is mandatory** on the `BSCANE2`, the shift register and the probe instance. The module has no output ports, so to synthesis it drives nothing, and Yosys silently deletes it. The bitstream then has no probe, and JTAG reads return garbage.
- **Heartbeat counters on each clock** were the most useful signal. Two counters running while a third stayed at 0 is what exposed the dead `IBUFDS_GTE2.O` BUFG, a net that static analysis showed as correctly routed.

The other decisive technique was an **A/B build**: the same RTL with the same probes, built once with Vivado and once with openXC7, loaded onto the same board. That settled at once whether a fault was in the design or in the tool. It also corrected one wrong assumption: `TXDLYSRESETDONE` reads 0 in the *working* build too, because it is a pulse, not a level.

---

## openXC7 findings

Every openXC7 issue this project ran into, rechecked on v1.0.0 (nextpnr `3e5c2cdd`). The numbers are stable, so issues and commits can refer to them. Open items are tracked in this repository under the [post-release](https://github.com/chili-chips-ba/openPCIE/milestone/1) milestone, each linked to its upstream report.

### Open Issues (as of Oct. 10, 2026) we found

| # | Finding | Status | Tracked (openPCIE, upstream) |
|---|---|---|---|
| 1 | GT attribute defaults differ from Xilinx's | still present | [#17](https://github.com/chili-chips-ba/openPCIE/issues/17), upstream [nextpnr#21](https://github.com/openXC7/nextpnr/issues/21) |
| 2 | `IBUFDS_GTE2.O` -> `BUFG` dead clock | fixed upstream; hardware check pending | [#22](https://github.com/chili-chips-ba/openPCIE/issues/22), upstream [nextpnr-xilinx#100](https://github.com/openXC7/nextpnr-xilinx/issues/100) |
| 3 | `PLL0_CFG`/`PLL1_CFG` hardcoded | still present | [#18](https://github.com/chili-chips-ba/openPCIE/issues/18), upstream [nextpnr#84](https://github.com/openXC7/nextpnr/issues/84) |
| 6 | Unconstrained clock silently timed at 12 MHz | still present; also no constraint derived through `IBUFDS_GTE2` | [#23](https://github.com/chili-chips-ba/openPCIE/issues/23), upstream [nextpnr#90](https://github.com/openXC7/nextpnr/issues/90) |
| 8 | `BEL` attribute on non-IO cells rejected | that error is gone, but `BEL` is still broken: the name nextpnr reports (`SLICE_X162Y177/A5FF`) is rejected, an accepted one (`X250Y5/SLICE_X0Y0.AFF`) is ignored, and a malformed one aborts nextpnr. Not used by openPCIE | [#28](https://github.com/chili-chips-ba/openPCIE/issues/28), upstream [nextpnr#89](https://github.com/openXC7/nextpnr/issues/89) |
| 10 | `--placer sa` placement invalid | still present on our design ("post-placement validity check failed"); the default placer is not affected | [#25](https://github.com/chili-chips-ba/openPCIE/issues/25), upstream [nextpnr#92](https://github.com/openXC7/nextpnr/issues/92) |
| 11 | `TXPI_SYNFREQ_PPM` = 0 rejected | still present; 0 is Xilinx's default and what Xilinx's PCIE IP uses | [#27](https://github.com/chili-chips-ba/openPCIE/issues/27), upstream [nextpnr#88](https://github.com/openXC7/nextpnr/issues/88) |
| 14 | `IBUFDS_GTE2.ODIV2` unusable | still present | [#24](https://github.com/chili-chips-ba/openPCIE/issues/24), upstream [nextpnr#91](https://github.com/openXC7/nextpnr/issues/91) |
| 18 | "Overriding derived constraint" warning prints its values swapped | new in v1.0.0 | [#21](https://github.com/chili-chips-ba/openPCIE/issues/21), upstream [nextpnr#85](https://github.com/openXC7/nextpnr/issues/85) |
| 19 | Yosys: wrong `IBUFDS_GTE2.CLKSWING_CFG` default | new, Slang front end | [#19](https://github.com/chili-chips-ba/openPCIE/issues/19), upstream [yosys#6322](https://github.com/YosysHQ/yosys/issues/6322) |
| 20 | sv-elab: no `real` primitive parameters | new, Slang front end | [#20](https://github.com/chili-chips-ba/openPCIE/issues/20), upstream [sv-elab#282](https://github.com/povik/sv-elab/issues/282) |
| 21 | nextpnr leaves a truncated FASM on error, which `fpga-as` still assembles | new; the Makefile checks nextpnr's exit status | [#26](https://github.com/chili-chips-ba/openPCIE/issues/26), upstream [nextpnr#93](https://github.com/openXC7/nextpnr/issues/93) |
| 22 | Yosys: `read_slang` cannot read Yosys's own `xilinx/cells_sim.v` (106 errors in `specify` blocks) | new, Slang front end; the reason for `gen_xilinx_bb.py` | [#29](https://github.com/chili-chips-ba/openPCIE/issues/29), upstream [yosys#6323](https://github.com/YosysHQ/yosys/issues/6323), [sv-elab#72](https://github.com/povik/sv-elab/issues/72) |
| 23 | `LOC` on a `GTPE2_CHANNEL` that contradicts its pad pins is accepted silently | new: `LOC GTPE2_CHANNEL_X0Y6` with channel-1 pins builds with channel 2 | [#30](https://github.com/chili-chips-ba/openPCIE/issues/30), upstream [nextpnr#94](https://github.com/openXC7/nextpnr/issues/94) |
| 24 | No XPM / UNIMACRO libraries | still absent in v1.0.0; [shims](#shims) stand in | not needed |

#### Temp RTL Workarounds / FIXMEs

Each tool workaround still in the sources carries a `FIXME` comment (`grep -rn FIXME`). The plan is to remove it once the original issue is fixed:

| Where | Workaround | Issue |
|---|---|---|
| `lane_xcvr.sv` | `TXPI_SYNFREQ_PPM = 3'd1` instead of Xilinx's 0 | [#27](https://github.com/chili-chips-ba/openPCIE/issues/27) |
| `serdes_ctrl.sv` | `wake_timer` clocked from `clk_dclk` instead of `BUFG(PIPE_CLK)` | [#22](https://github.com/chili-chips-ba/openPCIE/issues/22) |
| `pll_bank.sv` | none, but nextpnr ignores `PLL0_CFG`/`PLL1_CFG` here | [#18](https://github.com/chili-chips-ba/openPCIE/issues/18) |
| `clk_synth.sv` | MMCM `real` parameters left out under `SYN_YOSYS_BUG` (slang flow) | [#20](https://github.com/chili-chips-ba/openPCIE/issues/20) |
| `gen_xilinx_bb.py` | whole script (blackbox stubs for slang), plus the `CLKSWING_CFG` fix | [#29](https://github.com/chili-chips-ba/openPCIE/issues/29), [#19](https://github.com/chili-chips-ba/openPCIE/issues/19) |

### Issues we found in the pre-v1.0.0 openXC7

These affect only the pre-v1.0.0 tool chain; The v1.0.0 no longer suffers from them.

| # | Finding | Note | Tracked |
|---|---|---|---|
| 4 | Router regression after `45a986b` | nextpnr-xilinx only | not needed |
| 5 | Snap lacks `PCIE_2_1` metadata | the snap is gone | not needed |
| 9 | Yosys 0.38 `iopadmap -ignore` hangs | Yosys 0.38 only | not needed |
| 17 | `fasm2frames` KeyError on `IBUFDS_GTE2` | v1.0.0 uses `fpga-as` | [#14](https://github.com/chili-chips-ba/openPCIE/issues/14) (closed) |

#### Fixed in v1.0.0

| # | Finding | Note | Tracked |
|---|---|---|---|
| 7 | `create_clock` on an unknown net dropped silently | now warns | not needed |
| 12 | prjxray `bitread` segfaults on xc7a200t | | not needed |
| 13 | SRL32 cascade `Q31` missing | `TOOLCHAIN=new` builds without `-nosrl`: 216 fewer flip-flops, see [`-nosrl` at synthesis](#-nosrl-at-synthesis) | not needed |
| 15 | `PSEUDO_GND` rejected on unused `GTREFCLK` | | not needed |
| 16 | `CARRY4.CIN` ground not routable | no `-nocarry`; 384 carry cells pack and pass timing | not needed |
| 25 | XDC had no `get_cells`, so no `LOC` on a hard block | `set_property LOC ... [get_cells ...]` now pins `GTPE2_CHANNEL`; the pad pins are still required | not needed |

-----------
#### End-of-Document

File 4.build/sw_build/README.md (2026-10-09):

# firmware build

Builds the firmware for the picorv32 core inside the opensource RC, in either of
its two variants - `RC-direct.opensource` or `RC-switched.opensource`.

| Stage | Tool | Input -> Output |
|---|---|---|
| 1. Compile + link | `riscv-none-elf-gcc` | `start.S` + `pcie.c` + `main.c` -> `firmware.elf` |
| 2. Raw image | `riscv-none-elf-objcopy` | `.elf` -> `firmware.bin` |
| 3. Hex for `$readmemh` | `python` | `.bin` -> `firmware.hex` |

Sources live in `3.sw/` - this folder only builds them. `3.sw/common/` holds
what both variants share (`start.S`, `sections.lds`, the PCIE request layer
`pcie.c`/`.h`); the variant's own folder adds its `main.c`. All three outputs
land here, next to the Makefile.

| `VARIANT` | `main.c` from | Topology |
|---|---|---|
| `direct` (default) | `3.sw/RC-direct/` | one endpoint, straight RC-to-EP link |
| `switched` | `3.sw/RC-switched/` | ASM1184e switch with up to 4 endpoints |

Where the register map comes from is **not** set here - it comes from
[`4.build/config.mk`](../config.mk), which the hardware builds read as well, so
firmware and bitstream always match:

| `CSR` | Register map |
|---|---|
| `peakrdl` (default) | `../csr_build/generated-files/csr.h`, generated from `csr.rdl` |
| `legacy` | addresses hard-coded in `3.sw/common/pcie.h` |

`make CSR=legacy` overrides it for one build. Either way the image is
byte-identical, because both describe the same map. See
[`4.build/README.md`](../README.md#csr-hal-compilation).

---

## Prerequisites

**RISC-V toolchain.** [xPack GNU RISC-V Embedded GCC](https://github.com/xpack-dev-tools/riscv-none-elf-gcc-xpack),
prefix `riscv-none-elf-`. Override with `make CROSS=riscv64-unknown-elf-` if yours
differs.

**Python 3.** Any version; only `struct` is used.

## Building

**Run this on Windows** (`cmd` or PowerShell), not in WSL - the toolchain is a
Windows program:

```
cd 4.build\sw_build
make
```

> The two builds live on different sides: `hw_build.openXC7` runs **in WSL**
> because yosys/nextpnr/prjxray are Linux tools, while this one runs **on Windows**
> because the RISC-V toolchain and Python are Windows programs.

| Target | Purpose |
|---|---|
| `make` | build `firmware.elf`, `firmware.bin`, `firmware.hex` for RC-direct |
| `make VARIANT=switched` | the same three files, but for RC-switched |
| `make SIM=1` | short start-up delay, for co-simulation (see below) |
| `make info` | print the resolved configuration |
| `make clean` | remove the three generated files |

The register map is deliberately **not** in that table -- it is set once in
[`config.mk`](../config.mk), for the firmware and the hardware together, as
described at the top of this file.

**Every `make` rebuilds the firmware from scratch** - it takes about a second.
Both variants write the same three output names, and `VARIANT`, `CSR` and `SIM`
leave no trace in the sources, so a date-based make would compare the same
inputs against the same outputs, report `Nothing to be done`, and leave the
**previous** image in place. File dates cannot be trusted either: a tree on a
network share, or copied off one, can carry timestamps from the future, which
make a stale `firmware.hex` look up to date. Always rebuilding sidesteps both.
**No `make clean` needed, ever.**

```sh
make                     # direct
make VARIANT=switched    # switched
make SIM=1               # direct, for co-simulation
```

## Building for co-simulation

`main()` opens with `wait_cycles(STARTUP_DELAY)` - 100000 by default, set in
`3.sw/common/pcie.h` - which idles while the PCIE link
trains. On hardware that costs nothing. In [co-simulation](../../5.sim) it is
about 80 ms of simulated time before the firmware does anything at all -- the
loop is compiled without optimisation, so each iteration is a dozen bus cycles.

`make SIM=1` defines `STARTUP_DELAY=200` instead, and the whole run then fits in
3 ms of simulated time. Nothing else changes, and the hardware build is
unaffected: without `SIM=1` the delay is the full 100000 as before.

```
make SIM=1          # firmware for the simulator
make                # firmware for the board
```

`SIM=1` matters for the two co-simulation builds that execute this firmware --
`CPU=rtl` and `CPU=iss`. The `CPU=vproc` build does not use it at all: that one
replaces the firmware with a native C++ program, which waits on the CSR instead
of counting instructions, and so pays no start-up delay in the first place.

## Outputs

| File | Used by |
|---|---|
| `firmware.elf` | debugging / `readelf`, `objdump`, **and the rv32 ISS** in co-simulation - `make CPU=iss` in [`5.sim`](../../5.sim/README.md#the-three-cpu-options) loads it directly |
| `firmware.bin` | intermediate, raw image |
| **`firmware.hex`** | **the hardware build** - both Vivado and openXC7, and the RTL core in co-simulation |

`riscv_pcie_soc.sv` initialises its RAM with `$readmemh("firmware.hex", ram)`, so
the file must be one 32-bit little-endian word per line, 8 hex digits, no `0x`
prefix. That is exactly what step 3 emits.

Run this build **before** either hardware build - `firmware.hex` is a hard
dependency of both.

## Notes

`-march=rv32i -mabi=ilp32` only: picorv32 here is configured without the M and C
extensions. `-ffreestanding -nostdlib` because there is no libc and no crt0 -
`start.S` provides the reset vector, so it must stay first on the command line.

`firmware.elf` differs on every rebuild even when nothing changed. gcc embeds a
randomly named temporary object file for the `start.S` assembly pass, and that
name lands in the symbol table. `firmware.bin` and `firmware.hex` are stable, and
those are what matter.

-----------
#### End-of-Document

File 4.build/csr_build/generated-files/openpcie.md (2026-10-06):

<!--
SPDX-FileCopyrightText: 2026 Chili.CHIPS

SPDX-License-Identifier: BSD-3-Clause
-->

<!---
Markdown description for SystemRDL register map.

Don't override. Generated from: openpcie
  - csr_build/csr.rdl
-->

## openpcie address map

- Absolute Address: 0x0
- Base Offset: 0x0
- Size: 0x30000024

|  Offset  |Identifier|Name|
|---|---|----|
|0x00000000| imem |imem|
|0x30000000| csr | csr|

## imem memory

- Absolute Address: 0x0
- Base Offset: 0x0
- Size: 0x2000

<p>CPU Program/Data Memory</p>

No supported members.

## csr address map

- Absolute Address: 0x30000000
- Base Offset: 0x30000000
- Size: 0x24

<p>openPCIE Root Complex CSR</p>

|Offset|Identifier| Name |
|---|---|---|
| 0x00 | tx |  csr.tx  |
| 0x10 | rx |  csr.rx  |
| 0x1C |  status  |csr.status|

## tx register file

- Absolute Address: 0x30000000
- Base Offset: 0x0
- Size: 0x10

<p>TLP Transmit CSR (CPU --&gt; PCIe link)</p>

|Offset|Identifier| Name |
|---|---|---|
|  0x0 |  header0 |csr.tx.header0|
|  0x4 |  header1 |csr.tx.header1|
|  0x8 |  header2 |csr.tx.header2|
|  0xC | data |  csr.tx.data |

### header0 register

- Absolute Address: 0x30000000
- Base Offset: 0x0
- Size: 0x4

<p>TLP Header DW0 -- Fmt/Type, TC, attributes and Length</p>

|Bits|Identifier|Access|Reset| Name |
|----|---|---|-----|---|
|31:0| hdr |  rw  | 0x0 |csr.tx.header0.hdr[31:0]|

#### hdr field

<p>1st header DWORD of the outgoing TLP</p>

### header1 register

- Absolute Address: 0x30000004
- Base Offset: 0x4
- Size: 0x4

<p>TLP Header DW1 -- Requester ID, Tag and byte enables</p>

|Bits|Identifier|Access|Reset| Name |
|----|---|---|-----|---|
|31:0| hdr |  rw  | 0x0 |csr.tx.header1.hdr[31:0]|

#### hdr field

<p>2nd header DWORD of the outgoing TLP</p>

### header2 register

- Absolute Address: 0x30000008
- Base Offset: 0x8
- Size: 0x4

<p>TLP Header DW2 -- address, or Bus/Device/Function and register</p>

|Bits|Identifier|Access|Reset| Name |
|----|---|---|-----|---|
|31:0| hdr |  rw  | 0x0 |csr.tx.header2.hdr[31:0]|

#### hdr field

<p>3rd header DWORD of the outgoing TLP</p>

### data register

- Absolute Address: 0x3000000C
- Base Offset: 0xC
- Size: 0x4

<p>TLP Payload DWORD -- writing this register STARTS the transfer</p>

|Bits|Identifier|Access|Reset| Name |
|----|---|---|-----|---|
|31:0|  payload |  rw  | 0x0 |csr.tx.data.payload[31:0]|

#### payload field

<p>Payload DWORD of the outgoing TLP. A software write to this
register is what launches the Tx FSM, so it must be written
LAST, after the three header registers. The write strobe is
exported to logic as the 'swmod' output of this field.</p>

## rx register file

- Absolute Address: 0x30000010
- Base Offset: 0x10
- Size: 0xC

<p>TLP Receive CSR (PCIe link --&gt; CPU)</p>

|Offset| Identifier| Name |
|---|---|---|
|  0x0 | status  | csr.rx.status  |
|  0x4 | data | csr.rx.data |
|  0x8 |header_info|csr.rx.header_info|

### status register

- Absolute Address: 0x30000010
- Base Offset: 0x0
- Size: 0x4

<p>Completion Status Register</p>

|Bits|Identifier|Access|Reset| Name |
|----|---|---|-----|---|
| 2:0|cpl_status| r  | 0x0 |csr.rx.status.cpl_status[2:0]|

#### cpl_status field

<p>Completion Status of the last received Completion TLP:
0 = SC (Successful Completion), 1 = UR (Unsupported
Request), 2 = CRS (Configuration Retry Status),
4 = CA (Completer Abort)</p>

### data register

- Absolute Address: 0x30000014
- Base Offset: 0x4
- Size: 0x4

<p>Completion Payload Register</p>

|Bits|Identifier|Access|Reset| Name |
|----|---|---|-----|---|
|31:0|  payload | r  | 0x0 |csr.rx.data.payload[31:0]|

#### payload field

<p>Payload DWORD of the last received Completion TLP</p>

### header_info register

- Absolute Address: 0x30000018
- Base Offset: 0x8
- Size: 0x4

<p>Completion Header Register -- 3rd DWORD of the Completion TLP</p>

| Bits| Identifier |Access|Reset| Name |
|-----|---|---|-----|---|
| 6:0 | lower_addr | r  | 0x0 |  csr.rx.header_info.lower_addr[6:0] |
| 15:8| tag | r  | 0x0 | csr.rx.header_info.tag[7:0] |
|31:16|requester_id| r  | 0x0 |csr.rx.header_info.requester_id[15:0]|

#### lower_addr field

<p>Lower Address field of the Completion header</p>

#### tag field

<p>Tag of the request this Completion belongs to</p>

#### requester_id field

<p>Requester ID the Completion is addressed to. Software
compares it against its own ID to filter foreign traffic.</p>

## status register file

- Absolute Address: 0x3000001C
- Base Offset: 0x1C
- Size: 0x8

<p>PCIe Link Status CSR</p>

|Offset|Identifier| Name |
|---|---|---|
|  0x0 | err |csr.status.err|
|  0x4 | phy |csr.status.phy|

### err register

- Absolute Address: 0x3000001C
- Base Offset: 0x0
- Size: 0x4

<p>PCIe Error Status Register</p>

|Bits|  Identifier |Access|Reset| Name |
|----|---|---|-----|---|
|15:0|  cfg_status | r  | 0x0 |csr.status.err.cfg_status[15:0]|
| 16 |msg_err_fatal| r  | 0x0 |  csr.status.err.msg_err_fatal |

#### cfg_status field

<p>Configuration Space Status Register of the PCIe hard macro
(cfg_status)</p>

#### msg_err_fatal field

<p>A fatal-error Message TLP has been received
(cfg_msg_received_err_fatal)</p>

### phy register

- Absolute Address: 0x30000020
- Base Offset: 0x4
- Size: 0x4

<p>PCIe PHY / Tx FSM Status Register</p>

|Bits|Identifier|Access|Reset| Name |
|----|---|---|-----|---|
| 5:0| tx_buf_av| r  | 0x0 |csr.status.phy.tx_buf_av[5:0]|
| 7:6| tx_state | r  | 0x0 | csr.status.phy.tx_state[1:0]|

#### tx_buf_av field

<p>Number of free transmit buffers in the PCIe hard macro
(tx_buf_av). Software waits for a non-zero value.</p>

#### tx_state field

<p>State of the Tx FSM: 0 = IDLE, 1 = SEND_CYCLE_1,
2 = SEND_CYCLE_2. Software polls for 0 before it starts
loading the next TLP.</p>

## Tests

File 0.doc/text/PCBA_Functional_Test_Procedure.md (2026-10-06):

<!-- Generated text version of `1.pcb/0.doc/PCBA_Functional_Test_Procedure_RevB.pdf` (converted from its LaTeX source, `PCBA_Functional_Test_Procedure_RevB_LaTeX_Source.zip`; figures omitted) so the website assistant can read it. Do not edit by hand; regenerate from the source. -->

# PCBA Functional Test Procedure (openpci2-backplane)

Prepared for Elecrow. Revision B.

## Introduction

This document outlines the mandatory functional test procedures for the openpci2-backplane PCBA after assembly. The purpose of this test is to verify the soldering quality, power supply stability, and basic signal integrity before the units are shipped.

Please follow the steps sequentially. If any step fails, the board should be marked as "Failed" and separated for inspection.

## Power Supply Verification

- **Step 1.1:** Connect the main power supply (**standard 6-pin PCIe power connector (3 × +12V, 3 × GND), up to 70W total**) to the board input connector. 

- **Step 1.2:** Using a Digital Multimeter, measure the voltages at the specific test points indicated in **the figure** below. Reference all measurements to the board Ground (GND).

Verify the following voltage rails are present and stable:

- **12V** (Main Input)
- **3V3** (Output from DC/DC Buck Converter)
- **1V8**
- **1V2**

[Figure: Voltage Measurement Points]

## Reset Circuit Verification

The objective of this section is to verify that the manual reset signal is correctly distributed to all destination points on the backplane.

- **Step 2.1:** Ensure the board is powered (12V applied).

- **Step 2.2:** Locate the **RESET Button** and the **7 specific Reset Test Points** indicated in **the figure**.

- **Step 2.3:** **Idle State Check:** Without pressing the button, measure the voltage at **all 7 test points**.

- Verify that **all 7 points** are at a **High Logic Level (~ 3V3)**.

- **Step 2.4:** **Active State Check:** Press and **hold** the RESET Button. While holding the button, measure the voltage at **all 7 test points** again.

- Verify that **all 7 points** drop to a **Low Logic Level (~ 0V / GND)**.

- **Step 2.5:** Release the button and confirm that **all 7 test points** return to a **High Logic Level (~ 3V3)**.

[Figure: Location of Reset Button and the 7 Verification Points]

## Reference Clock Verification

The objective of this section is to verify the clock generator chip functionality. This is done in two parts: first by checking the primary reference output, and second by verifying the individual PCIe clocks.

### Part 1: Primary Reference Check (25 MHz)

**Objective:** Verify that the clock generator is active and the crystal is oscillating.

- **Step 3.1:** Ensure the board is powered (12V).
- **Step 3.2:** Locate **Resistor R22** (Series resistor for the SMA connector J4). See **the figure**.
- **Step 3.3:** Probe the signal on **R22**.
- **Step 3.4:** Verify the signal parameters:

- **Frequency:** **25 MHz**
- **Waveform:** Clean square/sine-like wave.
- **Amplitude:** Logic High (V_OH) should be **>1.35V** (typically ~ 1.8V). Logic Low (V_OL) should be **<0.45V** (typically ~ 0V).

- **Decision:** If this signal is **ABSENT**, the clock chip is not running. **STOP the test**. If present, proceed to Part 2.

[Figure: Location of Resistor R22 (25MHz Check)]

### Part 2: PCIe Output Verification (100 MHz)

**Objective:** Verify the presence of the 100 MHz PCIe reference clock outputs, confirm that the clock generator correctly drives the PCIe Switch, and verify that the Switch distributes the clock to downstream endpoints.

**Test Strategy:**
The CLKREQ# signal of the main upstream slot (**SWRC1**) is tied to GND by default on the board. Therefore, as soon as the board is powered, the clock generator output that feeds both the SWRC1 slot and the PCIe Switch input is enabled automatically. **No jumper wire or any other external connection is required.** Once the Switch receives the reference clock, it should automatically distribute it to the downstream x1 slot (**SW_EP1**).

- **Step 3.5: Measure Input Clock (at SWRC1)**

- Locate the PCIe x4 slot labeled **SWRC1**.
- With the board powered, probe the clock pins (A13/A14) on the **SWRC1** slot (at the connector entrance). **Refer to the figure.**
- **Verify:** 100 MHz clock is present.

[Figure: Measurement points on SWRC1]

- **Step 3.6: Measure Downstream Clock (at SW_EP1)**

- Locate the PCIe x1 slot labeled **SW_EP1**.
- Probe the clock pins (A13/A14) on **SW_EP1**. **Refer to the figure.**
- **Verify:** 100 MHz clock is present.
- *Note: If the clock is present here, it confirms the PCIe Switch is functioning.*

[Figure: Measurement points on SW_EP1]

- **Step 3.7: Signal Parameters Verification**

- **Frequency:** **100 MHz**
- **Waveform:** Clean square/sine-like wave (HCSL).
- **Amplitude:** Logic High (V_OH) approx. **0.7V - 0.8V**. Logic Low (V_OL) approx. **0V**.

- **Step 3.8: Thermal Check of the PCIe Switch**

- With the board powered for at least 1–2 minutes, briefly touch the **PCIe Switch chip** and the area around it with a finger.
- **Verify:** The chip and the surrounding area must **not be hot**. Slightly warm is acceptable.
- *Note: If the chip is too hot to keep a finger on it, mark the board as "Failed".*

**End of Test Procedure** 
If all steps passed, mark the board as **"PASSED"**.

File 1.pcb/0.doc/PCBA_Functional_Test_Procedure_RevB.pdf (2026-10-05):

# PCBA Functional Test Procedure

### Prepared for: Elecrow Project: openpci2-backplane

### October 5, 2026

## Introduction

This document outlines the mandatory functional test procedures for the openpci2-backplane PCBA after assembly. The purpose of this test is to verify the soldering quality, power supply stability, and basic signal integrity before the units are shipped.
Please follow the steps sequentially. If any step fails, the board should be marked as ”Failed” and separated for inspection.

## 1 Power Supply Verification

1. Step 1.1: Connect the main power supply (standard 6-pin PCIe power connector (3 × +12V, 3 × GND), up to 70W total) to the board input connector.
2. Step 1.2: Using a Digital Multimeter, measure the voltages at the specific test points indicated in Figure 1 below. Reference all measurements to the board Ground (GND).

Verify the following voltage rails are present and stable:

- 12V (Main Input)
- 3V3 (Output from DC/DC Buck Converter)
- 1V8
- 1V2

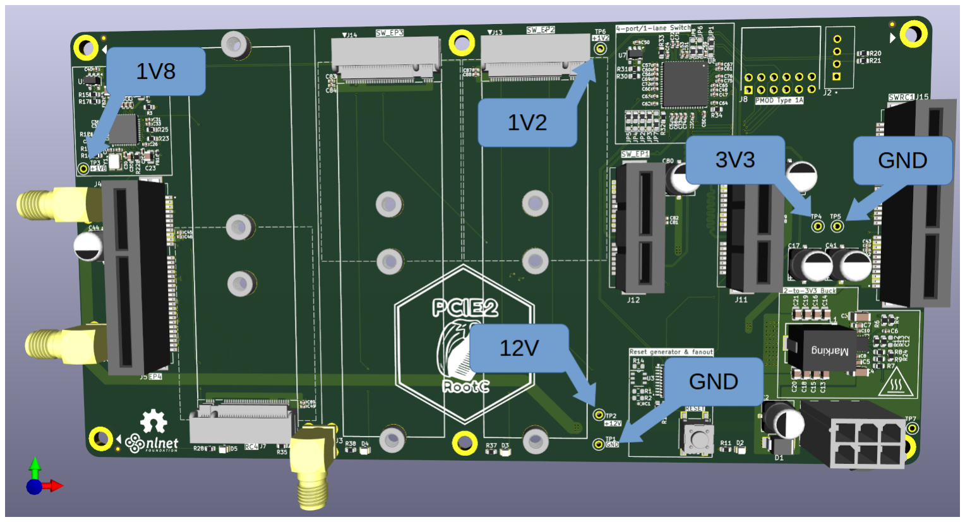
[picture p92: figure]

Figure 1: Voltage Measurement Points

## 2 Reset Circuit Verification

The objective of this section is to verify that the manual reset signal is correctly distributed to all destination points on the backplane.

1. Step 2.1: Ensure the board is powered (12V applied).
2. Step 2.2: Locate the RESET Button and the 7 specific Reset Test Points indicated in Figure 2.
3. Step 2.3: Idle State Check: Without pressing the button, measure the voltage at all 7 test points.
- Verify that all 7 points are at a High Logic Level (≈ 3V3).
4. Step 2.4: Active State Check: Press and hold the RESET Button. While holding the button, measure the voltage at all 7 test points again.
- Verify that all 7 points drop to a Low Logic Level (≈ 0V / GND).
5. Step 2.5: Release the button and confirm that all 7 test points return to a High Logic Level (≈ 3V3).

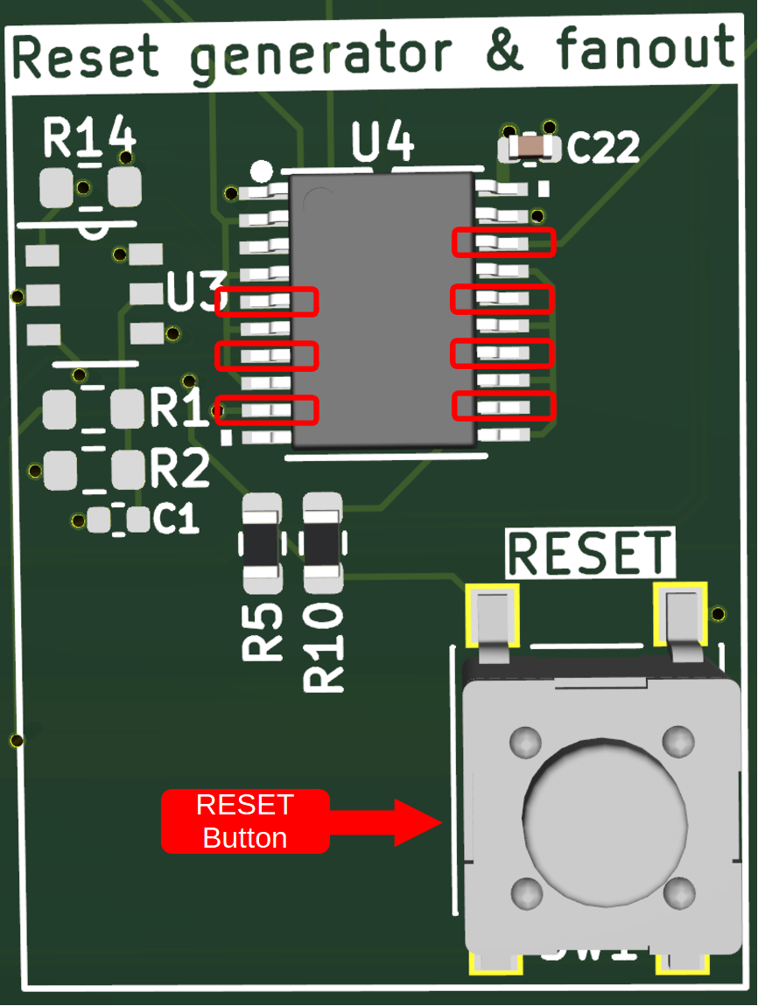
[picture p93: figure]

Figure 2: Location of Reset Button and the 7 Verification Points

## 3 Reference Clock Verification

The objective of this section is to verify the clock generator chip functionality. This is done in two parts: first by checking the primary reference output, and second by verifying the individual PCIe clocks.

### 3.1 Part 1: Primary Reference Check (25 MHz)

Objective: Verify that the clock generator is active and the crystal is oscillating.

1. Step 3.1: Ensure the board is powered (12V).
2. Step 3.2: Locate Resistor R22 (Series resistor for the SMA connector J4). See Figure 3.
3. Step 3.3: Probe the signal on R22.
4. Step 3.4: Verify the signal parameters:
- Frequency: 25 MHz
- Waveform: Clean square/sine-like wave.
- Amplitude: Logic High (VOH) should be >1.35V (typically ≈ 1.8V). Logic Low (VOL) should be <0.45V (typically ≈ 0V).
5. Decision: If this signal is ABSENT, the clock chip is not running. STOP the test. If present, proceed to Part 2.

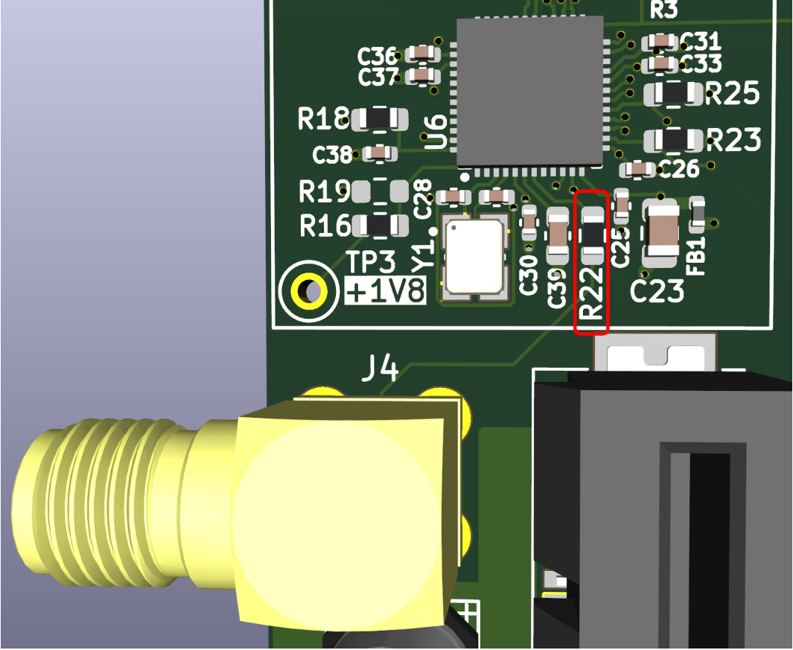
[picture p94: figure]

Figure 3: Location of Resistor R22 (25MHz Check)

### 3.2 Part 2: PCIe Output Verification (100 MHz)

Objective: Verify the presence of the 100 MHz PCIe reference clock outputs, confirm that the clock generator correctly drives the PCIe Switch, and verify that the Switch distributes the clock to downstream endpoints.

Test Strategy: The CLKREQ# signal of the main upstream slot (SWRC1) is tied to GND by default on the board. Therefore, as soon as the board is powered, the clock generator output that feeds both the SWRC1 slot and the PCIe Switch input is enabled automatically. No jumper wire or any other external connection is required. Once the Switch receives the reference clock, it should automatically distribute it to the downstream x1 slot (SW EP1).

1. Step 3.5: Measure Input Clock (at SWRC1)
- Locate the PCIe x4 slot labeled SWRC1.
- With the board powered, probe the clock pins (A13/A14) on the SWRC1 slot (at the connector entrance). Refer to Figure 4.
- Verify: 100 MHz clock is present.

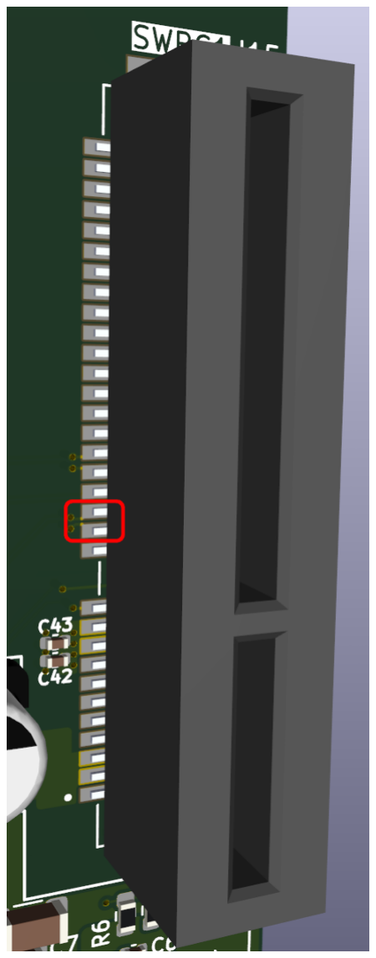
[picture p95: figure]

Figure 4: Measurement points on SWRC1

2. Step 3.6: Measure Downstream Clock (at SW EP1)
- Locate the PCIe x1 slot labeled SW EP1.

- Probe the clock pins (A13/A14) on SW EP1. Refer to Figure 5.
- Verify: 100 MHz clock is present.
- Note: If the clock is present here, it confirms the PCIe Switch is functioning.

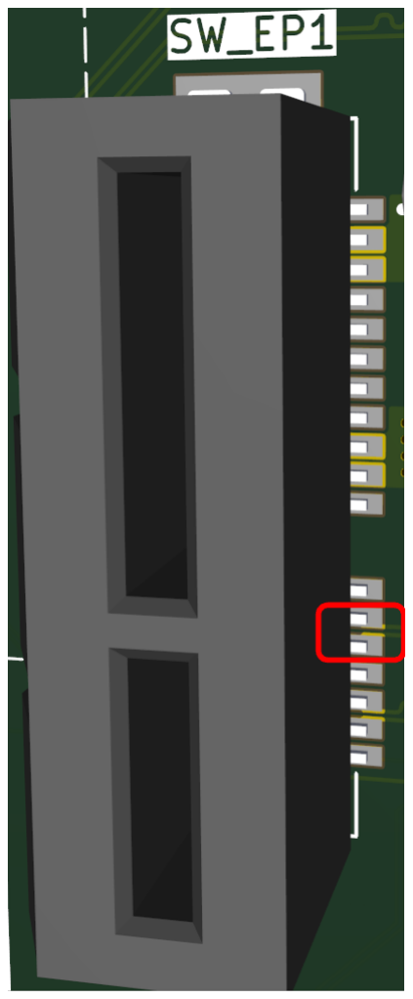
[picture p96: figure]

Figure 5: Measurement points on SW EP1

3. Step 3.7: Signal Parameters Verification
- Frequency: 100 MHz
- Waveform: Clean square/sine-like wave (HCSL).
- Amplitude: Logic High (VOH) approx. 0.7V - 0.8V. Logic Low (VOL) approx. 0V.
4. Step 3.8: Thermal Check of the PCIe Switch
- With the board powered for at least 1–2 minutes, briefly touch the PCIe Switch chip and the area around it with a finger.
- Verify: The chip and the surrounding area must not be hot. Slightly warm is acceptable.
- Note: If the chip is too hot to keep a finger on it, mark the board as ”Failed”.

End of Test Procedure
If all steps passed, mark the board as ”PASSED”.

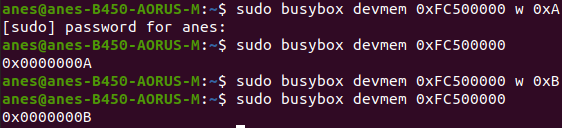
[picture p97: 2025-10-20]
0.doc/pictures/Data Read and Write Test Using devmem.png

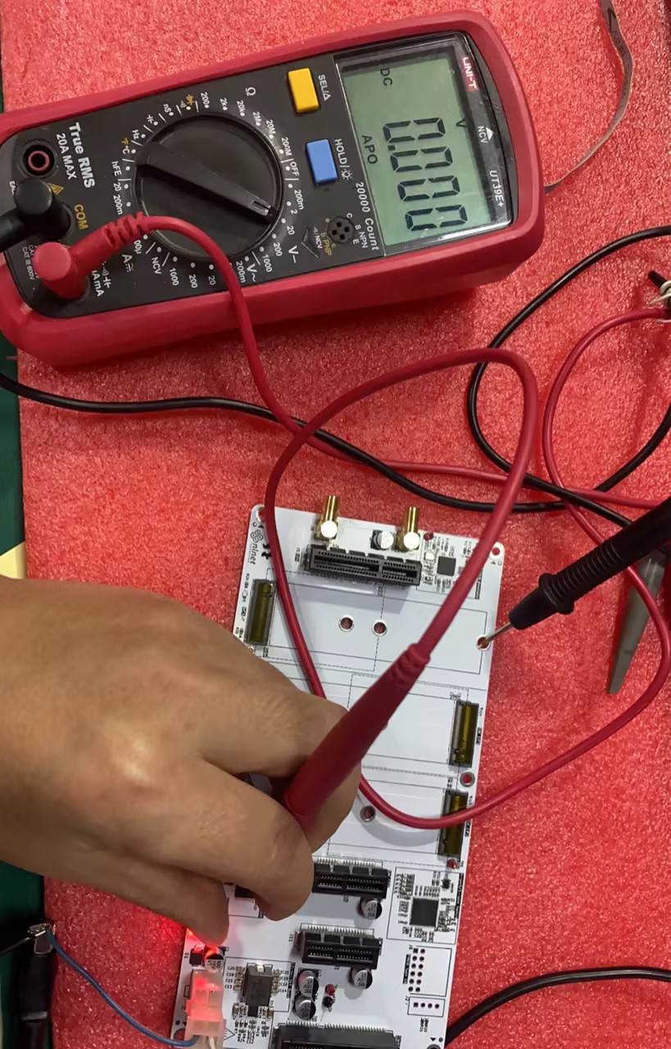
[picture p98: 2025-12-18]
1.pcb/2.test-results/2025-12-17/test (4).jpg

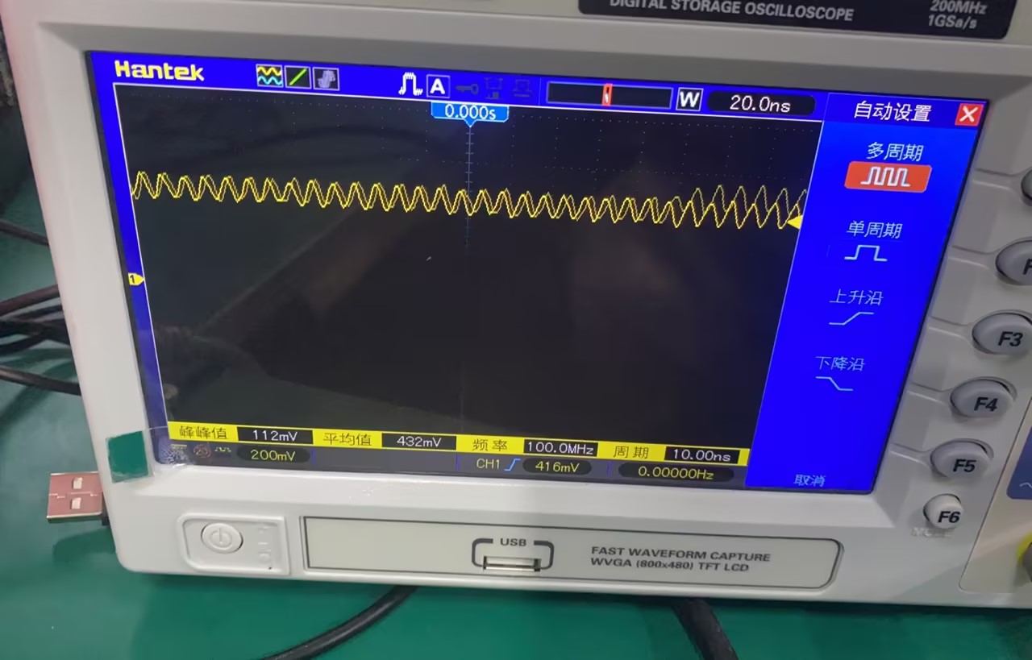
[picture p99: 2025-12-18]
1.pcb/2.test-results/2025-12-17/test (12).jpg

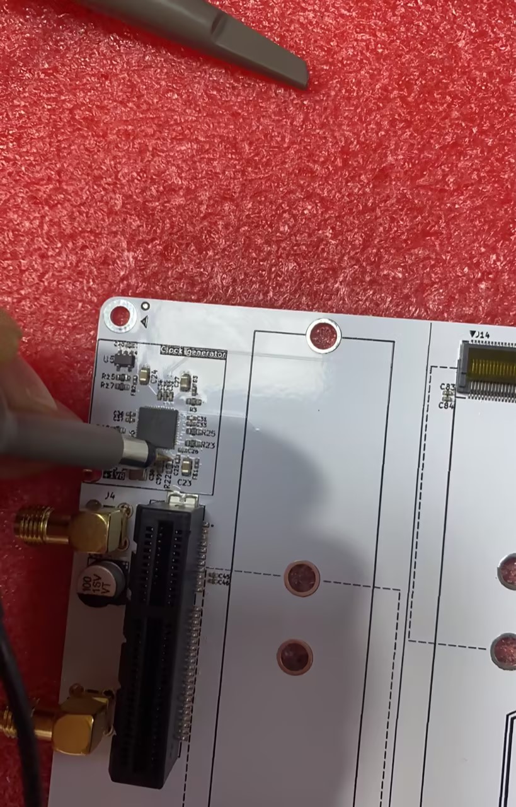
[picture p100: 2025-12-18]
1.pcb/2.test-results/2025-12-17/test (3).jpg

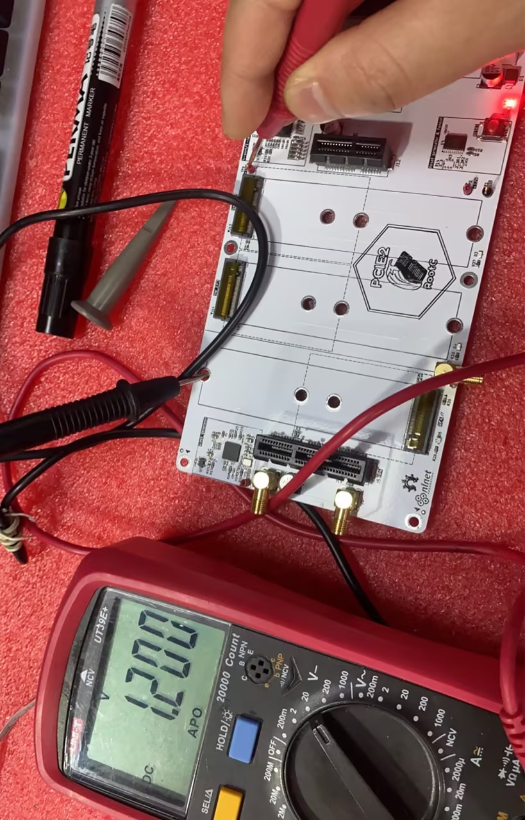
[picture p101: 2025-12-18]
1.pcb/2.test-results/2025-12-17/test (8).jpg

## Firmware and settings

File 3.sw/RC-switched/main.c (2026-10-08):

// SPDX-FileCopyrightText: 2026 Chili.CHIPS
//
// SPDX-License-Identifier: BSD-3-Clause

//==========================================================================
// openPCIE * NLnet-sponsored open-source implementation
//--------------------------------------------------------------------------
//                   Copyright (C) 2026 Chili.CHIPS
//
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
// 1. Redistributions of source code must retain the above copyright
// notice, this list of conditions and the following disclaimer.
//
// 2. Redistributions in binary form must reproduce the above copyright
// notice, this list of conditions and the following disclaimer in the
// documentation and/or other materials provided with the distribution.
//
// 3. Neither the name of the copyright holder nor the names of its
// contributors may be used to endorse or promote products derived
// from this software without specific prior written permission.
//
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
//              https://opensource.org/license/bsd-3-clause
//--------------------------------------------------------------------------
// Description:
//   opensource openPCIE software FSM that replaces AMD-proprietary RTL FSM
//   Switched topology: ASM1184e PCIe switch with up to 4 endpoints behind it
//
//   Bus map produced by this firmware (same as the AMD cgator_cfg_rom.data):
//
//     bus 0 .............. Root Complex
//      |
//     bus 1  dev 0 ....... ASM1184e upstream port      (pri 1, sec 2, sub 6)
//      |
//     bus 2  dev 1 ....... downstream port 1 --> bus 3, window 0x10000000
//            dev 3 ....... downstream port 2 --> bus 4, window 0x10100000
//            dev 5 ....... downstream port 3 --> bus 5, window 0x10200000
//            dev 7 ....... downstream port 4 --> bus 6, window 0x10300000
//      |
//     bus 3..6  dev 0 .... the endpoint cards, BAR0 at the window base
//
//   Everything on bus 1 is reached with Type 0 Configuration TLPs, everything
//   deeper with Type 1. That selection is NOT made here -- riscv_pcie_soc.sv
//   derives it from the bus number in TX_HEADER2. The RTL is the same as for
//   RC-direct, whose requests all go to bus 1.
//==========================================================================

#include "pcie.h"

// Topology, exactly as laid out in the AMD configuration ROM
#define SWITCH_BUS        1
#define SWITCH_INTERNAL   2
#define SWITCH_SUBORD     6
#define NUM_PORTS         4

#define WINDOW_BASE       0x10000000
#define WINDOW_SIZE       0x00100000

// Result markers written to PCIE_TX_DATA
#define RESULT_PASS        0x0000FACE // every endpoint that was found passed
#define RESULT_FAIL        0x0000DEAD // an endpoint failed its memory readback
#define RESULT_NO_SWITCH   0xBAD00000 // the switch upstream port did not answer
#define RESULT_NO_DEVICE   0xBAD00001 // switch is up but no endpoint was found
// RESULT_CFG_FAILED  0xBAD00002    a config request to a found device failed (pcie.h)
#define RESULT_BAR0_FAILED 0xBAD00003 // an endpoint BAR0 is missing, I/O, or
                                      // larger than its 1 MB port window

// Downstream port device numbers and the bus number handed to each of them
static const uint8_t port_dev[NUM_PORTS] = { 1, 3, 5, 7 };
static const uint8_t port_bus[NUM_PORTS] = { 3, 4, 5, 6 };

// A device is there when it answers the ID read with SC. Behind a switch an
// empty slot is answered with UR by the downstream port.
static int device_present(uint32_t bus, uint32_t dev) {
    uint32_t id;

    if (cfg_read32(bus, dev, CFG_ID, &id) != CPL_STAT_SC) {
        return 0;
    }
    return (id != 0xFFFFFFFF) && (id != 0x00000000);
}

//--------------------------------------------------------------------------
// Bridge (Type 1) header helpers
//--------------------------------------------------------------------------

// Register 0x18: byte 0 = primary, byte 1 = secondary, byte 2 = subordinate
static void bridge_set_buses(uint32_t bus, uint32_t dev,
                             uint8_t primary, uint8_t secondary, uint8_t subordinate) {
    cfg_write32(bus, dev, CFG_BUS_NUMBERS,
                ((uint32_t)subordinate << 16) |
                ((uint32_t)secondary   <<  8) |
                ((uint32_t)primary));
}

// Register 0x20: [15:0] memory base, [31:16] memory limit. In both halves it is
// bits [15:4] that carry address bits [31:20], so the window granularity is
// 1 MB and the low nibble is read-only. The limit is inclusive -- it names the
// last megabyte still inside the window, not the first one outside it.
static void bridge_set_window(uint32_t bus, uint32_t dev,
                              uint32_t base, uint32_t size) {
    uint32_t base_field  = (base >> 16) & 0xFFF0;
    uint32_t limit_field = ((base + size - 1) >> 16) & 0xFFF0;

    cfg_write32(bus, dev, CFG_MEM_LIMITS, (limit_field << 16) | base_field);
}

int main() {

    tx_tag = 0;

    wait_cycles(STARTUP_DELAY);

    //----------------------------------------------------------------------
    // STEP 1: switch upstream port -- bus 1, device 0
    // Reached with Type 0 requests; it captures bus number 1 from them.
    //----------------------------------------------------------------------
    if (!device_present(SWITCH_BUS, 0)) {
        halt(RESULT_NO_SWITCH);
    }

    // Primary 1 (link towards the RC), secondary 2 (internal bus),
    // subordinate 6 (highest bus number behind this port)
    bridge_set_buses(SWITCH_BUS, 0, SWITCH_BUS, SWITCH_INTERNAL, SWITCH_SUBORD);

    // One window covering all four downstream windows: 0x10000000 - 0x103FFFFF
    bridge_set_window(SWITCH_BUS, 0, WINDOW_BASE, NUM_PORTS * WINDOW_SIZE);

    cfg_write32(SWITCH_BUS, 0, CFG_COMMAND, CMD_MEM_BUS_MASTER);

    //----------------------------------------------------------------------
    // STEP 2: the four downstream ports on the internal bus 2
    // Each is a virtual PCI-to-PCI bridge and gets its own secondary bus and
    // its own 1 MB memory window carved out of the upstream window.
    //----------------------------------------------------------------------
    for (int p = 0; p < NUM_PORTS; p++) {
        uint32_t base = WINDOW_BASE + (uint32_t)p * WINDOW_SIZE;

        bridge_set_buses(SWITCH_INTERNAL, port_dev[p],
                         SWITCH_INTERNAL, port_bus[p], port_bus[p]);

        bridge_set_window(SWITCH_INTERNAL, port_dev[p], base, WINDOW_SIZE);

        cfg_write32(SWITCH_INTERNAL, port_dev[p], CFG_COMMAND, CMD_MEM_BUS_MASTER);
    }

    //----------------------------------------------------------------------
    // STEP 3: the endpoint cards, one per downstream port, always device 0 on
    // the secondary bus of that port. Slots may be empty, so each one is
    // probed first and silently skipped when there is no answer.
    //----------------------------------------------------------------------
    uint32_t ep_bar0[NUM_PORTS]; // 0 = slot empty
    int      found = 0;

    for (int p = 0; p < NUM_PORTS; p++) {
        uint32_t base = WINDOW_BASE + (uint32_t)p * WINDOW_SIZE;

        ep_bar0[p] = 0;
        if (!device_present(port_bus[p], 0)) {
            continue;
        }

        // The BARs have to land inside the window the port forwards, otherwise
        // the downstream port drops every memory request aimed at them.
        ep_bar0[p] = assign_bars(port_bus[p], 0, base, WINDOW_SIZE);
        if (ep_bar0[p] == 0) {
            halt(RESULT_BAR0_FAILED);
        }

        cfg_write32(port_bus[p], 0, CFG_COMMAND, CMD_MEM_BUS_MASTER);

        found++;
    }

    if (found == 0) {
        halt(RESULT_NO_DEVICE);
    }

    //----------------------------------------------------------------------
    // STEP 4: memory write / readback through the switch, one endpoint at a
    // time. This is the same self-test the direct build runs, repeated for
    // every populated slot.
    //----------------------------------------------------------------------
    uint32_t test_data = 0x00000006;
    int      failures  = 0;

    for (int p = 0; p < NUM_PORTS; p++) {
        uint32_t readback;

        if (ep_bar0[p] == 0) {
            continue;
        }

        pcie_mem_write(ep_bar0[p], test_data);

        if (pcie_mem_read(ep_bar0[p], &readback) != CPL_STAT_SC ||
            readback != test_data) {
            failures++;
        }
    }

    if (failures == 0) {
        halt(RESULT_PASS);
    } else {
        halt(RESULT_FAIL);
    }
}

//--------------------------------------------------------------------------
// Revision history:
//  2026/07/31 AV - initial creation, derived from the RC-direct firmware
//  2026/10/06    - Completion Status checked on every request (CRS retry on
//                  config writes too), real BAR sizing inside the port window
//--------------------------------------------------------------------------

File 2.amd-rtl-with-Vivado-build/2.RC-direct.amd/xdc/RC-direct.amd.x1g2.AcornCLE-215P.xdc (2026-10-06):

set_property PACKAGE_PIN F6 [get_ports sys_clk_p]
set_property PACKAGE_PIN E6 [get_ports sys_clk_n]

create_clock -period 10.000 -name sys_clk [get_ports sys_clk_p]

set_property PACKAGE_PIN J1 [get_ports sys_rst_n]
set_property IOSTANDARD LVCMOS33 [get_ports sys_rst_n]
set_property PULLTYPE PULLUP [get_ports sys_rst_n]

#LANE0
# pads MGTP*2_216: RXP B10, RXN A10, TXP B6, TXN A6 - fixed by the GTPE2_CHANNEL LOC below
#set_property LOC GTPE2_CHANNEL_X0Y6 [get_cells {cgator_wrapper_i/pcie_7x_0_support_i/rport/inst/inst/gt_top_i/pipe_wrapper_i/pipe_lane[0].gt_wrapper_i/gtp_channel.gtpe2_channel_i}]

#LANE1
# pads MGTP*0_216: RXP B8, RXN A8, TXP B4, TXN A4 - fixed by the GTPE2_CHANNEL LOC below
#set_property LOC GTPE2_CHANNEL_X0Y4 [get_cells {cgator_wrapper_i/pcie_7x_0_support_i/rport/inst/inst/gt_top_i/pipe_wrapper_i/pipe_lane[0].gt_wrapper_i/gtp_channel.gtpe2_channel_i}]

#LANE2
# pads MGTP*1_216: RXP D11, RXN C11, TXP D5, TXN C5 - fixed by the GTPE2_CHANNEL LOC below
set_property LOC GTPE2_CHANNEL_X0Y5 [get_cells {cgator_wrapper_i/pcie_7x_0_support_i/rport/inst/inst/gt_top_i/pipe_wrapper_i/pipe_lane[0].gt_wrapper_i/gtp_channel.gtpe2_channel_i}]

#LANE3
# pads MGTP*3_216: RXP D9, RXN C9, TXP D7, TXN C7 - fixed by the GTPE2_CHANNEL LOC below
#set_property LOC GTPE2_CHANNEL_X0Y7 [get_cells {cgator_wrapper_i/pcie_7x_0_support_i/rport/inst/inst/gt_top_i/pipe_wrapper_i/pipe_lane[0].gt_wrapper_i/gtp_channel.gtpe2_channel_i}]

set_property PACKAGE_PIN G3 [get_ports {led_link_up[0]}]
set_property IOSTANDARD LVCMOS33 [get_ports {led_link_up[0]}]

set_property PACKAGE_PIN H3 [get_ports {led_link_up[1]}]
set_property IOSTANDARD LVCMOS33 [get_ports {led_link_up[1]}]

set_property PACKAGE_PIN G4 [get_ports {led_link_up[2]}]
set_property IOSTANDARD LVCMOS33 [get_ports {led_link_up[2]}]

set_property PACKAGE_PIN H4 [get_ports {led_link_up[3]}]
set_property IOSTANDARD LVCMOS33 [get_ports {led_link_up[3]}]

set_property PACKAGE_PIN G1 [get_ports clk_req]
set_property IOSTANDARD LVCMOS33 [get_ports clk_req]

#set_property BITSTREAM.CONFIG.SPI_BUSWIDTH 4 [current_design]
#set_property CONFIG_MODE SPIx4 [current_design]

set_false_path -to [get_pins cgator_wrapper_i/pcie_7x_0_support_i/pipe_clock_i/pclk_i1_bufgctrl.pclk_i1/S0]
set_false_path -to [get_pins cgator_wrapper_i/pcie_7x_0_support_i/pipe_clock_i/pclk_i1_bufgctrl.pclk_i1/S1]
#
#
create_generated_clock -name clk_125mhz_x0y0 [get_pins cgator_wrapper_i/pcie_7x_0_support_i/pipe_clock_i/mmcm_i/CLKOUT0]
create_generated_clock -name clk_250mhz_x0y0 [get_pins cgator_wrapper_i/pcie_7x_0_support_i/pipe_clock_i/mmcm_i/CLKOUT1]
create_generated_clock -name clk_125mhz_mux_x0y0 -source [get_pins cgator_wrapper_i/pcie_7x_0_support_i/pipe_clock_i/pclk_i1_bufgctrl.pclk_i1/I0] -divide_by 1 [get_pins cgator_wrapper_i/pcie_7x_0_support_i/pipe_clock_i/pclk_i1_bufgctrl.pclk_i1/O]
#
create_generated_clock -name clk_250mhz_mux_x0y0 -source [get_pins cgator_wrapper_i/pcie_7x_0_support_i/pipe_clock_i/pclk_i1_bufgctrl.pclk_i1/I1] -divide_by 1 -add -master_clock [get_clocks -of [get_pins cgator_wrapper_i/pcie_7x_0_support_i/pipe_clock_i/pclk_i1_bufgctrl.pclk_i1/I1]] [get_pins cgator_wrapper_i/pcie_7x_0_support_i/pipe_clock_i/pclk_i1_bufgctrl.pclk_i1/O]
#
set_clock_groups -name pcieclkmux -physically_exclusive -group clk_125mhz_mux_x0y0 -group clk_250mhz_mux_x0y0

set_false_path -from [get_ports sys_rst_n]

#set_property LOC IBUFDS_GTE2_X0Y3 [get_cells refclk_ibuf]

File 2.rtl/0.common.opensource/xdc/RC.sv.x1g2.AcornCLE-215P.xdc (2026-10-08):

set_property PACKAGE_PIN F6 [get_ports sys_clk_p]
set_property PACKAGE_PIN E6 [get_ports sys_clk_n]
create_clock -period 10.000 -name sys_clk [get_ports sys_clk_p]

set_property PACKAGE_PIN J1 [get_ports sys_rst_n]
set_property IOSTANDARD LVCMOS33 [get_ports sys_rst_n]
set_property PULLTYPE PULLUP [get_ports sys_rst_n]
set_false_path -from [get_ports sys_rst_n]

create_clock -name txoutclk_x0y0 -period 10 [get_pins {pcie_inst/serdes_front_i/serdes_ctrl_i/lane_gen[0].xcvr_i/hm_chan.gtpe2_channel_i/TXOUTCLK}]

# The GT channel LOC -- which of the four lane positions the x1 link uses --
# is the one line that differs between the two root complexes, so it lives in
# each variant's own xdc/, which Vivado reads together with this file:
#   2.RC-direct.opensource/xdc/RC-direct.sv.x1g2.AcornCLE-215P.xdc
#   3.Bonus--RC-switched.opensource/xdc/RC-switched.sv.x1g2.AcornCLE-215P.xdc

set_property LOC GTPE2_COMMON_X0Y1 [get_cells {pcie_inst/serdes_front_i/serdes_ctrl_i/lane_gen[0].quad_gen.pll_bank_i/hm_cmn.gtpe2_common_i}]
set_property LOC PCIE_X0Y0 [get_cells pcie_inst/txn_engine_i/silicon_core_i/pcie_block_i]

set_property LOC RAMB36_X2Y46 [get_cells {pcie_inst/txn_engine_i/silicon_core_i/rx_buf_bank/tiles[3].tile/use_tdp.ramb36/genblk*.bram36_tdp_bl.bram36_tdp_bl}]
set_property LOC RAMB36_X1Y47 [get_cells {pcie_inst/txn_engine_i/silicon_core_i/rx_buf_bank/tiles[2].tile/use_tdp.ramb36/genblk*.bram36_tdp_bl.bram36_tdp_bl}]
set_property LOC RAMB36_X1Y46 [get_cells {pcie_inst/txn_engine_i/silicon_core_i/rx_buf_bank/tiles[1].tile/use_tdp.ramb36/genblk*.bram36_tdp_bl.bram36_tdp_bl}]
set_property LOC RAMB36_X1Y45 [get_cells {pcie_inst/txn_engine_i/silicon_core_i/rx_buf_bank/tiles[0].tile/use_tdp.ramb36/genblk*.bram36_tdp_bl.bram36_tdp_bl}]
set_property LOC RAMB36_X1Y44 [get_cells {pcie_inst/txn_engine_i/silicon_core_i/tx_buf_bank/tiles[0].tile/use_tdp.ramb36/genblk*.bram36_tdp_bl.bram36_tdp_bl}]
set_property LOC RAMB36_X1Y43 [get_cells {pcie_inst/txn_engine_i/silicon_core_i/tx_buf_bank/tiles[1].tile/use_tdp.ramb36/genblk*.bram36_tdp_bl.bram36_tdp_bl}]
set_property LOC RAMB36_X1Y42 [get_cells {pcie_inst/txn_engine_i/silicon_core_i/tx_buf_bank/tiles[2].tile/use_tdp.ramb36/genblk*.bram36_tdp_bl.bram36_tdp_bl}]
set_property LOC RAMB36_X1Y41 [get_cells {pcie_inst/txn_engine_i/silicon_core_i/tx_buf_bank/tiles[3].tile/use_tdp.ramb36/genblk*.bram36_tdp_bl.bram36_tdp_bl}]

set_property PACKAGE_PIN G3 [get_ports {led_link_up[0]}]
set_property IOSTANDARD LVCMOS33 [get_ports {led_link_up[0]}]
set_property PACKAGE_PIN H3 [get_ports {led_link_up[1]}]
set_property IOSTANDARD LVCMOS33 [get_ports {led_link_up[1]}]
set_property PACKAGE_PIN G4 [get_ports {led_link_up[2]}]
set_property IOSTANDARD LVCMOS33 [get_ports {led_link_up[2]}]
set_property PACKAGE_PIN H4 [get_ports {led_link_up[3]}]
set_property IOSTANDARD LVCMOS33 [get_ports {led_link_up[3]}]
set_property PACKAGE_PIN G1 [get_ports clk_req]
set_property IOSTANDARD LVCMOS33 [get_ports clk_req]

create_generated_clock -name clk_125mhz_x0y0 [get_pins pcie_inst/clk_synth_i/mmcm_i/CLKOUT0]
create_generated_clock -name clk_250mhz_x0y0 [get_pins pcie_inst/clk_synth_i/mmcm_i/CLKOUT1]

set_false_path -to [get_pins pcie_inst/clk_synth_i/pclk_i1/S0]
set_false_path -to [get_pins pcie_inst/clk_synth_i/pclk_i1/S1]

create_generated_clock -name clk_125mhz_mux_x0y0 -source [get_pins pcie_inst/clk_synth_i/pclk_i1/I0] -divide_by 1 [get_pins pcie_inst/clk_synth_i/pclk_i1/O]
create_generated_clock -name clk_250mhz_mux_x0y0 -source [get_pins pcie_inst/clk_synth_i/pclk_i1/I1] -divide_by 1 -add -master_clock [get_clocks -of [get_pins pcie_inst/clk_synth_i/pclk_i1/I1]] [get_pins pcie_inst/clk_synth_i/pclk_i1/O]

set_clock_groups -name pcieclkmux -physically_exclusive -group clk_125mhz_mux_x0y0 -group clk_250mhz_mux_x0y0
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

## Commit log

2025-01-28 First PCB working draft
    [4_1-lines_PCIe.kicad_sch, RC_4-lines-PCIe.kicad_sch, backplane.kicad_sch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]
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2025-01-28 Replaced Clock generator
    [4_1-lines_PCIe.kicad_sch, RC_4-lines-PCIe.kicad_sch, clock_gen.kicad_sch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]
2025-01-31 Schematics update
    [4_1-lines_PCIe.kicad_sch, RC_4-lines-PCIe.kicad_sch, clock_gen.kicad_sch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]
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2025-02-02 Swap RC connectors position
    [openpci2-backplane.kicad_pcb]
2025-02-13 PCIe diff lines interconnect, first try
    [4_1-lanes_PCIe.kicad_sch, RC_4-lanes-PCIe.kicad_sch, clock_gen.kicad_sch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]
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2025-07-01 3V3 power rails consolidation
    [4_1-lanes_PCIe.kicad_sch, RC_4-lanes-PCIe.kicad_sch, clock_gen.kicad_sch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]
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2025-07-12 Octal buffer, KiCad lib 1.0.6
    [4_1-lanes_PCIe.kicad_sch, RC_4-lanes-PCIe.kicad_sch, clock_gen.kicad_sch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]
2025-07-22 PCB layout: component placement
    [4_1-lanes_PCIe.kicad_sch, RC_4-lanes-PCIe.kicad_sch, clock_gen.kicad_sch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]
2025-07-24 4-lane "direct" island added into schematics
    [4_1-lanes_PCIe.kicad_sch, RC_4-lanes-PCIe.kicad_sch, clock_gen.kicad_sch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]
2025-07-24 SMD PCIe connectors, RC4 signals renamed
    [4_1-lanes_PCIe.kicad_sch, RC_4-lanes-PCIe.kicad_sch, clock_gen.kicad_sch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]
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2025-07-26 BOM updated, Clock distr modified
    [4_1-lanes_PCIe.kicad_sch, RC_4-lanes-PCIe.kicad_sch, clock_gen.kicad_sch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]
2025-07-28 Clk gen changed to initial model, LDO added for clk gen, new RPi pinout
    [4_1-lanes_PCIe.kicad_sch, RC_4-lanes-PCIe.kicad_sch, clock_gen.kicad_sch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]
2025-07-28 PCIe connectors swap
    [RC_4-lanes-PCIe.kicad_sch, clock_gen.kicad_sch, openpci2-backplane.kicad_pcb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]
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2025-07-29 Rx/Tx lanes swap, RPi mounting holes
    [4_1-lanes_PCIe.kicad_sch, RC_4-lanes-PCIe.kicad_sch, clock_gen.kicad_sch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]
2025-07-31 Rx/Tx lanes swap
    [4_1-lanes_PCIe.kicad_sch, RC_4-lanes-PCIe.kicad_sch, clock_gen.kicad_sch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]
2025-07-31 Rx&Tx lanes swap (x1 PCIe connectors)
    [4_1-lanes_PCIe.kicad_sch, RC_4-lanes-PCIe.kicad_sch, direct_PCIe.kicad_sch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]
2025-07-31 U5 PD capacitor added, BOM updated
    [4_1-lanes_PCIe.kicad_sch, RC_4-lanes-PCIe.kicad_sch, clock_gen.kicad_sch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]
2025-08-19 Adding an initial Vivado based test bench with instantiated pcieVHost (wrapped in the pcieVHostPipex1 BFM wrapper) and a temporary DUT stube with an soc_cpu.VPROC and a pcievhost to drive the PCIe PI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
    [vusermain.cfg]
2025-10-17 Schematic complete and ready for PCB layout
    [direct_PCIe.kicad_sch, openpci2-backplane.kicad_pcb, openpci2-backplane.kicad_sch]
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2025-10-18 Kicad library 1.0.7, small positioning changes in the PCB layout
    [4_1-lanes_PCIe.kicad_sch, RC_4-lanes-PCIe.kicad_sch, clock_gen.kicad_sch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]
2025-10-18 3V3 buck layout, small fixes in BOM
    [4_1-lanes_PCIe.kicad_sch, RC_4-lanes-PCIe.kicad_sch, clock_gen.kicad_sch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]
2025-10-18 Buck's MSEL resistor value changed to 182K
    [clock_gen.kicad_sch, openpci2-backplane.kicad_pcb]
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2025-10-19 Added extra Cout for buck istead of Cff
    [openpci2-backplane.kicad_pcb]
2025-10-19 attempt to route PCIe lanes between x4 connectors
    [4_1-lanes_PCIe.kicad_sch, RC_4-lanes-PCIe.kicad_sch, clock_gen.kicad_sch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]
2025-10-19 PMOD Type 1A connector added
    [4_1-lanes_PCIe.kicad_sch, clock_gen.kicad_sch, openpci2-backplane.kicad_pcb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]
2025-10-19 PMOD pinout correction
    [openpci2-backplane.kicad_pcb, pcie_switch.kicad_sch]
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2025-10-20 PCIe switch PCB layout
    [openpci2-backplane.kicad_pcb]
2025-10-20 Reset and Clock generator PCB layout
    [4_1-lanes_PCIe.kicad_sch, RC_4-lanes-PCIe.kicad_sch, clock_gen.kicad_sch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]
2025-10-20 Removed M.2 for x4 slots, added test points
    [4_1-lanes_PCIe.kicad_sch, RC_4-lanes-PCIe.kicad_sch, clock_gen.kicad_sch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]
2025-10-20 PCB layout for 4-lane PCIe replaced with THT
    [4_1-lanes_PCIe.kicad_sch, RC_4-lanes-PCIe.kicad_sch, clock_gen.kicad_sch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]
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2025-10-21 Reduced number of x1 and M.2 connectors, resized PCB
    [4_1-lanes_PCIe.kicad_sch, RC_4-lanes-PCIe.kicad_sch, clock_gen.kicad_sch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]
2025-10-24 Further reduction of the PCB size
    [clock_gen.kicad_sch, openpci2-backplane.kicad_pcb, pcie_switch.kicad_sch]
2025-10-28 New BNC connector positions
    [openpci2-backplane.kicad_pcb]
2025-10-29 Schematic: Cleanup and revision
    [clock_gen.kicad_sch, direct_PCIe.kicad_sch, openpci2-backplane.kicad_sch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]
2025-10-29 Remove unused schematic files
    [RC_4-lanes-PCIe.kicad_sch]
2025-11-01 Schematic: Cleanup, revision and layout improvements
    [4_1-lanes_PCIe.kicad_sch, clock_gen.kicad_sch, direct_PCIe.kicad_sch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]
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2025-11-08 PCB layout routing attempt
    [openpci2-backplane.kicad_pcb]
2025-11-09 PCIe 4 lanes PCB layout
    [openpci2-backplane.kicad_pcb]
2025-11-09 SW_EP2, SW_EP3 PCB layout
    [openpci2-backplane.kicad_pcb]
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2025-11-13 Final PCB layout revision, ready for manufacturing
    [openpci2-backplane.kicad_pcb, openpci2-backplane.kicad_sch, pcie_switch.kicad_sch]
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2026-01-22 added pictures pf the Switch that explain why it is overheating
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2026-04-22 Update schematic and PCB layout design
    [clock_gen.kicad_sch, direct_PCIe.kicad_sch, openpci2-backplane.kicad_pcb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]
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2026-05-16 bom: add 6x M3 nylon standoffs and screws (#11)
    [openpci2-backplane.kicad_sch]
2026-05-17 PCB: Add connector for a fan (#7)
    [openpci2-backplane.kicad_pcb, pcie_switch.kicad_sch]
2026-05-18 pcb: replace 1.2V LDO with RY3420 buck to fix overheating (#5)
    [openpci2-backplane.kicad_pcb]
2026-06-07 Complete rev.B PCB layout for manufacturing
    [4_1-lanes_PCIe.kicad_sch, clock_gen.kicad_sch, direct_PCIe.kicad_sch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]
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2026-08-18 Add PeakRDL CSR generation and HW/SW PCIe co-simulation
    [vusermain.cfg]
2026-09-09 SCH and PCB updates in prep for volume production and CrowdSupply campaign
    [006841015000.STEP, 006841031000.STEP, 006841039000.STEP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]
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2026-10-06 Cleanup in prep for the first release
    [0353130360.stp, 0472720024.stp, 0862-1J1T-43-F.step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]
2026-10-06 cont'd cleanup for the first release
    [clock_gen.kicad_sch, openpci2-backplane.kicad_pcb]
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2026-10-06 cleaned up and aligned licensing info with project goal
    [4_1-lanes_PCIe.kicad_sch, clock_gen.kicad_sch, direct_PCIe.kicad_sch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]
2026-10-06 cont'd cleanup in prep for a first official release
    [4_1-lanes_PCIe.kicad_sch, clock_gen.kicad_sch, direct_PCIe.kicad_sch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]
2026-10-07 KiCad Layout DRC cleanup
    [openpci2-backplane-BOM.xlsx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]
2026-10-10 added just discover openXC7 Issue#26 to the ledger
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

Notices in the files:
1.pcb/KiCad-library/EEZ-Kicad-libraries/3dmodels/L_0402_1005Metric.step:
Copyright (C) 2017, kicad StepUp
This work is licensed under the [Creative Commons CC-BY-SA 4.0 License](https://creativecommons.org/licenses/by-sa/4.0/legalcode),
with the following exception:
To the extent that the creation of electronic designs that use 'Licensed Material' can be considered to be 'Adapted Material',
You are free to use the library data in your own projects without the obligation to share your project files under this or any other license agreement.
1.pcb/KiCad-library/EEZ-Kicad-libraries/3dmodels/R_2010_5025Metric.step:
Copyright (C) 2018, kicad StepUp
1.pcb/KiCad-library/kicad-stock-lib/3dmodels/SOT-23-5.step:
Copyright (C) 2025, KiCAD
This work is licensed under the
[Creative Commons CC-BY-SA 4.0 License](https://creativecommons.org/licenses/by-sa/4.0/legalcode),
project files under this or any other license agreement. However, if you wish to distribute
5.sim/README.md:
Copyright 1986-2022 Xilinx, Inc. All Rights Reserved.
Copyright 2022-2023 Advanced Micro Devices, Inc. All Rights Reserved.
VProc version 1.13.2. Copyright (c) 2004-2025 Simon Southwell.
